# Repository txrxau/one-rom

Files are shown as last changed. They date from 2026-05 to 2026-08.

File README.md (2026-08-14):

# One ROM

**[One ROM](https://onerom.org) - One ROM To Rule Them All**

The most flexible and powerful ROM replacement for your retro computer.  A single Raspberry Pi
RP2350-base board in the footprint of the original chip emulates 24, 28, 32 and
40 pin mask ROMs, EPROMs, EEPROMs, bipolar PROMs and some SRAM — and then does
things the original never could.  It serves several ROM sockets at once, switches
images at runtime, reprograms over USB without leaving the socket, talks back to
the machine it is installed in, and runs your own code as plugins.

Thousands of One ROMs are installed in Commodore 64s, VIC-20s, PETs, Amigas, BBCs, Ataris, TIs, Apple IIs,
disk drives, IBM PCs, pinball machines, drum machines, synthesizers and more.  It is
open source hardware and software, it is cheap to make, and it is actively
maintained and developed.

## New to One ROM?

**Start at [onerom.org](https://onerom.org).**  That is where the project is
explained and supported:

- [What One ROM is and why](https://onerom.org) — the overview, with pictures
- [Getting started](https://onerom.org/start/) — install it, program it, use it
- [Buy one](https://onerom.org/buy) — known vendors, if you'd rather not fab
  your own
- [Program from your browser](https://onerom.org/web) — no software to install

**The rest of this README is for people who want to build One ROM, hack on it,
or build things on top of it.**  If you just want a working ROM replacement, [onerom.org](https://onerom.org) will get you there faster.

## Ways in

One ROM is designed to be extended in many different ways.

| I want to… | Start here | Steps |
|---|---|---|
| Drive a device from scripts or my own tooling | [Programming a One ROM](#programming-a-one-rom), [CLI manual](docs/CLI-MANUAL.md) | Install and run the CLI |
| Fab and assemble existing boards | [hardware/pcb](hardware/pcb/README.md) | Upload gerbers and BOM/POS files to a fab |
| Build the firmware myself | [Building from source](#building-from-source) | Use `make` or the build container |
| Use the header pins as GPIOs — reset the host, drive a line | [Driving the host](#driving-the-host--gpio-and-reset) | One command, plus a wire for host reset |
| Add support for a chip type One ROM doesn't know | [Adding a chip type](docs/ADDING-CHIP-TYPES.md) | A JSON entry plus one line of Rust or a firmware and tooling update if no existing serving algorithm fits |
| Add support for a new board revision | [rust/config/json](rust/config/json/README.md) | A new JSON file once the board is designed |
| Write a plugin — from scratch, or from a working one | [Plugins](#plugins), [firmware/ora/examples](firmware/ora/examples) | C, against a stable API |
| Talk to the retro machine from the ROM socket | [RBCP](#rbcp--talking-to-the-host-system) | 6502 and 68000 host code provided |
| Build host-side tools of my own | [Rust crates](#rust-crates) | Rust, on published crates |
| Read and test real ROM chips | [One ROM Lab](#one-rom-lab) | Flash Lab to a spare Fire board |
| Add a serving algorithm, or change how serving works | [How the firmware works](#how-the-firmware-works) | Bare metal C, PIO and DMA, plus Rust tooling |
| Design a new board | [hardware/pcb](hardware/pcb/README.md) | KiCad |

## Hardware

One ROM comes in two families:

- **Fire** — RP2350, in 24, 28, 32 and 40 pin variants, latest boards include an
  RGB NeoPixel.  All development happens for these boards.
- **Ice** — STM32F4, 24 pin only.  Legacy: still supported with 0.6.x firmware,
  but it is not being enhanced.  The 0.7.x firmware and the CLI do not
  support it.

<div align="center">
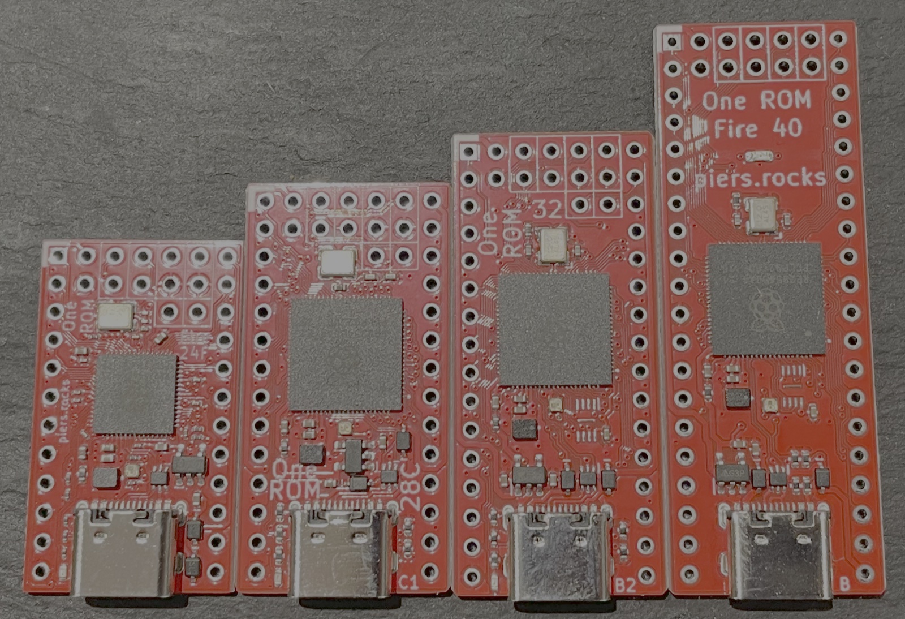
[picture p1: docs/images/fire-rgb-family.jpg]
One ROM Fire 24, 28, 32 and 40 pin boards side by side
    
</div>

<div align="center">
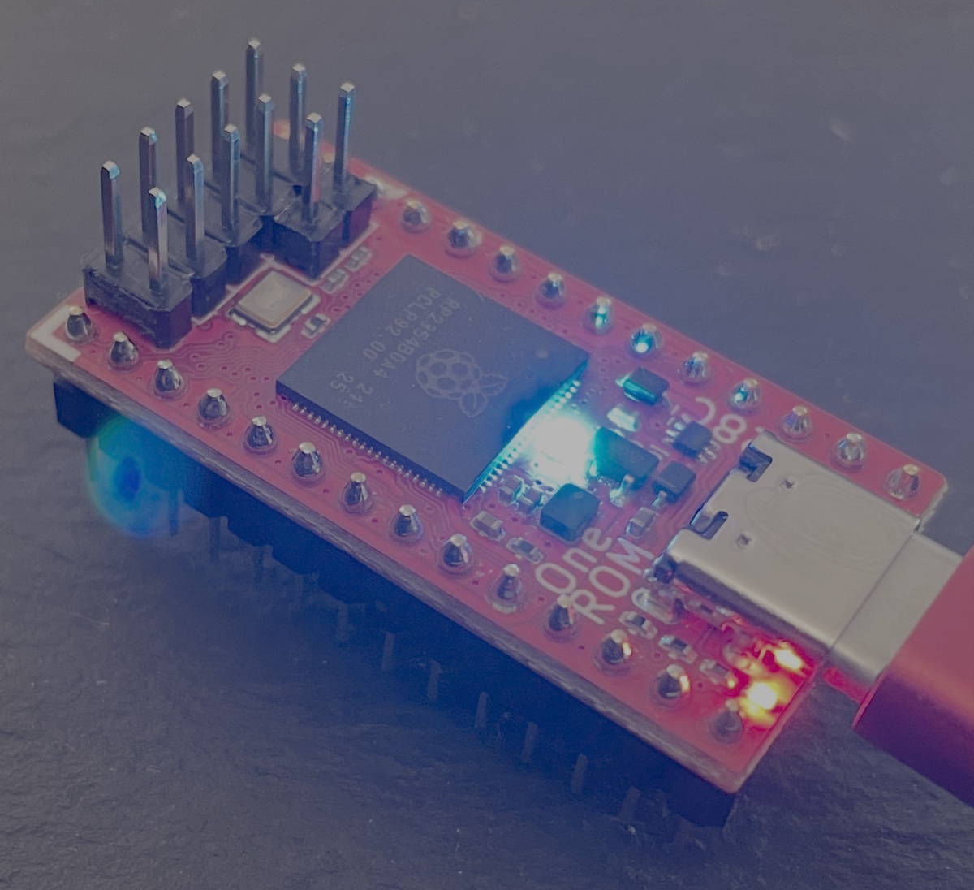
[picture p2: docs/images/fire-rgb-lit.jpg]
One ROM Fire 28 with its RGB NeoPixel lit
    
</div>

All the design files needed to manufacture your own are in
[hardware/pcb](hardware/pcb).  Start with the
[recommended revisions](hardware/pcb/README.md#recommended-revisions) and
read the fabrication notes in the same file before you order.  Boards can be
fabbed and assembled at JLCPCB and other manufacturers cheaply.

<div align="center">
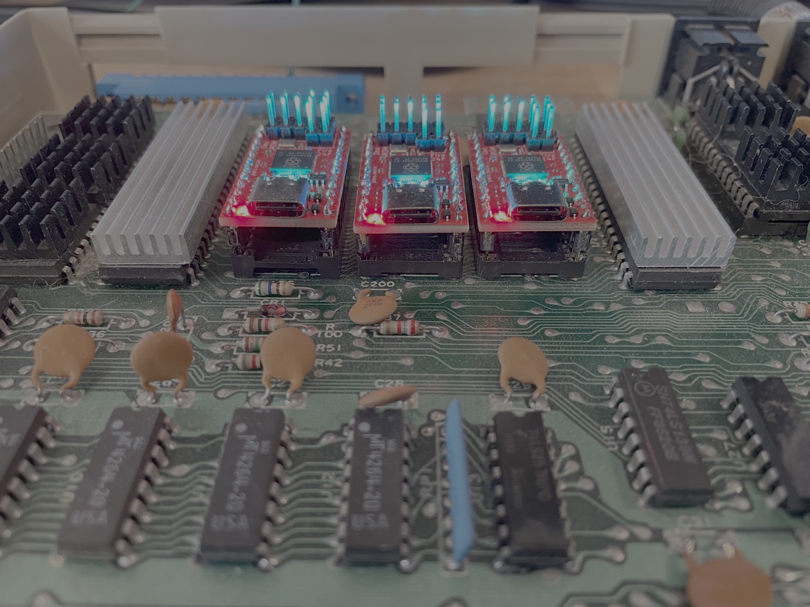
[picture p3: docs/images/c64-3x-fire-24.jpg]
Three One ROM Fire 24 boards serving BASIC, KERNAL and character ROMs in a Commodore 64
    
</div>

<p align="center"><em>Three One ROM Fire 24s in a Commodore 64, serving BASIC,
KERNAL and the character ROM.</em></p>

## Programming a One ROM

There are three tools, all doing the same job over USB:

- **[One ROM Web](https://onerom.org/web)** — browser based, nothing to install,
  the best choice for most people.
- **[One ROM CLI](https://onerom.org/cli)** — the full device tool, and what the
  examples below use ([rust/cli](rust/cli)).
- **[One ROM Studio](https://onerom.org/studio)** — native desktop GUI for
  Windows, macOS and Linux ([rust/studio](rust/studio)).

The CLI is the complete interface: everything the device can do is reachable from
it.  Full reference in the [CLI manual](docs/CLI-MANUAL.md).

Find what is connected:

```bash
onerom scan
```

Build an image from a config file and flash it:

```bash
onerom program --config onerom-config/vic20-pal.json
```

Program chips straight from the command line, without a config file, adding the
USB plugin so the device stays on the bus while it serves:

```bash
onerom program --slot file=kernal.901227-03.bin,type=2364,cs1=active-low --plugin usb
```

Build a firmware binary without touching a device, and look inside one:

```bash
onerom firmware build --config onerom-config/vic20-pal.json --board fire-24-e --output /tmp/onerom.bin
onerom firmware inspect --firmware /tmp/onerom.bin
```

Read and write the ROM image live, while the host is running from it:

```bash
onerom peek live --address 0x100 --length 64
onerom poke live --address 0x100 --byte 0xEA
```

## Driving the host — GPIO and reset

The image select and X pads are not just jumpers.  They are GPIOs, and
One ROM will drive them for you — which means the ROM socket becomes a way to
manipulate the machine it is plugged into.

Run a wire from a pad to the host's reset line and you can reset the machine
after flashing a new image:

```bash
onerom control reset --pin sel_c
```

`sel_c` is the usual choice — more boards have it than have X pads, and it is 5V
tolerant where it exists.  Any pad works, named with `--pin`.

<div align="center">
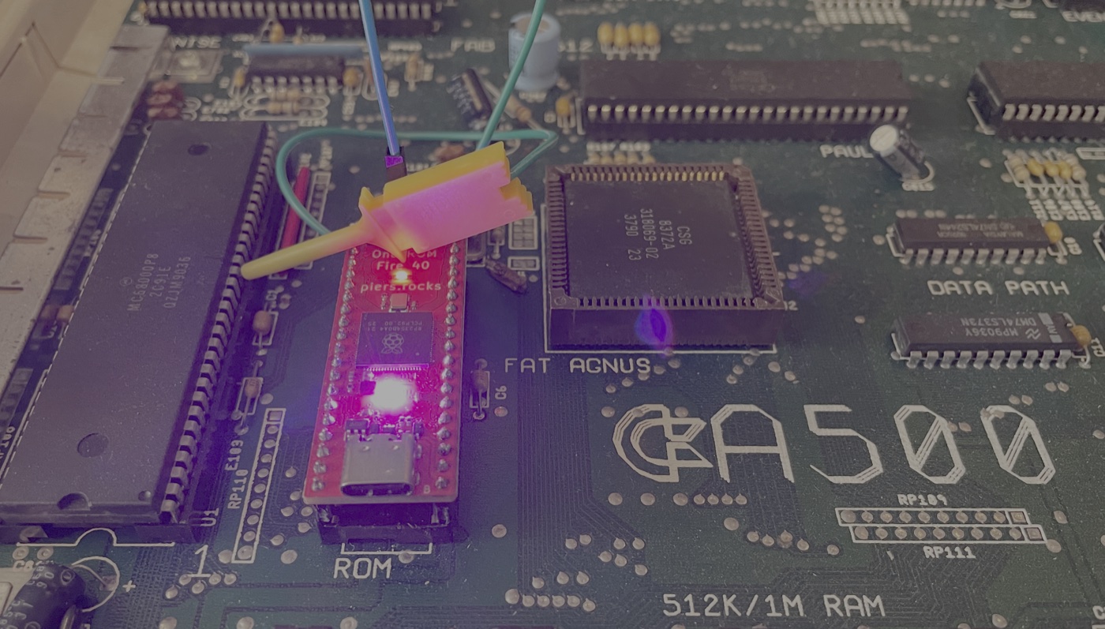
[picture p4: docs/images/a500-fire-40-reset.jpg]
One ROM Fire 40 in an Amiga A500 ROM socket, with a wire from its Sel_C pad to the 68000's reset line
    
</div>

<p align="center"><em>A One ROM Fire 40 in an Amiga A500, with <code>Sel_C</code>
wired to the 68000's reset line.</em></p>

You can see what every pin is and what it is currently doing:

```bash
onerom inspect gpio --all
onerom inspect socket --chip-type 2364 --gpio
```

The same GPIOs are available to plugins, so a plugin can drive them
autonomously — hold the host in reset until something is ready, blink an
external LED on ROM activity, or drive whatever you have wired up.

## Plugins

Serving runs entirely on PIO and DMA, so both CPU cores are free.  Plugins are
separate binaries, written in C against a stable API in
[firmware/ora](firmware/ora), that run on those cores *while serving continues*.
Two run at once.  This is how One ROM gains functionality without needing to
fork the core firmware.

There are two types, **system** and **user**.  The difference is resources, not
authorship — each is built for a different flash slot with a different RAM and
stack allocation, and you can write either.  System is intended for official One
ROM plugins such as the USB stack, but nothing stops you replacing it with your
own.

| Plugin | Type | What it does |
|---|---|---|
| [usb](plugins/system/usb) | system | The device's own USB stack, so a running One ROM stays on the bus.  Exposes the ROM being served for live read and write, and the `picobootx` extended PICOBOOT interface. |
| [host-control](plugins/user/host-control) | user | A full [RBCP](#rbcp--talking-to-the-host-system) implementation. |
| [rgb](plugins/user/rgb) | user | Cycles the NeoPixel on RGB boards. |
| [activity](plugins/user/activity) | user | Blinks the status LED when the host is reading the ROM. |
| [blink](plugins/user/blink) | user | Minimal example. |

The firmware passes each plugin a lookup function at startup.  The plugin calls
it with the ID of the facility it wants, and gets back a function pointer.
Available that way: status LED and GPIO control, device and firmware metadata,
logging, memory allocation, the ROM and RAM slots being served, and the address
monitor that reports what the host is reading — which is what RBCP is built on.
New IDs are only ever added, never changed, and each plugin declares the minimum
firmware version it needs, which the firmware enforces before launching it.

Start with [plugins/README.md](plugins/README.md) for how plugins are built and
configured, [firmware/ora/api.h](firmware/ora/api.h) for the API, and
[firmware/ora/examples](firmware/ora/examples) for worked examples — including
one that patches the C64 kernal live and one that drives an LED from character
ROM accesses.

## RBCP — talking to the host system

The [ROM Bus Control Protocol](https://github.com/piersfinlayson/rom-bus-control-protocol)
is bidirectional communication between a retro machine and the ROM emulator
installed in it, carried over nothing but the ROM's own address and data buses.
No extra wiring.  The machine reads and writes ROM addresses, and One ROM
interprets them.

That opens up things a ROM socket has no business being able to do:

- remote debugging of code running on real hardware
- ROM-based bootloaders — `grub` for the C64
- dynamic patching of games and demos as they run

The device side is the [host-control](plugins/user/host-control) plugin.  The
specification lives in the RBCP repository, along with reference host
implementations for 6502 and 68000 — generic routines plus sample C64 kernal and
Amiga Kickstart bootloaders.

## One ROM Lab

[One ROM Lab](rust/lab/README.md) is alternate firmware for a spare Fire board that turns
its ROM socket into a bus reader and tester.  Flash it, connect over USB, and you
get an interactive shell.

Read a real chip in the socket, as a checksum, a hexdump or Intel HEX.  Verify
that a One ROM under test serves the right bytes and tristates its data lines
when deselected.  Auto-detect chip select polarity on an unmarked mask ROM by
brute-forcing the combinations.  Dump the board's pin map, socket pin to signal
to GPIO.  It is what Fire 40 boards are tested with before they ship.

```bash
cd rust/lab && scripts/flash.sh
```
## Building from source

Dependencies are listed in [INSTALL.md](INSTALL.md), or use the
[build container](ci/docker/README.md).  The ARM and
Emscripten toolchain versions are pinned (`ci/arm-toolchain-version`,
`ci/emscripten-version`) so a firmware binary is byte-identical wherever it is
built.

Build the base firmware:

```bash
make
```

That produces `firmware/build/onerom-rp235x.bin` — one binary, for every Fire
board.  The ROM images, chip configuration and plugins are composed onto it by
the host-side tools.  To flash *your* build rather than a downloaded release,
pass it explicitly:

```bash
onerom program --config onerom-config/vic20-pal.json --base-firmware firmware/build/onerom-rp235x.bin
```

## How the firmware works

Worth knowing before you go digging in [firmware/](firmware):

**It is fully bare metal.**  No SDK, no HAL — not pico-sdk, not a vendor library.
C with its own startup code and its own linker scripts to keep it lean.

**Serving runs on PIO and DMA.**  The RP2350's PIO state machines watch the
address and chip select lines and DMA the right byte onto the data pins.  The CPU
is not in the critical path, which is what leaves both cores free for plugins.

**The chip type is not compiled in.**  The firmware knows nothing about a 2364 or
a 27C400.  It has a small set of parameterised serving algorithms, and the
host-side generator works out which algorithm and what arguments a given chip on
a given board needs, then writes that into the firmware metadata.

**It is one binary for all boards.**  Board differences are metadata too.

**Bad configuration is visible, not silent.**  An image the firmware cannot make
sense of drops it into limp mode, with an special LED blink pattern.

**The PIO programs are assembled on the device, at boot.**  Which program is
needed depends on the chip, the board's pin mapping and the configuration in
flash, none of which are known at build time.
[apio](https://github.com/piersfinlayson/apio) assembles them in C at runtime,
and disassembles them so a generated program can be read back and checked.

## Regression tested off-hardware

Every push runs the **real firmware C** — the source that ships on devices, not a
model of it — compiled for the host and linked against
[epio](https://github.com/piersfinlayson/epio), a cycle-exact RP2350 PIO
emulator, then driven over emulated bus cycles.

The sweep is hundreds of test runs covering all Fire board revisions, all supported
chip types, every configuration shape the firmware offers — single, banked,
multi-chip, 16-bit — and every chip select polarity combination.  Every address
of every image is compared against an independent copy, which is 10s of
millions of byte-level comparisons, plus checks that the data bus tristates for every
non-selected control line combination.

The plugin API is covered down to all API IDs, and the host-control plugin's own C source is run against a full suite of
conformance tests whose basis is the protocol specification rather than the
implementation.

CS-to-data latency is asserted to the exact cycle in **both**
directions, so serving getting a cycle slower — or a cycle faster, which would
mean the check had stopped discriminating — fails the build.

What it does not do today is anything analogue — voltage levels, bus loading,
propagation delay at a real pin — or USB.  Those need a board, which is what
[One ROM Lab](#one-rom-lab) is for.

## Rust crates

The host-side tooling is a Cargo workspace in [rust/](rust).  The crates marked
published are on crates.io, for host-side Rust development.

| Crate | Published | What it is for |
|---|:---:|---|
| [`onerom-gen`](rust/gen) | ✓ | Generates ROM images and firmware metadata.  The heart of the toolchain — turns a config plus some ROM files into something flashable. |
| [`onerom-config`](rust/config) | ✓ | The config model: chip types, board definitions, pin maps, JSON schema. |
| [`onerom-fw`](rust/fw) | ✓ | Composes a complete firmware image, resolving and fetching base firmware from the release manifest. |
| [`onerom-fw-parser`](rust/fw-parser) | ✓ | Reads metadata back out of a firmware binary — what chips, what board, what version. |
| [`onerom-metadata`](rust/metadata) | ✓ | The embedded metadata schema itself. |
| [`onerom-cli`](rust/cli) | ✓ | Everything the CLI does, minus the command line parsing.  Build on it rather than reimplementing USB device logic. The CLI binary is released at [onerom.org/cli](https://onerom.org/cli). |
| [`onerom-app`](rust/app) | ✓ | Transport-free logic shared by the CLI, Studio and the web tools. |
| [`onerom-studio`](rust/studio) | | The desktop GUI, released at [onerom.org/studio](https://onerom.org/studio). |
| [`onerom-lab`](rust/lab) | | One ROM Lab, above. |
| [`onerom-lens`](rust/lens) | | One ROM Lens — compiles the firmware emulator to WebAssembly and draws PIO and DMA activity as waveforms in a browser, cycle by cycle. |
| [`onerom-fw-emulator`](rust/fw-emulator) | | Compiles and runs the real firmware C on a host, PIOs and all. |
| [`onerom-fw-tester`](rust/fw-tester) | | Drives the emulator with generated configurations and checks the results. |
| [`onerom-plugin-tester`](rust/plugin-tester) | | Runs plugins against the emulated firmware. |
| [`onerom-fw-driver`](rust/fw-driver), [`onerom-fw-geometry`](rust/fw-geometry) | | Pin geometry and GPIO bitmask helpers, shared and dependency-free by design. |
| [`fw-config-gen`](rust/fw-config-gen), [`schema-gen`](rust/schema-gen) | | Code and schema generators. |

For in-browser use, [one-rom-wasm](https://github.com/piersfinlayson/one-rom-wasm)
wraps `onerom-gen` as WASM, and is what the
[browser programmer](https://onerom.org/web) in
[one-rom-site](https://github.com/piersfinlayson/one-rom-site) is built on.

## What is in this repository

| Directory | Contents |
|---|---|
| [`firmware/`](firmware) | The core firmware: C and Thumb assembly, bare metal.  `ora/` is the plugin API. |
| [`plugins/`](plugins) | System and user plugins. |
| [`rust/`](rust) | The Cargo workspace — CLI, Studio, generators, emulator, Lab, Lens. |
| [`hardware/pcb/`](hardware/pcb) | KiCad designs, per board revision, verified and unverified. |
| [`onerom-config/`](onerom-config) | Ready-made JSON configs for some common systems, and the config schema. |
| [`docs/`](docs) | Documentation, including the generated chip and compatibility references. |
| [`ci/`](ci) | Build, test and lint scripts, and the reproducible build container. |
| [`images/`](images) | Test ROM images. |
| [`demo/`](demo) | Demonstration programs for the retro side. |

## Documentation

| Topic | Description |
|---|---|
| [CLI Manual](docs/CLI-MANUAL.md) | Complete reference for the `onerom` command line tool. |
| [Chip Types](docs/CHIP-TYPES.md) | Every chip type One ROM knows about, with pinouts and control lines. |
| [Compatibility](docs/COMPATIBILITY.md) | Which chips each hardware variant can emulate, and at what flash cost. |
| [Adding a Chip Type](docs/ADDING-CHIP-TYPES.md) | Teaching One ROM to emulate a chip it does not yet know. |
| [Image Selection](docs/IMAGE-SELECTION.md) | Telling One ROM which installed image to serve. |
| [Image Sets](docs/MULTI-ROM-SETS.md) | Serving several ROMs at once, and dynamic bank switching. |
| [Plugins](plugins/README.md) | Building, configuring and writing plugins. |
| [Build Container](ci/docker/README.md) | Building the firmware reproducibly in Docker. |
| [ROMs Glorious ROMs](docs/ROMS-GLORIOUS-ROMS.md) | Everything you wanted to know about 23/27 series ROMs but were afraid to ask. |
| [Changelog](CHANGELOG.md) | What changed, and when. |

More in [docs/](docs) — flash layout, logging, voltage levels, using a Pi Pico as
an SWD programmer — plus [INSTALL.md](INSTALL.md) for build dependencies and
[LICENSE.md](LICENSE.md).

## Videos

Why use One ROM:

10 reasons to use One ROM (https://www.youtube.com/watch?v=LjKZ0uKzLO4)

The hardware family:

One ROM hardware family (https://www.youtube.com/watch?v=GAh021jgGgs)

## Related repositories

| Repository | What it is |
|---|---|
| [rom-bus-control-protocol](https://github.com/piersfinlayson/rom-bus-control-protocol) | The RBCP specification, and 6502/68000 reference host implementations. |
| [one-rom-site](https://github.com/piersfinlayson/one-rom-site) | onerom.org, including the browser programmer. |
| [one-rom-images](https://github.com/piersfinlayson/one-rom-images) | images.onerom.org — firmware images, configs, plugin manifests. |
| [one-rom-wasm](https://github.com/piersfinlayson/one-rom-wasm) | WASM build of `onerom-gen`, for in-browser firmware generation. |
| [picoboot](https://github.com/piersfinlayson/picoboot) | Host-side Rust crate for the RP2350 PICOBOOT USB interface. |
| [picobootx](https://github.com/piersfinlayson/picobootx) | Device-side PICOBOOT extension, exposed by the USB plugin. |
| [apio](https://github.com/piersfinlayson/apio) | Runtime RP2350 PIO assembler and disassembler. |
| [epio](https://github.com/piersfinlayson/epio) | Cycle-exact RP2350 PIO emulator. |

## Problems

Raise an issue at the [project issues page](https://github.com/piersfinlayson/one-rom/issues)
or start a thread at [GitHub Discussions](https://github.com/piersfinlayson/one-rom/discussions).
Please include:

- your One ROM PCB type and revision (or a photo if you're unsure)
- the retro system you are using it with
- details of the problem.

## Contributing

Pull requests are welcome — firmware, tools, hardware, documentation, and
especially plugins.  If you write a user plugin you think others would want,
consider contributing it.

## License

See [LICENSE](LICENSE.md) for software and hardware licensing information.

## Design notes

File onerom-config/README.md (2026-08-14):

# ROM Configs

This directory contains configuration files that can be used to generate various ROM collections for use with One ROM.

There is a [schema file](schema.json) that describes the structure of these configuration files. You can use this schema to validate your own configuration files or to generate new ones.

If you would like a more human readable version of the schema use a tool like [json-schema.app](https://json-schema.app/view/%23?url=https%3A%2F%2Fimages.onerom.org%2Fconfigs%2Fschema.json), pasting in https://images.onerom.org/configs/schema.json as the URL.

To be precise, these config files are used to generate the __metadata__ that is embedded on One ROM's flash __alongside__ the core firmware, adding:

- ROM images
- (optionally) overrides to stock firmware behaviour, on a per ROM basis.

A config file following this format can be used with [One ROM Studio](https://onerom.org/studio) to generate a complete One ROM image and flash it to your One ROM.

## Local File Names

Where ROM images are on the local filesystem, it is safest to use full file paths.  On Windows, use double backslashes in the file path (e.g. "C:\\\\Users\\\\piers\\\\local-chargen-custom.bin"), or forward slashes (e.g. "c:/Users/piers/local-chargen-custom.bin").

## Minimal Config

This is a minimal config:

```json
{
    "$schema": "https://images.onerom.org/configs/schema.json",
    "version": 1,
    "description": "A minimal ROM config",
    "rom_sets": []
}
```

This produces One ROM image with no ROMs in it. This may be useful for manufacturing purposes - in order to flash and ship One ROM with no ROMs installed.

This is essentially the configuration that is used to generate the base One ROM images that One ROM Studio then adds the ROMs you select to.

## Simple Config

A slightly more advanced config with 2 ROM images:

```json
{
    "$schema": "https://images.onerom.org/configs/schema.json",
    "version": 1,
    "name": "Simple Config",
    "description": "A simple ROM config with 2 ROMs",
    "rom_sets": [
        {
            "type": "single",
            "roms": [
                {
                    "description": "ROM 1",
                    "file": "http://example.com/rom1.bin",
                    "type": "2364",
                    "cs1": "active_low"
                }
            ]
        },
        {
            "type": "single",
            "roms": [
                {
                    "description": "ROM 2",
                    "file": "http://example.com/rom2.bin",
                    "type": "2364",
                    "cs1": "active_low"
                }
            ]
        }
    ]
}
```

As can be seen, this config contains 2 ROM sets, each with a single 2364 mask programmed ROM image, each with the CS line active low.

One ROM Studio reads this config, downloads the 2 ROM images from the specified URLs, and builds a One ROM image containing these 2 ROMs.

The two ROM images are selected, at One ROM boot (power on) time, via the on-board image select jumpers.  The first ROM set is selected when all the jumpers are open.  The second ROM set is selected when the first jumper is closed.

(If you close more jumpers than there are ROM sets, the firmware will select the image indicates by the binary value encoded by the jumpers, modulo the number of installed images.)

## 23 vs 27 Series ROMs

If specifying a 27 series (EP)ROM, instead of a 23 (mask programmed) ROM, the `type` field should be set to the appropriate 27 series type (e.g. "27256" instead of "2364").

In this case, there is no need to specify CS line behaviour, as 27 series ROMs use /CE and /OE (both active low) logic by default.

For more details on the differences between 23 and 27 series ROMs, see the [One ROM Visualizer](https://onerom.org/visualizer).

## Firmware Configuration

The `firmware_overrides` section __within a ROM set__ allows fine-tuning of One ROM hardware behavior for __that specific ROM/set of ROMs__. Each base firmware image has built-in defaults - these overrides change the behavior when serving a particular ROM set.

Any ROM set can have its own `firmware_overrides` section, allowing different ROM sets to have different hardware configurations.  It can also have no `firmware_overrides` section, in which case the default firmware behavior is used.

The `firmware_overrides` fields are optional - only include the fields you wish to override from the defaults.

### Primary Use Cases

1. __Performance requirements__ - Some ROM images (particularly character ROMs) require specific clock speeds or voltage settings to serve reliably in certain host systems
2. __Hardware experimentation__ - Testing different configurations to determine optimal settings for specific host platforms and ROM types
3. __Power/performance/preference__ - Disabling features like LEDs (power saving or user preference) or debug interfaces (performance)

### Ice/Fire Specific Configuration

#### Ice Boards (STM32F4-based)

```json
"firmware_overrides": {
    "ice": {
        "cpu_freq": "72MHz",
        "overclock": false
    }
}
```

Ice boards support frequencies from 1MHz to 450MHz.

Set `overclock: true` for frequencies above the rated maximum for a specific STM32F4 MCU.

#### Fire Boards (RP2350-based)

```json
"firmware_overrides": {
    "fire": {
        "cpu_freq": "300MHz",
        "overclock": true,
        "vreg": "1.20V",
        "serve_mode": "Pio"
    }
}
```

Fire boards support 16MHz to 800MHz in various increments (as defined in the schema). For higher frequencies than 150MHz:

- set `overclock: true`.
- you may need to tune `vreg` (internal voltage regulator) - different RP2350 silicon may need different core voltages for stability at high speeds. One ROM firmware will use its own (conservative) voltage regulator settings for higher clock speeds if this is not specified.

### Other Hardware Settings

```json
"firmware_overrides": {
    "led": {
        "enabled": false
    },
    "swd": {
        "swd_enabled": false
    }
}
```

- __LED__ - Disable to save power or if you don't want a status LED on your ROM.  Note, if present and the device enters "limp mode" (e.g. due to a fault or unrecoverable configuration error), the LED will still blink to indicate an error.
- __SWD__ - Disable the debug interface to reduce bus contention and improve serving performance.  SWD is available for the whole of boot, including boot logging, and is shut off just before serving starts, staying off until the next reset.  Not a debug lockout - BOOTSEL/PICOBOOT are unaffected.

### Example: ROM-Specific Configuration

```json
{
    "rom_sets": [
        {
            "description": "C64 Character ROM - requires high clock speed",
            "firmware_overrides": {
                "ice": {
                    "cpu_freq": "150MHz",
                    "overclock": true
                }
            },
            "roms": [
                {
                    "description": "C64 Character ROM",
                    "file": "http://example.com/c64-char.bin",
                    "type": "2332",
                    "cs1": "active_low",
                    "cs2": "active_high"
                }
            ]
        }
    ]
}
```

### Advanced: PIO Serving Algorithm Parameters

For Fire boards using the PIO serving algorithm, low-level timing can be tuned via `serve_alg_params`. This is primarily for experimentation to determine what settings are required for specific ROM/host combinations.

```json
"firmware_overrides": {
    "serve_alg_params": {
        "params": [254, 0, 2, 0, 0, 0, 254, 255]
    }
}
```

As of firmware 0.6.0, the parameter array format is 8 bytes long, as follows:

- Byte 0: `0xFE` (signature)
- Byte 1: `addr_read_irq` (0=disabled, 1=enabled) - whether to use IRQ to trigger address reads
- Byte 2: `addr_read_delay` (0-31) - PIO cycles to delay between address reads
- Byte 3: `cs_active_delay` (0-31) - PIO cycles to wait after CS active before setting data pins to outputs
- Byte 4: `cs_inactive_delay` (0-31) - PIO cycles to hold data as outputs after CS goes inactive
- Byte 5: `no_dma` (0=use DMA, 1=CPU) - whether to use DMA or CPU for byte serving
- Byte 6: `0xFE` (end signature)
- Byte 7: `0xFF` (padding)

These parameters adjust the PIO state machine timing for specific ROM types or host systems. At 150MHz, each PIO cycle is ~6.67ns. See the PIO implementation source code for detailed timing analysis and pre-defined configurations.

It is likely that in future firmware versions, more PIO settings will be exposed via the config file.

### Firmware Defaults

As of 0.6.0 the following firmware defaults are used if no overrides are specified:

- Ice Clock: F401=84MHz, F411=100MHz, F405=168MHz, F446=180MHz, no overclocking.
- Fire Clock: 150MHz, overclocking enabled, VREG 1.10V.
- LED: Enabled (if hardware support is present)
- SWD: Enabled (if hardware support is present)
- PIO Serve Algorithm Params: [254, 0, 2, 0, 0, 0, 254, 255]

### Error Handling

Where possible, One ROM attempts to gracefully recover from incorrect or invalid configuration settings. 

For example, if it cannot calculate PLL values for a specific requested clock speed, it will attempt to find a close match, and if not found fall back to the values built into the firmware (likely to be the stock maximum rated speed for the MCU).

However, there are some situations where recover is not possible, or it is deemed better to enter "limp mode" (where the device hangs and flashes its status LED, irrespective of the LED enabled setting) to indicate a fault.

If the device enters limp mode, you have two choices:
- Try changing the settings and reflashing.
- Connecting a debug probe and using a build with BOOT_LOGGING/DEBUG_LOGGING included, to diagnose the issue.

The stock builds provided as part of One ROM releases _do not_ include debug or boot logging for performance reasons.

## Complex Configs

There's some advanced ROM options including the following:

- ROM Set types "multi" and "banked" for multi-ROM sets and dynamically bank switched ROM sets
- Local file and URL file sources (most generators only support URLs)
- The ability to specify licenses which must be accepted before building a config
- The ability to configure chip selects in multiple directions
- Support for all 24 and 28 pin ROM types
- Optional categories for better organization
- Support for archived ROM files (zips)
- Retrieve sections of a larger ROM file
- Duplicate and pad ROM images, if the ROM file provided is smaller than the expected size, and truncate if larger

Use the configs in this directory and the schema to build your own complex configs.

## Future Plans

The "end-game" is to have a repository of officially supported ROM configs for popular systems that can be used with One ROM Studio to build custom One ROM images.

It is intended that eventually ROM configs will specify the original ROM chip's access times and other characteristics, with the One ROM firmware to dynamically adjust its serving behavior to match the original hardware as closely as possible.

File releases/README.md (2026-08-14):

# Releases

The files in this directory were generated by the [GitHub release
workflow](../.github/workflows/release.yml) up to and including the v0.6.x
releases.

They are read by the One ROM Web programmer to discover the pre-built firmware
image artifacts published with those releases, so they can be downloaded and
programmed.

From v0.7.0 onwards the release workflow no longer updates this directory.
v0.7.0+ releases publish only the base One ROM firmware - a single image that
covers every Fire board - and no longer produce per-board pre-built images. The
existing files here are retained so the Web programmer can still offer the
pre-built images from earlier (v0.6.x and older) releases.

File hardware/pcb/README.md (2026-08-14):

# PCB Files

Contains One ROM PCB design files.  These are organised into two directories:

- [`verified/`](verified/README.md) - Verified designs that have been tested and work.
- [`unverified/`](unverified/README.md) - Unverified designs that have not been tested.

Before using any of the designs, review the hardware [LICENSE](/LICENSE.md#cern-ohl-w-20-license) and [NOTICE](/hardware/NOTICE) files.

## Recommended Revisions

Last Updated 4th July 2026.

The following table lists the recommended verified designs.  Each design has been manufactured and assembled using JLCPCB's PCB assembly service, and verified to work correctly.

| Model | MCU | Pins | USB | SWD | Image Select Pins | X Pins | RGB | PCB |
|---|-----|---|-----|-----|---|---|-----|---|
| Fire  | RP2350A | 24 | Micro-B | ✓ | 4 | 2 | - | [fire-24-d](./verified/fire-24-d/README.md) |
| Fire  | RP2354A | 24 | C | ✓ | 4 | 2 | - | [fire-24-e](./verified/fire-24-e/README.md) |
| Fire  | RP2354A | 24 | C | ✓ | 4 | 2 | ✓ | [fire-24-f](./verified/fire-24-f/README.md) |
| Fire  | RP2350A or RP2354A | 28 | C | ✓ | 2 | n/a | - | [fire-28-a4](./verified/fire-28-a4/README.md) |
| Fire  | RP2350A or RP2354A | 28 | C (upright) | ✓ | 2 | n/a | - | [fire-28-b](./verified/fire-28-b/README.md) |
| Fire  | RP2354B | 28 | C | ✓ | 2 | 2 | ✓ | [fire-28-c](./verified/fire-28-c/README.md) |
| Fire  | RP2350B or RP2354B | 32 | C | ✓ | 4 | n/a | - | [fire-32-a](./verified/fire-32-a/README.md) |
| Fire  | RP2350B or RP2354B | 32 | C | ✓ | 4 | n/a | ✓ | [fire-32-b2](./verified/fire-32-b2/README.md) |
| Fire  | RP2350B or RP2354B | 40 | C | ✓ | 4 | n/a | - | [fire-40-a](./verified/fire-40-a/README.md) |
| Fire  | RP2350B or RP2354B | 40 | C | ✓ | 4 | n/a | ✓ | [fire-40-b](./verified/fire-40-b/README.md) |

**One ROM 28C, 32 and 40 require components on the top and bottom of the PCB**

There may be later, unverified, revisions not in the list above.  These may have improvements over the recommended revisions, but they have not been verified to work.  If you want to use one of these later revisions, read the relevant README before ordering.

## Alternative Components

Sometimes your PCB manufacturer/assembler may be out of stock of a particular component.  This section lists some reasonable alternatives, using LCSC/JLC part numbers.

| Original Component | Original LCSC/JLC Part Number | Alternative Component | Alternative LCSC/JLC Part Number | Verified? | Notes |
|-|-|-|-|-|-|
| Diodes Inc AP2112K-3.3TRG1 | C51118 | Tech Public AP2112K-3.3TRG1 | C23380830 | Yes | Jelly bean part, same specs |
| Uniroyal 0201WMF1002TEE | C473048 | Yageo RC0201FR-0710KL | C106225 | No | Jelly bean part, same specs |
| Raspberry Pi RP2350A | C42411118 | Raspberry Pi RP2354A | C41378174 | Yes | If using RP2354A, do not populate the external flash chip, as the RP2354A has internal flash. |
| Raspberry Pi RP2350B | C42415655 | Raspberry Pi RP2354B | C39843328 | Yes | If using RP2354B, do not populate the external flash chip, as the RP2354B has internal flash. |

The RP2354A can be replaced with the RP2350A _if the design supports external flash and it is populated_.
- Some designs, such as fire-24-e, do not support external flash, so the RP2354A cannot be replaced with the RP2350A.
- Some designs, such as fire-40-a, have hardware support for both external flash plus an RP2354B, so two lots of flash.  Fabricating this option requires the correct 0R resistors to be populated/not populated.  See the board schematic for more details.

In some cases, alternative BOM/POS files are already provided for some alternative components.  In other cases, you may need to edit the BOM/POS files yourself to substitute the alternative component.  _Always_ double check component values, part numbers and placement before ordering.

## Notes on Fabrication

All recommended designs have been manufactured and assembled using JLCPCB's PCB assembly service.  The gerbers and BOM/POS files in each revision's `fab/` directory are compatible with JLCPCB's requirements.

Some variants offer multiple sets of BOM/POS files or different combinations of components.  Read the relevant revision's README for details.

You need to exercise care when submitting the order to ensure the correct options are selected.  In particular:

- Select economic assembly, not standard assembly, for cost reasons.
- Use standard 1.6mm PCB thickness.  You probably want HASL with lead finish for cost reasons.
- You have to select the desired PCB colour as part of the PCB ordering process.  Red is recommended for Fire and blue for Ice.
- As of late 2025 you no longer need to remove JLC's order ID from the PCBs, but it is worth checking this is still the case when you place your order.
- After uploading the BOM and position files for assembly, you need to ensure all parts are available and checked.
- You must ensure JLC is showing the correct orientation for all components.  There are silkscreen markings for pin 1 on all ICs and polarized components - ensure this matches the pink dot of the component in the viewer.  Also ensure the USB connector is the correct orientation.

Occasionally, some chosen parts are out of stock on JLCPCB.  One ROM has been designed with extremely common parts where possible, which JLC tend to hold large stocks of.  However, if a part is unavailable you may need to select an alternative part.  Ensure the alternative part has the same footprint and electrical characteristics (e.g. capacitance, voltage rating, etc) as the original part.  If in doubt, query within github discussions for advice. 

JLC may raise an issue with you after submitting your order.  Common issues include:
- JLC may ask to add side rails with stamp holes, to help with the PCB assembly process.  While One ROM has been successfully fabbed without these, if JLC recommends them it is best to accept this change, as otherwise they may not warrant the assembled boards.  The side rails can be snapped off using the "mouse bites" (stamp holes) after assembly.  JLC may or may not accept replacing stamp holes with v-score - as v-score is not available on their economic service.

If in doubt, query within github discussions for advice.

Assembly errors:
- Ice boards have rarely, if ever, experienced assembly errors.
- The first few batches of Fire boards experienced some assembly issues, particularly with respect to the RP2350 MCU solder pad fillets.  More recent boards and orders have been without issue.  It is unclear whether differences in the later PCBs or improvements in JLC's assembly process are responsible for this improvement.  If you do experience assembly issues, raise with JLC support.  It would also be interesting to hear on github discussions what issues you experienced, so others can be aware.

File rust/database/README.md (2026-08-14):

# One ROM Database

Database of known ROMs.

**Not currently maintained.**  This crate has not been added to or updated for
some time, and nothing in the tree depends on it in anger.  It is kept because
the idea may return, so treat its contents as incomplete and do not rely on it.

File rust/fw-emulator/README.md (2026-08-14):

# onerom-fw-emulator

This is a crate that provides the One ROM firmware as a library for running on hosts, emulating the underlying hardware, including PIOs and DMAs.

Sample invocation from this crate's directory:

```bash
BASE_DIR=$(realpath ../..) CONFIG=onerom-config/test-0.json BOARD=fire-24-a cargo test
```

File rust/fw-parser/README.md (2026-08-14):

# onerom-fw-parser

Crate to handle parsing an SDRR firmware image.

This can can be a `.bin` or `.elf` file - or could be the contents of an STM32's flash memory.  It supports `no_std` environments, for adding to embedded applications, or `std` for use in PC-based tools.

A PC-based reference implementation is provided in the [`sdrr-info`](https://piers.rocks/u/sdrr-info) tool, which is used to parse and output the contents of a firmware image when you run `make info` or `make info-detail`.

A reference embedded implementation using this crate is [Airfrog](https://piers.rocks/u/airfrog), which is a tiny $3 probe for ARM devices, that can be used to inspect the firmware and runtime state of the SDRR device, and change its configuration and ROM data - **while it is serving ROMs**.

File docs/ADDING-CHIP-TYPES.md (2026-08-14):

# Adding a Chip Type

How to teach One ROM to emulate a chip it does not yet know about.

This describes the **v2** path — firmware v0.7.0 and later, which is Fire
(RP2350) hardware.  V2 derives how to serve a chip from the chip's pinout and
the board's routing, so a new chip type is usually a data change plus a one-line
declaration.  The pre-v0.7.0 (v1) path is closed to new chip types, and its
per-chip code in [`rust/gen/src/image.rs`](/rust/gen/src/image.rs)
(`chip_type_c_enum_val`, `handle_snowflake_chip_types`) is not part of this.

## The short version

1. Add the chip to [`rust/config/json/chip-types.json`](/rust/config/json/chip-types.json).
2. Add its `ChipType` to `SUPPORTED_CHIP_TYPES` in [`rust/gen/src/v2/builder.rs`](/rust/gen/src/v2/builder.rs).
3. Run the generators.
4. Look for the chip in [`docs/COMPATIBILITY.md`](/docs/COMPATIBILITY.md).  If it is there, it serves.
5. If it is not, find out why with the `layout` tool — and only then consider firmware work.
6. Add it to the emulator test sweep, so it stays working.

## 1. The JSON entry

Everything One ROM knows about a chip comes from this one file.  The
`onerom-config` build script reads it, validates it, and generates the
`ChipType` enum and [`docs/CHIP-TYPES.md`](/docs/CHIP-TYPES.md).  The
`onerom-metadata` build script generates the firmware's `onerom_rom_type_t` C
enum and chip-size array from the same data.  Nothing is written twice.

Here is the 2364 entry — about as simple as an entry gets — with its arrays
compacted onto single lines:

```json
"2364": {
    "description": "8KB mask ROM with 1 configurable CS line",
    "function": "ROM",
    "rbcp_chip_type": 2,
    "supported": "0.4.4",
    "aliases": ["4764", "MCM68764", "MCM68A764", "MM52164", "MK36000"],
    "bit_modes": [8],
    "pins": 24,
    "size": 8192,
    "address": [8, 7, 6, 5, 4, 3, 2, 1, 23, 22, 19, 18, 21],
    "data": [9, 10, 11, 13, 14, 15, 16, 17],
    "control": {
        "cs1": { "pin": 20, "type": "configurable" }
    },
    "power": [
        { "name": "VCC", "pin": 24, "voltage": "+5V" },
        { "name": "GND", "pin": 12, "voltage": "0V" }
    ]
}
```

- **The key** is the chip's primary name.  Unless the chip is RAM it must start
  with `23`, `27`, `28`, `SST39SF` or `HM76`, or the build panics with
  `Unsupported chip type X - needs adding to chip_family()`.  A part number
  outside those conventions needs an arm in
  [`rust/config/build/chip/mod.rs`](/rust/config/build/chip/mod.rs).
- **`rbcp_chip_type`** is the wire value: unique, and permanent once shipped.
  Take the next free number.  The firmware's C enum and chip-size array are
  generated from it.  It is also part of the
  [ROM Bus Control Protocol](https://github.com/piersfinlayson/rom-bus-control-protocol),
  so a new chip type needs a matching pull request against that repository — the
  value has to mean the same thing on both sides of the bus.
- **`supported`** is the firmware version the chip first ships in — the
  in-development version from the [`Makefile`](/Makefile).  Omit it and the chip
  is known but unsupported: absent from `COMPATIBILITY.md` and from
  `onerom firmware chips`, and marked `✗` in `CHIP-TYPES.md`.
- **`aliases`** are other names for the same silicon.  Every alias becomes
  selectable everywhere a chip type can be named — the CLI, the web programmer
  and Studio, as well as its own row in `COMPATIBILITY.md` — so a user can pick
  the number actually stamped on their chip rather than having to know it is the
  same part as something else.  Be generous with them.
- **`address`** lists the address lines in bit order, lowest first, as physical
  pin numbers, and **`data`** does the same for the data lines from D0.  `size`
  must equal `2^address.len()` (the 48KB 23QL384 is the sole exception).
- **`bit_modes`** is `[8]`, or `[8, 16]` for a 16-bit part with a `/BYTE` line.
  On a 16-bit part the lowest address line is **A-1**, not A0 — it selects which
  half of the word a byte-mode read returns, and it shares a pin with the top
  data line.  So the 27C400's 19 entries are A-1 to A18, and `2^19` is still its
  512KB.  Nothing keys off the chip name: anything that needs to know works it
  out from `bit_modes` containing 16.
- **`control`** names the enables.  `cs1`-`cs4` may be `configurable` (polarity
  mask-programmed, so the user supplies it), `fixed_active_low` or
  `fixed_active_high`.  `ce` and `oe` carry the JEDEC convention and must be
  `fixed_active_low`.  Mixing CS with CE/OE needs `"allow_mixed_control": true`.

[`rust/config/build/chip/validation.rs`](/rust/config/build/chip/validation.rs)
enforces the pin, size and control-line rules, and fails the build on a bad
entry.

## 2. Declare it servable

`SUPPORTED_CHIP_TYPES` in
[`rust/gen/src/v2/builder.rs`](/rust/gen/src/v2/builder.rs) is the list of chip
types v2 firmware serves.  Add the variant and bump the array length together:

```rust
pub const SUPPORTED_CHIP_TYPES: &[ChipType; 36] = &[
    ...
    ChipType::Chip2532,
];
```

Nothing else in the tooling or the firmware C needs touching for an ordinary ROM
chip type.  A **RAM** type also needs an arm in `rom_slot_type`
([`rust/gen/src/v2/rom_info.rs`](/rust/gen/src/v2/rom_info.rs)) — and no v2
firmware serves RAM yet, which is why `Chip6116` sits commented out of the list.

## 3. Run the generators

From `rust/`:

```bash
cargo run -p onerom-gen --bin compat                     # docs/COMPATIBILITY.md
cargo run -p schema-gen --bin schema-gen                 # onerom-config/schema.json
cargo run -p onerom-gen --bin layout -- --write-baseline # ci/layout-baseline.txt
```

`docs/CHIP-TYPES.md` needs no command — the `onerom-config` build script
rewrites it on any build.  All four are checked in and all four are a CI gate.
`ci/rust-tests.sh` regenerates them and fails if the committed copy differs, so
commit them with the change.

## 4. Did it work?

Look for the chip in [`docs/COMPATIBILITY.md`](/docs/COMPATIBILITY.md), or ask
the CLI — `cargo run -p onerom-cli --bin onerom -- firmware chips --board
fire-24-e`.  If it is listed, that is the whole job.  Check the flash cost while
you are there with `layout --check`: an image several times the chip's own size
is normal where a board's routing puts an unrelated signal inside the chip's
address range, but it is worth knowing.

## 5. When it does not appear

`cargo run -p onerom-gen --bin layout -- --board fire-24-e` says why.  An
unservable chip has `-` in every size column and the reason in the `blocked by`
column at the end of its row.  The three you will see:

- *"physical pin N has no GPIO mapping on this board"* — the chip is bigger than
  the socket and that pin cannot be reached.  Expected, not a fault — the chip is
  still listed for boards that can reach it.
- *"does not support chip type X with this firmware version"* — step 2 was
  missed, or the chip is deliberately excluded.
- *"select/control GPIOs [10, 11, 16] are not contiguous on this board; Multi
  and Banked sets require all select, commoned, and X-pin GPIOs to form a
  contiguous range within a single PIO window"* — the chip's enables land on
  GPIOs no existing chip-select algorithm can express.

Only the last needs firmware work, and it is a serving-algorithm change rather
than a chip-type change.  A new algorithm is:

- a variant and a `NUM_*_ALGS` bump in
  [`rust/metadata/metadata_schema.toml`](/rust/metadata/metadata_schema.toml),
  with its parameter fields and `ALG_*_PARAMS_LEN` constant — that generates
  both the C header and the Rust serialiser,
- a `case` in [`firmware/src/piodma/piorom2.c`](/firmware/src/piodma/piorom2.c)
  emitting the PIO program,
- a preference variant in
  [`rust/gen/src/v2/alg_preference.rs`](/rust/gen/src/v2/alg_preference.rs), plus
  the derivation that selects it in `alg_cs.rs`, `cs_data_layout.rs` or
  `addr_layout.rs`,
- a CS-to-data cycle cost in
  [`rust/fw-tester/src/cs_timing.rs`](/rust/fw-tester/src/cs_timing.rs), which
  asserts against the firmware's own `NUM_*_ALGS` and so will not compile until
  the new algorithm has one.

That is a much bigger piece of work than adding a chip type — and it benefits
every chip that can use the new algorithm, not just the one that prompted it.

## 6. Add it to the test sweep

A chip that serves today but is not tested will break quietly later.
[`ci/test-emu.sh`](/ci/test-emu.sh) lists its chips explicitly, one line each, so
a new type is covered only once you add it.  Put it with the others for its pin
count, with a test image of the right size from [`images/test`](/images/test):

```sh
run_test   $board images/test/rand_16KB.rom  type=23128  3
run_no_cs  $board images/test/rand_8KB.rom   type=2764
```

`run_test` takes the number of configurable chip select lines and sweeps **every
polarity combination** — 3 means all 8 are tested.  `run_no_cs` is for chips
whose enables have a polarity fixed by the silicon, so there is nothing to sweep.

Run just your pin count while iterating — `ci/test-emu.sh 24` — as the full sweep
takes hours, and only one can run in a given working tree at a time.

## Folding it back in

If you want your chip type in One ROM proper rather than kept in your own tree,
please do — that is how the supported list has grown, and a chip somebody has
actually got in front of them is worth more than one added speculatively.  Open
an issue or a pull request, and talk to the maintainer early if the chip needs a
new serving algorithm, since that is a change with consequences beyond your chip
and is better designed together than reviewed after the fact.

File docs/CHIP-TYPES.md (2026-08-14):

# Chip Type Specifications

This document provides detailed specifications for the different Chip types One ROM supports, and aims to support in future, including pinouts, control lines, and programming requirements.

The document is auto-generated from the [json/chip-types.json](/rust/config/json/chip-types.json) configuration file.  That file was created by researching datasheets for the various Chip types.

Some of the pin names have been modified from the datasheet values for consistency beween Chip types:

- /OE on 2704/2408 is called Program, but serves as /OE when in read mode.  Other 27xx ROMs use /OE for that pin, hence the /OE name is used here. 
- Similarly /CE on 2704/2708 ROMs is called /CS, but is called /CE for consistency with other ROM types.
- 23256/23512 chip select lines are often called CE/OE on datasheets, but are mask programmable to be active high or low, hence these are referred to within this doc as CS lines, like the other 23xx ROMs.
- Chips whose enables have a polarity fixed by the silicon use CE/OE where every enable is active low (the JEDEC convention followed by the 27xx and 28xx families).  Where the enables are not all active low, CS lines are used instead: the HM7641 has CS1 and CS2 fixed active low, and CS3 and CS4 fixed active high.  A leading `/` in the tables below indicates an active low line.

There are also some other inconsistencies between types:

- 2332's CS2 is pin 21 and pin 18 is A11.  On the 2316, CS2 is pin 18, and CS3 pin 21.
- The 2332's A11 is pin18, but the 2732's A11 is pin 21.

## Contents

- [24-pin Mask ROM Family (23xx)](#24-pin-mask-rom-family-23xx)
- [28-pin Mask ROM Family (23xx)](#28-pin-mask-rom-family-23xx)
- [32-pin Mask ROM Family (23xx)](#32-pin-mask-rom-family-23xx)
- [24-pin EPROM Family (27xx)](#24-pin-eprom-family-27xx)
- [28-pin EPROM Family (27xx)](#28-pin-eprom-family-27xx)
- [32-pin EPROM Family (27xx)](#32-pin-eprom-family-27xx)
- [40-pin EPROM Family (27xx)](#40-pin-eprom-family-27xx)
- [24-pin EEPROM Family (28Cxx)](#24-pin-eeprom-family-28cxx)
- [28-pin EEPROM Family (28Cxx)](#28-pin-eeprom-family-28cxx)
- [32-pin EEPROM Family (28Cxx)](#32-pin-eeprom-family-28cxx)
- [24-pin Bipolar PROM Family (HM76xx)](#24-pin-bipolar-prom-family-hm76xx)
- [RAM Chips](#ram-chips)
- [Pin Function Comparison](#pin-function-comparison)
- [Detailed Pinouts](#detailed-pinouts)

## 24-pin Mask ROM Family (23xx)

| Chip Type | Aliases | Size | Address Lines | Control Lines | Programming | Supported |
|---|---|---|---|---|---|---|
| 2316 | 9316, 9316A | 2KB | 11 (A0-A10) | CS1 (pin 20), CS2 (pin 18), CS3 (pin 21) | None | ✓ |
| 2332 | 9332, 4732 | 4KB | 12 (A0-A11) | CS1 (pin 20), CS2 (pin 21) | None | ✓ |
| 2364 | 4764, MCM68764, MCM68A764, MCM68364, MCM68A364, MM52164, MK36000 | 8KB | 13 (A0-A12) | CS1 (pin 20) | None | ✓ |

## 28-pin Mask ROM Family (23xx)

| Chip Type | Aliases | Size | Address Lines | Control Lines | Programming | Supported |
|---|---|---|---|---|---|---|
| 23128 |  | 16KB | 14 (A0-A13) | CS1 (pin 20), CS2 (pin 22), CS3 (pin 27) | None | ✓ |
| 23256 |  | 32KB | 15 (A0-A14) | CS1 (pin 20), CS2 (pin 22) | None | ✓ |
| 23QL384 |  | 48KB | 16 (A0-A15) | CS1 (pin 22) | None | ✓ |
| 23512 |  | 64KB | 16 (A0-A15) | CS1 (pin 20), CS2 (pin 22) | None | ✓ |
| 23QL512 |  | 64KB | 16 (A0-A15) | CS1 (pin 22) | None | ✓ |
| 231024 | TC531000, 23C1000, 23C1000A, MX23C1000 | 128KB | 17 (A0-A16) | CS1 (pin 20) | None | ✓ |

## 32-pin Mask ROM Family (23xx)

| Chip Type | Aliases | Size | Address Lines | Control Lines | Programming | Supported |
|---|---|---|---|---|---|---|
| 23C1001 | D23C1001 | 128KB | 17 (A0-A16) | /CE (pin 22), CS1 (pin 31), CS2 (pin 30), /OE (pin 24) | None | ✓ |
| 23C1010 |  | 128KB | 17 (A0-A16) | /CE (pin 22), /OE (pin 24) | None | ✓ |

## 24-pin EPROM Family (27xx)

| Chip Type | Aliases | Size | Address Lines | Control Lines | Programming | Supported |
|---|---|---|---|---|---|---|
| 2704 |  | 512B | 9 (A0-A8) | /CE (pin 18), /OE (pin 20) | VPP: pin 18 (Low during read); PE: pin 20 (Low during read) | ✓ |
| 2708 |  | 1KB | 10 (A0-A9) | /CE (pin 18), /OE (pin 20) | VPP: pin 18 (Low during read); PE: pin 20 (Low during read) | ✓ |
| 2716 |  | 2KB | 11 (A0-A10) | /CE (pin 18), /OE (pin 20) | VPP: pin 21 (VCC during read); PE: pin 20 (Low during read) | ✓ |
| 2732 | 27C32 | 4KB | 12 (A0-A11) | /CE (pin 18), /OE (pin 20) | VPP: pin 20 (Acts as /OE); PE: pin 18 (Low during read) | ✓ |

## 28-pin EPROM Family (27xx)

| Chip Type | Aliases | Size | Address Lines | Control Lines | Programming | Supported |
|---|---|---|---|---|---|---|
| 2764 | 27C64, 27LC64 | 8KB | 13 (A0-A12) | /CE (pin 20), /OE (pin 22) | VPP: pin 1 (VCC during read); /PGM: pin 27 (High during read) | ✓ |
| 27128 | 27C128, 27LC128 | 16KB | 14 (A0-A13) | /CE (pin 20), /OE (pin 22) | VPP: pin 1 (VCC during read); /PGM: pin 27 (High during read) | ✓ |
| 27256 | 27C256, 27LC256, 27SF256 | 32KB | 15 (A0-A14) | /CE (pin 20), /OE (pin 22) | VPP: pin 1 (VCC during read); PE: pin 22 (Low during read) | ✓ |
| 27512 | 27C512, 27LC512, 27SF512 | 64KB | 16 (A0-A15) | /CE (pin 20), /OE (pin 22) | VPP: pin 22 (VCC during read); PE: pin 20 (Low during read) | ✓ |

## 32-pin EPROM Family (27xx)

| Chip Type | Aliases | Size | Address Lines | Control Lines | Programming | Supported |
|---|---|---|---|---|---|---|
| 27C010 | 27C1001, 27C1000A, 29F010, 39SF010, SST39SF010 | 128KB | 17 (A0-A16) | /CE (pin 22), /OE (pin 24) | VPP: pin 1 (Don't care during read); /PGM: pin 31 (Don't care during read) | ✓ |
| 27C301 | 27C1000, 27C100 | 128KB | 17 (A0-A16) | /CE (pin 22), /OE (pin 2) | VPP: pin 1 (Don't care during read); /PGM: pin 31 (Don't care during read) | ✓ |
| 27C020 | 27C2001, 39SF020, 29F020, SST39SF020 | 256KB | 18 (A0-A17) | /CE (pin 22), /OE (pin 24) | VPP: pin 1 (Don't care during read); /PGM: pin 31 (Don't care during read) | ✓ |
| 27C040 | 27C4001 | 512KB | 19 (A0-A18) | /CE (pin 22), /OE (pin 24) | VPP: pin 1 (Don't care during read); /PGM: pin 22 (Acts as /OE) | ✓ |
| SST39SF040 | 39SF040, 29F040 | 512KB | 19 (A0-A18) | /CE (pin 22), /OE (pin 24), /WRITE (pin 31) | None | ✓ |
| 27C080 | 27C801 | 1MB | 20 (A0-A19) | /CE (pin 22), /OE (pin 24) | VPP: pin 24 (Acts as /OE); /PGM: pin 22 (Acts as /OE) | ✓ |

## 40-pin EPROM Family (27xx)

| Chip Type | Aliases | Size | Address Lines | Control Lines | Programming | Supported |
|---|---|---|---|---|---|---|
| 27C200 | HN62402 | 256KB | 18 (A0-A17) | /BYTE (pin 31), /CE (pin 10), /OE (pin 12) | None | ✓ |
| 27C400 | AT27C400, M27C400, 23C4100, MX23C4100, TCS534200, 27C4100, MX27C4100, HN62404, HN62424, MB834200 | 512KB | 19 (A0-A18) | /BYTE (pin 31), /CE (pin 10), /OE (pin 12) | VPP: pin 31 (Selects word size during read); /PGM: pin 10 (Acts as /OE) | ✓ |

## 24-pin EEPROM Family (28Cxx)

| Chip Type | Aliases | Size | Address Lines | Control Lines | Programming | Supported |
|---|---|---|---|---|---|---|
| 28C16 |  | 2KB | 11 (A0-A10) | /CE (pin 18), /OE (pin 20), /WRITE (pin 21) | None | ✓ |

## 28-pin EEPROM Family (28Cxx)

| Chip Type | Aliases | Size | Address Lines | Control Lines | Programming | Supported |
|---|---|---|---|---|---|---|
| 28C64 |  | 8KB | 13 (A0-A12) | /BUSY (pin 1), /CE (pin 20), /OE (pin 22), /WRITE (pin 27) | None | ✓ |
| 28C256 |  | 32KB | 15 (A0-A14) | /CE (pin 20), /OE (pin 22), /WRITE (pin 27) | None | ✓ |

## 32-pin EEPROM Family (28Cxx)

| Chip Type | Aliases | Size | Address Lines | Control Lines | Programming | Supported |
|---|---|---|---|---|---|---|
| 28C512 |  | 64KB | 16 (A0-A15) | /CE (pin 22), /OE (pin 24), /WRITE (pin 30) | None | ✓ |

## 24-pin Bipolar PROM Family (HM76xx)

| Chip Type | Aliases | Size | Address Lines | Control Lines | Programming | Supported |
|---|---|---|---|---|---|---|
| HM7641 |  | 512B | 9 (A0-A8) | /CS1 (pin 21), /CS2 (pin 20), CS3 (pin 19), CS4 (pin 18) | None | ✓ |

## RAM Chips

| Chip Type | Aliases | Size | Address Lines | Control Lines | Programming | Supported |
|---|---|---|---|---|---|---|
| 6116 | 2016 | 2KB | 11 (A0-A10) | /CE (pin 18), /OE (pin 20), /WRITE (pin 21) | None | ✓ |
| 62256 |  | 32KB | 15 (A0-A14) | /CE (pin 20), /OE (pin 22), /WRITE (pin 27) | None | ✗ |

## Pin Function Comparison

### 24-pin Package

| Pin | 2316 | 2332 | 2364 | 2704 | HM7641 | 2708 | 2716 | 28C16 | 6116 | 2732 |
|-----|---|---|---|---|---|---|---|---|---|---|
| 1 | A7 | A7 | A7 | A7 | A7 | A7 | A7 | A7 | A7 | A7 |
| 2 | A6 | A6 | A6 | A6 | A6 | A6 | A6 | A6 | A6 | A6 |
| 3 | A5 | A5 | A5 | A5 | A5 | A5 | A5 | A5 | A5 | A5 |
| 4 | A4 | A4 | A4 | A4 | A4 | A4 | A4 | A4 | A4 | A4 |
| 5 | A3 | A3 | A3 | A3 | A3 | A3 | A3 | A3 | A3 | A3 |
| 6 | A2 | A2 | A2 | A2 | A2 | A2 | A2 | A2 | A2 | A2 |
| 7 | A1 | A1 | A1 | A1 | A1 | A1 | A1 | A1 | A1 | A1 |
| 8 | A0 | A0 | A0 | A0 | A0 | A0 | A0 | A0 | A0 | A0 |
| 9 | D0 | D0 | D0 | D0 | D0 | D0 | D0 | D0 | D0 | D0 |
| 10 | D1 | D1 | D1 | D1 | D1 | D1 | D1 | D1 | D1 | D1 |
| 11 | D2 | D2 | D2 | D2 | D2 | D2 | D2 | D2 | D2 | D2 |
| 12 | GND | GND | GND | GND | GND | GND | GND | GND | GND | GND |
| 13 | D3 | D3 | D3 | D3 | D3 | D3 | D3 | D3 | D3 | D3 |
| 14 | D4 | D4 | D4 | D4 | D4 | D4 | D4 | D4 | D4 | D4 |
| 15 | D5 | D5 | D5 | D5 | D5 | D5 | D5 | D5 | D5 | D5 |
| 16 | D6 | D6 | D6 | D6 | D6 | D6 | D6 | D6 | D6 | D6 |
| 17 | D7 | D7 | D7 | D7 | D7 | D7 | D7 | D7 | D7 | D7 |
| 18 | CS2 | A11 | A11 | /CE+VPP | CS4 | /CE+VPP | /CE | /CE | /CE | /CE+PE |
| 19 | A10 | A10 | A10 | VDD | CS3 | VDD | A10 | A10 | A10 | A10 |
| 20 | CS1 | CS1 | CS1 | /OE+PE | /CS2 | /OE+PE | /OE+PE | /OE | /OE | /OE+VPP |
| 21 | CS3 | CS2 | A12 | VBB | /CS1 | VBB | VPP | /WRITE | /WRITE | A11 |
| 22 | A9 | A9 | A9 | GND | NC | A9 | A9 | A9 | A9 | A9 |
| 23 | A8 | A8 | A8 | A8 | A8 | A8 | A8 | A8 | A8 | A8 |
| 24 | VCC | VCC | VCC | VCC | VCC | VCC | VCC | VCC | VCC | VCC |

### 28-pin Package

| Pin | 23128 | 23256 | 23QL384 | 23512 | 23QL512 | 231024 | 2764 | 28C64 | 27128 | 27256 | 28C256 | 62256 | 27512 |
|-----|---|---|---|---|---|---|---|---|---|---|---|---|---|
| 1 | NC | NC | NC | A15 | NC | A15 | VPP | /BUSY | VPP | VPP | A14 | A14 | A15 |
| 2 | A12 | A12 | A12 | A12 | A12 | A12 | A12 | A12 | A12 | A12 | A12 | A12 | A12 |
| 3 | A7 | A7 | A7 | A7 | A7 | A7 | A7 | A7 | A7 | A7 | A7 | A7 | A7 |
| 4 | A6 | A6 | A6 | A6 | A6 | A6 | A6 | A6 | A6 | A6 | A6 | A6 | A6 |
| 5 | A5 | A5 | A5 | A5 | A5 | A5 | A5 | A5 | A5 | A5 | A5 | A5 | A5 |
| 6 | A4 | A4 | A4 | A4 | A4 | A4 | A4 | A4 | A4 | A4 | A4 | A4 | A4 |
| 7 | A3 | A3 | A3 | A3 | A3 | A3 | A3 | A3 | A3 | A3 | A3 | A3 | A3 |
| 8 | A2 | A2 | A2 | A2 | A2 | A2 | A2 | A2 | A2 | A2 | A2 | A2 | A2 |
| 9 | A1 | A1 | A1 | A1 | A1 | A1 | A1 | A1 | A1 | A1 | A1 | A1 | A1 |
| 10 | A0 | A0 | A0 | A0 | A0 | A0 | A0 | A0 | A0 | A0 | A0 | A0 | A0 |
| 11 | D0 | D0 | D0 | D0 | D0 | D0 | D0 | D0 | D0 | D0 | D0 | D0 | D0 |
| 12 | D1 | D1 | D1 | D1 | D1 | D1 | D1 | D1 | D1 | D1 | D1 | D1 | D1 |
| 13 | D2 | D2 | D2 | D2 | D2 | D2 | D2 | D2 | D2 | D2 | D2 | D2 | D2 |
| 14 | GND | GND | GND | GND | GND | GND | GND | GND | GND | GND | GND | GND | GND |
| 15 | D3 | D3 | D3 | D3 | D3 | D3 | D3 | D3 | D3 | D3 | D3 | D3 | D3 |
| 16 | D4 | D4 | D4 | D4 | D4 | D4 | D4 | D4 | D4 | D4 | D4 | D4 | D4 |
| 17 | D5 | D5 | D5 | D5 | D5 | D5 | D5 | D5 | D5 | D5 | D5 | D5 | D5 |
| 18 | D6 | D6 | D6 | D6 | D6 | D6 | D6 | D6 | D6 | D6 | D6 | D6 | D6 |
| 19 | D7 | D7 | D7 | D7 | D7 | D7 | D7 | D7 | D7 | D7 | D7 | D7 | D7 |
| 20 | CS1 | CS1 | A15 | CS1 | A15 | CS1 | /CE | /CE | /CE | /CE | /CE | /CE | /CE+PE |
| 21 | A10 | A10 | A10 | A10 | A10 | A10 | A10 | A10 | A10 | A10 | A10 | A10 | A10 |
| 22 | CS2 | CS2 | CS1 | CS2 | CS1 | A16 | /OE | /OE | /OE | /OE+PE | /OE | /OE | /OE+VPP |
| 23 | A11 | A11 | A11 | A11 | A11 | A11 | A11 | A11 | A11 | A11 | A11 | A11 | A11 |
| 24 | A9 | A9 | A9 | A9 | A9 | A9 | A9 | A9 | A9 | A9 | A9 | A9 | A9 |
| 25 | A8 | A8 | A8 | A8 | A8 | A8 | A8 | A8 | A8 | A8 | A8 | A8 | A8 |
| 26 | A13 | A13 | A13 | A13 | A13 | A13 | NC | NC | A13 | A13 | A13 | A13 | A13 |
| 27 | CS3 | A14 | A14 | A14 | A14 | A14 | /PGM | /WRITE | /PGM | A14 | /WRITE | /WRITE | A14 |
| 28 | VCC | VCC | VCC | VCC | VCC | VCC | VCC | VCC | VCC | VCC | VCC | VCC | VCC |

### 32-pin Package

| Pin | 23C1001 | 23C1010 | 28C512 | 27C010 | 27C301 | 27C020 | 27C040 | SST39SF040 | 27C080 |
|-----|---|---|---|---|---|---|---|---|---|
| 1 | NC | NC | NC | VPP | VPP | VPP | VPP | A18 | A19 |
| 2 | A16 | A16 | NC | A16 | /OE | A16 | A16 | A16 | A16 |
| 3 | A15 | A15 | A15 | A15 | A15 | A15 | A15 | A15 | A15 |
| 4 | A12 | A12 | A12 | A12 | A12 | A12 | A12 | A12 | A12 |
| 5 | A7 | A7 | A7 | A7 | A7 | A7 | A7 | A7 | A7 |
| 6 | A6 | A6 | A6 | A6 | A6 | A6 | A6 | A6 | A6 |
| 7 | A5 | A5 | A5 | A5 | A5 | A5 | A5 | A5 | A5 |
| 8 | A4 | A4 | A4 | A4 | A4 | A4 | A4 | A4 | A4 |
| 9 | A3 | A3 | A3 | A3 | A3 | A3 | A3 | A3 | A3 |
| 10 | A2 | A2 | A2 | A2 | A2 | A2 | A2 | A2 | A2 |
| 11 | A1 | A1 | A1 | A1 | A1 | A1 | A1 | A1 | A1 |
| 12 | A0 | A0 | A0 | A0 | A0 | A0 | A0 | A0 | A0 |
| 13 | D0 | D0 | D0 | D0 | D0 | D0 | D0 | D0 | D0 |
| 14 | D1 | D1 | D1 | D1 | D1 | D1 | D1 | D1 | D1 |
| 15 | D2 | D2 | D2 | D2 | D2 | D2 | D2 | D2 | D2 |
| 16 | GND | GND | GND | GND | GND | GND | GND | GND | GND |
| 17 | D3 | D3 | D3 | D3 | D3 | D3 | D3 | D3 | D3 |
| 18 | D4 | D4 | D4 | D4 | D4 | D4 | D4 | D4 | D4 |
| 19 | D5 | D5 | D5 | D5 | D5 | D5 | D5 | D5 | D5 |
| 20 | D6 | D6 | D6 | D6 | D6 | D6 | D6 | D6 | D6 |
| 21 | D7 | D7 | D7 | D7 | D7 | D7 | D7 | D7 | D7 |
| 22 | /CE | /CE | /CE | /CE | /CE | /CE | /CE+/PGM | /CE | /CE+/PGM |
| 23 | A10 | A10 | A10 | A10 | A10 | A10 | A10 | A10 | A10 |
| 24 | /OE | /OE | /OE | /OE | A16 | /OE | /OE | /OE | /OE+VPP |
| 25 | A11 | A11 | A11 | A11 | A11 | A11 | A11 | A11 | A11 |
| 26 | A9 | A9 | A9 | A9 | A9 | A9 | A9 | A9 | A9 |
| 27 | A8 | A8 | A8 | A8 | A8 | A8 | A8 | A8 | A8 |
| 28 | A13 | A13 | A13 | A13 | A13 | A13 | A13 | A13 | A13 |
| 29 | A14 | A14 | A14 | A14 | A14 | A14 | A14 | A14 | A14 |
| 30 | CS2 | NC | /WRITE | NC | NC | A17 | A17 | A17 | A17 |
| 31 | CS1 | NC | NC | /PGM | /PGM | /PGM | A18 | /WRITE | A18 |
| 32 | VCC | VCC | VCC | VCC | VCC | VCC | VCC | VCC | VCC |

### 40-pin Package

| Pin | 27C200 | 27C400 |
|-----|---|---|
| 1 | NC | A18 |
| 2 | A8 | A8 |
| 3 | A7 | A7 |
| 4 | A6 | A6 |
| 5 | A5 | A5 |
| 6 | A4 | A4 |
| 7 | A3 | A3 |
| 8 | A2 | A2 |
| 9 | A1 | A1 |
| 10 | /CE | /CE+/PGM |
| 11 | GND | GND |
| 12 | /OE | /OE |
| 13 | D0 | D0 |
| 14 | D8 | D8 |
| 15 | D1 | D1 |
| 16 | D9 | D9 |
| 17 | D2 | D2 |
| 18 | D10 | D10 |
| 19 | D3 | D3 |
| 20 | D11 | D11 |
| 21 | VCC | VCC |
| 22 | D4 | D4 |
| 23 | D12 | D12 |
| 24 | D5 | D5 |
| 25 | D13 | D13 |
| 26 | D6 | D6 |
| 27 | D14 | D14 |
| 28 | D7 | D7 |
| 29 | A0+D15 | A0+D15 |
| 30 | GND | GND |
| 31 | /BYTE | /BYTE+VPP |
| 32 | A17 | A17 |
| 33 | A16 | A16 |
| 34 | A15 | A15 |
| 35 | A14 | A14 |
| 36 | A13 | A13 |
| 37 | A12 | A12 |
| 38 | A11 | A11 |
| 39 | A10 | A10 |
| 40 | A9 | A9 |

## Detailed Pinouts

### 2316 - 2KB mask ROM with 3 configurable CS lines

**Package:** 24-pin DIP  
**Capacity:** 2048 bytes  
**Control:** 3 configurable CS lines  

| Function | Pins | Notes |
|---|---|---|
| Address (A0-A10) | 8,7,6,5,4,3,2,1,23,22,19 | 11 address lines |
| Data (D0-D7) | 9,10,11,13,14,15,16,17 | 8 data lines |
| CS1 | 20 | Configurable polarity |
| CS2 | 18 | Configurable polarity |
| CS3 | 21 | Configurable polarity |
| VCC | 24 | +5V |
| GND | 12 | 0V |

### 2332 - 4KB mask ROM with 2 configurable CS lines

**Package:** 24-pin DIP  
**Capacity:** 4096 bytes  
**Control:** 2 configurable CS lines  

| Function | Pins | Notes |
|---|---|---|
| Address (A0-A11) | 8,7,6,5,4,3,2,1,23,22,19,18 | 12 address lines |
| Data (D0-D7) | 9,10,11,13,14,15,16,17 | 8 data lines |
| CS1 | 20 | Configurable polarity |
| CS2 | 21 | Configurable polarity |
| VCC | 24 | +5V |
| GND | 12 | 0V |

### 2364 - 8KB mask ROM with 1 configurable CS line

**Package:** 24-pin DIP  
**Capacity:** 8192 bytes  
**Control:** 1 configurable CS line  

| Function | Pins | Notes |
|---|---|---|
| Address (A0-A12) | 8,7,6,5,4,3,2,1,23,22,19,18,21 | 13 address lines |
| Data (D0-D7) | 9,10,11,13,14,15,16,17 | 8 data lines |
| CS1 | 20 | Configurable polarity |
| VCC | 24 | +5V |
| GND | 12 | 0V |

### 23128 - 16KB mask ROM with 3 configurable CS lines

**Package:** 28-pin DIP  
**Capacity:** 16384 bytes  
**Control:** 3 configurable CS lines  

| Function | Pins | Notes |
|---|---|---|
| Address (A0-A13) | 10,9,8,7,6,5,4,3,25,24,21,23,2,26 | 14 address lines |
| Data (D0-D7) | 11,12,13,15,16,17,18,19 | 8 data lines |
| CS1 | 20 | Configurable polarity |
| CS2 | 22 | Configurable polarity |
| CS3 | 27 | Configurable polarity |
| VCC | 28 | +5V |
| GND | 14 | 0V |

### 23256 - 32KB mask ROM with 2 configurable CS lines

**Package:** 28-pin DIP  
**Capacity:** 32768 bytes  
**Control:** 2 configurable CS lines  

| Function | Pins | Notes |
|---|---|---|
| Address (A0-A14) | 10,9,8,7,6,5,4,3,25,24,21,23,2,26,27 | 15 address lines |
| Data (D0-D7) | 11,12,13,15,16,17,18,19 | 8 data lines |
| CS1 | 20 | Configurable polarity |
| CS2 | 22 | Configurable polarity |
| VCC | 28 | +5V |
| GND | 14 | 0V |

### 23QL384 - A composite ROM type, serving a combined 23256 and 23128 for the Sinclair QL, with a single configured CS line and is de-selected when A14 & A15 are both high

**Package:** 28-pin DIP  
**Capacity:** 49152 bytes  
**Control:** 1 configurable CS line  

| Function | Pins | Notes |
|---|---|---|
| Address (A0-A15) | 10,9,8,7,6,5,4,3,25,24,21,23,2,26,27,20 | 16 address lines |
| Data (D0-D7) | 11,12,13,15,16,17,18,19 | 8 data lines |
| CS1 | 22 | Configurable polarity |
| VCC | 28 | +5V |
| GND | 14 | 0V |

### 23512 - 64KB mask ROM with 2 configurable CS lines

**Package:** 28-pin DIP  
**Capacity:** 65536 bytes  
**Control:** 2 configurable CS lines  

| Function | Pins | Notes |
|---|---|---|
| Address (A0-A15) | 10,9,8,7,6,5,4,3,25,24,21,23,2,26,27,1 | 16 address lines |
| Data (D0-D7) | 11,12,13,15,16,17,18,19 | 8 data lines |
| CS1 | 20 | Configurable polarity |
| CS2 | 22 | Configurable polarity |
| VCC | 28 | +5V |
| GND | 14 | 0V |

### 23QL512 - A composite ROM type, serving two combined 23256s for the Sinclair QL, with a single configured CS line at pin 22, and A15 at pin 20 instead of pin 1

**Package:** 28-pin DIP  
**Capacity:** 65536 bytes  
**Control:** 1 configurable CS line  

| Function | Pins | Notes |
|---|---|---|
| Address (A0-A15) | 10,9,8,7,6,5,4,3,25,24,21,23,2,26,27,20 | 16 address lines |
| Data (D0-D7) | 11,12,13,15,16,17,18,19 | 8 data lines |
| CS1 | 22 | Configurable polarity |
| VCC | 28 | +5V |
| GND | 14 | 0V |

### 231024 - 128KB mask ROM with 1 configurable CS line

**Package:** 28-pin DIP  
**Capacity:** 131072 bytes  
**Control:** 1 configurable CS line  

| Function | Pins | Notes |
|---|---|---|
| Address (A0-A16) | 10,9,8,7,6,5,4,3,25,24,21,23,2,26,27,1,22 | 17 address lines |
| Data (D0-D7) | 11,12,13,15,16,17,18,19 | 8 data lines |
| CS1 | 20 | Configurable polarity |
| VCC | 28 | +5V |
| GND | 14 | 0V |

### 23C1001 - 128KB mask programmed ROM with fixed active-low CE/OE, plus 2 programmable CS lines

**Package:** 32-pin DIP  
**Capacity:** 131072 bytes  
**Control:** 2 configurable CS lines, /CE, /OE  

| Function | Pins | Notes |
|---|---|---|
| Address (A0-A16) | 12,11,10,9,8,7,6,5,27,26,23,25,4,28,29,3,2 | 17 address lines |
| Data (D0-D7) | 13,14,15,17,18,19,20,21 | 8 data lines |
| /CE | 22 | Active low |
| CS1 | 31 | Configurable polarity |
| CS2 | 30 | Configurable polarity |
| /OE | 24 | Active low |
| VCC | 32 | +5V |
| GND | 16 | 0V |

### 23C1010 - 128KB mask ROM with fixed active-low CE/OE

**Package:** 32-pin DIP  
**Capacity:** 131072 bytes  
**Control:** /CE, /OE  

| Function | Pins | Notes |
|---|---|---|
| Address (A0-A16) | 12,11,10,9,8,7,6,5,27,26,23,25,4,28,29,3,2 | 17 address lines |
| Data (D0-D7) | 13,14,15,17,18,19,20,21 | 8 data lines |
| /CE | 22 | Active low |
| /OE | 24 | Active low |
| VCC | 32 | +5V |
| GND | 16 | 0V |

### 2704 - 512B EPROM with multiple supply voltages

**Package:** 24-pin DIP  
**Capacity:** 512 bytes  
**Control:** /CE, /OE  

| Function | Pins | Notes |
|---|---|---|
| Address (A0-A8) | 8,7,6,5,4,3,2,1,23 | 9 address lines |
| Data (D0-D7) | 9,10,11,13,14,15,16,17 | 8 data lines |
| /CE | 18 | Active low |
| /OE | 20 | Active low |
| VPP | 18 | Low during read during read |
| PE | 20 | Low during read during read |
| VCC | 24 | +5V |
| VDD | 19 | +12V |
| VBB | 21 | -5V |
| GND | 12 | 0V |
| GND | 22 | 0V |

### HM7641 - 512B bipolar PROM with three-state outputs and four fixed-polarity chip selects

**Package:** 24-pin DIP  
**Capacity:** 512 bytes  
**Control:** /CS1, /CS2, CS3, CS4  

| Function | Pins | Notes |
|---|---|---|
| Address (A0-A8) | 8,7,6,5,4,3,2,1,23 | 9 address lines |
| Data (D0-D7) | 9,10,11,13,14,15,16,17 | 8 data lines |
| /CS1 | 21 | Active low |
| /CS2 | 20 | Active low |
| CS3 | 19 | Active high |
| CS4 | 18 | Active high |
| VCC | 24 | +5V |
| GND | 12 | 0V |

### 2708 - 1KB EPROM with multiple supply voltages

**Package:** 24-pin DIP  
**Capacity:** 1024 bytes  
**Control:** /CE, /OE  

| Function | Pins | Notes |
|---|---|---|
| Address (A0-A9) | 8,7,6,5,4,3,2,1,23,22 | 10 address lines |
| Data (D0-D7) | 9,10,11,13,14,15,16,17 | 8 data lines |
| /CE | 18 | Active low |
| /OE | 20 | Active low |
| VPP | 18 | Low during read during read |
| PE | 20 | Low during read during read |
| VCC | 24 | +5V |
| VDD | 19 | +12V |
| VBB | 21 | -5V |
| GND | 12 | 0V |

### 2716 - 2KB EPROM with fixed active-low CE/OE

**Package:** 24-pin DIP  
**Capacity:** 2048 bytes  
**Control:** /CE, /OE  

| Function | Pins | Notes |
|---|---|---|
| Address (A0-A10) | 8,7,6,5,4,3,2,1,23,22,19 | 11 address lines |
| Data (D0-D7) | 9,10,11,13,14,15,16,17 | 8 data lines |
| /CE | 18 | Active low |
| /OE | 20 | Active low |
| VPP | 21 | VCC during read during read |
| PE | 20 | Low during read during read |
| VCC | 24 | +5V |
| GND | 12 | 0V |

### 28C16 - 2KB EEPROM with fixed active-low CE/OE

**Package:** 24-pin DIP  
**Capacity:** 2048 bytes  
**Control:** /CE, /OE, /WRITE  

| Function | Pins | Notes |
|---|---|---|
| Address (A0-A10) | 8,7,6,5,4,3,2,1,23,22,19 | 11 address lines |
| Data (D0-D7) | 9,10,11,13,14,15,16,17 | 8 data lines |
| /CE | 18 | Active low |
| /OE | 20 | Active low |
| /WRITE | 21 | Active low |
| VCC | 24 | +5V |
| GND | 12 | 0V |

### 6116 - 2KB (2048 x 8-bit) Static RAM with fixed active-low CE/OE/WE

**Package:** 24-pin DIP  
**Capacity:** 2048 bytes  
**Control:** /CE, /OE, /WRITE  

| Function | Pins | Notes |
|---|---|---|
| Address (A0-A10) | 8,7,6,5,4,3,2,1,23,22,19 | 11 address lines |
| Data (D0-D7) | 9,10,11,13,14,15,16,17 | 8 data lines |
| /CE | 18 | Active low |
| /OE | 20 | Active low |
| /WRITE | 21 | Active low |
| VCC | 24 | +5V |
| GND | 12 | 0V |

### 2732 - 4KB EPROM with fixed active-low CE and shared OE/VPP

**Package:** 24-pin DIP  
**Capacity:** 4096 bytes  
**Control:** /CE, /OE  

| Function | Pins | Notes |
|---|---|---|
| Address (A0-A11) | 8,7,6,5,4,3,2,1,23,22,19,21 | 12 address lines |
| Data (D0-D7) | 9,10,11,13,14,15,16,17 | 8 data lines |
| /CE | 18 | Active low |
| /OE | 20 | Active low |
| VPP | 20 | Acts as /OE during read |
| PE | 18 | Low during read during read |
| VCC | 24 | +5V |
| GND | 12 | 0V |

### 2764 - 8KB EPROM with fixed active-low CE/OE

**Package:** 28-pin DIP  
**Capacity:** 8192 bytes  
**Control:** /CE, /OE  

| Function | Pins | Notes |
|---|---|---|
| Address (A0-A12) | 10,9,8,7,6,5,4,3,25,24,21,23,2 | 13 address lines |
| Data (D0-D7) | 11,12,13,15,16,17,18,19 | 8 data lines |
| /CE | 20 | Active low |
| /OE | 22 | Active low |
| VPP | 1 | VCC during read during read |
| /PGM | 27 | High during read during read |
| VCC | 28 | +5V |
| GND | 14 | 0V |

### 28C64 - 8KB EEPROM with fixed active-low CE/OE

**Package:** 28-pin DIP  
**Capacity:** 8192 bytes  
**Control:** /BUSY, /CE, /OE, /WRITE  

| Function | Pins | Notes |
|---|---|---|
| Address (A0-A12) | 10,9,8,7,6,5,4,3,25,24,21,23,2 | 13 address lines |
| Data (D0-D7) | 11,12,13,15,16,17,18,19 | 8 data lines |
| /BUSY | 1 | Active low |
| /CE | 20 | Active low |
| /OE | 22 | Active low |
| /WRITE | 27 | Active low |
| VCC | 28 | +5V |
| GND | 14 | 0V |

### 27128 - 16KB EPROM with fixed active-low CE/OE

**Package:** 28-pin DIP  
**Capacity:** 16384 bytes  
**Control:** /CE, /OE  

| Function | Pins | Notes |
|---|---|---|
| Address (A0-A13) | 10,9,8,7,6,5,4,3,25,24,21,23,2,26 | 14 address lines |
| Data (D0-D7) | 11,12,13,15,16,17,18,19 | 8 data lines |
| /CE | 20 | Active low |
| /OE | 22 | Active low |
| VPP | 1 | VCC during read during read |
| /PGM | 27 | High during read during read |
| VCC | 28 | +5V |
| GND | 14 | 0V |

### 27256 - 32KB EPROM with fixed active-low CE/OE

**Package:** 28-pin DIP  
**Capacity:** 32768 bytes  
**Control:** /CE, /OE  

| Function | Pins | Notes |
|---|---|---|
| Address (A0-A14) | 10,9,8,7,6,5,4,3,25,24,21,23,2,26,27 | 15 address lines |
| Data (D0-D7) | 11,12,13,15,16,17,18,19 | 8 data lines |
| /CE | 20 | Active low |
| /OE | 22 | Active low |
| VPP | 1 | VCC during read during read |
| PE | 22 | Low during read during read |
| VCC | 28 | +5V |
| GND | 14 | 0V |

### 28C256 - 32KB EEPROM with fixed active-low CE/OE

**Package:** 28-pin DIP  
**Capacity:** 32768 bytes  
**Control:** /CE, /OE, /WRITE  

| Function | Pins | Notes |
|---|---|---|
| Address (A0-A14) | 10,9,8,7,6,5,4,3,25,24,21,23,2,26,1 | 15 address lines |
| Data (D0-D7) | 11,12,13,15,16,17,18,19 | 8 data lines |
| /CE | 20 | Active low |
| /OE | 22 | Active low |
| /WRITE | 27 | Active low |
| VCC | 28 | +5V |
| GND | 14 | 0V |

### 62256 - 32KB (32768 x 8-bit) Static RAM with fixed active-low CE/OE/WE

**Package:** 28-pin DIP  
**Capacity:** 32768 bytes  
**Control:** /CE, /OE, /WRITE  

| Function | Pins | Notes |
|---|---|---|
| Address (A0-A14) | 10,9,8,7,6,5,4,3,25,24,21,23,2,26,1 | 15 address lines |
| Data (D0-D7) | 11,12,13,15,16,17,18,19 | 8 data lines |
| /CE | 20 | Active low |
| /OE | 22 | Active low |
| /WRITE | 27 | Active low |
| VCC | 28 | +5V |
| GND | 14 | 0V |

### 27512 - 64KB EPROM with fixed active-low CE/OE

**Package:** 28-pin DIP  
**Capacity:** 65536 bytes  
**Control:** /CE, /OE  

| Function | Pins | Notes |
|---|---|---|
| Address (A0-A15) | 10,9,8,7,6,5,4,3,25,24,21,23,2,26,27,1 | 16 address lines |
| Data (D0-D7) | 11,12,13,15,16,17,18,19 | 8 data lines |
| /CE | 20 | Active low |
| /OE | 22 | Active low |
| VPP | 22 | VCC during read during read |
| PE | 20 | Low during read during read |
| VCC | 28 | +5V |
| GND | 14 | 0V |

### 28C512 - 64KB EEPROM with fixed active-low CE/OE

**Package:** 32-pin DIP  
**Capacity:** 65536 bytes  
**Control:** /CE, /OE, /WRITE  

| Function | Pins | Notes |
|---|---|---|
| Address (A0-A15) | 12,11,10,9,8,7,6,5,27,26,23,25,4,28,29,3 | 16 address lines |
| Data (D0-D7) | 13,14,15,17,18,19,20,21 | 8 data lines |
| /CE | 22 | Active low |
| /OE | 24 | Active low |
| /WRITE | 30 | Active low |
| VCC | 32 | +5V |
| GND | 16 | 0V |

### 27C010 - 128KB EPROM with fixed active-low CE/OE

**Package:** 32-pin DIP  
**Capacity:** 131072 bytes  
**Control:** /CE, /OE  

| Function | Pins | Notes |
|---|---|---|
| Address (A0-A16) | 12,11,10,9,8,7,6,5,27,26,23,25,4,28,29,3,2 | 17 address lines |
| Data (D0-D7) | 13,14,15,17,18,19,20,21 | 8 data lines |
| /CE | 22 | Active low |
| /OE | 24 | Active low |
| VPP | 1 | Don't care during read during read |
| /PGM | 31 | Don't care during read during read |
| VCC | 32 | +5V |
| GND | 16 | 0V |

### 27C301 - 128KB EPROM with fixed active-low CE/OE

**Package:** 32-pin DIP  
**Capacity:** 131072 bytes  
**Control:** /CE, /OE  

| Function | Pins | Notes |
|---|---|---|
| Address (A0-A16) | 12,11,10,9,8,7,6,5,27,26,23,25,4,28,29,3,24 | 17 address lines |
| Data (D0-D7) | 13,14,15,17,18,19,20,21 | 8 data lines |
| /CE | 22 | Active low |
| /OE | 2 | Active low |
| VPP | 1 | Don't care during read during read |
| /PGM | 31 | Don't care during read during read |
| VCC | 32 | +5V |
| GND | 16 | 0V |

### 27C020 - 256KB EPROM with fixed active-low CE/OE

**Package:** 32-pin DIP  
**Capacity:** 262144 bytes  
**Control:** /CE, /OE  

| Function | Pins | Notes |
|---|---|---|
| Address (A0-A17) | 12,11,10,9,8,7,6,5,27,26,23,25,4,28,29,3,2,30 | 18 address lines |
| Data (D0-D7) | 13,14,15,17,18,19,20,21 | 8 data lines |
| /CE | 22 | Active low |
| /OE | 24 | Active low |
| VPP | 1 | Don't care during read during read |
| /PGM | 31 | Don't care during read during read |
| VCC | 32 | +5V |
| GND | 16 | 0V |

### 27C200 - 0.25MB mask programmed EPROM with fixed active-low CE/OE

**Package:** 40-pin DIP  
**Capacity:** 262144 bytes  
**Control:** /BYTE, /CE, /OE  

| Function | Pins | Notes |
|---|---|---|
| Address (A0-A17) | 29,9,8,7,6,5,4,3,2,40,39,38,37,36,35,34,33,32 | 18 address lines |
| Data (D0-D15) | 13,15,17,19,22,24,26,28,14,16,18,20,23,25,27,29 | 16 data lines |
| /BYTE | 31 | Active low |
| /CE | 10 | Active low |
| /OE | 12 | Active low |
| VCC | 21 | +5V |
| GND | 11 | 0V |
| GND | 30 | 0V |

### 27C040 - 512KB EPROM with fixed active-low CE/OE

**Package:** 32-pin DIP  
**Capacity:** 524288 bytes  
**Control:** /CE, /OE  

| Function | Pins | Notes |
|---|---|---|
| Address (A0-A18) | 12,11,10,9,8,7,6,5,27,26,23,25,4,28,29,3,2,30,31 | 19 address lines |
| Data (D0-D7) | 13,14,15,17,18,19,20,21 | 8 data lines |
| /CE | 22 | Active low |
| /OE | 24 | Active low |
| VPP | 1 | Don't care during read during read |
| /PGM | 22 | Acts as /OE during read |
| VCC | 32 | +5V |
| GND | 16 | 0V |

### 27C400 - 0.5MB EPROM with fixed active-low CE/OE

**Package:** 40-pin DIP  
**Capacity:** 524288 bytes  
**Control:** /BYTE, /CE, /OE  

| Function | Pins | Notes |
|---|---|---|
| Address (A0-A18) | 29,9,8,7,6,5,4,3,2,40,39,38,37,36,35,34,33,32,1 | 19 address lines |
| Data (D0-D15) | 13,15,17,19,22,24,26,28,14,16,18,20,23,25,27,29 | 16 data lines |
| /BYTE | 31 | Active low |
| /CE | 10 | Active low |
| /OE | 12 | Active low |
| VPP | 31 | Selects word size during read during read |
| /PGM | 10 | Acts as /OE during read |
| VCC | 21 | +5V |
| GND | 11 | 0V |
| GND | 30 | 0V |

### SST39SF040 - 512KB flash with fixed active-low CE/OE and different pinout to 27C040

**Package:** 32-pin DIP  
**Capacity:** 524288 bytes  
**Control:** /CE, /OE, /WRITE  

| Function | Pins | Notes |
|---|---|---|
| Address (A0-A18) | 12,11,10,9,8,7,6,5,27,26,23,25,4,28,29,3,2,30,1 | 19 address lines |
| Data (D0-D7) | 13,14,15,17,18,19,20,21 | 8 data lines |
| /CE | 22 | Active low |
| /OE | 24 | Active low |
| /WRITE | 31 | Active low |
| VCC | 32 | +5V |
| GND | 16 | 0V |

### 27C080 - 1MB EPROM with fixed active-low CE/OE

**Package:** 32-pin DIP  
**Capacity:** 1048576 bytes  
**Control:** /CE, /OE  

| Function | Pins | Notes |
|---|---|---|
| Address (A0-A19) | 12,11,10,9,8,7,6,5,27,26,23,25,4,28,29,3,2,30,31,1 | 20 address lines |
| Data (D0-D7) | 13,14,15,17,18,19,20,21 | 8 data lines |
| /CE | 22 | Active low |
| /OE | 24 | Active low |
| VPP | 24 | Acts as /OE during read |
| /PGM | 22 | Acts as /OE during read |
| VCC | 32 | +5V |
| GND | 16 | 0V |

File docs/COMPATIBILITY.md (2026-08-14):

# One ROM Chip Compatibility — firmware v0.7.1

This document shows which chips each One ROM Fire hardware variant emulates.

**ROM size** is the chip's actual storage capacity.

**Image size** is the space used on One ROM device's internal flash to emulate that chip. This can be larger than the original ROM itself, due to the way One ROM works.

One ROM typically has a 2MB flash, with 64KB reserved for the firmware and metadata. The remainder is available for ROM images. The total number of images that can be supported is based on the image size of each ROM.

Some lower pin count ROMs can be emulated by larger One ROMs, by inserting the larger One ROM in the smaller socket, with the top pins (1, 2, ...) hanging out (and it is not necessary to solder these pins to One ROM if using like this). If doing this, it is _extremely_ important that power is rerouted to One ROM's VCC pin, or to the 5V header pin, or One ROM may be damaged.

Some greater pin count ROMs can be emulated by a smaller One ROM, provided the ROM's extra address pins fall on socket positions that One ROM does not use. In this case, the smaller One ROM gets installed to the bottom of the larger socket, with the top pins of the socket unpopulated. A short fly-lead must be run from each additional address pin of those socket pins to the X1 (and, if two are needed, X2) header pin on One ROM.

**Every image size below assumes One ROM monitors all of the chip's control lines** — every chip select, or /CE and /OE — which is what the tools produce unless told otherwise. A chip that One ROM can only serve with one of those lines left unmonitored is shown as unsupported here, because doing that requires the `allow_cs_ignore` config option and cannot be expressed on the `onerom` command line at all.

| Cell | Meaning |
|:---|:---|
| `64KB` | Chip is supported on this board; shows the image size |
| `64KB*` | Supported with One ROM overhanging the socket (top pins exposed — power reroute required) |
| `64KB†` | Supported with fly-lead wire(s) from the chip socket's address pin(s) to One ROM's X1 (and X2) header pin |
| `-` | Not supported on this board |

## 24-pin boards

*24-pin chips (native)*

| Chip | ROM size | 24A | 24B | 24C | 24D | 24E | 24F |
|:---|---:|---:|---:|---:|---:|---:|---:|
| 2704 | 512B | 2KB | 2KB | 512B | 512B | 512B | 512B |
| HM7641 | 512B | 2KB | 2KB | 512B | 512B | 512B | 512B |
| 2708 | 1KB | 4KB | 4KB | 1KB | 1KB | 1KB | 1KB |
| 2316 | 2KB | 32KB | 32KB | 2KB | 2KB | 2KB | 2KB |
| 2716 | 2KB | 32KB | 32KB | 2KB | 2KB | 2KB | 2KB |
| 28C16 | 2KB | 32KB | 32KB | 2KB | 2KB | 2KB | 2KB |
| 9316 | 2KB | 32KB | 32KB | 2KB | 2KB | 2KB | 2KB |
| 9316A | 2KB | 32KB | 32KB | 2KB | 2KB | 2KB | 2KB |
| 2332 | 4KB | 64KB | 64KB | 8KB | 8KB | 8KB | 8KB |
| 2732 | 4KB | 32KB | 32KB | 4KB | 4KB | 4KB | 4KB |
| 27C32 | 4KB | 32KB | 32KB | 4KB | 4KB | 4KB | 4KB |
| 4732 | 4KB | 64KB | 64KB | 8KB | 8KB | 8KB | 8KB |
| 9332 | 4KB | 64KB | 64KB | 8KB | 8KB | 8KB | 8KB |
| 2364 | 8KB | 64KB | 64KB | 8KB | 8KB | 8KB | 8KB |
| 4764 | 8KB | 64KB | 64KB | 8KB | 8KB | 8KB | 8KB |
| MCM68364 | 8KB | 64KB | 64KB | 8KB | 8KB | 8KB | 8KB |
| MCM68764 | 8KB | 64KB | 64KB | 8KB | 8KB | 8KB | 8KB |
| MCM68A364 | 8KB | 64KB | 64KB | 8KB | 8KB | 8KB | 8KB |
| MCM68A764 | 8KB | 64KB | 64KB | 8KB | 8KB | 8KB | 8KB |
| MK36000 | 8KB | 64KB | 64KB | 8KB | 8KB | 8KB | 8KB |
| MM52164 | 8KB | 64KB | 64KB | 8KB | 8KB | 8KB | 8KB |

*28-pin chips (with fly-leads)*

| Chip | ROM size | 24A | 24B | 24C | 24D | 24E | 24F |
|:---|---:|---:|---:|---:|---:|---:|---:|
| 2764 | 8KB | 32KB† | 32KB† | 32KB† | 32KB† | 32KB† | 32KB† |
| 27C64 | 8KB | 32KB† | 32KB† | 32KB† | 32KB† | 32KB† | 32KB† |
| 27LC64 | 8KB | 32KB† | 32KB† | 32KB† | 32KB† | 32KB† | 32KB† |
| 28C64 | 8KB | 32KB† | 32KB† | 32KB† | 32KB† | 32KB† | 32KB† |

## 28-pin boards

*28-pin chips (native)*

| Chip | ROM size | 28A | 28B | 28C | 28D |
|:---|---:|---:|---:|---:|---:|
| 2764 | 8KB | 32KB | 32KB | 32KB | 32KB |
| 27C64 | 8KB | 32KB | 32KB | 32KB | 32KB |
| 27LC64 | 8KB | 32KB | 32KB | 32KB | 32KB |
| 28C64 | 8KB | 32KB | 32KB | 32KB | 32KB |
| 23128 | 16KB | 32KB | 32KB | 32KB | 32KB |
| 27128 | 16KB | 32KB | 32KB | 32KB | 32KB |
| 27C128 | 16KB | 32KB | 32KB | 32KB | 32KB |
| 27LC128 | 16KB | 32KB | 32KB | 32KB | 32KB |
| 23256 | 32KB | 64KB | 64KB | 64KB | 64KB |
| 27256 | 32KB | 64KB | 64KB | 64KB | 64KB |
| 27C256 | 32KB | 64KB | 64KB | 64KB | 64KB |
| 27LC256 | 32KB | 64KB | 64KB | 64KB | 64KB |
| 27SF256 | 32KB | 64KB | 64KB | 64KB | 64KB |
| 28C256 | 32KB | 32KB | 32KB | 32KB | 32KB |
| 23QL384 | 48KB | 128KB | 128KB | 256KB | 256KB |
| 23512 | 64KB | 64KB | 64KB | 64KB | 64KB |
| 23QL512 | 64KB | 128KB | 128KB | 256KB | 256KB |
| 27512 | 64KB | 64KB | 64KB | 64KB | 64KB |
| 27C512 | 64KB | 64KB | 64KB | 64KB | 64KB |
| 27LC512 | 64KB | 64KB | 64KB | 64KB | 64KB |
| 27SF512 | 64KB | 64KB | 64KB | 64KB | 64KB |
| 231024 | 128KB | 256KB | 256KB | 128KB | 128KB |
| 23C1000 | 128KB | 256KB | 256KB | 128KB | 128KB |
| 23C1000A | 128KB | 256KB | 256KB | 128KB | 128KB |
| MX23C1000 | 128KB | 256KB | 256KB | 128KB | 128KB |
| TC531000 | 128KB | 256KB | 256KB | 128KB | 128KB |

*24-pin chips (with overhang)*

| Chip | ROM size | 28A | 28B | 28C | 28D |
|:---|---:|---:|---:|---:|---:|
| 2704 | 512B | 4KB* | 4KB* | 4KB* | 4KB* |
| HM7641 | 512B | - | - | 4KB* | 4KB* |
| 2708 | 1KB | 16KB* | 16KB* | 8KB* | 8KB* |
| 2716 | 2KB | 32KB* | 32KB* | 32KB* | 32KB* |
| 28C16 | 2KB | 32KB* | 32KB* | 32KB* | 32KB* |
| 2732 | 4KB | 32KB* | 32KB* | 32KB* | 32KB* |
| 27C32 | 4KB | 32KB* | 32KB* | 32KB* | 32KB* |
| 2364 | 8KB | 128KB* | 128KB* | 256KB* | 256KB* |
| 4764 | 8KB | 128KB* | 128KB* | 256KB* | 256KB* |
| MCM68364 | 8KB | 128KB* | 128KB* | 256KB* | 256KB* |
| MCM68764 | 8KB | 128KB* | 128KB* | 256KB* | 256KB* |
| MCM68A364 | 8KB | 128KB* | 128KB* | 256KB* | 256KB* |
| MCM68A764 | 8KB | 128KB* | 128KB* | 256KB* | 256KB* |
| MK36000 | 8KB | 128KB* | 128KB* | 256KB* | 256KB* |
| MM52164 | 8KB | 128KB* | 128KB* | 256KB* | 256KB* |

*32-pin chips (with fly-leads)*

| Chip | ROM size | 28A | 28B | 28C | 28D |
|:---|---:|---:|---:|---:|---:|
| 28C512 | 64KB | 64KB† | 64KB† | 64KB† | 64KB† |
| 23C1010 | 128KB | - | - | 128KB† | 128KB† |
| 27C010 | 128KB | - | - | 128KB† | 128KB† |
| 27C1000A | 128KB | - | - | 128KB† | 128KB† |
| 27C1001 | 128KB | - | - | 128KB† | 128KB† |
| 29F010 | 128KB | - | - | 128KB† | 128KB† |
| 39SF010 | 128KB | - | - | 128KB† | 128KB† |
| SST39SF010 | 128KB | - | - | 128KB† | 128KB† |

## 32-pin boards

*32-pin chips (native)*

| Chip | ROM size | 32A | 32B |
|:---|---:|---:|---:|
| 28C512 | 64KB | 256KB | 64KB |
| 23C1001 | 128KB | - | 128KB |
| 23C1010 | 128KB | 512KB | 128KB |
| 27C010 | 128KB | 512KB | 128KB |
| 27C100 | 128KB | 512KB | 256KB |
| 27C1000 | 128KB | 512KB | 256KB |
| 27C1000A | 128KB | 512KB | 128KB |
| 27C1001 | 128KB | 512KB | 128KB |
| 27C301 | 128KB | 512KB | 256KB |
| 29F010 | 128KB | 512KB | 128KB |
| 39SF010 | 128KB | 512KB | 128KB |
| D23C1001 | 128KB | - | 128KB |
| SST39SF010 | 128KB | 512KB | 128KB |
| 27C020 | 256KB | 512KB | 256KB |
| 27C2001 | 256KB | 512KB | 256KB |
| 29F020 | 256KB | 512KB | 256KB |
| 39SF020 | 256KB | 512KB | 256KB |
| SST39SF020 | 256KB | 512KB | 256KB |
| 27C040 | 512KB | 512KB | 512KB |
| 27C4001 | 512KB | 512KB | 512KB |
| 29F040 | 512KB | - | 512KB |
| 39SF040 | 512KB | - | 512KB |
| SST39SF040 | 512KB | - | 512KB |
| 27C080 | 1MB | 512KB | 512KB |
| 27C801 | 1MB | 512KB | 512KB |

*28-pin chips (with overhang)*

| Chip | ROM size | 32A | 32B |
|:---|---:|---:|---:|
| 2764 | 8KB | 256KB* | 32KB* |
| 27C64 | 8KB | 256KB* | 32KB* |
| 27LC64 | 8KB | 256KB* | 32KB* |
| 28C64 | 8KB | 256KB* | 32KB* |
| 27128 | 16KB | 256KB* | 32KB* |
| 27C128 | 16KB | 256KB* | 32KB* |
| 27LC128 | 16KB | 256KB* | 32KB* |
| 23256 | 32KB | 256KB* | 32KB* |
| 27256 | 32KB | 256KB* | 32KB* |
| 27C256 | 32KB | 256KB* | 32KB* |
| 27LC256 | 32KB | 256KB* | 32KB* |
| 27SF256 | 32KB | 256KB* | 32KB* |
| 28C256 | 32KB | 256KB* | 64KB* |
| 23512 | 64KB | 256KB* | 64KB* |
| 27512 | 64KB | 256KB* | 64KB* |
| 27C512 | 64KB | 256KB* | 64KB* |
| 27LC512 | 64KB | 256KB* | 64KB* |
| 27SF512 | 64KB | 256KB* | 64KB* |
| 231024 | 128KB | 512KB* | 256KB* |
| 23C1000 | 128KB | 512KB* | 256KB* |
| 23C1000A | 128KB | 512KB* | 256KB* |
| MX23C1000 | 128KB | 512KB* | 256KB* |
| TC531000 | 128KB | 512KB* | 256KB* |

*24-pin chips (with overhang)*

| Chip | ROM size | 32A | 32B |
|:---|---:|---:|---:|
| 2704 | 512B | 32KB* | 4KB* |
| HM7641 | 512B | 32KB* | - |
| 2708 | 1KB | 64KB* | 8KB* |
| 2716 | 2KB | 256KB* | 32KB* |
| 28C16 | 2KB | 256KB* | 32KB* |
| 2732 | 4KB | 256KB* | 32KB* |
| 27C32 | 4KB | 256KB* | 32KB* |

## 40-pin boards

| Chip | ROM size | 40A | 40B |
|:---|---:|---:|---:|
| 27C200 | 256KB | 512KB | 256KB |
| HN62402 | 256KB | 512KB | 256KB |
| 23C4100 | 512KB | 512KB | 512KB |
| 27C400 | 512KB | 512KB | 512KB |
| 27C4100 | 512KB | 512KB | 512KB |
| AT27C400 | 512KB | 512KB | 512KB |
| HN62404 | 512KB | 512KB | 512KB |
| HN62424 | 512KB | 512KB | 512KB |
| M27C400 | 512KB | 512KB | 512KB |
| MB834200 | 512KB | 512KB | 512KB |
| MX23C4100 | 512KB | 512KB | 512KB |
| MX27C4100 | 512KB | 512KB | 512KB |
| TCS534200 | 512KB | 512KB | 512KB |

---

# Per-board details

Full chip list for each board. Where a particular ROM type goes by multiple identifiers (for example 27512, 27C512, 27SF512), each type appears as a separate row.

The **Fit** column says how the chip sits in the board's socket:

| Fit | Meaning |
|:---|:---|
| `native` | Chip and board have the same pin count — it goes straight in |
| `overhang` | Chip has *fewer* pins than the board, so One ROM's top pins hang out of the socket |
| `larger socket (no fly-leads)` | Chip has *more* pins than the board, but no address line among the extra ones: One ROM sits in the bottom of the socket with nothing to wire |
| `fly-lead to X1` (and `X2`) | Chip has more pins than the board, and the overhanging address line(s) must be wired to One ROM's X1 (and X2) header pin |

Every fit other than `native` is a cross-size fit, and in all of them One ROM's power pins may not line up with the socket's — power must be rerouted to One ROM's own VCC or 5V header pin. `larger socket (no fly-leads)` means no *signal* wiring is needed; it does not mean the chip simply drops in.

## One ROM Fire 24 (rev A/A2) — fire-24-a

*24-pin chips (native)*

| Chip | ROM size | Image size | Fit |
|:---|---:|---:|:---|
| 2704 | 512B | 2KB | native |
| HM7641 | 512B | 2KB | native |
| 2708 | 1KB | 4KB | native |
| 2316 | 2KB | 32KB | native |
| 2716 | 2KB | 32KB | native |
| 28C16 | 2KB | 32KB | native |
| 9316 | 2KB | 32KB | native |
| 9316A | 2KB | 32KB | native |
| 2332 | 4KB | 64KB | native |
| 2732 | 4KB | 32KB | native |
| 27C32 | 4KB | 32KB | native |
| 4732 | 4KB | 64KB | native |
| 9332 | 4KB | 64KB | native |
| 2364 | 8KB | 64KB | native |
| 4764 | 8KB | 64KB | native |
| MCM68364 | 8KB | 64KB | native |
| MCM68764 | 8KB | 64KB | native |
| MCM68A364 | 8KB | 64KB | native |
| MCM68A764 | 8KB | 64KB | native |
| MK36000 | 8KB | 64KB | native |
| MM52164 | 8KB | 64KB | native |

*28-pin chips (with fly-leads)*

| Chip | ROM size | Image size | Fit |
|:---|---:|---:|:---|
| 2764 | 8KB | 32KB | fly-lead to X1 |
| 27C64 | 8KB | 32KB | fly-lead to X1 |
| 27LC64 | 8KB | 32KB | fly-lead to X1 |
| 28C64 | 8KB | 32KB | fly-lead to X1 |

## One ROM Fire 24 (rev B) — fire-24-usb-b

*24-pin chips (native)*

| Chip | ROM size | Image size | Fit |
|:---|---:|---:|:---|
| 2704 | 512B | 2KB | native |
| HM7641 | 512B | 2KB | native |
| 2708 | 1KB | 4KB | native |
| 2316 | 2KB | 32KB | native |
| 2716 | 2KB | 32KB | native |
| 28C16 | 2KB | 32KB | native |
| 9316 | 2KB | 32KB | native |
| 9316A | 2KB | 32KB | native |
| 2332 | 4KB | 64KB | native |
| 2732 | 4KB | 32KB | native |
| 27C32 | 4KB | 32KB | native |
| 4732 | 4KB | 64KB | native |
| 9332 | 4KB | 64KB | native |
| 2364 | 8KB | 64KB | native |
| 4764 | 8KB | 64KB | native |
| MCM68364 | 8KB | 64KB | native |
| MCM68764 | 8KB | 64KB | native |
| MCM68A364 | 8KB | 64KB | native |
| MCM68A764 | 8KB | 64KB | native |
| MK36000 | 8KB | 64KB | native |
| MM52164 | 8KB | 64KB | native |

*28-pin chips (with fly-leads)*

| Chip | ROM size | Image size | Fit |
|:---|---:|---:|:---|
| 2764 | 8KB | 32KB | fly-lead to X1 |
| 27C64 | 8KB | 32KB | fly-lead to X1 |
| 27LC64 | 8KB | 32KB | fly-lead to X1 |
| 28C64 | 8KB | 32KB | fly-lead to X1 |

## One ROM Fire 24 (rev C) — fire-24-c

*24-pin chips (native)*

| Chip | ROM size | Image size | Fit |
|:---|---:|---:|:---|
| 2704 | 512B | 512B | native |
| HM7641 | 512B | 512B | native |
| 2708 | 1KB | 1KB | native |
| 2316 | 2KB | 2KB | native |
| 2716 | 2KB | 2KB | native |
| 28C16 | 2KB | 2KB | native |
| 9316 | 2KB | 2KB | native |
| 9316A | 2KB | 2KB | native |
| 2332 | 4KB | 8KB | native |
| 2732 | 4KB | 4KB | native |
| 27C32 | 4KB | 4KB | native |
| 4732 | 4KB | 8KB | native |
| 9332 | 4KB | 8KB | native |
| 2364 | 8KB | 8KB | native |
| 4764 | 8KB | 8KB | native |
| MCM68364 | 8KB | 8KB | native |
| MCM68764 | 8KB | 8KB | native |
| MCM68A364 | 8KB | 8KB | native |
| MCM68A764 | 8KB | 8KB | native |
| MK36000 | 8KB | 8KB | native |
| MM52164 | 8KB | 8KB | native |

*28-pin chips (with fly-leads)*

| Chip | ROM size | Image size | Fit |
|:---|---:|---:|:---|
| 2764 | 8KB | 32KB | fly-lead to X1 |
| 27C64 | 8KB | 32KB | fly-lead to X1 |
| 27LC64 | 8KB | 32KB | fly-lead to X1 |
| 28C64 | 8KB | 32KB | fly-lead to X1 |

## One ROM Fire 24 (rev D) — fire-24-d

*24-pin chips (native)*

| Chip | ROM size | Image size | Fit |
|:---|---:|---:|:---|
| 2704 | 512B | 512B | native |
| HM7641 | 512B | 512B | native |
| 2708 | 1KB | 1KB | native |
| 2316 | 2KB | 2KB | native |
| 2716 | 2KB | 2KB | native |
| 28C16 | 2KB | 2KB | native |
| 9316 | 2KB | 2KB | native |
| 9316A | 2KB | 2KB | native |
| 2332 | 4KB | 8KB | native |
| 2732 | 4KB | 4KB | native |
| 27C32 | 4KB | 4KB | native |
| 4732 | 4KB | 8KB | native |
| 9332 | 4KB | 8KB | native |
| 2364 | 8KB | 8KB | native |
| 4764 | 8KB | 8KB | native |
| MCM68364 | 8KB | 8KB | native |
| MCM68764 | 8KB | 8KB | native |
| MCM68A364 | 8KB | 8KB | native |
| MCM68A764 | 8KB | 8KB | native |
| MK36000 | 8KB | 8KB | native |
| MM52164 | 8KB | 8KB | native |

*28-pin chips (with fly-leads)*

| Chip | ROM size | Image size | Fit |
|:---|---:|---:|:---|
| 2764 | 8KB | 32KB | fly-lead to X1 |
| 27C64 | 8KB | 32KB | fly-lead to X1 |
| 27LC64 | 8KB | 32KB | fly-lead to X1 |
| 28C64 | 8KB | 32KB | fly-lead to X1 |

## One ROM Fire 24 (rev E) — fire-24-e

*24-pin chips (native)*

| Chip | ROM size | Image size | Fit |
|:---|---:|---:|:---|
| 2704 | 512B | 512B | native |
| HM7641 | 512B | 512B | native |
| 2708 | 1KB | 1KB | native |
| 2316 | 2KB | 2KB | native |
| 2716 | 2KB | 2KB | native |
| 28C16 | 2KB | 2KB | native |
| 9316 | 2KB | 2KB | native |
| 9316A | 2KB | 2KB | native |
| 2332 | 4KB | 8KB | native |
| 2732 | 4KB | 4KB | native |
| 27C32 | 4KB | 4KB | native |
| 4732 | 4KB | 8KB | native |
| 9332 | 4KB | 8KB | native |
| 2364 | 8KB | 8KB | native |
| 4764 | 8KB | 8KB | native |
| MCM68364 | 8KB | 8KB | native |
| MCM68764 | 8KB | 8KB | native |
| MCM68A364 | 8KB | 8KB | native |
| MCM68A764 | 8KB | 8KB | native |
| MK36000 | 8KB | 8KB | native |
| MM52164 | 8KB | 8KB | native |

*28-pin chips (with fly-leads)*

| Chip | ROM size | Image size | Fit |
|:---|---:|---:|:---|
| 2764 | 8KB | 32KB | fly-lead to X1 |
| 27C64 | 8KB | 32KB | fly-lead to X1 |
| 27LC64 | 8KB | 32KB | fly-lead to X1 |
| 28C64 | 8KB | 32KB | fly-lead to X1 |

## One ROM Fire 24 (rev F) — fire-24-f

*24-pin chips (native)*

| Chip | ROM size | Image size | Fit |
|:---|---:|---:|:---|
| 2704 | 512B | 512B | native |
| HM7641 | 512B | 512B | native |
| 2708 | 1KB | 1KB | native |
| 2316 | 2KB | 2KB | native |
| 2716 | 2KB | 2KB | native |
| 28C16 | 2KB | 2KB | native |
| 9316 | 2KB | 2KB | native |
| 9316A | 2KB | 2KB | native |
| 2332 | 4KB | 8KB | native |
| 2732 | 4KB | 4KB | native |
| 27C32 | 4KB | 4KB | native |
| 4732 | 4KB | 8KB | native |
| 9332 | 4KB | 8KB | native |
| 2364 | 8KB | 8KB | native |
| 4764 | 8KB | 8KB | native |
| MCM68364 | 8KB | 8KB | native |
| MCM68764 | 8KB | 8KB | native |
| MCM68A364 | 8KB | 8KB | native |
| MCM68A764 | 8KB | 8KB | native |
| MK36000 | 8KB | 8KB | native |
| MM52164 | 8KB | 8KB | native |

*28-pin chips (with fly-leads)*

| Chip | ROM size | Image size | Fit |
|:---|---:|---:|:---|
| 2764 | 8KB | 32KB | fly-lead to X1 |
| 27C64 | 8KB | 32KB | fly-lead to X1 |
| 27LC64 | 8KB | 32KB | fly-lead to X1 |
| 28C64 | 8KB | 32KB | fly-lead to X1 |

## One ROM Fire 28 (rev A/A2/A3/A4) — fire-28-a

*28-pin chips (native)*

| Chip | ROM size | Image size | Fit |
|:---|---:|---:|:---|
| 2764 | 8KB | 32KB | native |
| 27C64 | 8KB | 32KB | native |
| 27LC64 | 8KB | 32KB | native |
| 28C64 | 8KB | 32KB | native |
| 23128 | 16KB | 32KB | native |
| 27128 | 16KB | 32KB | native |
| 27C128 | 16KB | 32KB | native |
| 27LC128 | 16KB | 32KB | native |
| 23256 | 32KB | 64KB | native |
| 27256 | 32KB | 64KB | native |
| 27C256 | 32KB | 64KB | native |
| 27LC256 | 32KB | 64KB | native |
| 27SF256 | 32KB | 64KB | native |
| 28C256 | 32KB | 32KB | native |
| 23QL384 | 48KB | 128KB | native |
| 23512 | 64KB | 64KB | native |
| 23QL512 | 64KB | 128KB | native |
| 27512 | 64KB | 64KB | native |
| 27C512 | 64KB | 64KB | native |
| 27LC512 | 64KB | 64KB | native |
| 27SF512 | 64KB | 64KB | native |
| 231024 | 128KB | 256KB | native |
| 23C1000 | 128KB | 256KB | native |
| 23C1000A | 128KB | 256KB | native |
| MX23C1000 | 128KB | 256KB | native |
| TC531000 | 128KB | 256KB | native |

*24-pin chips (with overhang)*

| Chip | ROM size | Image size | Fit |
|:---|---:|---:|:---|
| 2704 | 512B | 4KB | overhang |
| 2708 | 1KB | 16KB | overhang |
| 2716 | 2KB | 32KB | overhang |
| 28C16 | 2KB | 32KB | overhang |
| 2732 | 4KB | 32KB | overhang |
| 27C32 | 4KB | 32KB | overhang |
| 2364 | 8KB | 128KB | overhang |
| 4764 | 8KB | 128KB | overhang |
| MCM68364 | 8KB | 128KB | overhang |
| MCM68764 | 8KB | 128KB | overhang |
| MCM68A364 | 8KB | 128KB | overhang |
| MCM68A764 | 8KB | 128KB | overhang |
| MK36000 | 8KB | 128KB | overhang |
| MM52164 | 8KB | 128KB | overhang |

*32-pin chips (with fly-leads)*

| Chip | ROM size | Image size | Fit |
|:---|---:|---:|:---|
| 28C512 | 64KB | 64KB | larger socket (no fly-leads) |

## One ROM Fire 28 (rev B) — fire-28-b

*28-pin chips (native)*

| Chip | ROM size | Image size | Fit |
|:---|---:|---:|:---|
| 2764 | 8KB | 32KB | native |
| 27C64 | 8KB | 32KB | native |
| 27LC64 | 8KB | 32KB | native |
| 28C64 | 8KB | 32KB | native |
| 23128 | 16KB | 32KB | native |
| 27128 | 16KB | 32KB | native |
| 27C128 | 16KB | 32KB | native |
| 27LC128 | 16KB | 32KB | native |
| 23256 | 32KB | 64KB | native |
| 27256 | 32KB | 64KB | native |
| 27C256 | 32KB | 64KB | native |
| 27LC256 | 32KB | 64KB | native |
| 27SF256 | 32KB | 64KB | native |
| 28C256 | 32KB | 32KB | native |
| 23QL384 | 48KB | 128KB | native |
| 23512 | 64KB | 64KB | native |
| 23QL512 | 64KB | 128KB | native |
| 27512 | 64KB | 64KB | native |
| 27C512 | 64KB | 64KB | native |
| 27LC512 | 64KB | 64KB | native |
| 27SF512 | 64KB | 64KB | native |
| 231024 | 128KB | 256KB | native |
| 23C1000 | 128KB | 256KB | native |
| 23C1000A | 128KB | 256KB | native |
| MX23C1000 | 128KB | 256KB | native |
| TC531000 | 128KB | 256KB | native |

*24-pin chips (with overhang)*

| Chip | ROM size | Image size | Fit |
|:---|---:|---:|:---|
| 2704 | 512B | 4KB | overhang |
| 2708 | 1KB | 16KB | overhang |
| 2716 | 2KB | 32KB | overhang |
| 28C16 | 2KB | 32KB | overhang |
| 2732 | 4KB | 32KB | overhang |
| 27C32 | 4KB | 32KB | overhang |
| 2364 | 8KB | 128KB | overhang |
| 4764 | 8KB | 128KB | overhang |
| MCM68364 | 8KB | 128KB | overhang |
| MCM68764 | 8KB | 128KB | overhang |
| MCM68A364 | 8KB | 128KB | overhang |
| MCM68A764 | 8KB | 128KB | overhang |
| MK36000 | 8KB | 128KB | overhang |
| MM52164 | 8KB | 128KB | overhang |

*32-pin chips (with fly-leads)*

| Chip | ROM size | Image size | Fit |
|:---|---:|---:|:---|
| 28C512 | 64KB | 64KB | larger socket (no fly-leads) |

## One ROM Fire 28 (rev C) — fire-28-c

*28-pin chips (native)*

| Chip | ROM size | Image size | Fit |
|:---|---:|---:|:---|
| 2764 | 8KB | 32KB | native |
| 27C64 | 8KB | 32KB | native |
| 27LC64 | 8KB | 32KB | native |
| 28C64 | 8KB | 32KB | native |
| 23128 | 16KB | 32KB | native |
| 27128 | 16KB | 32KB | native |
| 27C128 | 16KB | 32KB | native |
| 27LC128 | 16KB | 32KB | native |
| 23256 | 32KB | 64KB | native |
| 27256 | 32KB | 64KB | native |
| 27C256 | 32KB | 64KB | native |
| 27LC256 | 32KB | 64KB | native |
| 27SF256 | 32KB | 64KB | native |
| 28C256 | 32KB | 32KB | native |
| 23QL384 | 48KB | 256KB | native |
| 23512 | 64KB | 64KB | native |
| 23QL512 | 64KB | 256KB | native |
| 27512 | 64KB | 64KB | native |
| 27C512 | 64KB | 64KB | native |
| 27LC512 | 64KB | 64KB | native |
| 27SF512 | 64KB | 64KB | native |
| 231024 | 128KB | 128KB | native |
| 23C1000 | 128KB | 128KB | native |
| 23C1000A | 128KB | 128KB | native |
| MX23C1000 | 128KB | 128KB | native |
| TC531000 | 128KB | 128KB | native |

*24-pin chips (with overhang)*

| Chip | ROM size | Image size | Fit |
|:---|---:|---:|:---|
| 2704 | 512B | 4KB | overhang |
| HM7641 | 512B | 4KB | overhang |
| 2708 | 1KB | 8KB | overhang |
| 2716 | 2KB | 32KB | overhang |
| 28C16 | 2KB | 32KB | overhang |
| 2732 | 4KB | 32KB | overhang |
| 27C32 | 4KB | 32KB | overhang |
| 2364 | 8KB | 256KB | overhang |
| 4764 | 8KB | 256KB | overhang |
| MCM68364 | 8KB | 256KB | overhang |
| MCM68764 | 8KB | 256KB | overhang |
| MCM68A364 | 8KB | 256KB | overhang |
| MCM68A764 | 8KB | 256KB | overhang |
| MK36000 | 8KB | 256KB | overhang |
| MM52164 | 8KB | 256KB | overhang |

*32-pin chips (with fly-leads)*

| Chip | ROM size | Image size | Fit |
|:---|---:|---:|:---|
| 28C512 | 64KB | 64KB | larger socket (no fly-leads) |
| 23C1010 | 128KB | 128KB | fly-lead to X1 |
| 27C010 | 128KB | 128KB | fly-lead to X1 |
| 27C1000A | 128KB | 128KB | fly-lead to X1 |
| 27C1001 | 128KB | 128KB | fly-lead to X1 |
| 29F010 | 128KB | 128KB | fly-lead to X1 |
| 39SF010 | 128KB | 128KB | fly-lead to X1 |
| SST39SF010 | 128KB | 128KB | fly-lead to X1 |

## One ROM Fire 28 (rev D) — fire-28-d

*28-pin chips (native)*

| Chip | ROM size | Image size | Fit |
|:---|---:|---:|:---|
| 2764 | 8KB | 32KB | native |
| 27C64 | 8KB | 32KB | native |
| 27LC64 | 8KB | 32KB | native |
| 28C64 | 8KB | 32KB | native |
| 23128 | 16KB | 32KB | native |
| 27128 | 16KB | 32KB | native |
| 27C128 | 16KB | 32KB | native |
| 27LC128 | 16KB | 32KB | native |
| 23256 | 32KB | 64KB | native |
| 27256 | 32KB | 64KB | native |
| 27C256 | 32KB | 64KB | native |
| 27LC256 | 32KB | 64KB | native |
| 27SF256 | 32KB | 64KB | native |
| 28C256 | 32KB | 32KB | native |
| 23QL384 | 48KB | 256KB | native |
| 23512 | 64KB | 64KB | native |
| 23QL512 | 64KB | 256KB | native |
| 27512 | 64KB | 64KB | native |
| 27C512 | 64KB | 64KB | native |
| 27LC512 | 64KB | 64KB | native |
| 27SF512 | 64KB | 64KB | native |
| 231024 | 128KB | 128KB | native |
| 23C1000 | 128KB | 128KB | native |
| 23C1000A | 128KB | 128KB | native |
| MX23C1000 | 128KB | 128KB | native |
| TC531000 | 128KB | 128KB | native |

*24-pin chips (with overhang)*

| Chip | ROM size | Image size | Fit |
|:---|---:|---:|:---|
| 2704 | 512B | 4KB | overhang |
| HM7641 | 512B | 4KB | overhang |
| 2708 | 1KB | 8KB | overhang |
| 2716 | 2KB | 32KB | overhang |
| 28C16 | 2KB | 32KB | overhang |
| 2732 | 4KB | 32KB | overhang |
| 27C32 | 4KB | 32KB | overhang |
| 2364 | 8KB | 256KB | overhang |
| 4764 | 8KB | 256KB | overhang |
| MCM68364 | 8KB | 256KB | overhang |
| MCM68764 | 8KB | 256KB | overhang |
| MCM68A364 | 8KB | 256KB | overhang |
| MCM68A764 | 8KB | 256KB | overhang |
| MK36000 | 8KB | 256KB | overhang |
| MM52164 | 8KB | 256KB | overhang |

*32-pin chips (with fly-leads)*

| Chip | ROM size | Image size | Fit |
|:---|---:|---:|:---|
| 28C512 | 64KB | 64KB | larger socket (no fly-leads) |
| 23C1010 | 128KB | 128KB | fly-lead to X1 |
| 27C010 | 128KB | 128KB | fly-lead to X1 |
| 27C1000A | 128KB | 128KB | fly-lead to X1 |
| 27C1001 | 128KB | 128KB | fly-lead to X1 |
| 29F010 | 128KB | 128KB | fly-lead to X1 |
| 39SF010 | 128KB | 128KB | fly-lead to X1 |
| SST39SF010 | 128KB | 128KB | fly-lead to X1 |

## One ROM Fire 32 (rev A) — fire-32-a

*32-pin chips (native)*

| Chip | ROM size | Image size | Fit |
|:---|---:|---:|:---|
| 28C512 | 64KB | 256KB | native |
| 23C1010 | 128KB | 512KB | native |
| 27C010 | 128KB | 512KB | native |
| 27C100 | 128KB | 512KB | native |
| 27C1000 | 128KB | 512KB | native |
| 27C1000A | 128KB | 512KB | native |
| 27C1001 | 128KB | 512KB | native |
| 27C301 | 128KB | 512KB | native |
| 29F010 | 128KB | 512KB | native |
| 39SF010 | 128KB | 512KB | native |
| SST39SF010 | 128KB | 512KB | native |
| 27C020 | 256KB | 512KB | native |
| 27C2001 | 256KB | 512KB | native |
| 29F020 | 256KB | 512KB | native |
| 39SF020 | 256KB | 512KB | native |
| SST39SF020 | 256KB | 512KB | native |
| 27C040 | 512KB | 512KB | native |
| 27C4001 | 512KB | 512KB | native |
| 27C080 | 1MB | 512KB | native |
| 27C801 | 1MB | 512KB | native |

*28-pin chips (with overhang)*

| Chip | ROM size | Image size | Fit |
|:---|---:|---:|:---|
| 2764 | 8KB | 256KB | overhang |
| 27C64 | 8KB | 256KB | overhang |
| 27LC64 | 8KB | 256KB | overhang |
| 28C64 | 8KB | 256KB | overhang |
| 27128 | 16KB | 256KB | overhang |
| 27C128 | 16KB | 256KB | overhang |
| 27LC128 | 16KB | 256KB | overhang |
| 23256 | 32KB | 256KB | overhang |
| 27256 | 32KB | 256KB | overhang |
| 27C256 | 32KB | 256KB | overhang |
| 27LC256 | 32KB | 256KB | overhang |
| 27SF256 | 32KB | 256KB | overhang |
| 28C256 | 32KB | 256KB | overhang |
| 23512 | 64KB | 256KB | overhang |
| 27512 | 64KB | 256KB | overhang |
| 27C512 | 64KB | 256KB | overhang |
| 27LC512 | 64KB | 256KB | overhang |
| 27SF512 | 64KB | 256KB | overhang |
| 231024 | 128KB | 512KB | overhang |
| 23C1000 | 128KB | 512KB | overhang |
| 23C1000A | 128KB | 512KB | overhang |
| MX23C1000 | 128KB | 512KB | overhang |
| TC531000 | 128KB | 512KB | overhang |

*24-pin chips (with overhang)*

| Chip | ROM size | Image size | Fit |
|:---|---:|---:|:---|
| 2704 | 512B | 32KB | overhang |
| HM7641 | 512B | 32KB | overhang |
| 2708 | 1KB | 64KB | overhang |
| 2716 | 2KB | 256KB | overhang |
| 28C16 | 2KB | 256KB | overhang |
| 2732 | 4KB | 256KB | overhang |
| 27C32 | 4KB | 256KB | overhang |

## One ROM Fire 32 (rev B) — fire-32-b

*32-pin chips (native)*

| Chip | ROM size | Image size | Fit |
|:---|---:|---:|:---|
| 28C512 | 64KB | 64KB | native |
| 23C1001 | 128KB | 128KB | native |
| 23C1010 | 128KB | 128KB | native |
| 27C010 | 128KB | 128KB | native |
| 27C100 | 128KB | 256KB | native |
| 27C1000 | 128KB | 256KB | native |
| 27C1000A | 128KB | 128KB | native |
| 27C1001 | 128KB | 128KB | native |
| 27C301 | 128KB | 256KB | native |
| 29F010 | 128KB | 128KB | native |
| 39SF010 | 128KB | 128KB | native |
| D23C1001 | 128KB | 128KB | native |
| SST39SF010 | 128KB | 128KB | native |
| 27C020 | 256KB | 256KB | native |
| 27C2001 | 256KB | 256KB | native |
| 29F020 | 256KB | 256KB | native |
| 39SF020 | 256KB | 256KB | native |
| SST39SF020 | 256KB | 256KB | native |
| 27C040 | 512KB | 512KB | native |
| 27C4001 | 512KB | 512KB | native |
| 29F040 | 512KB | 512KB | native |
| 39SF040 | 512KB | 512KB | native |
| SST39SF040 | 512KB | 512KB | native |
| 27C080 | 1MB | 512KB | native |
| 27C801 | 1MB | 512KB | native |

*28-pin chips (with overhang)*

| Chip | ROM size | Image size | Fit |
|:---|---:|---:|:---|
| 2764 | 8KB | 32KB | overhang |
| 27C64 | 8KB | 32KB | overhang |
| 27LC64 | 8KB | 32KB | overhang |
| 28C64 | 8KB | 32KB | overhang |
| 27128 | 16KB | 32KB | overhang |
| 27C128 | 16KB | 32KB | overhang |
| 27LC128 | 16KB | 32KB | overhang |
| 23256 | 32KB | 32KB | overhang |
| 27256 | 32KB | 32KB | overhang |
| 27C256 | 32KB | 32KB | overhang |
| 27LC256 | 32KB | 32KB | overhang |
| 27SF256 | 32KB | 32KB | overhang |
| 28C256 | 32KB | 64KB | overhang |
| 23512 | 64KB | 64KB | overhang |
| 27512 | 64KB | 64KB | overhang |
| 27C512 | 64KB | 64KB | overhang |
| 27LC512 | 64KB | 64KB | overhang |
| 27SF512 | 64KB | 64KB | overhang |
| 231024 | 128KB | 256KB | overhang |
| 23C1000 | 128KB | 256KB | overhang |
| 23C1000A | 128KB | 256KB | overhang |
| MX23C1000 | 128KB | 256KB | overhang |
| TC531000 | 128KB | 256KB | overhang |

*24-pin chips (with overhang)*

| Chip | ROM size | Image size | Fit |
|:---|---:|---:|:---|
| 2704 | 512B | 4KB | overhang |
| 2708 | 1KB | 8KB | overhang |
| 2716 | 2KB | 32KB | overhang |
| 28C16 | 2KB | 32KB | overhang |
| 2732 | 4KB | 32KB | overhang |
| 27C32 | 4KB | 32KB | overhang |

## One ROM Fire 40 (rev A) — fire-40-a

| Chip | ROM size | Image size | Fit |
|:---|---:|---:|:---|
| 27C200 | 256KB | 512KB | native |
| HN62402 | 256KB | 512KB | native |
| 23C4100 | 512KB | 512KB | native |
| 27C400 | 512KB | 512KB | native |
| 27C4100 | 512KB | 512KB | native |
| AT27C400 | 512KB | 512KB | native |
| HN62404 | 512KB | 512KB | native |
| HN62424 | 512KB | 512KB | native |
| M27C400 | 512KB | 512KB | native |
| MB834200 | 512KB | 512KB | native |
| MX23C4100 | 512KB | 512KB | native |
| MX27C4100 | 512KB | 512KB | native |
| TCS534200 | 512KB | 512KB | native |

## One ROM Fire 40 (rev B) — fire-40-b

| Chip | ROM size | Image size | Fit |
|:---|---:|---:|:---|
| 27C200 | 256KB | 256KB | native |
| HN62402 | 256KB | 256KB | native |
| 23C4100 | 512KB | 512KB | native |
| 27C400 | 512KB | 512KB | native |
| 27C4100 | 512KB | 512KB | native |
| AT27C400 | 512KB | 512KB | native |
| HN62404 | 512KB | 512KB | native |
| HN62424 | 512KB | 512KB | native |
| M27C400 | 512KB | 512KB | native |
| MB834200 | 512KB | 512KB | native |
| MX23C4100 | 512KB | 512KB | native |
| MX27C4100 | 512KB | 512KB | native |
| TCS534200 | 512KB | 512KB | native |

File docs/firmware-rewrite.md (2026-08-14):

# v0.7.0 Firmware Rewrite Plans

This is a temporary document intended to capture plans and open issues for rewriting the core firmware, likely released as v0.7.0.

## Overview

The catalyst for the rewrite is to collapse the current complexity around how different image types (with incompatible pin-outs) are served.  This complexity is currently spread between both the firmware and the pre-processor (as well as the two different regression test mechanisms).

The rewrite is expected to capture that complexity in the pre-processor only, with the firmware having a small number of different PIO serving algorithms,where there are multiple algorithms for each of CS handling, byte serving, and address reading.  One of each of these is selected by the pre-processor for a particular ROM, via the metadata, based on the ROM type.  Each serving algorithm has its own set of arguments that it takes (like base address pin and number of address pins), which the pre-processor populates.

The ROM type itself is not be "known" to the firmware, although it is stored in the metadata as a human readable string (based on the actual alias used to program One ROM), so that the firmware can be usefully queried.

Metadata for a particular ROM type is only included once, even if there are multiple ROM images of that type on the firmware (i.e. the metadata for each points to a single instance) to save flash space, as metadata needs to continue to fit into 16KB.

Ideally, the complexity - that is the different algorithms and their parameters required for each ROM type on each board - would be inferred from the chip type and board (JSON) metadata.  This is possible to some extend, much as the existing pre-processor and firmware infers behaviour like contiguous or non-contiguous CS pins.  However, it isn't entirely possible (hence handle_snowflake_chip_types() in the pre-processor), so there is expected to be a match, switch or table driven approach taken, using the information documented below in [ROM Configuration](#rom-configuration).

## Build Variants

It is expected to collapse down to a single firmware binary for all hardware revisions.  This can be achieved by building for the RP2350B (assuming the larger pin counts).  The only issue this gives is that ADC pins are different GPIOs, but that is not an issue as the firmware doesn't use ADC.  Any plugin that wishes to use ADC can query the RP2350A/B variant using the standard mechanism.

## Deprecated One ROM Hardware Revisions

Ice support and non-PIO Fire support are expected to be dropped in this rewrite.  Ice continues to be supported via the 0.6.* firmware but isn't expected to be enhanced in future.

The only requirement for non-PIO Fire support is for boards fire-24-a/b when serving multi-ROM sets, as PIO + multi-ROM set serving are incompatible on these revisions.  This continues to be supported by 0.6.* firmware, but won't be enhanced in future.

## Language Choice

Consideration has been given to moving from C to Rust for the core firmware.  However, C was chosen for the rewrite for a number of reasons:
- Make the firmware more approachable by a wider group of people.
- Avoid needing to rewrite the extensive plugin API and supporting framework in Rust, as well as requiring laying the existing C plugin API on top of Rust (as C is much more likely to be used for plugins).

Rust remains the choice for the pre-processor.  It continues to be available as Rust crates and WASM libraries for integration into different tools. 

## Testing

One ROM's automated testing consists of:
- `make test` - checks with independent code that the ROM image as included in firmware is mangled as expected
- `make test-pio` - emulates the One ROM firmware and included metadata + ROM images, to ensure every byte is served as expected, and data lines are not driven when they shouldn't be
- `rust/lab-new` - runs on One ROM hardware and reads attached One ROMs (and real ROMs, EPROMs and EEPROMs) to ensure they read correctly 

As part of the firmware rewrite all these tests are retained and used to validate the new firmware, for all supported ROM types, including CS configurations.

## Open issues

- RBCP currently exposes the ROM type to the host.  If the firmware doesn't know the ROM type, we either need to remove this from RBCP, or, perhaps more usefully, include an RBCP ROM type identifier in the metadata, which the firmware just dumbly serves via RBCP.

- It is expected that we'll collapse down to a single metadata/image generator with this firmware, removing the support in `sdrr-gen` to generate a firmware with it all included in one shot.  This means that
  - We have to find a way to include the metadata/ROM images in the `make test-pio` type testing.
  - We still need a way to generate the ROM image on its own and perform the `make test` type testing, to ensure the ROM image is mangled as appropriate.
  It is currently unknown how these will be achieved.

## Detailed To-Dos

- Add 23C1001 support to firmware and test it (fire-32-b only).
- fire-28-c Add multi-ROM sets and dynamic bank switching.
- Add method to get RP2350A/B from config::hw::Board, and use in generator.rs instead of hard-coding.
- fire-28-c optimise image sizes
- fire-32-b optimise image sizes
- In general we are missing any ability in the core firmware (and also elsewhere) to support specific ROM types only on certain revisions of different pin boards.  This likely needs somworking through.
- Make 27C301 use less flash on fire-32-b (currently using 512KB, 256KB should be possible)
- config/hw generator is subtracting 8 from 28 pin board address lines, but should be 10 for fire-28-a - should be avoiding the X pins as well, better than just hardcoding the fire-28-c type
- Add concept of don't care for CS line (23C1001, HN62402, HN62302)
- Change HN62402 to be 16 bit only and HN62302 to be 8 bit only.

## Algorithms

All pin numbers are given with respect to the GPIO_BASE value provided.  GPIO_BASE can take either 0 or 16.  16 is used to access GPIOS 32-47, and prevents 0-15 from being accesssed.  The CS and Data algorithms MUST share the same GPIO_BASE value, as the CS (and Data) algorithms both need to access the data pins.  In theory it is possible to image the data pins high and the CS pins low, or vice versa, requiring a differet approach, but this isn't required by current or planned hardware.

GPIO_BASE is always param 1 for all algorithms.

### Chip Select Handling

| ID | Name | Description | Param 1 | Param 2 | Param 3 | Param 4 | Param 5 | Param 6 | Param 7 | Param 8 | Param 9 | Param 10 |
|----|---|---|---|---|---|---|---|---|---|---|---|---|
| CS0 | CS Standard | The ROM image is served using a contiguous set of CS pins. | GPIO_BASE | Base CS pin | Num CS pins | Which CS pins to hardware invert | Base data pin | Number of data pins (8/16) | Serve when all CS pins are low (0) or when one or more is high (1).  The latter is used for multi-ROM sets | Cycle delay after detecting CS active before setting data lines to outputs | Cycle delay after detecting CS inactive before setting data lines to inputs | /BYTE pin number or 0xFF is not used, indexed from GPIO_BASE |
| CS1 | CS non-contig single gap | Each ROM image is served using a set of CS pins, all of which must be low for the data pins to be set to outputs, but the CS pins can have up to a 1 pin total (i.e. between only one pair of CS lines). | GPIO_BASE | Base CS pin | Num CS pins including gap | Index of CS pin to ignore (1 would be second pin) | Which CS pins to hardware invert | Base data pin | Number of data pins (8/16) | Cycle delay after detecting CS active before setting data lines to outputs | Cycle delay after detecting CS inactive before setting data lines to inputs | n/a |
| CS2 | CS Enable Address Qualified | The ROM image is served when a primary enable pin is asserted AND a set of address qualifier pins do not match the inactive pattern. Used where a single global enable pin (such as /OE or /CE) gates output, with address lines providing bank selection. | GPIO_BASE | Enable pin indexed from GPIO_BASE | Hardware invert enable pin (0=no, 1=yes) | Base address qualifier pin indexed from GPIO_BASE | Num address qualifier pins including any gap pins | Inactive pattern for address qualifier pins (Y preload value) | Base data pin | Number of data pins (8/16) | n/a | n/a |

It is possible to conceive a more general non-contiguous CS algorithm, with any number of pins and gaps, and the PIO would shift through the CS pins testig them one by one, or in contiguous groups.  This would be slow, and isn't currently required.

### Address Reading

| ID | Name | Description | Param 1 | Param 2 | Param 3 | Param 4 | Param 5 | Param 6 |
|----|---|---|---|---|---|---|---|---|
| ADDR0 | Address Standard | Reads a complete block of address pins, postpends the value to a RAM lookup prefix and pushes to a DMA chain.  Number of address pins and RAM prefix are inferred from ROM image size. | GPIO_BASE | Number of cycles to wait in between address reads | Base address pin | Total number of address pins to read from | Number of ROM RAM table bits to include | List of pins (indexed from base) to always read 0/1, and which value to read |
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

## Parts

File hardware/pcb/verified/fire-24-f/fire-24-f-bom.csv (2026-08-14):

Reference | Qty | Value | DNP | Exclude from BOM | Exclude from Board | Footprint | Datasheet | LCSC
C1,C2,C7,C13,C15,C16,C17 | 7 | 4.7uF |  |  |  | Capacitor_SMD:C_0402_1005Metric | ~ | C23733
C3,C4,C5,C6,C8,C9,C10,C11,C12,C14 | 10 | 0.1uF |  |  |  | Capacitor_SMD:C_0201_0603Metric | ~ | C668346
C18,C19 | 2 | 15pF |  |  |  | Capacitor_SMD:C_0201_0603Metric | ~ | C85891
D1 | 1 | LED_Small |  |  |  | LED_SMD:LED_0402_1005Metric | ~ | C25503345
D2,D3 | 2 | 1N5819WS |  |  |  | Diode_SMD:D_SOD-323 |  | C191023
D4 | 1 | XL-1010RGBC-WS2812B |  |  |  | piers retro:XL-1010RGBC-2812B | https://jlcpcb.com/partdetail/XINGLIGHT-XL_1010RGBC2812B/C5349953 | C5349953
J4 | 1 | USB_C_Receptacle_USB2.0_16P |  |  |  | piers retro:USB_C_connector_c2765186 | https://www.usb.org/sites/default/files/documents/usb_type-c.zip | C2765186
L1 | 1 | 3.3u |  |  |  | RP2350_60QFN_minimal:L_pol_2016 | ~ | C42411119
R1,R3,R7,R8 | 4 | 10K |  |  |  | Resistor_SMD:R_0201_0603Metric | ~ | C473048
R2,R5,R6,R11 | 4 | 1K |  |  |  | Resistor_SMD:R_0201_0603Metric | ~ | C270365
R4 | 1 | 33R |  |  |  | Resistor_SMD:R_0402_1005Metric | ~ | C25105
R9,R10 | 2 | 5K1 |  |  |  | Resistor_SMD:R_0201_0603Metric | ~ | C270344
U1 | 1 | RP2350_60QFN |  |  |  | RP2350_60QFN_minimal:RP2350-QFN-60-1EP_7x7_P0.4mm_EP3.4x3.4mm_ThermalVias |  | C41378174
U3 | 1 | AP2112K-3.3 |  |  |  | Package_TO_SOT_SMD:SOT-23-5 |  | C51118
U4 | 1 | USBLC6-2P6 |  |  |  | Package_TO_SOT_SMD:SOT-666 | https://www.st.com/resource/en/datasheet/usblc6-2.pdf | C15999
Y1 | 1 | Crystal_GND24 |  |  |  | Crystal:Crystal_SMD_Abracon_ABM8G-4Pin_3.2x2.5mm | ~ | C20625731

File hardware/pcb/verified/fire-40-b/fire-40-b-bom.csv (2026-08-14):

Reference | Qty | Value | DNP | Exclude from BOM | Exclude from Board | Footprint | Datasheet | LCSC
C1,C2,C3,C7,C13,C15,C23,C16,C17 | 9 | 4.7uF |  |  |  | Capacitor_SMD:C_0402_1005Metric | ~ | C23733
C4,C5,C6,C8,C9,C10,C11,C12,C14,C20,C21,C22 | 12 | 0.1uF |  |  |  | Capacitor_SMD:C_0402_1005Metric | ~ | C1525
C18,C19 | 2 | 15pF |  |  |  | Capacitor_SMD:C_0402_1005Metric | ~ | C1548
D1 | 1 | LED_Small |  |  |  | LED_SMD:LED_0603_1608Metric | ~ | C2286
D2,D3 | 2 | 1N5819WS |  |  |  | Diode_SMD:D_SOD-323 |  | C191023
D4 | 1 | XL-1010RGBC-WS2812B |  |  |  | piers retro:XL-1010RGBC-2812B | https://jlcpcb.com/partdetail/XINGLIGHT-XL_1010RGBC2812B/C5349953 | C5349953
J1 | 1 | USB_C_Receptacle_USB2.0_16P |  |  |  | piers retro footprints:USB_C_connector_c2765186 | https://www.usb.org/sites/default/files/documents/usb_type-c.zip | C2765186
L1 | 1 | 3.3u |  |  |  | RP2350_60QFN_minimal:L_pol_2016 | ~ | C42411119
R1,R3,R7,R8 | 4 | 10K |  |  |  | Resistor_SMD:R_0402_1005Metric | ~ | C25744
R2,R5,R6,R13 | 4 | 1K |  |  |  | Resistor_SMD:R_0402_1005Metric | ~ | C11702
R4 | 1 | 33R |  |  |  | Resistor_SMD:R_0402_1005Metric | ~ | C25105
R9,R10 | 2 | 5K1 |  |  |  | Resistor_SMD:R_0402_1005Metric | ~ | C25905
R12 | 1 | 0R |  |  |  | Resistor_SMD:R_0402_1005Metric | ~ | C17168
U1 | 1 | RP2354B |  |  |  | RP2350B:RP2350-QFN-80-1EP_10x10_P0.4mm_EP3.4x3.4mm_ThermalVias |  | C39843328
U3 | 1 | AP2112K-3.3 |  |  |  | Package_TO_SOT_SMD:SOT-23-5 |  | C51118
U4 | 1 | USBLC6-2P6 |  |  |  | Package_TO_SOT_SMD:SOT-666 | https://www.st.com/resource/en/datasheet/usblc6-2.pdf | C15999
Y1 | 1 | Crystal_GND24 |  |  |  | Crystal:Crystal_SMD_Abracon_ABM8G-4Pin_3.2x2.5mm | ~ | C20625731

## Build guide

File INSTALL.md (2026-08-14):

# INSTALL

One ROM requires a fairly involved toolchain to build, due to the extent of the project (embedded firmware, extensive RUST tooling, desktop application, webassembly, etc).

You are _strongly_ recommended to use the [Docker container](ci/docker/README.md#building-one-rom) to build the One ROM firmware, as this contains a pre-configured build environment that works across multiple host platforms.

If you'd like to build the toolchain and dependencies locally, read on.

This document covers installing the toolchain and dependencies on linux (primarily focusing on an x86_64 Debian-based distribution, although notes are also provided for an ARM64 based host).

Other hosts (Mac, Windows) are possible, and it is recommended to use macOS for building One ROM Studio for Mac, and Windows for building Windows installers.

However, we strongly recommend sticking to a *nix based host (Linux or macOS) for building the One ROM firmware itself, and instructions for settig up a full Windows build host are not included below.

0. Install pre-requisites

    ```bash
    sudo apt -y install git build-essential curl pkg-config
    ```

1. Clone the repository:

    ```bash
    git clone https://github.com/piersfinlayson/one-rom.git
    cd one-rom
    ```

2. Install the required ARM GNU toolchain.  You have options here.

    - Install it [from ARM's website](https://developer.arm.com/downloads/-/arm-gnu-toolchain-downloads) for AArch32 bare-metal target (arm-none-eabi).

        Recommended approach - download the toolchain from ARM's developer site (this is quite large, so may take a while) - this is for x86_64 linux hosts::

        ```bash
        wget https://developer.arm.com/-/media/Files/downloads/gnu/14.3.rel1/binrel/arm-gnu-toolchain-14.3.rel1-x86_64-arm-none-eabi.tar.xz
        tar -xvf arm-gnu-toolchain-14.3.rel1-x86_64-arm-none-eabi.tar.xz
        sudo mv arm-gnu-toolchain-14.3.rel1-x86_64-arm-none-eabi /opt/
        ```

        If you are on ARM64 linux, or a Mac (Intel or ARM), select the correct version from ARM's site.  Again update TOOLCHAIN.

    - Install it via your package manager, e.g., on Debian/Ubuntu:

        ```bash
        sudo apt -y install gcc-arm-none-eabi
        ```

    Now you will need to update the `TOOLCHAIN` environment variable in your shell or variable in the [Makefile](firmware/Makefile) to point to the correct compiler binary directory.  It should probably `/usr/bin` or `/opt/arm-gnu-toolchain-14.3.rel1-darwin-arm64-arm-none-eabi/bin` or similar.

    If on an ARM64 host you will also need x86_64-linux-gnu cross tools:

    ```bash
    sudo apt -y install gcc-x86-64-linux-gnu
    ```

3. Install the following packages required for building and testing.  `vice` is optional.  (`vice` is used to build some Commodore demo programs.):

    ```bash
    sudo apt -y install jq libcurl4-openssl-dev libzip-dev libjson-c-dev libudev-dev vice
    ```

    If you are using a different package manager, the package name may vary slightly, e.g., `libcurl-devel` on Fedora.

    On macOS you would be using [Homebrew](https://brew.sh/).

4. Install [Rust](https://www.rust-lang.org/tools/install) - this will take a while:

    ```bash
    curl --proto '=https' --tlsv1.2 -sSf https://sh.rustup.rs | sh
    source $HOME/.cargo/env
    cargo install cross
    cargo install wasm-pack   # Only required to build one-rom-wasm
    cargo install cargo-dist  # Only required to build One ROM Studio installers
    ```

    The One ROM hardware tester (`onerom-lab`) runs on the RP2350 and is built
    with the nightly toolchain (pinned by its `rust-toolchain.toml`).  You only
    need this if you are building the tester:

    ```bash
    rustup toolchain install nightly --component clippy,rustfmt --target thumbv8m.main-none-eabihf
    ```

    If planning to build One ROM Studio for all possible targets (you likely only want to build a subset!) you will also need to install additional Rust targets and the mingw-w64 toolchain for Windows targets.  If you just want to build the One ROM firmware you do not need to do this step.
    
    ```bash
    rustup target install \
        x86_64-unknown-linux-gnu \
        aarch64-unknown-linux-gnu \
        x86_64-pc-windows-gnu \
        aarch64-pc-windows-gnullvm \
        x86_64-pc-windows-msvc \
        aarch64-pc-windows-msvc \
        x86_64-apple-darwin \
        aarch64-apple-darwin
    sudo apt -y install mingw-w64
    ```

5. Install [probe-rs](https://probe.rs/) for flashing the firmware to One ROM using an SWD programmer.  This is optional if you want to just build the firmware and use another tool to flash it.

    ```bash
    curl --proto '=https' --tlsv1.2 -LsSf https://github.com/probe-rs/probe-rs/releases/latest/download/probe-rs-tools-installer.sh | sh
    probe-rs complete install
    ```

6. Connect up One ROM to your [programmer](README.md#programmer).

At this point you can follow the instructions below to build and flash the firmware.

## Building the Firmware

To build the base firmware, run `make` from the repo root.  Add `DEBUG_LOGGING=1` for debug logging.

To build a firmware image to flash to a One ROM, you use the CLI tool, which you can build from `rust/cli` or download from [One ROM CLI](https://onerom.org/cli).  For example:

```bash
onerom firmware build --base-firmware firmware/build/onerom-rp235x.bin --config onerom-config/vic20-pal.json /tmp/firmware.bin
```

## Programming the Firmware

### USB

USB is the simplest way to program One ROM if your hardware revision supports.

After building the firmware as above, use the binary from `firmware/build/onerom-rp235x.bin` and one of the following tools to update the firmware of your device.  You have two official One ROM options:
- [One ROM CLI](https://onerom.org/cli)
- [One ROM Studio](https://onerom.org/studio)
- [One ROM Web](https://onerom.org/web)

If all cases, you need to select the option to upload a local firmware binary, and then program it.

You also have board specific, third-party, options:

#### Fire Boards

- [pico⚡flash](https://picoflash.org) - A web based RP2040/RP2350 flash by One ROM's author. 
- [picotool](https://github.com/raspberrypi/picotool) - A command line tool from Raspberry Pi for programming Raspberry Pi RP2040/RP2350-based boards.

As well as `firmware/build/onerom-rp235x.bin`, if you have [picotool](https://github.com/raspberrypi/picotool) installed and in your path, a UF2 file is created as part of the build for Fire boards at `firmware/build/onerom-rp235x.uf2`.

For a factory fresh Fire board, you can copy this UF2 to the RP2350 filesystem that mounts when you plug in the Fire board to program it.

Note that the RP2350 filesystem is not automatically mounted when plugged into USB once you have One ROM firmware v0.6.0+ installed, but you can access it by pulling BOOT to GND on power up to enter this mode.

### SWD Programmer

Using SWD has an advantage over USB of being able to view debug logs from One ROM after re-programming.

However, you will need to find some way to power One ROM while programming, as, unlike USB, SWD does not provide power.  You can power One ROM by installing it in your retro system and powering that on, or by providing 5V and GND to the appropriate pins on One ROM directly.  ⚠️ If you are powering One ROM directly, **do not** install it in a retro system at the same time, as this may damage your One ROM, programmer, or retro system.

There are many tools that can be used to program One ROM via an SWD programmer.  We use [probe-rs](https://probe.rs/), which you may have installed already.

If you installed `probe-rs`, you can a command like this to build and flash the firmware using an SWD programmer in a single step - replace XXX with the appropriate build config for your hardware revision, MCU and ROM set configuration:

```bash
XXX make run
```

Note that as well as `firmware/build/onerom-rp235x.bin`, an ELF file is created at `firmware/build/onerom-rp235x.elf` which can be used with other SWD programming tools, as it contains build symbols.  This is particularly useful for attaching to One ROM with the programmer, after it has been programmed, to view logs. 

See [Pi-PICO-PROGRAMMER](/docs/PI-PICO-PROGRAMMER.md) for details of using a Raspberry Pi Pico as an inexpensive SWD programmer.  Many other SWD programmers are available, like the Raspberry Pi Debug Probe, generic DAPLink, ST-Link, etc. 

Occassionally your One ROM may lock up, particularly if you are experimenting with overclocking or other advanced configuration options, or debugging firmware changes.  If this is is the case, try rebooting your programmer, One ROM, or both, and try again.  If you still have problems, see [Recovering a Bricked Device](docs/old/GETTING-STARTED.md#recovering-a-bricked-device) for help.

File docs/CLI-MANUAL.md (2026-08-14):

# One ROM CLI Manual

`onerom` (`onerom.exe` on Windows) is the command-line tool for managing One ROM
ROM emulators: discovering connected devices, building and flashing firmware,
inspecting device state, and manipulating ROM image files.

This manual is in two parts. The **Guide** walks through installation and the
common workflows. The **Reference** documents every command, subcommand and
option.

> This manual documents the `onerom` CLI as of release v0.3.0. Board,
> chip and plugin lists shown in examples are illustrative — the set your build
> supports may differ. Run `onerom --version` to check your version, and
> `onerom board list` / `onerom chips` for the definitive lists your build knows
> about. Commands marked **(not yet supported)** are present in the CLI surface
> but not yet functional.

---

# Part 1 — Guide

## Installation

Download the CLI from **<https://onerom.org/cli>**. Builds are provided for:

- Windows — x86 64-bit and ARM 64-bit
- macOS
- Ubuntu/Debian — x86 64-bit, and ARM 64-bit (also for Raspberry Pi)

The Windows and macOS builds are digitally signed. A sha256 checksum is published
alongside every download so you can verify what you fetched.

**Windows / macOS** — unzip the archive and place the `onerom` (`onerom.exe`)
executable in a folder on your `PATH`.

**Linux** — install the `.deb` as usual, which places `onerom` on your `PATH`:

```
sudo dpkg -i onerom-cli-x.y.z-1_amd64.deb
```

(replace `x.y.z` with the version, e.g. `0.1.10`, and `amd64` with `arm64` for
the ARM/Pi build).

**Windows SmartScreen** — as a relatively new publisher, the first run may raise
a *"Windows protected your PC"* dialog. Click **More info**, confirm the
publisher reads *"Open Source Developer, Piers Finlayson"*, then **Run anyway**.

Verify it runs:

```
onerom --version
```

## How One ROM talks to the CLI

The CLI communicates with a One ROM over USB using picoboot (the Raspberry Pi
bootloader protocol, extended by
[picobootx](https://github.com/piersfinlayson/picobootx)). A One ROM is reachable in two
situations:

- **Running** — normal firmware is running and serving ROMs; its USB stack
  (provided by the system USB plugin) exposes the picobootx interface.
- **Stopped** — the device is in the RP2350 bootloader (BOOTSEL). A bare RP2350
  bootloader is also reachable here, which is how unprogrammed or bricked units
  are recovered.

Some commands work in either state; some require one specifically. Each
reference entry notes when a device connection is required, and the state model
is summarised under [Device states](#device-states).

## Identifying your device

With **exactly one** One ROM connected that the CLI recognises, you don't need
to identify it — commands find it automatically, and the board type is inferred
from the device.

With **multiple** devices connected, select one with `--serial` (`-s`). It
accepts `*` and `?` wildcards:

```
onerom --serial 'A1B2*' inspect info
```

`--serial` is **global**: it can appear at any level of the command line.

A device programmed with a serial override (`program --serial-override`) reports
and is matched by that overridden serial while **Running**. When **Stopped** its
USB stack comes from the RP2350 bootrom, so it falls back to reporting its chip
ID — match it by chip ID (or reboot it to running) in that state.

Discover what's attached:

```
onerom scan
onerom scan --slots        # also list each device's ROM slots
```

Two situations need extra flags:

- **Unrecognised / unprogrammed / bricked** units: add `--unrecognised` (`-u`)
  and supply `--board`, since the board type can't be inferred. The unit must
  still expose a valid picoboot USB interface.
- **Non-standard USB IDs**: add `--vid-pid <VID:PID>` (hex), repeatable. When
  supplied, only the given VID/PID pairs are matched.

`--board` (`-b`) can also be given on most commands to **override** the detected
board type.

## Common workflows

### Program a device from a config file

The primary workflow. Build firmware from a JSON config and flash it in one
step:

```
onerom program --config c64.json
```

`program` builds *and* flashes. To build a firmware binary **without** flashing,
use [`firmware build`](#firmware-build) instead. To build and also keep the
binary while flashing, add `--output`:

```
onerom program --config c64.json --out firmware.bin
```

### Program from `--slot` specifications

Instead of a config file, describe each ROM slot inline. Repeat `--slot` per
slot. The required chip-select lines depend on the chip type (e.g. a 2332 needs
`cs1` and `cs2`):

```
onerom program --board fire-24-e \
    --slot file=kernal.bin,type=2364,cs1=active-low \
    --slot file=basic.bin,type=2364,cs1=active-low
```

The full slot spec grammar is documented under [ROM slot
specification](#rom-slot-specification) — it covers CS polarity, size handling,
per-slot CPU frequency/voltage, the status LED and 16-bit forcing.

### Program with a plugin

Plugins masquerade as ROMs. At most one system plugin and one user plugin are
supported; a user plugin requires a system plugin. The system plugin lands in
slot 0, the user plugin in slot 1:

```
onerom program --board fire-24-e \
    --slot file=kernal.bin,type=2364,cs1=active-low \
    --plugin usb
```

`--plugin` may also be combined with `--config`. The plugins are inserted
ahead of the config's ROM slots (which shift up accordingly), so you can add a
plugin to a stock config without editing it:

```
onerom program --config c64.json --plugin usb
```

It is an error if the config already defines a plugin of its own — remove it
from the config, or drop `--plugin`.

Plugin spec forms are listed under [Plugin
specification](#plugin-specification).

### Build firmware without flashing

```
onerom firmware build --config c64.json --board fire-24-e --out firmware.bin
```

### Inspect a device

```
onerom inspect info      # serial, name, board, MCU, firmware version, hw revision
onerom inspect slots     # ROM slots, with the active one marked
```

### Read the live ROM image

Read what the device would serve for a given logical ROM address (device must be
running). The top-level `peek` is an alias for `inspect peek live`:

```
onerom peek live --address 0x100 --length 64
onerom peek live --address 0 --length 8192 --output rom-image.bin
```

### Patch a running image

`poke live` writes to the ROM image currently being served, at a logical ROM
offset. Changes are transient — lost on reboot. The top-level `poke` is an alias
for `control poke live`:

```
onerom poke live --address 0x100 --byte 0xEA
onerom poke live --address 0 --input patch.bin
```

For file patches you can write only the differing bytes, and preview first:

```
onerom poke live --input patch.bin --delta --dry-run
onerom poke live --input patch.bin --delta
```

### Identify a physical unit

Make the status LED beacon so you can spot which board is which:

```
onerom control led beacon
```

### Reset the host system after programming

If you have run a wire from a One ROM header pad to the reset line of the
machine One ROM is installed in, `control reset` pulses that pad low and then
releases it — resetting the host so it picks up the image you just flashed.
Name the pad, or the MCU GPIO behind it — `onerom inspect header` shows which
that is:

```
onerom program --config c64.json
onerom control reset --pin sel_c
```

The pad is typically an image-select pad whose jumper you have removed, usually
`sel_c`, or an `X1`/`X2` pad. The device times the pulse, so an interrupted CLI
cannot leave the host held in reset. See [`control reset`](#control-reset), and
[`control pin`](#control-pin) for driving a GPIO to an arbitrary state.

### See what One ROM is doing with its GPIOs

```
onerom inspect gpio
```

One row per MCU GPIO: everything that GPIO is — its ROM socket signal under the
image being served, the board peripheral it drives, the header pad it surfaces
on — plus direction, level, 5V tolerance, and what One ROM itself is using it
for. GPIOs connected to nothing are omitted unless you pass `--all`. Useful
before driving a pin — see [`inspect gpio`](#inspect-gpio).

### Erase / recover a device

Erase flash. This is best done while stopped; by default the command reboots the
device into the required state first. A fully erased unit falls back to the
RP2350 bootloader and is then reprogrammed with `--unrecognised` + `--board`:

```
onerom control erase --all
onerom control erase --offset 0x20000 --length 0x1000
```

Read [`control erase`](#control-erase) before using it while the device is
running — erasing the core firmware or system plugin will take down the USB
stack.

### Prepare a 16-bit ROM image

16-bit ROM types (e.g. 27C400) may need their byte pairs swapped to match the
order One ROM expects. Either rewrite the file first:

```
onerom image swap-bytes --input kick.bin --output kick-swapped.bin
```

or let the build do it, leaving the source file untouched:

```
onerom program --slot file=kick.bin,type=27C400,transform=swap_bytes
```

If your image interleaves several devices in one file — a 32-bit ROM set, say —
`deinterleave` extracts a single lane. See
[Image transforms](#image-transforms) for the full set and how they compose.

## Device states

Many commands reboot the device and, by default, pause briefly afterwards to let
it re-enumerate on the USB bus.

- **Running** (default reboot target) — firmware active, serving ROMs.
- **Stopped** — RP2350 bootloader (BOOTSEL); required for some flash operations.

Common controls, where a command supports them:

- `--running` (`-r`) / `--stopped` (`-p`) — choose the post-operation state.
- `--no-reboot` — leave the device as-is.
- `--fast` — skip the re-enumeration pause.
- `--msd` (`-m`) — mount the mass-storage device when rebooting into stopped
  mode.

## Global behaviour worth knowing

- `--yes` (`-y`) auto-confirms all prompts (non-interactive use). It also
  suppresses the confirmation otherwise required for CPU frequencies above
  150 MHz and voltages above 1.10 V in slot specs. Use with care.
- `--verbose` (`-v`) prints device-selection progress and other detail.
- `--log-level <LEVEL>` sets log verbosity; defaults to `warn`. Run
  `onerom --help` for the accepted levels.

---

# Part 2 — Reference

## Synopsis

```
onerom [GLOBAL OPTIONS] <COMMAND> [ARGS]
```

## Global options

Available on every command (they are `global` in clap terms and may appear at
any level).

| Option | Description |
|---|---|
| `--serial, -s <DEVICE>` | Select a One ROM by serial number. Required when multiple are connected; auto-selected when exactly one is present. Accepts `*` and `?` wildcards. |
| `--vid-pid <VID:PID>` (alias `--id`) | USB vendor/product ID pair in hex (e.g. `1234:abcd`). Repeatable; when given, only these pairs are matched. Use with `--unrecognised`. |
| `--unrecognised, -u` (alias `--unrecognized`) | Allow management of unrecognised/unprogrammed/bricked RP2350 boards. The unit must still expose a valid picoboot USB interface. Use with caution — permits programming any attached RP2350 board. |
| `--yes, -y` | Auto-confirm all prompts. Also suppresses the over-limit CPU frequency/voltage confirmations. |
| `--verbose, -v` | Enable verbose output. |
| `--log-level <LEVEL>` | Set log level. Defaults to `warn`. |
| `--version, -V` | Print version. |
| `--help, -h` | Print help. Works on any subcommand. |

Most commands accept `--board` (`-b`) to identify or override the board type,
and rely on `--serial` (global) to pick a specific device.

Ice (STM32) boards are recognised, but the CLI cannot scan, program or build
firmware for them. Where `--board` reaches a device or builds an image, naming
an Ice board is an error rather than a later failure. Commands that only report
hardware take them; each command's own entry below states what it accepts, and
[`board list`](#board-list) shows which boards are which.

## Command summary

| Command | Purpose | Device required |
|---|---|---|
| [`scan`](#scan) | Discover connected One ROMs | No |
| [`program`](#program) | Build and flash firmware to a One ROM | Yes |
| [`inspect`](#inspect) | Read-only device state and information | Yes |
| [`control`](#control) | Transient (non-persistent) device actions | Yes |
| [`update`](#update) | Persistent device modifications | Yes |
| [`image`](#image) | ROM image file manipulation | No |
| [`firmware`](#firmware) | Build, inspect and manage firmware binaries | Varies |
| [`plugin`](#plugin) | List available plugins | No |
| [`chips`](#chips) | List supported chip types and their flash usage | No |
| [`board`](#board) | List board types, or draw a board's pin header / socket | No |
| [`peek`](#peek-top-level-alias) | Alias for `inspect peek live` | Yes |
| [`poke`](#poke-top-level-alias) | Alias for `control poke live` | Yes |
| [`reboot`](#reboot-top-level-alias) | Alias for `control reboot` | Yes |

---

## scan

Discover and list connected One ROMs — serial, USB location, name, board type,
MCU and loaded firmware version. With `--verbose` (`-v`), each device also
shows its MCU variant and chip ID.

```
onerom scan
onerom scan --board fire-24-e
onerom scan --slots
```

| Option | Description |
|---|---|
| `--board <BOARD>` | Only show devices matching this board type. Conflicts with `--list-boards`. Must be a Fire board — a scan cannot find an Ice board. |
| `--list-boards` | List the known board types, the same listing as [`board list`](#board-list). |
| `--slots` (alias `--slot`) | Also show the ROM slot contents for each device found. Conflicts with `--list-boards`. |

Device required: no.

---

## program

Build a firmware image (from a config file, inline `--slot` specs, or a supplied
binary) and flash it to a connected One ROM. This is the primary workflow.
`onerom firmware program` is an alias for this command.

```
onerom program --config c64.json
onerom program --serial '5*' --config c64.json
onerom program --board fire-24-e \
    --slot file=kernal.bin,type=2364,cs1=active-low \
    --slot file=basic.bin,type=2364,cs1=active-low
onerom program --firmware firmware.bin
onerom program --config c64.json --out firmware.bin
```

### Source of the firmware (mutually exclusive groups)

| Option | Description |
|---|---|
| `--config, -j <FILE>` (aliases `--config-file`, `--config-json`, `--json`) | ROM configuration JSON file. Conflicts with `--slot`, `--config-name`, `--config-description`, `--save-config`, `--no-config`, `--firmware`. |
| `--slot <SPEC>` (alias `--rom`) | ROM slot specification; repeatable. See [ROM slot specification](#rom-slot-specification). Conflicts with `--config`, `--no-config`, `--firmware`. |
| `--firmware <FILE>` (alias `--fw`) | Flash a pre-built complete firmware binary directly. Conflicts with `--config`, `--slot`, `--base-firmware` and `--plugin` because a pre-built firmware already contains all ROMs/plugins. Also conflicts with `--version`. |
| `--base-firmware <FILE>` | Use a local minimal firmware instead of downloading. With `--slot`, ROMs are built into it; alone, requires `--no-config`. Must be built with `EXCLUDE_METADATA=1` and `ROM_CONFIGS=`. Conflicts with `--firmware`, `--version`. |
| `--no-config` | Confirm flashing a base firmware with no ROM configuration. Only valid with `--config-name` and/or `--config-description`. Conflicts with `--config`, `--slot`, `--firmware`, and the config-override options below. |

### Configuration metadata

| Option | Description |
|---|---|
| `--plugin <SPEC>` | Plugin specification; repeatable. See [Plugin specification](#plugin-specification). May be combined with `--config`: the plugins are inserted ahead of the config's ROM slots (which shift up), and it is an error if the config already defines a plugin of its own. Conflicts with `--firmware`. |
| `--config-name <NAME>` (alias `--name`) | Name for the generated ROM configuration. Conflicts with `--config`. |
| `--config-description <DESC>` (aliases `--desc`, `--description`) | Description for the generated configuration. Defaults to *"Created by the One ROM CLI"*. Conflicts with `--config`. |
| `--save-config <FILE>` | Save the generated configuration to JSON. Only valid with `--slot` or `--no-config`. Conflicts with `--config`. |

### Per-device overrides

These are rejected with `--no-config`.

| Option | Description |
|---|---|
| `--instance-name <NAME>` (aliases `--onerom`, `--one-rom`, `--onerom-name`, `--one-rom-name`, …) | Give this One ROM a name. |
| `--serial-override <NEW SERIAL>` | Override the device's reported serial number. |
| `--logging [BOOL]` (aliases `--boot-logging`) | Enable boot logging. Takes an optional boolean; bare flag means `true`. |
| `--disable-swd [BOOL]` (aliases `--swd-disable`) | Shut SWD down before ROM serving starts, so debug port accesses to SRAM don't steal cycles from the serving DMAs. SWD is available for the whole of boot — including boot logging — and goes off until the next reset. Nothing is logged past that point, and plugins get no logging. This is not a debug lockout: the boot ROM runs before the One ROM firmware does, and BOOTSEL/PICOBOOT are unaffected. Optional boolean; bare flag means `true`. |
| `--turbo-boot [BOOL]` | Enable turbo boot — starts serving faster by not reading the image select jumpers, so the first non-plugin slot is always the one served. More than one non-plugin slot is refused unless `--force` is given. Optional boolean; bare flag means `true`. |

### Board, version and output

| Option | Description |
|---|---|
| `--board, -b <BOARD>` | Target board type. Inferred from the connected device if omitted. |
| `--version <VERSION>` | Firmware version to build against. Defaults to the latest release. Conflicts with `--firmware`, `--base-firmware`. |
| `--output, -o <FILE>` (alias `--out`) | Also write the built firmware to this file while flashing. |

### Reboot and flashing behaviour

| Option | Description |
|---|---|
| `--stopped, -p` | After flashing, reboot into stopped (bootloader) mode. Conflicts with `--running`. |
| `--running, -r` | After flashing, reboot into running mode (the default). Conflicts with `--stopped`. |
| `--no-reboot` | Do not reboot after flashing. Conflicts with `--stopped`. |
| `--fast` | Skip the re-enumeration pause after the final reboot. Conflicts with `--no-reboot`. |
| `--msd, -m` | Mount mass storage when rebooting into stopped mode. |
| `--verify` | Verify flash by reading back after programming. **(not yet supported)** |
| `--force, -f` | Continue despite non-fatal problems: assembled firmware parse errors, a board type mismatch, and config warnings such as turbo boot with more than one non-plugin ROM slot. Each is reported as a warning instead. |
| `--batch` (aliases `--multiple`, `--multi`) | Program multiple devices, pausing for confirmation between each. Every board is programmed with the same configuration as the first. |
| `--scan-slots` | After programming, run `onerom scan --slots` to show the result. Conflicts with `--fast`. |

Device required: yes.

---

## inspect

Read-only inspection of a connected One ROM.

```
onerom inspect <COMMAND>
```

| Subcommand | Purpose | Device required |
|---|---|---|
| [`info`](#inspect-info) | Identity and configuration | Yes |
| [`telemetry`](#inspect-telemetry) | Runtime telemetry **(not yet supported)** | Yes |
| [`slots`](#inspect-slots) | List ROM slots | Yes |
| [`image`](#inspect-image) | Read a slot's ROM image **(not yet supported)** | Yes |
| [`peek`](#inspect-peek) | Read SRAM or the live ROM image | Yes |
| [`gpio`](#inspect-gpio) | Show what each GPIO is and what it is doing | Yes (running) |
| [`header`](#inspect-header) | Draw the device board's pin header | Yes |
| [`socket`](#inspect-socket) | Draw the device board's ROM socket pinout | Yes |

### inspect info

Show the device's serial number, user-assigned name, board type, MCU, firmware
version and hardware revision. With `--verbose` (`-v`), also shows the MCU
variant and chip ID.

```
onerom inspect info
onerom --serial 1234abcd inspect info
```

### inspect telemetry

Access counts, timing statistics and other runtime metrics. **(not yet
supported)**

| Option | Description |
|---|---|
| `--json` | Output telemetry as JSON. |

### inspect slots

List the ROM image slots stored on the device — index, ROM type, size and
description — marking the active slot. No options.

### inspect image

Read (or save) the ROM image from a slot. **(not yet supported)**

| Option | Description |
|---|---|
| `--slot <INDEX>` | Slot index to read. Reads the active slot if omitted. |
| `--output, -o <FILE>` (alias `--out`) | Save the image data to this file. |

### inspect peek

Read device memory. `peek memory` reads SRAM (and, in stopped state,
page-aligned flash); `peek live` reads the ROM image currently being served.

```
onerom inspect peek <COMMAND>
```

#### inspect peek live

Read from the live ROM image at a **logical** ROM offset (starting at 0). The
device must be running. Also reachable as the top-level [`peek`](#peek-top-level-alias).

```
onerom inspect peek live --address 0x100 --length 64
onerom inspect peek live --address 0 --length 8192 --output rom-image.bin
```

| Option | Description |
|---|---|
| `--address, -a <ADDRESS>` (alias `--addr`) | Logical ROM address to read from, starting at 0. Decimal or `0x` hex. Default `0`. |
| `--length, -l <LENGTH>` (aliases `--len`, `--size`) | Number of bytes to read. Decimal or hex. If omitted, reads to the end of the live image. |
| `--output, -o <FILE>` (alias `--out`) | Save the data to this file. |

#### inspect peek memory

Read One ROM's SRAM. Most addresses reachable via PICOBOOT can be queried. In
stopped state, SRAM holds no meaningful data, and flash reads must be aligned to
flash page boundaries.

```
onerom inspect peek memory --address 0x20000000 --length 128
onerom inspect peek memory --address 0x10000000 --length 8192 --output flash-start.bin
```

| Option | Description |
|---|---|
| `--address, -a <ADDRESS>` (alias `--addr`) | Address to read from. Decimal or `0x` hex. |
| `--length, -l <LENGTH>` (aliases `--len`, `--size`) | Number of bytes to read. Decimal or hex. |
| `--output, -o <FILE>` (alias `--out`) | Save the data to this file. |

### inspect gpio

Show, one row per MCU GPIO, what that GPIO is on this board and what One ROM is
currently doing with it.

The device must be **running** with the USB system plugin: One ROM's own
command handler lives in that plugin, and a stopped device is in the RP2350
bootloader where it does not exist. See [Device states](#device-states).

```
onerom inspect gpio
onerom inspect gpio --all
onerom inspect gpio --pin gpio9
onerom inspect gpio --pin x1
```

| Option | Description |
|---|---|
| `--pin <PIN>` | Show only this pin, named as `gpio<N>` or as a header pad (see [Pin values](#pin-values)). Conflicts with `--all`. |
| `--board <BOARD>` | Board type, overriding what the device reports. Only needed to resolve a `--pin` pad name on a board this build does not recognise. |
| `--all` | Also list GPIOs with no function at all. By default only GPIOs connected to something are shown. |

By default the table lists only the GPIOs connected to **something** — a ROM
socket signal, a board peripheral or a header pad. On a 48-GPIO board a quarter
of the GPIOs are connected to nothing, and listing them buries the rows worth
reading; a line beneath the table says how many were omitted. `--all` lists
every GPIO. Note the filter is on what the GPIO *is*, not on what the device
reports using it for: the `X1`/`X2` and image-select pads report `free` and are
exactly what you read this table to find, so they always appear.

The number of GPIOs the device has is its own — 30 on an RP2350A, 48 on an
RP2350B.

Columns:

| Column | Meaning |
|---|---|
| `GPIO` | MCU GPIO number. |
| `Function` | Everything this GPIO is, comma-separated in a fixed order: its ROM socket signal under the image being served (`A5`, `D3`, `CS1`, `BYTE/VPP`), then the board peripheral (`Status LED`, `RGB LED`, `USB VBUS`, `ext flash CS`), then the header pad (`X1`, `X2`, `SEL_A`). `-` if the GPIO is connected to nothing. |
| `Dir` | `out` if the pin's output driver is enabled, `in` if not. |
| `Level` | The level currently on the pad, `0` or `1`. |
| `Max V` | `5V` if the GPIO is 5V-tolerant, `3V3` if it is an RP2350 ADC pin and therefore 3.3V-only, `?` if the board is not characterised. |
| `One ROM use` | What One ROM itself is using the GPIO for: `free`, `serving (read)`, `serving (driven)` or `system`. |

`Function` lists everything that applies rather than stopping at the first
match, so a GPIO that is genuinely two things says so: on a `fire-24-f` the
Status LED and the RGB LED are the same GPIO, and it reads `Status LED,
RGB LED`. Names that would repeat are shown once — on a 32-pin board a high
address line is both the socket's `A17` and the `A17` header pad, which is one
net.

`Function` names only what a **GPIO** is. A header pad may carry more than the
GPIO behind it — on a Fire 24/28 board the `SEL_C` and `SEL_D` pads sit on the
SWCLK and SWDIO nets — but SWCLK and SWDIO are dedicated RP2350 pins with no
GPIO of their own, so they do not appear here. Run
[`inspect header`](#inspect-header) for the pad-by-pad view, which shows every
role each pad carries.

Only `Dir`, `Level` and `One ROM use` come from the device. `Function` is
derived by the CLI from the board's pin map and the chip type being served: the
device deliberately reports what taking a pin over would *cost*, never what the
pin *is*. `serving (read)` pins (address, chip-select, `/BYTE`) can be driven and
released; `serving (driven)` pins (the data pins) cannot be given back without a
reboot — see [`control pin`](#control-pin).

With `--verbose` (`-v`) the table is followed by a legend restating where each
column comes from, what `Dir` means and what the `3V3`/`5V` tags mean. Nothing
is lost without it: the cost of taking a serving pin over is stated at the point
of action by `control pin` itself.

A board revision or ROM type this build does not recognise costs the derived
names, not the listing: `Function` falls back to `-` (or, for a socket pin whose
chip type is unknown, `socket pin <N>`), and with no recognised board at all
nothing is filtered out, since nothing can be ruled out. On a board with no
pin-header descriptor, pad names come from the board's pin assignments alone and
`--verbose` says so beneath the table.

On a Fire 28 (rev C) serving a 27512:

```
One ROM Fire 28 C - Firmware: v0.7.1 State: Running Serial: FC9D67248E8E8023

GPIO state  ·  One ROM Fire 28 (rev C)  ·  RP235xB  ·  serving 27512

  GPIO  Function    Dir  Level  Max V  Current use
  ----  ----------  ---  -----  -----  ----------------
  0     D0          out  0      5V     serving (driven)
  1     D1          out  0      5V     serving (driven)
  2     D2          out  1      5V     serving (driven)
  3     D3          out  1      5V     serving (driven)
  4     D4          out  1      5V     serving (driven)
  5     D5          out  1      5V     serving (driven)
  6     D6          out  1      5V     serving (driven)
  7     D7          out  0      5V     serving (driven)
  8     X2          in   0      5V     free
  9     X1          in   0      5V     free
  10    CE/PE       in   0      5V     serving (read)
  11    OE/VPP      in   0      5V     serving (read)
  12    A14         in   0      5V     serving (read)
  13    A10         in   0      5V     serving (read)
  14    A11         in   0      5V     serving (read)
  15    A9          in   0      5V     serving (read)
  16    A8          in   0      5V     serving (read)
  17    A13         in   0      5V     serving (read)
  18    A15         in   0      5V     serving (read)
  19    A12         in   0      5V     serving (read)
  20    A7          in   0      5V     serving (read)
  21    A6          in   0      5V     serving (read)
  22    A5          in   0      5V     serving (read)
  23    A4          in   0      5V     serving (read)
  24    A3          in   0      5V     serving (read)
  25    A2          in   0      5V     serving (read)
  26    A1          in   0      5V     serving (read)
  27    A0          in   0      5V     serving (read)
  38    SEL_C       in   1      5V     free
  39    SEL_D       in   1      5V     free
  40    SEL_A       in   0      3V3    free
  41    SEL_B       in   0      3V3    free
  44    RGB LED     out  0      3V3    system
  45    Status LED  out  0      3V3    system
  46    USB VBUS    in   1      3V3    system

  13 GPIOs with no function are hidden - use --all to show them.
```

### inspect header

Draw the connected device's pin (jumper / programming) header as ASCII. The
board is inferred from the device. This is the device-oriented form of
[`board header`](#board-header); see there for what the diagram shows.

```
onerom inspect header [--board <board>]
```

| Option | Description |
|---|---|
| `--board`, `-b` | Board type, overriding what the connected One ROM reports. Only needed on a One ROM whose board type this build does not recognise. |

`--board` is an override, not a substitute for the device: this command draws
the board of a *connected* One ROM, so one must still be present. To draw a
board by name with nothing connected, use
[`board header`](#board-header).

### inspect socket

Draw the connected device's ROM socket pinout as ASCII. The board is inferred
from the device. This is the device-oriented form of
[`board socket`](#board-socket).

```
onerom inspect socket [--board <board>] [--chip-type <chip>] [--gpio]
```

| Option | Description |
|---|---|
| `--board`, `-b` | Board type, overriding what the connected One ROM reports. |
| `--chip-type <chip>`, `-c` | Label pins with this ROM type's functions instead of GPIOs, and report the chip's image size on this board. |
| `--gpio` | Overlay the GPIO(s) onto the `--chip-type` function view (requires `--chip-type`). |

As with [`inspect header`](#inspect-header), `--board` overrides the connected
One ROM's reported board type rather than standing in for the device.

---

## control

Transient actions on a connected One ROM. These affect current state but do not
persist across power cycles.

```
onerom control <COMMAND>
```

| Subcommand | Purpose | Device required |
|---|---|---|
| [`reboot`](#control-reboot) | Reboot the device | Yes |
| [`led`](#control-led) | Control the status LED | Yes |
| [`poke`](#control-poke) | Write to SRAM or the live ROM image | Yes |
| [`reset`](#control-reset) | Pulse a GPIO low to reset the host system | Yes (running) |
| [`select`](#control-select) | Select the active ROM slot **(not yet supported)** | Yes |
| [`pin`](#control-pin) | Drive a pin high, low or high-impedance | Yes (running) |
| [`erase`](#control-erase) | Erase flash memory | Yes |

### control reboot

Restart the firmware; the device re-initialises and resumes serving. By default
pauses afterwards for re-enumeration. Also reachable as the top-level
[`reboot`](#reboot-top-level-alias).

```
onerom control reboot
```

| Option | Description |
|---|---|
| `--stopped, -p` | Reboot into stopped (bootloader) state. |
| `--running, -r` | Reboot into running (serving) state. Default. |
| `--fast` | Don't pause for re-enumeration. |
| `--msd, -m` | Mount mass storage when rebooting into stopped mode. Conflicts with `--running`. |

`--stopped` and `--running` are mutually exclusive.

### control led

```
onerom control led on
onerom control led off
```

| Subcommand | Description |
|---|---|
| `on` | Turn the status LED on. |
| `off` | Turn the status LED off. |
| `beacon` | Beacon the LED to identify a physical unit. |
| `flame` | Flame effect on the LED. |

None take options. Device required: yes.

### control poke

Transient writes to device memory — changes are lost on reboot. Use
[`update`](#update) for persistent flash writes.

```
onerom control poke <COMMAND>
```

#### control poke memory

Write a single byte or a binary file to SRAM at a given address. When the device
is running, virtual addresses are available (e.g. `0x90000000` is the start of
the live ROM image — though prefer `poke live` for that). Writing arbitrary SRAM
can corrupt firmware state.

```
onerom control poke memory --address 0x20000010 --byte 0xFF
onerom control poke memory --address 0x20000000 --input patch.bin
```

| Option | Description |
|---|---|
| `--address, -a <ADDRESS>` (alias `--addr`) | Address to write to. Decimal or `0x` hex. |
| `--byte <BYTE>` (alias `--value`) | Single byte value to write. Decimal or hex. |
| `--input, -i <FILE>` (alias `--in`) | Write the contents of this binary file. |

Exactly one of `--byte` / `--input` is required.

#### control poke live

Write a single byte or a binary file to the live ROM image at a **logical** ROM
offset (starting at 0). Useful for patching a running ROM without reflashing.
Also reachable as the top-level [`poke`](#poke-top-level-alias).

```
onerom control poke live --address 0x100 --byte 0xEA
onerom control poke live --address 0 --input patch.bin
```

| Option | Description |
|---|---|
| `--address, -a <ADDRESS>` (alias `--addr`) | Logical ROM address, starting at 0. Decimal or `0x` hex. Default `0`. |
| `--byte <BYTE>` (alias `--value`) | Single byte value to write. Decimal or hex. |
| `--input, -i <FILE>` (alias `--in`) | Write the contents of this binary file. |
| `--delta` (alias `--deltas`) | Only write bytes that differ from current device content. Requires `--input`. |
| `--dry-run` (alias `--dryrun`) | Show what would be written without writing. Requires `--delta`. |

Exactly one of `--byte` / `--input` is required.

### control reset

Pulse a GPIO low, then release it, to reset the host system One ROM is installed
in — useful in scripted workflows after programming a new image.

`--pin` is the pin your reset wire is soldered to, typically an image-select pad
whose jumper has been removed — `sel_c` is the usual choice, as more boards have
it than have X pads and it is 5V tolerant where it exists — or an `X1`/`X2` pad.
Name it by pad (`sel_c`, `x1`) or by MCU GPIO (`gpio9`) — see
[Pin values](#pin-values). [`inspect header`](#inspect-header) shows which GPIO
is behind each pad.

The line is only ever **driven low and then released to high impedance**. A reset
net has its own pull-up and may have other drivers on it, so there is
deliberately no way to drive it high. Use [`control pin`](#control-pin) if you
need arbitrary states.

The **device** times the pulse, not the CLI: if this command is interrupted, the
terminal closes or the cable is pulled mid-pulse, the device still releases the
pin. The device's own limit is 60 seconds.

The device must be **running** with the USB system plugin — see
[Device states](#device-states).

```
onerom control reset --pin sel_c
onerom control reset --pin gpio9
onerom control reset --pin gpio9 --hold 500
```

| Option | Description |
|---|---|
| `--pin <PIN>` | Pin the reset wire is connected to, named as `gpio<N>` or as a header pad (see [Pin values](#pin-values)). Required. |
| `--board <BOARD>` | Board type, overriding what the device reports. Only needed to resolve a `--pin` pad name on a board this build does not recognise. |
| `--hold <MS>` | Milliseconds to hold reset asserted. Decimal or `0x` hex. Default `100`; `0` is rejected, because a reset pulse with no end is not a reset. |

If One ROM is itself using the GPIO the command is refused, naming what it is
doing; `control reset` has no `--force` of its own, and the message points at
`control pin --force` for the case where that is genuinely what you want. If the
GPIO is not 5V-tolerant the command warns and asks for confirmation, which
`--yes` answers.

```
$ onerom control reset --pin x1
Asserted reset on x1 (gpio9) for 100ms - the device times the pulse and releases the pin
```

### control select

Switch the device to serving the specified slot immediately (not persistent).
**(not yet supported)**

| Option | Description |
|---|---|
| `--slot <INDEX>` | Slot index to activate. Required. |

### control pin

Drive a One ROM pin high, low or high-impedance, optionally for a bounded
period.

`--pin` names an MCU GPIO or a header pad (see [Pin values](#pin-values)); the
command is named for what is being addressed rather than for any one spelling.

Without `--hold` the state is latched until something else changes it. With
`--hold` the **device** holds the state for that many milliseconds and then
applies `--then` — high impedance unless you say otherwise. As with
[`control reset`](#control-reset), the hold is timed on the device, so an
interrupted CLI cannot leave a pin latched.

The device must be **running** with the USB system plugin — see
[Device states](#device-states). [`inspect gpio`](#inspect-gpio) shows what each
GPIO is and what One ROM is using it for.

```
onerom control pin --pin gpio9 --state high
onerom control pin --pin gpio9 --state low --hold 250
onerom control pin --pin gpio9 --state low --hold 250 --then high
onerom control pin --pin x1 --state 0 --hold 250
onerom control pin --pin sel_a --state z
```

| Option | Description |
|---|---|
| `--pin <PIN>` | Pin to drive, named as `gpio<N>` or as a header pad (see [Pin values](#pin-values)). Required. |
| `--board <BOARD>` | Board type, overriding what the device reports. Only needed to resolve a `--pin` pad name on a board this build does not recognise. |
| `--state <STATE>` | `high`, `low`, or `z` (high-impedance). `1` and `0` are accepted for `high` and `low`. Required. |
| `--hold <MS>` | Hold `--state` for this many milliseconds, then apply `--then`. Decimal or `0x` hex. Omit to latch indefinitely. The device's own limit is 60 seconds. |
| `--then <STATE>` | State to apply when `--hold` expires: `high`, `low` or `z` (or `1`/`0`). Default `z`. Requires `--hold`. |
| `--force` | Drive the GPIO even though One ROM is using it for serving. |

**Refusals and warnings.** If One ROM is itself using the GPIO, the command is
refused and names what it is doing. `--force` overrides, and prints what that
costs:

- a pin serving **reads** (address, chip-select, `/BYTE`) is reversible — serving
  keeps reading it, and `--state z` puts it back;
- a pin serving **drives** (a data pin) is not — forcing it takes the pin away
  from the PIO that drives it, and serving stays broken until the device is
  rebooted.

If the GPIO is not 5V-tolerant — an RP2350 ADC pin, per the board metadata, not
a measurement — the command warns and asks for confirmation, which `--yes` or
`--force` answers. Nothing else about the pad is checked: what is wired to it,
whether a jumper is fitted and what voltage the far end sits at are yours to
know.

```
$ onerom control pin --pin x1 --state low --hold 2000
Set x1 (gpio9) low for 2000ms - the device times the hold and then sets it high impedance
```

### control erase

Permanently erase flash contents — firmware, metadata and ROM images. A fully
erased unit boots into the RP2350 bootloader and is reprogrammed with
`--unrecognised` + `--board`.

Best performed while stopped; by default the command reboots into the required
state first. Erasing the core firmware or the system plugin while **running**
takes down the USB stack (requiring manual BOOTSEL via the header pins), and
large erases may cause a temporary USB drop and re-enumerate — in which case the
erase likely succeeded and can be checked with `inspect peek memory`. Anything
else running from flash (e.g. a user plugin) may crash during an erase.

Offsets are relative to the flash base `0x10000000`. Ranges must be 4096-aligned.
Multiple ranges may be erased in one operation.

```
onerom control erase --all
onerom control erase --offset 0x20000 --length 0x1000
```

| Option | Description |
|---|---|
| `--all, -a` | Erase all flash contents. |
| `--offset <OFFSET>` | Erase at offset(s) from the flash base. 4096-aligned; pair each with a `--length`; repeatable. Conflicts with `--address`. |
| `--address <ADDRESS>` (alias `--addr`) | Erase at absolute address(es). 4096-aligned; pair each with a `--length`; repeatable. Conflicts with `--offset`. |
| `--length <LENGTH>` (aliases `--len`, `--size`) | Length of each range. 4096-aligned; specify once per `--offset`/`--address`; repeatable. Conflicts with `--all`. |
| `--no-reboot, -n` | Don't reboot before or after erasing. Risky if One ROM is accessing the range. |
| `--stopped, -p` | Reboot into stopped mode after erasing. |
| `--running, -r` | Reboot into running mode after erasing. |
| `--msd, -m` | Mount mass storage when rebooting into stopped mode. Requires `--stopped`. |
| `--fast` | Don't pause for re-enumeration. Requires a reboot mode. |

One of `--all` / `--offset` / `--address` is required. `--stopped` and
`--running` are mutually exclusive, and both conflict with `--no-reboot`.

---

## update

Persistent modifications — these write to flash and survive power cycles.

```
onerom update <COMMAND>
```

| Subcommand | Purpose | Device required |
|---|---|---|
| [`slot`](#update-slot) | Write a ROM image to a flash slot **(not yet supported)** | Yes |
| [`commit`](#update-commit) | Commit the live image to flash **(not yet supported)** | Yes |
| [`otp`](#update-otp) | Read/write OTP memory **(not yet supported, hidden)** | Yes |

### update slot

Write a ROM image to a flash slot; persists across power cycles. The ROM type
and chip-select configuration must match the slot's existing configuration, or
the slot must be empty. **(not yet supported)**

```
onerom update slot --slot 2 --image kernal.bin
```

| Option | Description |
|---|---|
| `--slot <INDEX>` | Flash slot index to write. Required. |
| `--image <FILE>` | ROM image file to write. Required. |

### update commit

Persist the currently active RAM image to its corresponding flash slot. **(not
yet supported)**

```
onerom update commit
onerom update commit --slot 2
```

| Option | Description |
|---|---|
| `--slot <INDEX>` | Slot to commit. Commits the active slot if omitted. |

### update otp

Read or write RP2350 OTP memory, including One ROM-specific USB configuration and
identity data. Hidden, advanced. **OTP writes are irreversible.** **(not yet
supported)**

| Option | Description |
|---|---|
| `--read` | Read and display OTP contents. Conflicts with `--write`. |
| `--write <ROW=VALUE>` | Write a value to an OTP row. Conflicts with `--read`. |

---

## image

ROM image file manipulation. No device connection required.

```
onerom image <COMMAND>
```

### image swap-bytes

Swap adjacent byte pairs — reverses byte order within each 16-bit word
throughout the image. Required for 16-bit ROM types (e.g. 27C400) when the source
has the opposite byte order to what One ROM expects. The input must have an even
number of bytes.

```
onerom image swap-bytes --input kick.bin --output kick-swapped.bin
```

| Option | Description |
|---|---|
| `--input, -i <FILE>` (alias `--in`) | Input ROM image file. |
| `--output, -o <FILE>` (alias `--out`) | Output file path. |

The same operation is available during a build as
`--slot transform=swap_bytes`; see [Image transforms](#image-transforms).

Device required: no.

### image deinterleave

Extract one lane from an interleaved ROM image. The image contains `--stride`
interleaved lanes of `--bytes` bytes each; lane `--offset` is kept and the rest
discarded. Used to split a wide ROM image, distributed as a single interleaved
file, into the narrower images each device needs.

The input length must be a multiple of `--bytes × --stride`; the output is
`1/--stride` of the input length.

```
# odd bytes of a 16-bit interleaved image
onerom image deinterleave --input rom16.bin --output odd.bin --offset 1 --stride 2

# byte 2 of a 32-bit interleaved image
onerom image deinterleave --input rom32.bin --output b2.bin --offset 2 --stride 4

# the upper 16-bit half of each 32-bit word
onerom image deinterleave --input rom32.bin --output hi.bin --offset 1 --stride 2 --bytes 2
```

| Option | Description |
|---|---|
| `--input, -i <FILE>` (alias `--in`) | Input ROM image file. |
| `--output, -o <FILE>` (alias `--out`) | Output file path. |
| `--offset <N>` | Which lane to keep. Must be less than `--stride`. |
| `--stride <N>` | How many lanes the image interleaves. Must be at least 2. |
| `--bytes <N>` (alias `--unit`) | Width of one lane, in bytes. Defaults to `1`; use `2` to keep 16-bit words together. |

The same operation is available during a build as
`--slot transform=deinterleave:<offset>/<stride>[/<bytes>]`; see
[Image transforms](#image-transforms).

Device required: no.

### image convert

Convert a ROM image between formats. Reads `--input` in the `--from` format and
writes `--output` in the `--to` format. Formats: `binary` (aliases `bin`, `raw`)
and `ihex` (Intel HEX; aliases `intel-hex`, `intel_hex`). The format set is
designed to grow — further formats can be added without changing the command.

```
onerom image convert --from ihex --to binary --input rom.hex --output rom.bin
onerom image convert --from binary --to ihex --input rom.bin --output rom.hex --load-address $E000
```

| Option | Description |
|---|---|
| `--from <FORMAT>` | Input format: `binary` or `ihex`. |
| `--to <FORMAT>` | Output format: `binary` or `ihex`. |
| `--input, -i <FILE>` (alias `--in`) | Input ROM image file. |
| `--output, -o <FILE>` (alias `--out`) | Output file path. |
| `--load-address <ADDR>` | Intel HEX load address (decimal, or `0x`/`$`-prefixed hex). Only valid when one side is `ihex`; subtracted when reading ihex, used as the base when writing ihex. Defaults to `0`. |

Intel HEX output uses 16-byte records with a terminating EOF record; unwritten
addresses read as `0xFF` when decoding. Device required: no.

---

## firmware

Build, inspect and manage firmware binaries. Use [`program`](#program) to flash;
`firmware build` produces a binary without flashing.

```
onerom firmware <COMMAND>
```

| Subcommand | Purpose | Device required |
|---|---|---|
| [`build`](#firmware-build) | Build a firmware binary from a config | No |
| [`inspect`](#firmware-inspect) | Inspect a firmware binary | No |
| [`releases`](#firmware-releases) | List firmware releases | No |
| [`download`](#firmware-download) | Download a release binary | No |
| [`chips`](#firmware-chips) | List supported chip types and their flash usage | No |
| `program` | Alias for [`onerom program`](#program) | Yes |

### firmware build

Produce a flashable firmware binary for a board and MCU from a JSON config or
inline `--slot` args, without flashing.

```
onerom firmware build --config c64.json --board fire-24-e --out firmware.bin
onerom firmware build --board fire-24-e \
    --slot file=kernal.bin,type=2364,cs1=active-low \
    --out firmware.bin
```

The configuration options mirror [`program`](#program): `--config` (`-j`),
`--slot`, `--plugin`, `--config-name`, `--config-description`, `--save-config`,
`--no-config`, and the per-device overrides `--instance-name`,
`--serial-override`, `--logging`, `--disable-swd`, `--turbo-boot` (all rejected
with `--no-config`). Build-specific options:

| Option | Description |
|---|---|
| `--board, -b <BOARD>` | Target board type. Required when not inferrable from a connected device. |
| `--version <VERSION>` | Firmware version to build against. Defaults to latest. |
| `--base-firmware <FILE>` | Use a local minimal firmware instead of downloading. Must be built with `EXCLUDE_METADATA=1` and `ROM_CONFIGS=`. Conflicts with `--version`. |
| `--output, -o <FILE>` (alias `--out`) | Output file path. Defaults to `onerom-<board>-<version>.bin`. Conflicts with `--path`. |
| `--path <DIR>` | Output directory, using the default filename. Conflicts with `--output`. |
| `--force, -f` | Continue despite non-fatal problems: assembled firmware parse errors, a board type mismatch, and config warnings such as turbo boot with more than one non-plugin ROM slot. Each is reported as a warning instead. |

Device required: no.

### firmware inspect

Show a firmware binary's version, board type, MCU, and embedded ROM images and
metadata.

```
onerom firmware inspect --firmware firmware.bin
```

| Option | Description |
|---|---|
| `--firmware <FILE>` (aliases `--fw`, `--in`, `--input`) | Firmware binary to inspect. |
| `--board, -b <BOARD>` | Inspect the release firmware for this board type. Conflicts with `--firmware`. |
| `--version <VERSION>` | Firmware version to inspect. Defaults to latest. Conflicts with `--firmware`. |

### firmware releases

List available firmware releases with supported boards and MCUs.

```
onerom firmware releases
```

| Option | Description |
|---|---|
| `--board, -b <BOARD>` | Show only releases for this board type. |
| `--all, -a` | Show all releases even if a device is attached and detected. Conflicts with `--board`. |

### firmware download

Download the base (ROM-less) firmware binary for a version/board/MCU.

```
onerom firmware download --version 0.6.5 --board fire-24-e --out firmware.bin
```

| Option | Description |
|---|---|
| `--version <VERSION>` | Version to download. Defaults to latest. |
| `--board, -b <BOARD>` | Target board type. Inferred from device if omitted. |
| `--output, -o <FILE>` (alias `--out`) | Output file path. Defaults to `onerom_<board>_<version>.bin`. Conflicts with `--path`. |
| `--path <DIR>` | Output directory, using the default filename. Conflicts with `--output`. |

This firmware binary can then be used as a base for [`firmware build`](#firmware-build) or flashed with
[`program`](#program) using the `--base-firmware` option.  Do not flash it directly, as it contains no ROM configuration and will not serve any ROMs.

### firmware chips

List the chip types a board can emulate and the flash each one uses, or all chip
types grouped by pin count. Identical to the top-level [`chips`](#chips).

```
onerom firmware chips --board fire-24-e
onerom firmware chips --board fire-24-e --chip-type 2364
onerom firmware chips --all
```

| Option | Description |
|---|---|
| `--board, -b <BOARD>` | Show supported chips for this board. Conflicts with `--all`. |
| `--all, -a` | Show all chips grouped by pin count. Conflicts with `--board`. |
| `--chip-type, -c <CHIP>` | Show just this chip type's flash usage on the board. Conflicts with `--all`. |

---

## plugin

List available plugins from the release manifest, with versions and minimum
firmware requirements. Without a connected device or `--fw-version`, minimum
firmware requirements are shown for reference; with either, incompatible plugins
are flagged.

```
onerom plugin
onerom plugin --all-versions
onerom plugin --type system
onerom plugin --fw-version 0.6.6
```

| Option | Description |
|---|---|
| `--all-versions, -a` | Show all versions of each plugin, not just the latest. |
| `--type, -t <TYPE>` | Filter by plugin type: `system` or `user`. |
| `--fw-version <VERSION>` | Firmware version to check compatibility against. |

Device required: no.

---

## chips

List supported chip types — for a board, with the flash each one uses, or all
grouped by pin count. Top-level alias for [`firmware chips`](#firmware-chips).

```
onerom chips --board fire-24-e
onerom chips --board fire-24-e --chip-type 2364
onerom chips --all
```

| Option | Description |
|---|---|
| `--board, -b <BOARD>` | Show supported chips for this board. Conflicts with `--all`. |
| `--all, -a` | Show all chips grouped by pin count. Conflicts with `--board`. |
| `--chip-type, -c <CHIP>` | Show just this chip type's flash usage on the board. Conflicts with `--all`. |

### Flash usage

For a board, each chip is listed with its **ROM size** (the chip's own capacity)
and its **image size** — the flash One ROM uses to emulate it, which is often
larger, and occasionally much larger. The figures, and the grouping, are the same
ones published in [Chip Compatibility](COMPATIBILITY.md); the document is
generated from the same source the CLI reads, so the two agree.

Chips are grouped by how they fit the board's socket, and the **Fit** column
names the fit exactly:

| Fit | Meaning |
|---|---|
| `native` | Chip and board have the same pin count — it goes straight in. |
| `overhang` | Chip has *fewer* pins than the board, so One ROM's top pins hang out of the socket. |
| `larger socket (no fly-leads)` | Chip has *more* pins than the board, but no address line among the extra ones: One ROM sits bottom-justified in the socket, with nothing to wire. |
| `fly-lead to X1` / `fly-lead to X1 and X2` | Chip has more pins than the board, and the overhanging address line(s) must be wired to One ROM's `X1` (and `X2`) header pin. |

Every fit other than `native` is a cross-size fit, and in all of them One ROM's
power pins may not line up with the socket's — **power must be rerouted to One
ROM's own VCC/5V pin**. `larger socket (no fly-leads)` means no *signal* wiring
is needed; it does not mean the chip simply drops in. Use
[`board socket`](#board-socket) with `--chip-type` and `--gpio` to see exactly
where One ROM's VCC lands.

The sizes are for a chip served alone in its slot. A banked or multi-ROM set
draws further lines into the slot's address window, so its image can be larger
than the figure shown here; build the firmware and run
[`onerom firmware inspect`](#firmware-inspect) to see what a specific set costs.

Chips are listed only where a size can be derived, which means Fire (RP2350)
boards. An Ice (STM32) board falls back to a plain list of names. A chip type of
the board's own pin count that the board cannot serve — either because no
firmware serves it yet (the SRAM types, at the time of writing) or because this
particular board's layout cannot place it — is named in a trailing line rather
than tabulated.

Board is taken from `--board`, or inferred from a connected One ROM. `--chip-type`
accepts any chip type the board can emulate, under any accepted spelling.

Example output (illustrative — your build may differ):

```
$ onerom chips --board fire-24-f
Supported chip types for fire-24-f (One ROM Fire 24 (rev F)):

  24-pin chips (native)
    Chip       ROM size  Image size  Fit
    2704           512B        512B  native
    2364            8KB         8KB  native
    ...

  28-pin chips (with fly-leads)
    Chip       ROM size  Image size  Fit
    2764            8KB        32KB  fly-lead to X1
    ...

  Image size is the flash One ROM uses to emulate the chip, which may exceed the chip's own ROM size.  See docs/COMPATIBILITY.md.

  Recognised but not servable on this board: 2016, 6116

Supported plugin types:
  SystemPlugin, UserPlugin
```

A single chip type, on the board that makes the point — an 8KB ROM costing 256KB
of flash, because One ROM overhangs a 28-pin socket to emulate a 24-pin part:

```
$ onerom chips --board fire-28-c --chip-type 2364
2364 on fire-28-c (One ROM Fire 28 (rev C)):
  ROM size    8KB
  Image size  256KB
  Fit         overhang
```

With `--all`, chip types are listed by pin count without sizes, which are
board-dependent:

```
Supported 24-pin chips:
  2016, 2316, 2332, 2364, 2704, 2708, 2716, 2732, 27C32, 28C16, 4732, 4764, ...
Supported 28-pin chips:
  231024, 23128, 23256, 23512, 23C1000, 23QL384, 23QL512, 27128, 27256, ...
Supported 32-pin chips:
  23C1001, 23C1010, 27C010, 27C020, 27C040, 29F010, 39SF010, SST39SF040, ...
Supported 40-pin chips:
  23C4100, 27C200, 27C400, 27C4100, AT27C400, HN62402, M27C400, MX23C4100, ...
```

Device required: no (a device is used only to infer the board when `--board` is
omitted).

---

## board

List supported One ROM board types, or draw a board's physical pin layouts as
ASCII.

```
onerom board <COMMAND>
```

| Subcommand | Purpose | Device required |
|---|---|---|
| [`list`](#board-list) | List the supported board types | No |
| [`header`](#board-header) | Draw a board's pin (jumper) header | No |
| [`socket`](#board-socket) | Draw a board's ROM socket pinout | No |

### board list

Lists the board types, in two groups. This replaces the bare `onerom boards` of
earlier releases, which no longer exists.

The first group is the boards the CLI can act on — the Fire (RP2350) boards.
The second is the Ice (STM32) boards, which the CLI recognises but cannot scan,
program or build firmware for; naming one on a command that needs a device or an
image is an error. Commands that only report hardware still take them.

```
onerom board list
```

Example output (illustrative — your build may differ):

```
Supported One ROM board types:
  fire-24-a, fire-24-c, fire-24-d, fire-24-e, fire-24-eadb01, fire-24-f, fire-24-usb-b, fire-28-a, fire-28-b, fire-28-c, fire-28-d, fire-32-a, fire-32-b, fire-40-a, fire-40-b

Recognised, but not supported by the CLI:
  ice-24-d, ice-24-e, ice-24-f, ice-24-g, ice-24-i, ice-24-j, ice-24-usb-h, ice-28-a
  These boards use an STM32, rather than the RP2350 the CLI works with.
```

`onerom scan --list-boards` prints the same listing.

Device required: no.

### board header

Draw a board's pin (jumper / programming) header — the 2xN header along the
board's top edge — as ASCII, pad by pad. Each image-select and X pad is
annotated with the MCU GPIO behind it, and on RP2350 (Fire) boards with whether
that GPIO is 5V-tolerant (`5V`) or 3.3V-only (`!!3V3!!` — an ADC pin that must
not be driven above 3.3V). See [Voltage Levels](VOLTAGE-LEVELS.md) for the ADC
caveat.

```
onerom board header [--board <board>]
```

| Option | Description |
|---|---|
| `--board`, `-b` | Board type to draw (e.g. `fire-24-f`). Inferred from a connected One ROM if omitted. |

A board with no pin-header descriptor prints a short notice instead of a
diagram.

```
onerom board header --board fire-24-f
```

Device required: no (a device is used only to infer `--board` when it is
omitted).

### board socket

Draw a board's ROM socket pinout as a DIP diagram.

```
onerom board socket [--board <board>] [--chip-type <chip>] [--gpio]
```

| Option | Description |
|---|---|
| `--board`, `-b` | Board type to draw (e.g. `fire-24-f`). Inferred from a connected One ROM if omitted. |
| `--chip-type`, `-c` | Label pins with this chip type's ROM functions instead of GPIOs. |
| `--gpio` | Overlay the GPIO(s) behind each pin onto the `--chip-type` view. Requires `--chip-type`. |

Without `--chip-type`, each socket pin is labelled with the GPIO(s) behind it (the
GPIO map). With `--chip-type <chip>` (e.g. `2364`), the pins are labelled with that
ROM's functions (address / data / chip-select / `BYTE` / power / …) instead;
add `--gpio` to overlay both. `--gpio` requires `--chip-type`. A pin that carries
two functions on a multiplexed part (e.g. the 27C400's pin 29, `A0/D15`) shows
both.

The two views that label pins with GPIOs — no `--chip-type`, or `--gpio` — need
the board's GPIO map. A board without one reports that and draws nothing; the
`--chip-type` function view still works, as it is drawn from the chip's pinout
and the board's ROM signal assignments.

When the chip's pin count differs from the board's, the socket is drawn at the
larger of the two and the smaller device is bottom-justified (see
[Chip Compatibility](COMPATIBILITY.md)):

- emulating a **smaller** ROM on a larger One ROM, One ROM's extra pins hang out
  of the socket and are marked `overhang` (reroute power to One ROM's VCC/5V pin);
- emulating a **larger** ROM on a smaller One ROM, the socket pins One ROM does
  not reach are marked `(empty)`, and any address line there shows the One ROM
  `X1`/`X2` header pin it must be fly-leaded to (e.g. `A12 → X1`).

In both cases One ROM's own power pins may not line up with the ROM's. With
`--gpio`, the pin One ROM's VCC (or GND) lands on is annotated `(VCC)`/`(GND)` —
e.g. `NC (VCC)` shows One ROM's VCC sitting on the ROM's NC pin — so you know
where power must be applied.

With `--chip-type`, the diagram is followed by that chip's image size on this
board — the flash One ROM uses to emulate it, as reported by
[`onerom chips`](#chips).

`--chip-type` must be a chip type the board can emulate (native, overhang or
fly-lead; see [`onerom chips`](#chips) and
[Chip Compatibility](COMPATIBILITY.md)).

```
onerom board socket --board fire-24-f
onerom board socket --board fire-24-f --chip-type 2364
onerom board socket --board fire-24-f --chip-type 2364 --gpio
```

Device required: no (a device is used only to infer `--board` when it is
omitted).

---

## Top-level aliases

Convenience aliases for frequently used nested commands. They take the same
options as their targets.

### peek (top-level alias)

Alias for [`inspect peek live`](#inspect-peek-live).

```
onerom peek live --address 0x100 --length 64
```

### poke (top-level alias)

Alias for [`control poke live`](#control-poke-live).

```
onerom poke live --address 0x100 --input patch.bin
```

### reboot (top-level alias)

Alias for [`control reboot`](#control-reboot).

```
onerom reboot
```

---

## ROM slot specification

Used by `--slot` in [`program`](#program) and [`firmware build`](#firmware-build).
Repeat `--slot` once per slot. Comma-separated `key=value` pairs:

```
file=<path_or_url>,type=<romtype>[,cs1=<logic>][,cs2=<logic>][,cs3=<logic>]
    [,size-handling=<handling>][,format=<binary|ihex>][,load-address=<addr>]
    [,transform=<list>]
    [,cpu-freq=<freq>][,cpu-vreg=<voltage>][,led=<bool>][,force-16-bit=<bool>]
```

| Key | Values / notes |
|---|---|
| `file` | Local path or URL to the ROM image. |
| `type` | Chip type, e.g. `2364`, `2332`, `2716`, `27C400`. Any type the target firmware can serve on the board is accepted — that is exactly what [`chips --board`](#chips) lists, including the overhang and fly-lead combinations (a `2764` on a Fire 24, say); see [COMPATIBILITY.md](COMPATIBILITY.md). Building for firmware older than v0.7.0 accepts a narrower set, and a rejection lists what that firmware serves. Any accepted alias may be used; the exact spelling you enter is preserved in the device metadata (shown by `scan`/`inspect`), while the resolved type drives behaviour. |
| `cs1`, `cs2`, `cs3` | CS polarity: `active-low` (or `0`), `active-high` (or `1`), or `ignore`. The snake_case config spellings (`active_low`, `active_high`) are also accepted. Which lines are required depends on the chip type (e.g. `2332` requires `cs1` and `cs2`). `ignore` says One ROM does not monitor the line at all — it is not a polarity, and is only permitted where the chip type or set allows it (see `allow_cs_ignore`). |
| `size-handling` (aliases `size`, `size_handling`) | `none`, `duplicate` (or `dup`), `truncate` (or `trunc`), `pad`. For an Intel HEX image, padding fills with `0xFF` and `duplicate` is not permitted. |
| `format` | `binary` (default) or `ihex` (Intel HEX). An `ihex` file is decoded to a binary image before use; unwritten bytes read as `0xFF`. |
| `load-address` (alias `load_address`) | Only valid with `format=ihex`. The absolute Intel HEX address that maps to byte 0 of the ROM, as a decimal or `0x`/`$`-prefixed hex value (e.g. `$E000`). Defaults to `0`. |
| `transform` | Byte-level rearrangements of the image, applied in the order given and joined with `+`. See [Image transforms](#image-transforms). |
| `cpu-freq` | e.g. `150`, `150mhz`, `150MHz`. Values above 150 MHz require confirmation (suppressed by `--yes`) and set overclock automatically. |
| `cpu-vreg` | e.g. `1.1`, `1.10`, `1.10v`, `1.10V`. Values above 1.10 V require confirmation (suppressed by `--yes`). Must be a supported level. |
| `led` | Boolean: `on`/`off`, `true`/`false`, `1`/`0`. |
| `force-16-bit` (alias `force_16bit`) | Boolean (as above). Valid only on 40-pin boards. |

Examples:

```
--slot file=kernal.bin,type=2364,cs1=active-low
--slot file=chargen.bin,type=2332,cs1=active-low,cs2=active-high
--slot file=https://example.com/basic.bin,type=2716
--slot file=small.bin,type=2364,cs1=active-low,size-handling=duplicate
--slot file=kernal.hex,type=2364,cs1=active-low,format=ihex
--slot file=kernal.hex,type=2364,cs1=active-low,format=ihex,load-address=$E000
--slot file=kernal.bin,type=2364,cs1=active-low,cpu-freq=200MHz,cpu-vreg=1.2V
--slot file=char.bin,type=2332,cs1=active-low,cs2=active-high,led=off
--slot file=amiga.bin,type=27C400,force-16-bit=true
--slot file=undersized.bin,type=2732,size=pad
--slot file=oversized.bin,type=2732,size=trunc
--slot file=halfsized.bin,type=2732,size=dup
--slot file=amiga.bin,type=27C400,transform=swap_bytes
--slot file=rom32.bin,type=27C010,transform=deinterleave:1/2/2+swap_bytes
```

## Image transforms

Some ROM images are not laid out the way the target chip needs them: a 16-bit
part whose image was produced with the opposite byte order, or a wide image
that interleaves several narrower devices. Transforms rearrange the bytes
before the image is written into the firmware.

They are available two ways, and both run exactly the same operation:

- as the `transform=` key of a [`--slot`](#rom-slot-specification), or a
  `"transform"` array in a config file, applied during the build;
- as the standalone [`image swap-bytes`](#image-swap-bytes) and
  [`image deinterleave`](#image-deinterleave) subcommands, which rewrite a file.

| Transform | Effect |
|---|---|
| `swap_bytes` | Reverses the byte order within each 16-bit word. The image must have an even length. |
| `deinterleave:<offset>/<stride>` | The image contains `stride` interleaved lanes one byte wide; keep lane `offset`. |
| `deinterleave:<offset>/<stride>/<bytes>` | As above, with lanes `bytes` wide — use `2` to keep 16-bit words together. |

The parameters are positional, in the order `<offset>/<stride>/<bytes>`, and
`<bytes>` may be omitted (it defaults to `1`).

Each name has aliases, accepted identically by the CLI and by a config file:

| Canonical | Also accepted |
|---|---|
| `swap_bytes` | `swap-bytes`, `swapbytes` |
| `deinterleave` | `de_interleave`, `de-interleave`, `deint` |
| `transform=` (slot key) | `trans=` |

`deinterleave` requires the image length to be a multiple of `bytes × stride`
— one full set of lanes. The result is `1/stride` of the input length.

Transforms are applied **in the order listed**, and the order matters:

```
transform=deinterleave:1/2/2+swap_bytes
```

takes the upper 16-bit half of each 32-bit word and *then* swaps its byte
pairs. Note that `offset` selects which lane, not a named "high" or "low" half
— which half you get depends on the byte order of your source image, and that
is what `swap_bytes` is for.

Within the build pipeline, transforms run after any `location` window and after
an Intel HEX image has been decoded, but before `size-handling` reconciles the
image against the chip size. A `swap_bytes` on an odd-length image is an error
unless `size-handling` is `pad` (which appends one blank byte) or `truncate`
(which drops the trailing byte). Where the size handling is used this way it
counts as having been needed, so it is not then reported as redundant even if
the transformed image lands on exactly the chip size.

Common recipes:

| Goal | Spec |
|---|---|
| 16-bit image with the wrong byte order | `transform=swap_bytes` |
| Even / odd bytes of a 16-bit interleaved image | `transform=deinterleave:0/2` / `transform=deinterleave:1/2` |
| Byte *n* of a 32-bit interleaved image | `transform=deinterleave:<n>/4` |
| One 16-bit half of a 32-bit interleaved image | `transform=deinterleave:0/2/2` or `deinterleave:1/2/2` |

The transforms applied to an image are recorded in the firmware metadata
alongside its filename — as `kick.bin|transform=swap_bytes` — so a built image
carries a record of how its ROM data was derived. Note that the metadata
filename field is capped at 128 bytes, so the suffix can be truncated away for a
very long path; use `label=` to keep it short.

## Plugin specification

Used by `--plugin` in [`program`](#program) and [`firmware build`](#firmware-build).
At most one system plugin and one user plugin; a user plugin requires a system
plugin. The system plugin is placed in slot 0, the user plugin in slot 1.

| Form | Meaning |
|---|---|
| `--plugin usb` | Latest compatible version, by name. |
| `--plugin system/usb` | With explicit type (`system` or `user`). |
| `--plugin usb,version=0.1.0` | Pinned version. |
| `--plugin file=path/to/plugin.bin` | Local file. |
| `--plugin file=https://example.com/plugin.bin` | Remote file. |
## Pin values

Used by `--pin` in [`control pin`](#control-pin), [`control
reset`](#control-reset) and [`inspect gpio`](#inspect-gpio).

`--pin` names one **MCU GPIO**, either directly or through a header pad that is
wired to one. All spellings are case-insensitive (`GPIO23`, `SEL_A`).

| Form | Meaning |
|---|---|
| `gpio<N>` | An MCU GPIO — for example `gpio23`. |
| `sel_a` … `sel_e` | An image-select pad. `sel-a` and `sela` are also accepted. |
| `x1`, `x2` | An X pad. |

A pad name resolves against the **board**, since which GPIO sits behind `sel_a`
is a fact about the board and not about the name. The board is normally read
from the connected device; `--board` overrides it, and is what you need if this
build does not recognise the device's board revision. `gpio<N>` needs no board.
A board that has no such pad — `sel_e` on a four-select board, `x1` on a board
with no X pads — is an error naming the pads that board does have.

Resolution uses the board's electrical pin assignments, not its header layout,
so pad names work on every board, including those whose physical header is not
yet characterised.

A bare number is **rejected**. `23` could be an MCU GPIO, an image-select pad, an
X pad or a ROM socket pin, and driving the wrong one is not a recoverable
mistake, so the CLI names the namespaces rather than guessing. Accepting pad
names does not remove that ambiguity — it sharpens it.

The broken-out address pads (`a<N>`) are recognised and **deliberately refused**,
now and in future. `--pin` addresses MCU GPIOs and the pads a wire can reach; an
address line is a ROM signal rather than one of those, and accepting `a17` would
invite `a11` or `d3`, which have no pad at all. Use the MCU GPIO behind the pad.
`run`, `bootsel`, `swclk` and `swdio` are reported as not being GPIOs that can be
driven. There is no syntax for a ROM socket leg.

Run [`onerom inspect header`](#inspect-header) to see which GPIO is behind each
header pad, or [`onerom inspect gpio`](#inspect-gpio) for the full per-GPIO
listing.

The upper bound is the device's own GPIO count — 30 on an RP2350A, 48 on an
RP2350B — read from the device rather than assumed, so a GPIO the device does not
have is reported against what it does have.

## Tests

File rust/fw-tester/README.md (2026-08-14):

# onerom-fw-tester

This crate provides a test harness for the One ROM firmware.  It utilises `onerom-fw-emulator` to build and run the firmwar on a host system, and drives the GPIOs via `epio` to ensure that the emulated firmware correctly serves the configured ROMs.

Sample invocation from this crate's directory:

```bash
BASE_DIR=$(realpath ../..) CONFIG=onerom-config/test-0.json BOARD=fire-24-a cargo run
```

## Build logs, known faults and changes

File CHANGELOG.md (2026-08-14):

# Changelog

All notables changes between versions are documented in this file.

## v0.7.1 - 2026-08-09

Headline changes in this release:
- Intel HEX ROM input in the programming tools, ihex<->binary conversion in the CLI, and image transforms (byte swap, deinterleave) applied during a build.
- Two v0.7.0 regressions fixed: the status LED defaulting to off, and valid multi-ROM sets rejected depending on chip order.
- Image select jumpers B and D fixed on fire-28-c, fire-28-d and fire-32-b, which read the SWDIO select jumper inverted.
- RBCP (the host-control plugin) works again — the address monitor it builds on was completely broken by the v0.7.0 PIO rewrite — and now supports every ROM type the firmware serves, including 32-pin, 40-pin 16-bit and the 23QL384.
- GPIO control end to end: plugins, the USB plugin and the CLI can drive a One ROM GPIO, and `onerom control reset` can reset the host system One ROM is installed in.
- New CLI views of a board's pin header and ROM socket, and of the flash each chip type costs to emulate.
- One ROM Lens working again, and ported to a Rust/wasm crate.
- CLI `--serial-override` to set a custom serial number, exposed via the USB plugin.
- New plugin-API getters for device GPIOs and the exact per-ROM type string.
- **Breaking:** `onerom boards` is now `onerom board list`, the CLI now refuses Ice (STM32) boards, which it never supported, and `--allow-unsupported-chip-type` is gone.
- **Breaking:** the CLI's argument conventions are now consistent — no positional arguments, and each short flag means one thing across every command.

In detail:

- Add Intel HEX (ihex) as a ROM image input format.  A chip may set `"format": "ihex"` in a config file (the default remains raw binary), with an optional `"load_address"` — decimal, or `0x`/`$`-prefixed hex — giving the absolute ihex address that maps to byte 0 of the ROM; the CLI exposes the same via `--slot format=ihex,load_address=...`.  Unwritten bytes read as `0xFF`.  Decoding lives in `onerom-gen`, so the CLI, Studio and Web all get it.
- Add image transforms — byte-level rearrangements applied to a ROM image before it is written into the firmware.  A chip may carry an ordered `"transform"` array, exposed by the CLI as `--slot transform=deinterleave:1/2/2+swap_bytes`.  `swap_bytes` reverses the byte order within each 16-bit word; `deinterleave:<offset>/<stride>[/<bytes>]` extracts one lane from an interleaved image, for a wide ROM set distributed as a single file.  The list is applied in the order given, which matters, and is recorded in the firmware metadata alongside the filename.
- Add `onerom image deinterleave`, the standalone counterpart to `onerom image swap-bytes` (`--offset`, `--stride`, `--bytes`), for rewriting a file rather than transforming it during a build.  Both share the `onerom-gen` implementation used by `transform=`.  Neither reads Intel HEX; use `onerom image convert` first.
- Add `onerom image convert` to convert ROM image files between raw binary and Intel HEX (`--from`/`--to`, with `--load-address` for the ihex side).
- Add GPIO control, end to end.  `onerom control pin` drives a One ROM GPIO high, low or high impedance, optionally for a bounded period timed by the device (`--hold`, `--then`); `onerom control reset` pulses one low to reset the host system One ROM is installed in; `onerom inspect gpio` lists every GPIO with what One ROM is using it for.  `--pin` takes `gpio<N>` or a header pad name (`sel_a` to `sel_e`, `x1`/`x2`).  A GPIO One ROM is itself using is refused unless `--force`, and one that is not 5V-tolerant warns.  The primary use is a wire from a header pad to the machine's reset line, so a script can program an image and then reset the machine into it.  Plugins get the same primitives as `ORA_ID_GPIO_SET` and `ORA_ID_GPIO_QUERY`.  Requires firmware v0.7.1 and the v0.2.1 USB system plugin.
  - This required a firmware update and a USB plugin update.
- Add CLI ASCII views of a board's physical pin layouts.  `onerom board header [--board <board>]` draws the pin (jumper / programming) header pad by pad, with the GPIO behind each image-select and X pad and, on Fire boards, whether that GPIO is 5V-tolerant.  `onerom board socket [--board <board>] [--chip-type <chip>] [--gpio]` draws the ROM socket as a DIP pinout — GPIOs, the chip's pin functions, or both.  Where the chip's pin count differs from the board's, the socket is drawn at the larger with the smaller device bottom-justified, marking `overhang` and `(empty)` pins and the `X1`/`X2` fly-lead each overhanging address line needs.  The board is inferred from a connected One ROM when omitted; `onerom inspect header` and `onerom inspect socket` are the device-side forms, and take `--board` to override what the connected One ROM reports.
- `onerom chips --board <board>` now reports the flash each chip type costs to emulate, which is frequently larger than the chip — a 2364 costs 8KB on a 24-pin board but 256KB overhanging a 28-pin one — grouped by how the chip fits the socket, with `--chip-type <chip>` for a single type.  `board socket --chip-type` and `inspect socket --chip-type` report the same figure.  The listing now covers every chip the board can emulate, and a recognised type it cannot serve is named separately rather than listed as supported.  `docs/COMPATIBILITY.md` and `docs/CLI-MANUAL.md` now legend the Fit column.
- `onerom-gen` gains `compat::serving_alg_info`, reporting the serving algorithms and the GPIO window the address state machine samples for a chip on a board, derived from configuration alone.
- Add an optional per-board `jumper_header` descriptor to the board metadata, describing the 2xN pin header column by column with each pad's role, so host tools can draw an accurate diagram per board revision instead of assuming one fixed layout.  `onerom-config` exposes it as `Board::jumper_header()`, and it is cross-checked at build time against the board's electrical data so the two cannot drift apart.  The Fire 24, 28 and 32-pin boards are characterised; Fire 40 and Ice are additive JSON to follow.
- Add `--serial-override` to set a custom USB serial number, used by the USB plugin while One ROM is running.  A stopped One ROM continues to use the chip ID, the USB stack then being the RP2350 bootrom's; Studio copes with the serial changing across stopped/started, and Web works with either.  Neither Studio nor Web can program an override.
  - This required a firmware update and a USB plugin update.
- Turbo boot with more than one non-plugin ROM slot is now a warning under the CLI's `--force`, rather than a hard error.  Only the first slot is served at boot, which is what you want when it holds a bootloader that selects the others itself.
- The CLI now accepts `--plugin` alongside `--config-file` on `program` and `firmware build`; the plugins are inserted ahead of the config's ROM slots, so a plugin can be added to a stock config without editing it.  It is an error if the config already defines a plugin of its own.
- `--slot` now accepts every chip type the target firmware can serve on the board, so the overhang and fly-lead combinations `docs/COMPATIBILITY.md` documents — a 2764 on a Fire 24, say — no longer have to be built from a config file.  **Breaking:** `--allow-unsupported-chip-type` is removed, having nothing left to permit.
- **Breaking change: `onerom boards` is now `onerom board list`.**  There is deliberately no alias, so a script calling `onerom boards` must be updated — the CLI suggests `board` rather than simply failing.  A plural noun taking a singular argument read wrongly, and with three subcommands beneath it the listing deserved a name of its own.
- Ice (STM32) boards are now listed separately by `onerom board list`, and refused where the CLI cannot use them.  The CLI has never had an STM32 path — every firmware path composes an RP2350 image and every device path speaks picoboot — but a single merged list implied otherwise, and `--board ice-24-d` then failed several layers down as a missing release.  `scan`, `program`, `firmware build`, `firmware download`, `firmware inspect --board`, `control pin`, `control reset` and `inspect gpio` now reject an Ice `--board` up front; the commands that only *describe* hardware still accept them.
- `onerom inspect gpio` now shows a single `Function` column listing everything a GPIO is, in place of separate `Pad` and `Function` columns.  It names every function where a GPIO carries more than one (on a fire-24-f the status LED and the RGB LED are both GPIO 29, and only the first was listed), no longer claims a GPIO is `SWCLK` or `SWDIO`, and by default lists only the GPIOs connected to something, with `--all` for the rest.  The explanatory legend moves behind `--verbose`.
- `onerom board socket` and `onerom inspect socket` now say when a board has no GPIO map, instead of drawing the diagram with the GPIO column blank all the way down; `board header` and `inspect header` say `command unsupported` for a board with no pin-header descriptor.
- **Breaking: the CLI's argument conventions are now consistent across every command.**  No command takes a positional argument — `board header`/`board socket` take `--board` — and each short flag means one thing CLI-wide: `-b` is `--board` (no longer `--byte`), `-o` is `--output` (no longer `--offset`), `-i` is `--input` (no longer `--vid-pid`, which keeps `--id`), `-l` is `--length` (no longer `--slot`), and `-m` is `--msd` (no longer `--image`).  `--board`, `--chip-type`, `--all`, `--force`, `--no-reboot` and `--input`/`--output` gain their short forms on the commands that lacked them.
- **Breaking: `onerom control erase` now uses `--stopped`/`--running`** for its post-erase reboot mode, matching `reboot` and `program`.  As with `onerom boards`, there is deliberately no alias for the old `--reboot-stopped`/`--reboot-running`.
- `--config` is now the primary spelling of the ROM configuration file option on `program` and `firmware build`, matching how it is written everywhere else; `--config-file`, `--config-json` and `--json` remain aliases.
- `onerom image convert` now validates `--from`/`--to` as the command line is parsed, listing the accepted formats in `--help` rather than failing part-way through a conversion.  `--load-address` is likewise parsed up front, by the same code the config file uses.
- `--slot` keys and values are now documented kebab-case — `size-handling`, `load-address`, `force-16-bit`, `cs1=active-low` — matching the CLI's own argument naming; the snake_case config spellings are all still accepted, and `size-handling` (the one key that only took the snake form) now parses.
- `--slot` now accepts `cs<n>=ignore`, which a config file always could.  Chip-select values are parsed by the same `onerom-gen` code the config file uses, in place of a second, narrower copy in the CLI: previously `active_low` worked only on the command line and `ignore` only in a config file, and neither parser accepted the full set.
- Stop hard-wrapping prose in the CLI's console output.  A handful of messages broke a sentence at a fixed width, which the terminal then wrapped again at its own.
- Fix the status LED defaulting to off on v0.7.0.  It now defaults to on, and is only turned off by a per-slot firmware override that explicitly disables it.  Also fixes the limp-mode LED force-enable, which never fired, so limp-mode error blink patterns did not show when the LED was overridden off.
  - This required a firmware update.
- Fix a v0.7.0 regression that rejected valid multi-ROM sets depending on the order of their chips.  A C64 set of Kernal (2364), Character (2332, whose CS2 is set to `ignore`) and Basic (2364) validated with the character ROM last, but was rejected with it in the middle.  The consistency check now anchors on the primary chip and validates each secondary independently, so it accepts every ordering the firmware can serve.  It also now rejects, with clearer messages, multi sets the firmware could not serve.
- Fix a v0.7.0 regression that left the address monitor — and therefore RBCP and the host-control plugin — completely non-functional.  The v0.7.0 PIO rewrite moved the monitor's state machines into the ROM-serving PIO blocks, but the capture DMA, the CS→address-read IRQ handshake and the state-machine enable were all left targeting the old, now-unused block, so no address capture ever reached the ring buffer and no knock was ever detected.  All three now follow the runtime serving-block assignment.
  - This required a firmware update.
- Extend the address monitor to every ROM type the firmware serves: 32-pin ROMs, whose address pins sit in a different GPIO bank from CS and data; 40-pin 16-bit ROMs in both `/BYTE` modes (#277); and the 23QL384's qualifier-based chip-select (`ALG_CS_2`, #278), the one ROM type that folds address lines into its select decision.  For the 23QL384 a host must keep its command signalling inside a range the ROM actually serves — below the top quarter of its address space.  The host-control README's list of unsupported types is now empty.
  - This required a firmware update.  No plugin update is needed: an existing host-control binary picks the support up from the firmware.
- Add an observed (bus) address space to the plugin API and route RBCP command decode through it.  On a 40-pin part the device does not observe the ROM's least-significant address line, so command signalling occupies a narrower address space than the byte-addressed image; decoding in byte space corrupted the command on a 16-bit ROM.  Two additive getters expose this — `ORA_ID_DEMANGLE_OBSERVED_ADDR` and `ORA_ID_GET_UNOBSERVED_ADDR_BITS` — and the RBCP spec (now v0.1.1) gains a matching "Address Line Presentation" clarification.
  - This required a firmware update and a host-control plugin update.
- Report as many RAM slots as the RAM holds, rather than at most seven, and let the host-control plugin keep those a host cannot name for its own use.  A slot is exactly one ROM region, so a small ROM now yields many small slots where the old cap of seven was meant to guarantee 64KB ones and could not — a slot has to be the size of the ROM being served.  The plugin advertises at most 170 of them, since every RBCP command that names a slot rejects 0xAA, and stages NV write transactions in the ones above that.  This makes NV storage genuinely writable on devices serving a ROM smaller than the 4KB staging buffer, where `GET_NV_CAPABILITY` previously claimed writable but every transaction failed.
  - **Potentially breaking.**  A host that assumed a RAM slot was large enough for a purpose of its own, or that there were at most seven, sees something different.
  - This required a firmware update and a host-control plugin update.
- Fix two further RBCP conformance defects in the host-control plugin.  Group 0x01 Read commands received in command mode were executed, writing their answer into a back-channel region the device had stopped maintaining and so modifying the served ROM image outside any session; Group 0x01 and Group 0x03 now consume the command's argument bytes and discard it.  And `ENTER_CMD_RESP` asking for a back-channel larger than the RAM slot was discarded silently where the specification requires a reported failure, which a host distinguishes by whether the token increments.
  - This required a host-control plugin update.
- Fix the host-control plugin writing to the RBCP response header for the three commands the specification requires to update nothing: `RBCP_RESET`, `EXIT_CMD_RESP_SILENT` and `SWITCH_AND_EXIT`.  All three ran the first half of the command processing sequence before being recognised as silent, so a host that polled the back-channel after one of them saw the token change and then waited for a completion that never came.
  - This required a host-control plugin update.
- Add the plugin metadata getter `ORA_ID_GET_METADATA_UINT`, and expose device GPIOs (status LED, RGB LED, VBUS, SWD, ext-flash CS), the live status-LED state and the RP235x variant to plugins over the existing metadata-key mechanism.  `ora_set_status_led` now drives the LED even when it was configured off, and records the state as the coordination channel plugins read; CPU fault handlers force it on so faults stay visible.  The RGB plugin now discovers its GPIOs at runtime instead of hard-coding them, and reflects the status-LED state on boards where the two share a GPIO.
  - This required a firmware update and an RGB plugin update.
- Implement the previously-reserved `ORA_ID_GET_FLASH_SLOT_EXT_INFO` as a per-ROM getter, returning the ROM type string exactly as the user entered it (e.g. `27LC512`, not the canonical `27512`) plus the filename, chip size and RBCP type.  Previously the ROM type was only reachable as its numeric RBCP code.  Additive; the `api.h` version is unchanged.
  - This required a firmware update.
- The ROM type stored in a firmware's metadata now preserves the exact string the user entered rather than a canonicalised name, on both the config-file `"type"` and CLI `--slot type=...` paths.  The resolved chip type continues to drive all behaviour; only the human-readable metadata string changed.
- Give the 23C1010 mask ROM its own RBCP chip type (`0x24`); it previously shared `0x0F` with the electrically-equivalent 27C010, which the v0.7.0+ generator no longer requires.  Changes the metadata emitted for 23C1010 images.  The RBCP spec is updated to match, and also gains the 23C1001, 27C200, HM7641 and 62256 types.
- Add the `62256` chip type — 32KB static RAM in a 28-pin DIP — as a recognised type, but **not yet supported for serving**: it shows as ✗ in `docs/CHIP-TYPES.md` and `onerom-gen` rejects any config using it.  This reserves its name, pinout and RBCP chip type ahead of SRAM serving support returning to the v0.7.x firmware.
- Recognise `9316A` as an alias of the `2316` mask ROM, alongside the existing `9316`, so an Apple II/II+ ROM stamped `9316A` resolves without editing the config.
- Fix the `sel_jumper_pull` bitfield in the fire-28-c, fire-28-d and fire-32-b hardware configs, which broke image select jumpers B and D.  The high bit sat on a grounded pin instead of the SWDIO image-select pin, which is jumpered to the RUN line and so pulled high, and the jumper was therefore read inverted on those boards.  This changes the generated firmware for those three boards.
- Fix `swd_enabled = false` having no effect on v0.7.0, where it was stored and reported but never acted on.  SWD now stays up for the whole of boot and is shut off just before serving, keeping debug port SRAM accesses off the serving DMAs.  Boot logging may now be combined with it, and stops when SWD does.  Not a debug lockout — BOOTSEL/PICOBOOT are unaffected.
  - This required a firmware update.
- Fix restoring an image select pin shared with SWD resetting the control register of the wrong GPIO, on boards where a select jumper sits on SWCLK or SWDIO.
  - This required a firmware update.
- Fix `onerom firmware build` accepting `--swd_disabled` where `program` accepted `--swd_disable`, so each underscore spelling worked on only one subcommand.  `--disable-swd` and `--swd-disable` work on both.
- Fix `size_handling: pad` filling the tail of an **Intel HEX** image with `0xAA` instead of the documented `0xFF`, putting two different fill values in one image.  Raw binary images are unaffected.
- Fix `onerom-gen`'s v2 (v0.7.0+) builder not checking that the composed ROM data fits the target board's flash.  The CLI caught an oversized config downstream in `onerom-fw`, but Studio and the web programmer do not call that path, so the check now lives in the builder itself where every consumer gets it.
- Fix `onerom image swap-bytes` panicking at startup, even on `--help`, from a clap short-option collision: `-i` was claimed by both the global `--vid-pid` and swap-bytes' `--input`.  `--input`/`--output` are now long-only (aliases `--in`/`--out` unchanged).
- Fix building a chip type only v0.7.0+ firmware serves — a `23C1001` or `HM7641` — against an older firmware reporting "This tool does not support chip type", when the tool supports it perfectly well and only the firmware is too old.  It now names the firmware version required, as every other version-gated feature does.
- Fix `onerom-lab` applying the 8-bit read timing to the 27C200.  The longer read delay and tristate settle belong to every 16-bit-capable part, but the test was keyed on the 27C400 specifically.  Affects hardware testing only.
- One ROM Lens works again, and has been ported from the old C-to-WebAssembly shim to a Rust crate (`onerom-lens`, in `rust/lens`) built on `onerom-fw-emulator` — it was untested and broken in v0.7.0.  It runs the real firmware PIO/DMA serving code, visualising address/data/control-line waveforms live in the browser, and handles 8-bit ROMs and the 27C400 in both byte and 16-bit word modes.  Build and serve it with `rust/lens/serve.sh [CONFIG] [BOARD]`; the WebAssembly build is now covered by CI.  The old `firmware/lens/` C shim and `firmware/lens.mk` are removed.  The shipped firmware is unchanged.
- Improve One ROM Lens waveform readability: distinct green HIGH and cyan LOW levels where both were previously drawn the same, neutral-grey High-Z and transition edges, held address and data values annotated with their duration in cycles and in nanoseconds derived from the firmware's real SYSCLK, cycle graduation ticks once zoomed in far enough, and a compact per-bit cursor readout with a stacked summary that follows the pointer.
- Fix the One ROM Lens signal-label hover tooltip showing `GPIO [object Object]` instead of the GPIO number.
- `onerom-gen`'s public config model — `Config`, `ChipConfig`, `ChipSetConfig`, `Location`, `License`, `FileSpec`, `FileData` — and its `Error` enum are now `#[non_exhaustive]`, so future field and variant additions are backwards-compatible for downstream crates.  This is itself a breaking change (external code must use the new `new()` constructors rather than struct literals, and a `match` on `Error` must carry a wildcard arm), hence the `onerom-gen` minor version bump.
- `onerom_config::chip::ChipType` is now `#[non_exhaustive]`, so future chip-type additions are backwards-compatible.  This is likewise a breaking change for external `match` expressions, hence the `onerom-config` minor version bump.
- `onerom-gen` is now built as a genuine `no_std` (+`alloc`) crate, matching its intended use in embedded and WASM contexts; the `#![no_std]` attribute was previously commented out.  Backwards-compatible for `std` consumers.
- Fix `docs/COMPATIBILITY.md` and `onerom chips` reporting compatibility for a chip-select configuration users cannot ask for.  Both checked each chip with only its primary select monitored, which needs the `allow_cs_ignore` config option and is rejected outright by `--slot`; they now check the configuration the tools actually produce, with every control line monitored.  HM7641 gains fire-24-a/b, the 28-pin and fire-32-a boards, which One ROM has always served; 2316, 9316, 9316A, 2332, 4732 and 9332 are no longer listed for fire-28-b/c/d, nor 23128 for fire-32-a/b, which One ROM has never been able to serve.
- **Breaking:** `onerom-gen`'s `check_chip_on_board` becomes `check_chip_set_on_board`, taking a chip-set type, chip count and CS configuration, so banked and multi sets can be checked as well as single chips; `supported_chips` takes the set shape too.  `CompatResult` gains the GPIOs whose ROM table bits address nothing, and it and `ChipCompat` are now `#[non_exhaustive]`.
- Removed `test-retired`, the old test mechanism, superseded by `onerom-fw-tester`.
- `onerom-protocol` is deprecated and `onerom-database` is unmaintained, and both now say so on crates.io.  `onerom-protocol` served the original STM32F4 One ROM Lab, which the current Fire-based Lab replaced; it also carries a `#![deprecated]` attribute, so a downstream consumer is warned at compile time rather than only in the README.  Neither is used by anything in the tree.
- GitHub releases no longer attach a base firmware binary.  The firmware Web and CLI build from is published to [images.onerom.org](https://images.onerom.org) and downloaded automatically; the attached copy was separately built and could differ from it.

To publish:
- Rust crates (in dependency order):
  - onerom-database 0.1.2
  - onerom-config 0.6.0
  - onerom-protocol 0.1.1
  - onerom-metadata 0.1.4
  - onerom-gen 0.7.0
  - onerom-fw-parser 0.8.0
  - onerom-fw 0.2.0
  - onerom-app 0.2.0
  - onerom-cli 0.3.0
- Config schema
- CLI bin 0.3.0
- Studio 0.2.1
- USB plugin 0.2.1
- RGB plugin 0.1.2
- host-control plugin 0.1.2
- RBCP spec 0.1.1
- WASM 0.5.0
- Site
- Release 0.7.1

## v0.7.0 - 2026-07-20

This release includes a significant rewrite of the One ROM firmware focusing on Fire boards.

The primary benefit of this firmware in the immediate term is more efficient use of flash for specific ROM types - in many cases, with the later board types, the amount of flash used to store a ROM image is the same as the ROM image size itself, unlike previous releases.

There is also a longer term benefit of reduced maintainability costs and also lower costs to add new ROM types in the future - meaning a better user experience.

Ice boards are capped at firmware v0.6.xx (and are not supported in v0.7.0+).  The programming tools continue to support Ice boards and v0.6.xx.

TODO
- Figure out why status LED is off on v0.7.0

TO TEST
- All ROM types live
- Host control plugin

Retired:
- `lab` (and replaced by `onerom-lab`)
- `sdrr-check` (superceded by `onerom-fw-tester`)
- `sdrr-info` (superceded by the CLI `onerom firmware inspect` command)
- `sdrr-tester` (superceded by `onerom-lab`)
- `test` (superceded by `onerom-fw-tester`)
- Silent replacement of SST39SF040 with 27C040 for fire-32-a.  Decided it was best to flag this isn't natively supported.

New:
- `onerom-app` crate, containing functionality shared between One ROM user facing apps, like CLI, Studio and the Web UI (via onerom-wasm).

Updated:
- All Rust crates and programming tools
- plugins/system/usb
- plugins/user/host-control
- CI to perform comprehensive testing of the firmware, for all ROM types, and dynamically banked and multi-ROM sets, and PIO focused plugin API functions

Limitations:
- SRAM support (6116) is not currently supported by the v0.7.xx firmware train.  This limitation is expected to be lifted in future.
- One ROM Lens has not been tested with this release, and is likely broken.

## 2026-07-04

Release hardware design files for new variants:
- fire-24-f
- fire-28-c
- fire-32-b2
- fire-40-b

All of these new hardware designs are licensed under the [CERN Open Hardware Licence Version 2 - Weakly Reciprocal (CERN-OHL-W-2.0)](/LICENSE.md#cern-ohl-w-20-license).

All previous hardware designs are re-licensed under the [CERN Open Hardware Licence Version 2 - Weakly Reciprocal (CERN-OHL-W-2.0)](/LICENSE.md#cern-ohl-w-20-license).

## v0.6.14 - 2026-07-02

- Added support for fire-40-b and fire-24-f.
- Improved lab-new scripts.

## v0.6.13 - 2026-06-02

Added:
- Enhance lab-new to allow reading of any supported ROM type and single build supporting all One ROM sizes.
- HN62402 (128KBx16/256x8) support for fire-40-a.  Uses 512KB on flash.
- Support for prototypes fire-28-c and fire-32-b.
- SST39SF040 support (fire-32-b only).  Uses 512KB on flash.
- Firmware decoding support from

Fixed:
- 23C1010 support - there were failures when creating firmware with 23C1010.

## v0.6.12 - 2026-05-26

Added
- 27C100 as synonym of 27C301/27C1000.
- 39SF0x0 and 29x0x0 as synonyms of SST39SF0x0.
- Re-added 23QL384 as a new composite ROM type.  This serves both a 23256 and a 23128 ROM, as used in the Sinclair QL, with a single configured CS line (use active high for the Sinclair QL) and it is de-selected when A14 & A15 are both high.  It is required, in addition to the 23QL512, where other peripherals supply the top 16KB of the ROM space.  This ROm type may be useful for other systems.
- More aliases of th 27C400 ROM type.  Also corrected HN62404/24 as aliases of the 27C400, not the 27C040.
- More aliases of 2364 ROM type.

## v0.6.11 - 2026-05-14

Changed:
- Type 23QL384 ROM type has been replaced with 23QL512 (48KB->64KB) as the Sinclair QL supports up to 64KB ROMs.  When flashing a 48KB ROM (for example a Minerva ROM), use the additional slot option `size=pad` to pad a 48KB ROM to a 64KB one. 

## v0.6.10 - 2026-05-12

Added:
- Support _protoype_ support for a new composite ROM type, the 23QL384.  This serves both a 23256 and a 23128 ROM, as used in the Sinclair QL, with a single configured CS line (use active high for the Sinclair QL) and it is de-selected when A14 & A15 are both high.  It may be useful for other systems.  This ROM type may be deprecated or modified in a future release.

Fixed:
- Added longer filtering/debounce support for knock detection, to work more reliably on different Commodore 64s.

## v0.6.9 - 2026-05-08

This release introduces support for the [ROM Bus Control Protocol](https://github.com/piersfinlayson/rom-bus-control-protocol) (RBCP), which allows retro systems to interact with and control One ROM directly.  This allows advanced functionality driven by the retro system, such as

- ROM based bootloaders (think `grub` for the C64)
- Dynamic ROM patching for games, demos and other applications
- Remote debugging of code running on real retro systems

This support is implemented using the new `user/host-control` plugin, which is an implementation of v0.1.0 of the ROM Bus Control Protocol.

This version of the plugin and core firmware focuses on enabling RBCP for 2364 ROMs, including 2364/2364/2332 multi-ROM sets, like those used in the C64 to serve all of basic, kernal and character ROMs from a single One ROM 24.  Support for other ROM types and configurations is expected in future releases.

In order to support this functionality, this release also includes a number of other changes, including a substantial number of new plugin API functions.  Noteworthy additions include functions to:
- collect addresses read by the host and detect "knocks" (a specific sequence of address reads) on behalf of the plugin.
- populate and switch to additional backup RAM "slots" allowing dynamic, atomic switching between ROM images.
- allow co-operation between plugins, to allow one plugin to suspend the other, in order to perform operations that might interfere with the other plugin's operation, such as flash erasing/writing.

It is believed that no non-backwards compatible changes to the plugin API have been introduced in this release, so plugins developed to older versions of the firmware should still work.  This includes the system/usb plugin.  However, there remain no guarantees of backwards compatibility for the plugin API in future releases, so if you are developing a plugin, please keep an eye on this changelog for any changes that might impact your plugin.

Also added:
- 2364, 2732, 2716, 2708 and 2704 support on One ROM 28 boards.  Important notes:
  - One ROM 28's pin 28 or the 5V header pin MUST be supplied 5V when using to emulate these 24 pin ROM types.  Failure to do this is likely to damage One ROM.
  - If your system expects a 24 pin ROM of one of these types and provides a 28 pin socket, you can probably install a 28 pin One ROM as is.  Double check pin 28 supplies 5V.
  - If you want to use a One ROM 28 in a 24 pin socket as one of these ROM types, you must install One ROM 28's pins 3-26 in that socket, with pin 3 of One ROM in the socket's pin 1 (i.e. install the "bottom" of the One ROM in the 24 pin socket, leaving the top two rows of pins overhanging the top of the socket).  You MUST supply pin 28 with 5V, either via pin 28, or via the 5V header pin.  Failure to do this is likely to damage your One ROM.
  - When emulating a 2704 or 2708 you MUST ensure that any -5V, -12V or +12V (or any voltages other that +5V) are NOT supplied to One ROM.  This can be achieved by cutting traces on the system's PCB, or not populating (or de-populating) the appropriate One ROM pins.
  - This support was tested as follows:
    - Both test and test-pio scenarios for all these ROM types have been added to CI and pass.
    - 2364 support was tested in a C64 breadbin as the kernal ROM.
    - 2732/2716 were tested in a T48 EPROM reader (with Pin Detect disabled).
    - 2708/2704 are untested, as the T48 doesn't support these types.  The 2704/2708 support is very similar to the 2716 support, so is expected to work, but please report any issues if you try it.

## v0.6.8 - 2026-04-02

- One ROM Fire - Add read support for 28C16 (24), 28C64 (28), 28C256 (28) and 28C512 (32) EEPROMs (#169).  These have all been live tested.

- Re-instate 27C080 support, supported by the 32 pin One ROM.  This only supports half the total 1MB image with a single One ROM, but two can be stacked and configured high/low to support the full 1MB.  This support has been live tested.

- Added support for 23C1010 mask programmed ROM (which is effectively a 27C010).

- Prevent CPU serve mode from being selected for One ROM 28/32/40 (as they only support PIO serving).  It can still be configured on One ROM Fire 24, but not any other Fire version.  This is mainly useful for fire-24-a and fire-24-b which don't support PIO serving for multi-ROM sets.

- Moved PCB files to hardware/pcb.

- Uploaded STL files for 3D printable One ROM cases.

## v0.6.7 - 2026-03-26

The three headlines in this release are **prototype** support for:

- One ROM CLI - a command line tool for interacting with new and old One ROM Fire devices over USB
- a "live" USB stack running the picoboot protocol live while the One ROM is serving ROM bytes
- One ROM plugins, used to extend One ROM's core functionality (and is how the new USB support is implemented)

Feedback is welcome on any of these features, and anything else One ROM does, or could do via GitHub discussions and issues!

### One ROM CLI

The [One ROM CLI](https://onerom.org/cli) is a command line tool for managing One ROM Fire devices over USB, and it aims to combine power and ease of use.

It supports all One ROM Fire devices over USB, including those using the new live USB stack, and those that predated this support.

Supported operations include:
- Scanning for all connected One ROM Fires over USB
- Building One ROM firmware
- Programming One ROM
- Inspecting One ROMs and firmware files
- Read/write access to One ROM's flash and RAM over USB
- Live reading and writing of the ROM One ROM is currently serving ("live" USB plugin only)

### Live USB Stack

This release adds **prototype** USB support **while One ROM is serving bytes**.  It no longer drops into BOOTSEL/programming mode when USB is connected.  The USB stack primarily exposes a vendor class interface, implementing Raspberry Pi's PICOBOOT protocol, the same protocol used by picotool to manage and control an RP2350 in BOOTSEL mode.

This allows you to use the following tools to perform RAM and flash operations on One ROM while One ROM is serving bytes:

- [One ROM CLI](https://onerom.org/cli) - Comprehensive command line tool for managing One ROM Fire devices over USB.
- `picotool` - Raspberry Pi's command line tool for managing RP2350 devices in BOOTSEL mode.  It can be used to read and write flash and RAM, and to reset the device.
- [pico⚡flash](https://picoflash.org) - a WebUSB PICOBOOT implementation offering the same primary primitives as picotool.

Some notes on this support:

- The plugin must be explicitly included in the config.  You can do this with a JSON config file One ROM Studio and the CLI, or, most easily with the `--plugin usb` flag when using the CLI to build firmware or program One ROM.

- There is currently no guarantee that the USB interface will be stable or remain the same in future releases.  In fact, the USB stack, as a plugin, has its own versioning and release train, may change VID/PID (the current value of 1209:f542 has not yet been approved by pid.codes).

- SRAM is directly available via PICOBOOT at 0x2000_0000.  The ROM image being served is located at this address.  However, both address bytes and data bits are mangled for ROM serving.  A "logical" image of the ROM being served is available for reading **and writing** live at 0x9000_0000.  For example, for an 8KB 2364 ROM, the actualy ROM image byte 0 is available at 0x9000_0000, byte 1 at 0x9000_0001, etc.  This allows reading **and changing** the ROM image almost instantly at runtime.  Bytes are updated in the ROM image being served in the order they come in over the PICOBOOT protocol.

  - `picotool` has a limitation that it does not support reading/writing addresses that it thinks are invalid, such as 0x9000_0000.  You will probably need to use picoflash for the time being if you don't want to use One ROM tools.

- Flash erase is **not** supported in this release.  While the ROM byte serving is entirely autonomous, erasing the flash that the plugins execute from would cause the MCU cores to fault, and break the USB stack.  Some thought needs to be applied before implementing live flash erase (and hence flash write).

- Reprogramming the image(s) stored on flash is currently only supported as part of a full firmware update, which causes One ROM to stop serving bytes while it is updated.  Updatig stored ROM images on flash is expected in a future release.

- The USB stack includes a CDC interface, which is currently unused, but may be used in the future for debugging, logging and other purposes.

- More USB functionality is expected in future releases - including live flash erase/writing, controling the image select pins (for example, to drive external devices).

### Plugins

This release adds **prototype** support for One ROM plugins, which are custom binary modules, separately built and then added to One ROM's configuration.  One ROM executes the plugins once ROM serving has been started.

Plugins can provide a massive variety of functionality and are hugely flexible - as they are effectively full microprocessor firmware in their own right.

While the RAM available to plugins varies between copious and extremely limited depending on the One ROM model, a plugin gets a full RP2350 core at its disposal, clocked at the current RP2350 clock speed, and full hardware access.  With great power comes great responsibility, and plugins can interfere with ROM serving if they do not avoid operations that might conflict - in particularly PIO/DMA operations and GPIO usage.

There is currently **no** guarantee of the [One ROM plugin API](sdrr/ora/api.h) remaining backwards compatible in any future One ROM release.  However, the general plugin concept is expected to be here to stay.

Limited stack space and static RAM is available to each plugin type - each core is allocated 1KB of stack, including the stack used to launch the plugin.  The system stack gets static RAM in addition to this whereas the user plugin has to allocate static RAM out of its 1KB stack.  There is no policing of the stack, nor any other sandboxes of plugins.

The only supported IRQs for plugins in this release are TIMER0_IRQ_0 and USBCTRL_IRQ, both of which are used by the USB system plugin.

A future concept of PIO plugin is under consideration, which would allow an optional third plugin type which would replace the main firmware's loading of its PIO and DMA byte serving algorithm - allowing the plugin to substitue its own.  This could be combined with a custom user (or system) plugin with the two operating in tandem to provide some very powerful capabilities.

### Other Changes

- A new version of [One ROM Lab](rust/lab-new/README.md) has been started and is used to test One ROM Fire 40 boards prior to shipping.  This is expected to replace other testers soon, and completely supercede the old version of One ROM Lab over time.

- Introduced fire-24-eadb01 as a possibly temporary workaround for a single fire-24-e board, as featured on Adrian's Digital Basement.  Do not rely on this hardware version, as it may be removed without warning in future.

### Fixes

- Disabling the status LED using firmware overrides didn't work for CPU serving mode for fire-24-a and fire-24-usb-b.  This has been fixed.

## v0.6.6 - 2026-02-25

The headline for this release is "bug fixes and other improvements".

There are also a significant number of fixes and improvements to the remainder of the One ROM fold, including some changes to existing behaviour, listed first:

- Improved regular (not 16 bit forced) /BYTE serving algorithm for 40 pin ROM, #153.

  This algorithm is marginally slower than previously but more robust.  If a faster algorithm is required, sacrifice /BYTE low handling with firmware_overrides->fire->force_16_bit = true in the ROM config.

- Resolved deficiencies in fire-24-a and fire-24-b PIO serving modes, #94.  All function is now supported on these boards, except for dynamic bank switching, which will likely remain unimplemented on these boards due to the lack of contiguity between X1/X2 and the CS pins.

  As a result fire-24-a and fire-24-b now default to PIO serving.  If CPU is desired (for example, for dynamic bank switching support), use firmware_overrides in the JSON config file.

- Changed default HW_REV/MCU in Makefile to fire-24-e/rp2350 (from ice-24-f/f401rc).  This only impacts using the old style `make` builds, not `scripts/onerom.sh` builds.

- All supported ROM types and CS configurations are now fully PIO tested as part of automated (CI) regression testing, for all Fire hardware revisions, #149.

- Fixed support for 2 ROM multi-ROM sets, for Fire boards in PIO mode, #110.  This impacted all Fire revisions in PIO mode - in particular the provided 1541 multi-ROM config did not work (and now does). 

- Forced unused address lines to appear driven low to the MCU for appropriate ROM types, to fix #154.

  This probably doesn't have any external impact, but if so it would be to 27 series ROMs and/or 2 set multi-ROM sets (24 pin only).  All supported 27 series ROM types have been tested manually with this change, as has 2 ROM multi-ROM sets on 24 pin boards.

- Implemented 2704 and 2708 ROM support on all existing Ice and Fire 24 pin boards, #156.

  2704/2708 support was tested on a T48 EPROM reader (with Pin Detect disabled), as a 2716 (as the T48 software doesn't support 2704/2708).  The 2704 image was correctly duplicaetd 4 times in the 2716 space and the 2708 twice.  Support for 2704/2708/2716 and 2732 was tested on fire-24-a and fire-24-e, both with PIO serving, and ice-24-j.

- This releases adds _prototype_ support for One ROM 32 #131 including:
  - Hardware revision fire-32-a
  - EPROM types 27C010, 27C020, 27C040 and 27C301
  - Support for 27C080 is included allowing two physically stacked One ROMs to be configured, each to serve half of the 27C080.  The one serving the lower 512KB should have cs1 set active low and the other one should have cs1 active high in their respective ROM configs.
  This support has been tested using the PIO emulator, but has not been tested with real hardware.  It is expected that bug fixes will be required when testing is done with real hardware, and One ROM 32 will be formally supported in a later release.

## v0.6.5 - 2026-02-22

The big new feature in this release is support for One ROM 40, hardware revision fire-40-a.  This emulates a 27C400 found in the Amiga A500, and other 16-bit systems.  I have successfully tested it on my Amiga, serving Kickstart ROM 1.3 and [DiagROMV2](https://www.diagrom.com/).

One ROM Lens is also included.  This is a web-based tool that runs the real One ROM serving algorithm within your web browser using a cycle exact PIO emulator.  It emulates One ROM's operation, allowing you to inspecting the GPIOs on a cycle by cycle basis using the logic analyzer style interface.  This is a great tool for understanding how One ROM (or any parallel ROM) works, for debugging firmware issues and interatively testing algorithm changes. To use, there are two steps:

1. Build the One ROM firmware, using an "old-style" config, with the emulated hardware type and image you want One ROM to serve: e.g. `HW_REV=fire-40-a MCU=rp2350 CONFIG=old-config/test/40-random.mk make`.
2. Build and run One ROM Lens: `make -C sdrr -f lens.mk serve`.

    Then point a browser at http://localhost:8000/index.html.

    It is likely that simpler commands will be added to the future to make this easier.

This release also introduces extensive automated regression testing for the Fire PIO serving algorithm (#134), for 24 and 28 pin boards.  As a result, a number of Fire PIO serving bugs have been fixed, including #110 and #94.

## v0.6.4 - 2026-02-07

- Fixed [#133](https://github.com/piersfinlayson/one-rom/issues/133), a complex issue where Studio v0.10 and earlier fail to build 28 pin v0.6.3 firmware images correctly.  This stemmed from 0.6.3 incorrectly including a non-backwards compatible change in order to support 231024 ROM types. As part of this:
  - v0.6.4 reverts that non-backwards compatible change, but retains 231024 support.  Specifically non-231204 ROM images use 64KB on flash, with only 231024 requiring 256KB.
  - v0.6.4 also introduces checking that the ROM image type is as expected and enters limp mode if not - rather than pretending to be OK and serving garbage.
  - Studio has been enhanced so it can be configured at runtime (via the manifest) with a maximum firmware version it can support - which overrides onerom-gen's maximum version, if the version Studio is allowed to build is lower.  Had this been in place earlier it could have been used to prevent pre-v0.1.11 version of Studio building bugged v0.6.3 firmwares, when #133 was found.

## v0.6.3 - 2026-02-03

- Added 231024 mask programmed ROM support.  Used by BBC Master and Apple IIgs.  (Only tested on BBC Master.)
- Add some Studio keyboard shortcuts (r for rescan, f for flash).

## v0.6.2 - 2026-01-27

This release of One ROM introduces RAM support - for 6116 and 2016 2KB 24-pin static RAM chips, using Fire 24 C and onwards hardware revisions.

For a demonstation of RAM support, and an explanation of how it works, see: https://youtu.be/o7dMY6p6OJU

One ROM's JSON [config file format](onerom-config/README.md) now uses "chip_sets" instead of "rom_sets" and "chips" instead of "roms".  However, the old strings will continue to work for backwards compatibility.

Other changes:
- The ability to execute the main loop from RAM has been removed, to allow 512KB to be used for ROM RAM image on RP2350.  It would be possible to add this back where the image size to be held in RAM is under 512KB, and for Ice boards, but as executing from RAM is currently unused, it has been removed for now to save development and test effort.
- fire-24-e revision added as **unverified**.  This adds USB-C, and is intended for production quantities of Fire 24 - as it required JLC's standard assembly service to be used, rather than economic, due to the use of 0201 passives.  The MCU has also been changed to the RP235A, to take advantage of the on-board flash, saving on cost (and space).
- Rename directories `config/` -> `old-config` and `rom-config` -> `onerom-config`.
- The new recommended by to build One ROM firmware is using [`scripts/onerom.sh`](scripts/onerom.sh).  This builds an empty firmware image, adds the chip metadata, and adds the ROM/RAM images in one command.  It even flashes the firmware if desired.  Images are output to [`builds/fw`](builds/fw).

## v0.6.1 - 2026-01-22

### Added

- Prototype RAM support for 24 pin RAM chips, which use the same pin-out as the 6116/2016 RAM.  See PR #98 and discussion #70. Requires building from command line using make and EXTRA_C_FLAGS=-DONE_RAM
- Support for Fire boards (fire-24-d specifically) to use image select pins that are shared with SWD pins.  Note that this means that having an SWD programmer connected at boot will tend to change the image select value to an unexpected one, as the pins will be pulled by the programmer.  In v0.6.0 only 2 image select jumpers were supported on fire-24-d.
- Support for Ice boards (ice-24-j specifically) to use image select pins that are shared with SWD pins.  Note that this means that having an SWD programmer connected at boot may change the image select value to an unexpected one, as the pins will be pulled by the programmer.  In v0.6.0 only 2 image select jumpers were supported on ice-24-j.  Also, unlike the Fire boards, the ice-24-j (and similar) boards will disconnect from the debug probe during boot because of this function, so reconnecting will be necessary.
- Check in Studio/onerom-gen that firmware version is not too new (next major release) when building firmware images.
- Promote fire-24-d and ice-24-j to verified hardware revisions.

### Fixed

- Fixed #90 in v0.6.0 when older (pre v0.1.8) versions of One ROM Studio are used to build firmware images with more than one ROM set, One ROM will not boot on any ROM set other than ROM set 0.
- 2732 ROM type serving was broken - the top 2K replicated the bottom 2K.  Fixed (#103).  This included fixing the testing, which had also not caught this issue.

### Fixed

- 2732 ROM type serving was broken - the top 2K replicated the bottom 2K.  Fixed (#103).  This included fixing the testing, which had also not caught this issue.

## v0.6.0 - 2026-01-14

**EXPERIMENTAL RELEASE** - may contain bugs, use with caution.  If you hit problems, report them as issues and revert to v0.5.10 or earlier.  See [#87](https://github.com/piersfinlayson/one-rom/pull/87) for details of testing done.

This major release of the One ROM firmware adds support for low-level One ROM firmware configuration from the ROM config files, allowing per-ROM image configuration of processor clock speed, status LED behaviour, and other low-level capabilities from One ROM Studio, and other tools.

As a major firmware release, there are some non-backwards compatible changes in this release:

- The ROM config JSON schema has changed - `sel_jumper_pull` is now a Vec<u8>, to allow per-pin SEL jumper pull direction.
- The default PIO configuration is now SLOW_CHAR_CHAR, to improve ROM serving compatibility.  PIO configuration can be overriden on a per ROM set basis using `serve_alg_params` firmware overrides.

### Added

- Support for per-ROM image low-level configuration, including processor clock speed, status LED behaviour, and other low-level capabilities.  See the ROM Config [README](rom-config/README.md) for details.
- Support for fire-24-d and ice-24-j hardware revisions.
- Enhanced onerom-fw CLI tool to receive a local firmware file.
- One ROM Studio v0.1.8.
- Firmware v0.6.0.

### Changed

- ROM config JSON schema change - `sel_jumper_pull` is now a Vec<u8>, to allow per-pin SEL jumper pull direction.
- PIO support is now built into all RP2350 firmwares, and is enabled/disabled by default using RP_PIO build flag.
- RP2350 no longer enters filesystem mode when USB connected - only PICOBOOT protocol supported.

### Known Limitations

- The firmware does not support image select pins shared with SWD pins.  At present image select pins shared with SWD pins are ignored.
  - This is expected to be added in a future release.
  - It is relevant for `fire-24-d` and `ice-24-j` hardware revisions.
  In additon, the configurable per-pin jumper sel behaviour has not been explicitly tested.
- `swd_enabled`: false is not yet functional.  (It is not clear that this is a good idea anyway, as it would make a non-USB board more difficult to reprogram.)  This setting may be removed in a future release.

## v0.5.10 - 2026-01-03

Promote fire-24-c to verified and recommended 24-pin Fire version.

### Added

- issue #77 - Support for serving multi-ROM sets using Fire PIO algorithm.
- ROM types for 32 and 40 pin ROMs

### Changed

- issue #78 - Move RAM ROM image to 0x2000_0000 to prepare for 40 pin versions.

### Fixes

- issue #76 - fire-24-c PIO algorithm fixes.

## v0.5.9 - 2026-01-01

This release adds new One ROM hardware revisions and ROM type support.

### Added

- 231024 (28 pin) ROM type support.
- Hardware revision ice-24-i - Combined Pro (SWD) and USB 24 pin Ice version.
- Hardware revision fire-24-c - Combined Pro (SWD) and USB 24 pin Fire version.
- Hardware revisions fire-28-a2 and fire-28-a3 - Combined Pro (SWD) and USB 28 pin Fire versions.

### Crates

- onerom-config 0.2.5, 0.2.6
- onerom-fw 0.1.5, 0.1.6
- onerom-gen 0.2.3, 0.2.4
- sdrr-fw-parser 0.5.7, 0.5.8

## v0.5.8 - 2025-12-12

This release adds 28 pin ROM support for the new One ROM Fire 28-pin version, fire-28-a.

### Added

- Support for 28 pin ROM types using fire-28-a.  23128 has been tested in a C64C. with 2764, 27128, 27256 and 27512 tested in an EEPROM reader.  It is STRONGLY recommended NOT to use an EEPROM reader to read One ROM, as it may apply 12V to pin A9.

## v0.5.7 - 2025-12-09

### Fixed

- Erroneous CE/OE pin numbers for 2716/2732 ROMs.

## v0.5.6 - 2025-12-09

### Added

- Support for 2716/2732 ROMs (2716 tested).
- PIO support for 2316/2716/2732 ROMs (untested)
- Studio 0.1.4

### Fixed

- Comment in Makefile - B is now default serving algorithm.

## v0.5.5 - 2025-11-18

This release adds support for the RP2350 One ROM serving ROMs using the RP2350's PIO/DIO peripheral, allowing fully autonomous ROM serving without any CPU involvement.  A VIC-20 kernal can be served successfully with the RP2350 clocked at just 22MHz, the C64 kernal at 41MHz and the both systems' character ROMs at 51MHz.  There are some limitations, meaning this is not yet the default Fire algorithm:
- Dynamically bank switched ROMs _are_ supported.
- Only CS lines which are contiguous are supported - hence the 2316 is _not_ supported on either rev A or USB rev B.
- Multi-ROM sets, via X1/X2, are _not_ supported, as they are not contiguous with the CS lines in current hardware.

For full support a hardware revision must order the CS lines contiguously either:
- X2/X1/CS1/A12/A11 or
- A11/A12/CS1/X1/X2

To build use `EXTRA_C_FLAGS=-DRP_PIO` when running `make`.  See `sdrr/src/piorom.c` for further details of the PIO/DMA algorithm, and configuration options.

### Fixed

- Enabled FP extensions on both Ice and Fire to avoid hard fault if floating point instructions are used by the compiler.

## v0.5.4 - 2025-11-12

This release adds support for the One ROM Fire (RP2350) USB version, via hardware revision `fire-24-usb-b`.  Current USB support is per Ice - plugging in USB disables ROM serving, and puts the RP2350 into DFU mode to allow firmware updates.  A future release is expected to add Fire USB support in parallel to ROM serving. 

### Added

- Added first RP2350 USB version, [Fire 24 USB B](sdrr-pcb/unverified/fire-24-24-b/README.md), as unverified.
- Added [Ice 24 USB H3](sdrr-pcb/unverified/one-rom-ice-usb-h3-24-pin/README.md) as unverified.
- Moved [Ice 24 USB H2](sdrr-pcb/verified/one-rom-ice-usb-h2-24-pin/README.md) to verified.

### Added

- `onerom-config` 0.2.2 - Added method to query ROM power pins.
- Studio:
    - See [rust/studio/CHANGELOG.md](rust/studio/CHANGELOG.md) for details.
    - Studio is released independently of firmware - see `studio-*` github tags.
- ROM Configs:
    - Blank ROM config (for manufacturing/testing) - /rom-configs/blank.json
    - Added pincoder 2021 version system 3, 5, 6 and 7 ROM configs (2332 ROMs)
- Allow `sdrr-fw-parser` to parse up to v0.5.999 firmware versions. 

### Fixes

- [#43](https://github.com/piersfinlayson/one-rom/issues/43) - Let sdrr-fw-parser parse later versions of fw. Supports up to v0.5.999 with no code/wasm/site changes required.
- Allow multi-ROM sets to be built in One ROM Studio.  Unsure when this was regressed

## v0.5.3 - 2025-10-24

The major addition in this release is the companion desktop application, One ROM Studio, which provides a native GUI for creating One ROM firmware images, and analysing and flashing One ROM devices.

One ROM Studio on Windows

Features include:
- Supported platforms: Windows, Mac, Linux (Ubuntu, Debian and Raspberry Pi OS)
- Supported One ROMs: all variants including Ice/Fire and Pro/USB
- Program One ROMs with a choice of ROM images
- Generate and save One ROM firmware files
- Analyse One ROM devices and firmware files
- Automatic debug probe and One ROM USB detection

One ROM Studio can be downloaded from https://onerom.org/studio/.

### Added

- Added "limp mode" support to detect when an incompatible firmware has been flashed to an Ice One ROM.  It blinks fast in this state and, if it is a USB model, allows the device to drop into DFU mode when USB is connected, to allow flashing of a compatible firmware.  Note that "slower" MCU firmwares are permitted by "faster" MCUs - but not the other way around.  See #37 for details.

### Fixes

## v0.5.2 - 2025-10-14

New in this release is a command line firmware image creation tool `rust/fw`.  This dynamically creates a custom One ROM firmware image from a specified:
- set of ROM images (specified as a JSON config file)
- model, board and MCU type (specified as command line arguments)
- optional firmware version (defaults to the latest version available)

To build:
```bash
cd rust/fw
cargo build --release --bin onerom-fw
# Binary is located at /rust/target/release/onerom-fw
```

This is a precursor to simplifying the CI builds to avoid having to create every combination of hardware/ROM config as build artifacts.  The hardware combinations can be pre-built with empty metadata and ROM image data, and this tool then composes a complete firmware image, ready for flashing.

As v0.5.1, and empty firmware image can also be flashed - One ROM then blinks its status LED slowly, and can have metadata and ROM images flashed to it later.

The complete list of available "empty" hardware configuration firmwares can be found at https://images.onerom.org/releases.json.

This command line tool may also be augmented with a native GUI, in parallel to the web-based tool at https://onerom.org/prog/.

### Changes

- Improved `onerom-gen` testing, and improved `onerom-config` and `onerom-gen` validation.

### Fixes

- Fix rust/gen/tests for boards with address lines all >=8.
- Fix `sdrr-info` processing of firmware from v0.5.1 onwards with detailed metadata content in a valid, but unexpected, order.

## v0.5.1 - 2025-10-13

For the average user, there are no particularly notable changes in this release, except the addition of the [Atari 800XL BASIC ROM config](/config/atari800xl.mk).

The firmware generator process underwent a major overhaul in this release:
- Support ROM types and hardware (PCB) revisions are now parsed at build time, which can be included in Web Assembly code.
- `sdrr-common` has been retired and mostly replaced with `onerom-config`
- Much of `sdrr-gen` has been moved out to `onerom-gen` crate, which can be used in other Rust projects, including Web Assembly.
- There is a new `onerom-wasm` crate at https://github.com/piersfinlayson/one-rom-wasm, which can be used to build Web Assembly code to generate One ROM firmware images in the browser.  Web Assembly packages, documentation and examples are located at https://wasm.onerom.org/.
- A metadata and ROM-less firmware can be built with `EXCLUDE_METADATA=1`.  When flashed with ths firmware, One ROM blinks its status LED slowly.  It can subsequently have metadata and ROM image fragments flashed, and, when reset, serves the newly flashed images.  This is expected to be useful for release artifacts and manufacturing, as a single firmware per hardware variant per release can be built, with metadata and ROM images added later, rather than the current need to build a firmware per hardware variant **per configuration** per release.

There is more work planned to the firmware upgrade process, including multi-stage USB device updates using the new capabilities, but this release has laid the groundwork and enabled some exciting new web-based features.

Also, the first, prototype 28 pin ROM support using hardware revision `ice-28-a` is in this release.  It successfully emulates a 27128 ROM (i.e. without the 3rd CS line on a 23128).  It has been tested successfully on a C64C, replacing the combined KERNAL/BASIC ROM with a One ROM Ice 28 A, clocked at just 55MHz using an STM32F446RCT6. This hardware revision is unlikely to be taken forwards - a different hardware layout is required to support 23128 with the 3rd CS line being used, as well as 32KB and 64KB ROMs.

Some default firmware configuration has been changed:
- BOOT_LOGGING is now disabled by default to improve boot times.

### New

- [Atari 800XL BASIC ROM config](/config/atari800xl.mk) included (and tested and working!)

### Changes

- Call out from sdrr-gen to wget to retrieve images located on sourceforge, as cloudfare seems to spot and block Rust TLS.
- Moved the PCB config/property files from `/hw-config` to `/rust/config/json`.

### Fixes

- Make "no ROMs installed" LED blink pattern slower, to be more visible.  Now on for 0.5s, off for 2.5s.  Previously flashed much too fast to be used properly.

## v0.5.0 - 2025-10-07

This release adds a bunch of hardware revisions, plus a modified flash and firmware format, to ease future device re-programming.

As a consequence of the new flash/firmware format, some of the STM32 variants (F401RB/RC, F411RC, F446RC) support 2 fewer ROM images than before.

### New

- New flash/firmware format, with firmware code, followed by ROM metadata, followed by ROM images. 
- Added One ROM Ice USB H2 (unverified).
- Added One Rom Ice USB H (verified) kicad files.
- Added One ROM Fire USB B (unverified)

### Changes

Moved USB programmer site to https://github.com/piersfinlayson/one-rom-site repo.

## v0.4.4 - 2025-09-30

This is a point release that changes the release artifact generation, to set up the One ROM USB programmer to be able to offer to flash pre-built firmware images from the release artifacts.

Release artifact change summary:
- Include additional hardware variants
- Only include .bin files (not .elf, .dis, .map) in the release artifacts.
- Remove some of the less common STM32 variants from the release artifacts (to save build time and space)
- Include a build artifact manifest JSON file. 

If the particular release artifact you want is no longer included, you can build it yourself from source.

### Changes

Updated:
- USB One ROM site (onerom.piers.rocks):
  - Added the ability to select a local file as the firmware source, in addition to a URL.
  - Add check to prevent non-USB firmware being flashed.
  - Add check to ensure the MCU the firmware was build for matches the MCU the user selected.
- CI build process, to create release artifacts:
  - Now only creates .bin files (not .elf, .dis, .map) - if you want the other types, build them yourself.
  - Creates images for multiple different hardware revisions.

## v0.4.3 - 2025-09-29

Added USB DFU support for firmware updates over USB, along with STM32 24-pin rev H hardware (24-h) which includes a micro-USB connector.  One ROM detects when USB is connected, disables ROM serving, and enters STM32 DFU mode to allow the firmware to be updated.

There is also a new web-based programmer for One ROM USB, at https://onerom.piers.rocks/.  This can be used on Chrome or Chromium based browsers on Windows, Linux, or MacOS to program an attached One ROM USB.

### Changes

Updated:
- sdrr
- sdrr-hw-config
- sdrr-pcb
- sdrr-common
- sdrr-fw-parser
- sdrr-gen
- sdrr-info

### Fixes

## v0.4.2 - 2025-09-06

Added [One ROM Lab](rust/lab/README.md) support, which allows a One ROM to be used as a ROM reader.

### Changes

- Added fw-parser for One ROM Lab
- Modify sdrr-info/parser to support Airfrog custom firmware changes

### Fixes

- Probably a few here and there.

## v0.4.1 - 2025-08-28

### Changes

- Move STM32F4 hardware rev G to verified.
- Add KiCad design files for RP2350 rev A and STM32F4 rev G.

### Fixes

- #8 - reduce severity of VOS not ready warning, as it appears to be benign.
- Include RP2350 images in github release.
- Add RP2350 build commands to README.md and generally update the docs to refer to One ROM/RP2350.

## v0.4.0 - 2025-08-24

**The RP2350 release.**

This version contains the first RP2350 PCB revision, and mostly complete firmware support.

Should you use the new RP2350 hardware revision A?  Only limited testing of the RP2350 One ROM has been done so far, but it has generally performed well.

There is one outstanding, known issue - when using the RP2350 One ROM a character ROM on a PAL VIC-20 occasionally the machine boots to a black screen background - that is the machine boots to BASIC and shows the expected text, but the screen is black, not white.  This may be a boot timing issue - that perhaps One ROM RP2350 is not booting fast enough for the VIC chip, which is getting corrupted somehow.  This issue does not appear on a C64 (which has a different video bus architecture).

You may want to order and test small quantities of RP2350 based boards for now, as there is some risk of a hardware design issue coming to light.  However, the hardware appears solid in early testing, so it is likely most issues can be overcome by firmware changes - and it is expected that the RP2350 revision A will continue to be supported in future releases, even should another variant be released.

Other notable changes:

- Instead of building with `STM=<mcu variant> make`, you now need to use `MCU`:

  ```bash
  MCU=<mcu_variant> make
  ```

### Changes

- Added RP2350 support.
  - Hardware rev A.
  - Includes single ROM images, dynamically bank switched, and multi-ROM sets.
  - Includes image select jumpers, status LED, overclocking.
  - Features not supported include: C main loop, MCO output.
  - For the gory details of supporting the RP2350, see [RP2350](docs/RP2350.md).
- Added STM32F4 24-pin PCB rev G hardware configuration.  This adds a different programming header and one more image select jumper (so 5 in total, plus X1/2).
- Added hardware and firmware configuration to specify whether the image select jumpers and X1/X2 pins are pulled high or low when the PCB jumper is closed, to allow for different PCB designs.
- Added firmware support for up to 7 image select jumpers.
- Change STM32 MCO (and MCO2) divider to be /5 (previous value was /4).  Makes it easier to measure the clock speed of an overclocked STM32F4.
- Substantially refactored platform specific code to break out platform agnostic code - significant work to `sdrr/src/main.c`, `utils.c` and `rom_impl.c`.
- Tested overclocking and various STM32 clones.

### Fixes

- It is likely that the 4th image select pin on revs E/F didn't work properly - this has been fixed.

## v0.3.1 - 2025-08-16

The project has been renamed One ROM (To Rule Them All).

This release is a few odds and ends including some hardware improvements:
- One ROM hardware revision [F2](/sdrr-pcb/verified/stm32f4-24-pin-rev-f2/README.md) is currently recommended.
- An **unverified** hardware revision [G](/sdrr-pcb/unverified/stm32f4-24-pin-rev-g/README.md) is in testing.  This brings mostly layout improvements and slightly reduced manufacturing costs.
- The fastest STM32F4 MCU, the STM32F446 has been verified to work.   This brings a max supported clock speed of 180MHz, and has run stably up to 300MHz in testing.
- The STM32F405 has provided slower than expected (more details below).  It is supported and a decent choice, but the GigaDevices GD32F405 appears to be more performant.

### Changes

- Speed up STM32F405 support:
  - The STM32F405 is under-performant vs the other devices at the same clock speed - needs around 30-40% faster clock speed.
  - Added CCM RAM support for the F405, bringing the uplift in clock speed down to around 15-20%.
  - To disable CCM RAM set `C_EXTRA_FLAGS=-DDISABLE_CCM=1` when building.
  - The STM32F405 is still a decent MCU choice for One ROM, as its max clock speed is 168MHz compared with the F411's 100MHz.  However, users may wish to use the GigaDevices clone GD32F405, which appears to have no performance penalty. 
- Hardware revision 24-f2 is now verified.  JLC have successfully fabbed using the hardware files both STM32F411 and STM32F405 variants.
- Allow more aggressive overclocking (up to 400MHz).
- Validated STM32F446RCT6 (STM32F446RET6 highly likely to work as well).  Successfully tested as C64 char ROM, and verified clock speed of 180MHz (via MCO1 showing 45MHz = SYSCLK/4).  Also overclocked to 300MHz, ran stably.
- Added **unverified** hardware revision 24-g.

### Fixes

- Explicitly prevent COUNT_ROM_ACCESS and C_MAIN_LOOP being configured together, as they are incompatible.
- Fixed ability to run main loop from RAM (this tends to be slower than from flash, so isn't recommended).

## v0.3.0 - 2025-08-12

The main user facing change in this release is the addition of support for remote analysis and co-processing alongside the SDRR device via plug-ins, such as [Airfrog](https://piers.rocks/u/airfrog) - **a tiny $3 probe for ARM devices**.  This allows you to inspect the firmware and runtime state of the SDRR device, and change its configuration and ROM data - **while it is serving ROMs**.

There is also new ROM access counting feature, which causes SDRR to count how times the CS line(s) go active.  This can be extracted and visualised using [Airfrog](https://piers.rocks/u/airfrog) and other SWD probes, to determine how often the ROMs are accessed based on host activity.

ROM Access Graph

The Rust tooling has been substantially refactored to easier to integrate SDRR support in third-party tooling, such as [Airfrog](https://piers.rocks/u/airfrog).  In particular there is [Firmware Parser](rust/sdrr-fw-parser/README.md) crate, which can be used to parse the firmware from a file or running SDRR, and extract information about the configuration, ROM images, and to extract ROM images from the firmware.

### Changes

- TI-99/4A and CoCo2 configurations have been added to the [third-party configs](config/third-party/README.md) directory.  Thanks to [@keronian](https://github.com/keronian) for contributing these.
- Added a C main loop implementation for which GCC produces the assembly/machine code.  This requires a roughly 25% faster clock speed.  Use `EXTRA_C_FLAGS=-DC_MAIN_LOOP` when running `make` to use this version.
- Stored off image files used to create the firmware in `output/images/`.  This allows post build inspection of the images used.  It also enables additional tests - `sdrr-info` can be now be used as an additional automated check (along with `test`), to ensure the images in the firmware are correct, and validate the behaviour of `sdrr-info` and `test` to be compared.
- Substantial refactoring of `sdrr-gen`, to make it more maintainable.
- Substantial refactoring of `sdrr-fw-parser` in order to make it suitable for airfrog integration.
- Added ROM access counting behind COUNT_ROM_ACCESS feature flag.  When enabled, the firmware updates a u32 counter at RAM address 0x20000008 every time the chip select line(s) go active - i.e. the ROM is selected.  This can be read by an SWD probe, such as [Airfrog](https://piers.rocks/u/sdrr). 
- Changed default Makefile configuration to HW_REV=24-f COUNT_ROM_ACCESS=1 STATUS_LED=1.
- Added a manufacturing test tool [`sdrr-check`](rust/sdrr-check/README.md).
- Changed default build config:
  - HW_REV=24-f
  - STATUS_LED=1
  - COUNT_ROM_ACCESS=1
- Added retrieval of mangled ROM images from firmware.  This can be used to compare the embedded images between different firmwares and to collect a pre-mangled ROM images in order to overwrite a running SDRR's RAM image with it.
- Added new "One ROM To Rule Them All" BASIC program for upcoming video. 

### Fixes

- Probably a few here and there.

## v0.2.1 - 2025-07-22

The main new feature in this version of SDRR is the addition of dynamic [bank switching](docs/MULTI-ROM-SETS.md#dynamic-bank-switching) of ROM images.  This allows SDRR to hold up to 4 different ROM images in RAM, and to switch between them **while the host is running** by using the X1/X2 pins (hardware revision F and later) to switch between them.  Some fun [C64](config/bank-c64-char-fun.mk) and [VIC-20](config/bank-vic20-char-fun.mk) character ROM configurations that support bank switching are included.

In other news:
- The default ROM serving algorithm has been improved, leading to better performance, and hence the ability to support more systems with lower powered STM32F4 devices than before.  Check out [STM32 Selection](docs/STM32-SELECTION.md). The current price/performance sweet spot is the F411.
- [Hardware revision E](sdrr-pcb/verified/stm32f4-24-pin-rev-e/README.md) is now fully verified, so manufacture these with confidence.
- If you'd rather use [revision F](sdrr-pcb/unverified/stm32f4-24-pin-rev-f/README.md) (required for multi-ROM and bank switching support), at least once user has reported getting these manufactured and working with his NTSC VIC-20 - although they did not testing either multi-ROM or bank switching support.

### Changes

- Added pull-up/downs to X1/X2 in multi-ROM cases, so that when a multi-set ROM is configured, but X1/X2 are not connected, the other ROMs in the set still serve properly.
- Improved serving algorithm `B` in the CS active low case.
- Moved to algorithm `B` by default.
- Measured performance of both algorithm on all targets.
- Refactor `rom_impl.c`, breaking out assembly code to `rom_asm.h` to make the main_loop easier to read, and commonalising a bunch of the code for greater maintainability.
- Added detection of hardware reported STM32F4 device and flash size at runtime, and comparison to firmware values - warning logs are produced in event of a mismatch.
- Verified [hw revision e](/sdrr-pcb/verified/stm32f4-24-pin-rev-e/) - supports STM32F4x5 variants in addition to F401/F411, all passives are now 0603, contains a status LED and a 4th image select jumper.
- Added [documentation](/docs/STM32-CLONES.md) on STM32 clones.
- Moved firmware parsing to [`rust/sdrr-fw-parser`](/rust/sdrr-fw-parser/README.md) crate, which can be used to parse the firmware and extract information about the configuration, ROM images, and to extract ROM images from the firmware.  Done in preparation for using the same code from a separate MCU.
- Moved Rust code to [`rust/`](/rust/) directory to declutter the repo a bit.
- Added experimenta; [build containers](/ci/docker/README.md) to assist with building SDRR, and doing so with the recommended build environment.
- Added dynamic [bank switchable](docs/MULTI-ROM-SETS.md#dynamic-bank-switching) ROM image support, using X1/X2 (you can use __either__ multi-ROM __or__ bank switching in a particular set).
- Added fun banked character ROM configs.
- Added VIC-20 NTSC config.
- Added retry in [ci/build.sh](ci/build.sh) to allow for intermittent network issues when downloading dependencies.
- Added [demo programs](demo/README.md) for C64 and VIC-20 to list SDRR features and other information/

### Fixes

- Fixed status LED behaviour, by placing outside of MAIN_LOOP_ONE_SHOT, and using the configured pin.
- Got `sdrr` firmware working on STM32F401RB/RC variants.  These have 64KB RAM, so can only support individual ROM images (quantity limited by flash) and do not support banked or multi-set ROMs.

## v0.2.0 - 2025-07-13

This version brings substantial improvements to the SDRR project, including:

- A single SDRR can be used to replace multiple ROM chips simultaneously.
- New [`sdrr-info`] tool to extract details and ROM images from firmware.
- Add your own hardware configurations, by adding a simple JSON file.
- New STM32F4 variants supported.
- Comprehensive testing of compiled in images to ensure veracity.

Care has been taken to avoid non-backwards compatible interface (such as CLI) changes, but some may may have been missed.  If you find any, please report them as issues.

### New Features

- Added support for ROM sets, allowing SDRR to serve multiple ROM images simultaneously, for certain combinations of ROM types.  This is done by connecting just the chip selects from other, empty sockets to be served, to pins X1/X2 (hardware revision 24-f onwards).  Currently tested only on VIC-20 (PAL) and C64 (PAL), serving kernal and BASIC ROMs simultaneously on VIC-20 and kernal/BASIC/character ROMs simultaneously on the C64.  See [Multi-ROM Sets](/docs/MULTI-ROM-SETS.md) for more details.
- Added [`sdrr-info`](/rust/sdrr-info/README.md) tool to parse the firmware and extract information about the configuration, ROM images, and to extract ROM images from the firmware.  In particular this allows
  - listing which STM32F4 device the firmware was built for
  - extraction of ROM images from the firmware, for checksumming and/or comparing with the originals.
- Moved hardware configuration to a dynamic model, where the supported hardware configurations are defined in configuration files, and the desired version is selected at build time.  Users can easily add configurations for their own PCB layouts, and either submit pull requests to include them in the main repository, or keep them locally.  For more details see [Custom Hardware](/docs/CUSTOM-HARDWARE.md).
- Added support F446 STM32F446R C/E variants - max clock speed 180 MHz (in excess of the F405's 168 MHz).  Currently untested.
- Added [`test`](/test/README.md), to verify the images source code files which are built into the firmware image, output the correct bytes, given the mangling that has taken place.

### Changes

- Updated VIC-20 PAL config to use VIC-20 dead-test v1.1.01.
- 24-pin PCB rev E/F gerbers provided (as yet unverified).
- Many previously compile time features now moved to runtime.
- Makefile produces more consistent and less verbose output.
- Added `sddr_info` struct to main firmware, containing firmware properties, for use at runtime, and later extraction.  This should also allow querying the firmware of a running system via SWD in future.

### Fixed

- Moved to fast speed outputs for data lines, instead of high speed, to ensure VOL is 0.4V, within the 6502's 0.8V requirement.  With high speed outputs, the VOL can be as high as 1.3V, which is beyond the 6502's 0.8V requirement.

## v0.1.0 - 2025-06-29

First release of SDRR.

- Supports F401, F411, and F405 STM32F4xxR variants.
- Includes configurations and pre-built firmware for C64, VIC-20 PAL, PET, 1541 disk drive, and IEEE disk drives.
- PCB rev D design included.
- Release binaries

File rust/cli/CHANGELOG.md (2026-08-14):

# CLI Changelog

## v0.3.0 - 2026-08-09

- **`--slot` now accepts every chip type the target firmware can serve on the
  board.** For v0.7.0 firmware onwards that is the served layout itself, so the
  overhang and fly-lead combinations `docs/COMPATIBILITY.md` documents — a
  `2764` on a Fire 24, a `28C16` on a Fire 28 — are accepted where they were
  previously refused as "not supported by this board". Building for v0.6.x is
  unchanged, and a rejection lists what that firmware does serve.
  - **Breaking: `--allow-unsupported-chip-type` is removed** from `program` and
    `firmware build`. It only ever bypassed the old per-board list; nothing it
    can now permit is buildable.

- **Breaking: the CLI's argument conventions are now consistent across every
  command.** No command takes a positional argument — `board header` and
  `board socket` take `--board`, where the error for omitting it already told
  you to. Each short flag means one thing CLI-wide: `-b` is `--board` (was
  `--byte` on `poke`), `-o` is `--output` (was `--offset` on `control erase`),
  `-i` is `--input` (was the global `--vid-pid`, which keeps `--id`), `-l` is
  `--length` (was `--slot`), and `-m` is `--msd` (was `--image` on
  `update slot`). `--board`, `--chip-type`, `--all`, `--force`, `--no-reboot`,
  `--input` and `--output` gain their short forms on the commands that lacked
  them. Enforced by tests that walk the whole command tree.
- **Breaking: `onerom control erase` uses `--stopped`/`--running`** for its
  post-erase reboot mode, matching `control reboot` and `program`. As with
  `onerom boards`, there is deliberately no alias for the old
  `--reboot-stopped`/`--reboot-running`.
- `--config` is now the primary spelling of the ROM configuration file option
  on `program` and `firmware build`, matching how it is written throughout the
  documentation; `--config-file`, `--config-json` and `--json` remain aliases.
- `onerom image convert` validates `--from`/`--to` as the command line is
  parsed and lists the accepted formats in `--help`, rather than failing
  part-way through a conversion. The list comes from `onerom-gen`, so a format
  added there needs no CLI change. `--load-address` is likewise parsed up
  front, by the same code the config file uses, so `$E000` and a bad value
  behave identically in both places.
- `--slot` keys and values are documented kebab-case — `size-handling`,
  `load-address`, `force-16-bit`, `cs1=active-low` — matching the CLI's own
  argument naming. The snake_case config spellings are all still accepted, and
  `size-handling`, the one key that took only the snake form, now parses.
- **`--slot` accepts `cs<n>=ignore`**, which a config file always could.
  Chip-select values now go through the same `onerom-gen` parser the config
  file uses, replacing a second, narrower copy in the CLI — between them
  `active_low` was accepted only on the command line and `ignore` only in a
  config file, and neither took the full set. `ignore` says One ROM does not
  monitor the line; whether a chip may use it is still settled by
  `allow_cs_ignore`, so a 2332 asking for it now gets that rule explained
  rather than "invalid CS logic".
- `--serial-override` now has help text and a `<SERIAL>` value name; it shipped
  with neither, from a `//` comment where clap needs `///`.
- **Breaking: `onerom boards` is now `onerom board`**, and the bare listing it
  printed is `onerom board list`. There is no alias, so scripts calling
  `onerom boards` must be updated; the CLI suggests `board` rather than simply
  failing.
- **Ice (STM32) boards are listed separately and rejected where the CLI cannot
  use them.** The CLI has never had an STM32 path — every firmware path
  composes an RP2350 image and every device path speaks picoboot — but the
  merged list implied otherwise, and `--board ice-24-d` failed several layers
  down as a missing release. `scan`, `program`, `firmware build`,
  `firmware download`, `firmware inspect --board`, `control pin`,
  `control reset` and `inspect gpio` now reject an Ice `--board` up front. The
  commands that only *describe* hardware still take them: `board header`,
  `board socket`, `chips` and `firmware releases`.
- **Add GPIO control**: `onerom control pin` drives a One ROM GPIO high, low or
  high-impedance, `onerom control reset` pulses one low to reset the host
  system One ROM is installed in, and `onerom inspect gpio` shows what every
  GPIO is and what One ROM is doing with it. All three need a *running* device
  with the USB system plugin, and say so.
  - `control pin --hold <MS>` holds the state for a bounded period and then
    applies `--then` (`z` by default); without `--hold` the state latches. The
    **device** times the hold, so an interrupted CLI cannot leave a pin
    latched. `control reset` is that with `--state low --then z` and `--hold`
    defaulting to 100ms; it never drives the line high, and rejects `--hold 0`.
  - `--pin` takes `gpio<N>` or a header pad name — `sel_a` to `sel_e` (`sel-a`
    and `sela` accepted) and `x1`/`x2`. A bare number is rejected as ambiguous,
    as are the broken-out address pads (`a<N>`), with a reason. `--state` and
    `--then` accept `1`/`0` alongside `high`/`low`.
  - A GPIO One ROM is itself using is refused, naming what it is doing, unless
    `--force`, which prints what forcing costs: a pin serving *reads* goes back
    with `--state z`, a pin serving *drives* leaves serving broken until
    reboot. A GPIO that is not 5V-tolerant warns, which `--yes` or `--force`
    answers.
  - `control pin`, `control reset` and `inspect gpio` take `--board`, needed
    only to resolve a `--pin` pad name on a board this build does not
    recognise.

  Requires One ROM firmware v0.7.1 or later and the v0.7.1 or later USB system
  plugin; against anything older the CLI says which of the two is too old
  rather than surfacing a USB stall.

- **Add ASCII views of a board's physical pin layouts.** `onerom board header
  [--board <board>]` draws the pin (jumper / programming) header, annotating each
  image-select and X pad with the GPIO behind it and — on Fire boards —
  whether that GPIO is 5V-tolerant (`5V`) or 3.3V-only (`!!3V3!!`, an ADC pin).
  `onerom board socket [--board <board>] [--chip-type <chip>] [--gpio]` draws the ROM
  socket as a DIP pinout: GPIOs by default, ROM pin functions with
  `--chip-type`, and both with `--gpio`. A chip whose pin count differs from
  the board's is drawn at the larger of the two, bottom-justified, marking
  `overhang` and `(empty)` pins and the `X1`/`X2` fly-lead each overhanging
  address line needs. The board is inferred from a connected One ROM when
  omitted; `onerom inspect header` and `onerom inspect socket` are the
  device-side forms, and take `--board` to override the board type the
  connected One ROM reports.
- **`onerom chips --board <board>` now reports how much flash each chip type
  uses.** Each chip is listed with its ROM size and its image size — often
  larger than the chip (a 2364 costs 8KB on a 24-pin board but 256KB
  overhanging a 28-pin one) — grouped by socket fit, matching
  `docs/COMPATIBILITY.md`. `--chip-type <chip>` (`-c`) answers for one type,
  and `board socket --chip-type` / `inspect socket --chip-type` report the same
  figure below the pinout. The listing now covers every chip the board can
  emulate, including the overhang and fly-lead combinations the name-only list
  omitted; a recognised type the board cannot serve is named in a trailing line
  instead. Ice boards keep the plain name list.
  - The Fit column is now legended, and the fit for a chip in a larger socket
    needing no signal wiring reads `larger socket (no fly-leads)` rather than
    `no fly-leads required`, which sat under a `(with fly-leads)` heading and
    read as a contradiction.
- **ROM images can be rearranged during a build**, via a new `transform=` key
  on `--slot`: `swap_bytes` reverses the byte order within each 16-bit word,
  and `deinterleave:<offset>/<stride>[/<bytes>]` extracts one lane from an
  interleaved image. Several may be combined with `+` and are applied in the
  order given, which matters. The same is expressible as a `"transform"` array
  in a config file. Previously the only option was `onerom image swap-bytes`,
  which rewrites the source file.
- **Add `onerom image deinterleave`** — the standalone counterpart to
  `onerom image swap-bytes` (`--offset`, `--stride`, `--bytes`). Both share
  their implementation with the `transform=` slot key. Neither reads Intel HEX;
  run `onerom image convert` first.
- Add `onerom image convert --from <fmt> --to <fmt> --input <file> --output
  <file> [--load-address <addr>]`, converting ROM images between `binary` and
  `ihex` (Intel HEX). The format set is designed to accept further formats
  later.
- Add `format` and `load_address` keys to `--slot` for Intel HEX ROM images:
  `--slot file=rom.hex,type=2364,cs1=active_low,format=ihex[,load_address=$E000]`.
  `format` accepts `binary` (default) or `ihex`; `load_address` (only valid
  with `format=ihex`) is a decimal or `0x`/`$`-prefixed address mapping to byte
  0 of the ROM. The same keys are available in config files.
- Add `--serial-override`, setting a custom USB serial number used while One
  ROM is running. A stopped One ROM continues to use its chip ID.
- Allow `--plugin` to be combined with `--config-file` on `program` and
  `firmware build`; the plugins are inserted ahead of the config's ROM slots.
  Errors if the config already defines a plugin of its own.
- Turbo boot with more than one non-plugin ROM slot is now accepted under
  `--force` rather than refused outright, for a first slot holding a bootloader
  that selects the others itself. `--force` now covers config warnings as well
  as firmware parse errors and a board type mismatch.
- The ROM type is now stored in metadata using the exact spelling the user
  entered, on both the `--config-file` (`"type"`) and `--slot type=...` paths,
  instead of a canonicalised name (`27SF512` is retained rather than normalised
  to `27512`). The resolved type still drives all behaviour.
- `onerom scan --list-boards` now prints the same listing as `onerom board
  list` rather than its own one-liner.
- `onerom inspect gpio` now shows one `Function` column instead of separate
  `Pad` and `Function` columns, listing everything the GPIO is: its ROM socket
  signal under the image being served, then the board peripheral, then the
  header pad, deduplicated.
  - This **fixes a real omission**: the lookup stopped at the first system
    function it matched, so on a `fire-24-f` — where the Status LED and the RGB
    LED are both GPIO 29 — the table named only the Status LED.
  - `Function` no longer claims a GPIO is `SWCLK` or `SWDIO`. Those are
    dedicated RP2350 pins with no GPIO of their own; the `SEL_C`/`SEL_D` pads
    merely share their nets. `onerom inspect header` remains the pad-indexed
    view.
- `onerom inspect gpio` now lists only the GPIOs connected to something, saying
  how many were omitted; `--all` lists every GPIO. The `X1`/`X2` and
  image-select pads always appear, being what the table is read to find.
- The explanatory legend under the `inspect gpio` table is now shown only with
  `--verbose`.
- `board socket` and `inspect socket` now say when a board has no GPIO map,
  instead of drawing the diagram with the GPIO column blank all the way down.
  The `--chip-type` function view is unaffected, being drawn from the chip's
  pinout rather than the socket map.
- `board header` and `inspect header` now say `command unsupported` for a board
  with no pin-header descriptor, where they said `nothing to draw` and called
  the descriptor missing "yet".
- `onerom inspect header` and `onerom inspect socket` now take `--board`,
  overriding the board type the connected One ROM reports, as `inspect gpio`
  already did. It is an override, not a substitute for the device — both still
  need a One ROM connected, and `onerom board header`/`board socket` remain the
  way to draw a board by name without one.
  - Their "cannot determine the board type" error now advises `--board`, which
    resolves it. The error only arises with a One ROM connected whose board type
    this build does not recognise, so the previous advice to connect one was
    unreachable.
- Stop hard-wrapping prose in console output. A handful of messages broke a
  sentence at a fixed width, which the terminal then wrapped again at its own.
  Multi-line messages that put a *separate* sentence on its own indented line
  are unchanged; that is structure, not wrapping.
- Fix `onerom image swap-bytes` panicking at startup (even for `--help`) with a
  clap short-option collision: `-i` was claimed by both the global `--vid-pid`
  and swap-bytes' `--input`. `-i` now belongs to `--input` throughout, and
  `--vid-pid` is long-only (alias `--id` unchanged).
- New `Error` variants: `ImageTransform`, `IceBoardUnsupported`,
  `TurboBootMultiSlot`, and the GPIO control errors (device not running, pin
  in use, no free hold slot).
- `--disable-swd` now takes effect on the device: SWD stays up for the whole of
  boot and is shut off just before serving. It may now be combined with
  `--logging`, previously rejected, and logging stops when SWD does. Its help
  text now says what it does and does not do.
- Fix `firmware build` accepting `--swd_disabled` where `program` accepted
  `--swd_disable`, so each underscore spelling worked on only one subcommand.
  `--disable-swd` and `--swd-disable` are unchanged and work on both.

## v0.2.0 - 2026-07-20

- Support firmware v0.7.x
- Move plugin handling to onerom-app crate.

## v0.1.11 - 2026-07-12

- Prevent program command from allowing --plugin and --firmware simultanesouly (as ---plugins is ignored anyway).

## v0.1.10 - 2026-07-02

- Added more help on size handling when programming or building firmware.

## v0.1.9 - 2026-06-02

- New 28 and 32 pin boards - fire-28-c and fire-32-b.

## v0.1.8 - 2026-05-26

- Re-added 23QL384.
- Add `onerom chips` to show supported chip types and their aliases.
- Fixed `onerom program --scan-slots`, to correctly re-query One ROM after programming.
- More ROM type aliases.

## v0.1.7 - 2026-05-18

- Added 27C100 type as synonym of 27C301/27C1000
- Added `onerom image swap-bytes` to swap bytes in a 16-bit ROM image file.

## v0.1.6 - 2026-05-14

- Moved 23QL384 support to a 23QL512 type.
- Fixed bug introduced in 0.1.5 where a (benign) error is reported requerying One ROM after programming.

## [v0.1.5] - 2025-05-12

- Added _prototype_ support for the new 23QL384 ROM type.  May be deprecated or modified in a future release.
- Add support for `onerom program .. --scan-slots` to auto-run `onerom scan --slots` after programming. 

## [0.1.4] - 2026-05-08

- Add 2364, 2732, 2716, 2708 and 2704 support on One ROM 28 boards.  See the main [CHANGELOG](/CHANGELOG.md) for important notes on this support, including warnings about potential damage if not used correctly.

## [0.1.3] - 2026-04-25

- Add support for labels/names for slots.

# [0.1.2] - 2026-04-02

- Add batch programming mode for programming multiple devices with the same firmware more quickly.
- Add 27C080, 28C16, 28C64, 28C256 and 28C512 ROM support.

## [0.1.1] - 2026-03-26

- Allow program --fw as well as --firmware.

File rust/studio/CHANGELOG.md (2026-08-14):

# Changelog

## v0.2.1 - 2026-08-09

- Support devices with overridden serials

## v0.2.0 - 2026-07-20

- Support firmware v0.7.x

## v0.1.23 - 2026-06-05

- Change USB Fire erase timeout to 20s from 10s (to match CLI).

## v0.1.22 - 2026-06-02

- New 28 and 32 pin boards - fire-28-c and fire-32-b.

## v0.1.21 - 2026-05-26

- Re-added 23QL384 ROM type
- More ROM aliases

## v0.1.20 - 2026-05-14

- Moved 23QL384 support to a 23QL512 type.

## v0.1.19 - 2026-05-12

- Added _prototype_ support for the new 23QL384 ROM type.  May be deprecated or modified in a future release.

## v0.1.18 - 2026-05-08

- Add 2364, 2732, 2716, 2708 and 2704 support on One ROM 28 boards.  See the main [CHANGELOG](/CHANGELOG.md) for important notes on this support, including warnings about potential damage if not used correctly.

## v0.1.17 - 2026-04-02

- Add 27C080, 28C16, 28C64, 28C256 and 28C512 ROM support.

## v0.1.16 - 2026-03-26

- Pulls in new boards and chip types (including chip type alias support)
- Adds a "reload" button next to selected config, to streamline config update workflow
- Inherits new, more robust picoboot crate 0.2.1
- Make errors new helpful.
- Supports "running" boards - stop them using the UI before progamming.

## v0.1.15 - 2026-02-25

- Added 2704/2708 ROM support.
- Added prototype One ROM 32 support (27C010, 27C020, 27C040, 27C301 and 27C080 via stacked One ROM 32s).

## v0.1.14 - 2026-02-22

- Fixed #152 (Studio fails to flash large images to One ROM 40 ROMs)

## v0.1.13 - 2026-02-22

Adds One ROM 40 ROM support.

## v0.1.12

## v0.1.11 - 2026-02-3

- Add some keyboard shortcuts to One ROM Studio:
  - r: Rescan devices
  - f: Flash firmware
- Added 231024 support.

## v0.1.9 - 2026-01-22

### Fixed

- Fixed #90 in v0.6.0 when older (pre v0.1.8) versions of One ROM Studio are used to build firmware images with more than one ROM set, One ROM will not boot on any ROM set other than ROM set 0.
- 2732 ROM type serving was broken - the top 2K replicated the bottom 2K.  Fixed (#103).  This included fixing the testing, which had also not caught this issue.

## v0.1.8 - 2026-01-14

### Added

- Support for low level config of firmware at runtime using JSON files #87.

## v0.1.7 - 2026-01-03

### Added

- #77 - Support for serving multi-ROM sets using Fire PIO algorithm.

## v0.1.6 - 2026-01-01

### Added

- 231024 ROM support in JSON config files.
- fire-24-c
- ice-24-i

## v0.1.5 - 2025-12-12

### Added

- fire-28-a

## v0.1.4 - 2025-12-09

### Added

- Support for local files to onerom-fw and onerom-studio.

### Fixed

- Set Windows PE file and product versions to match Cargo version.

## v0.1.3 - 2025-11-24

### Fixed

- Panic (crash) when analyzing a Fire with a debug probe.  Moved to fork of probe-rs with fix for panic.
- Allow multi-rom sets to be built
- Statically link with vcruntime

## v0.1.2 - 2025-11-09

- Built with rustc 1.91
- Move to probe-rs 0.30
- Added ability to load ROM config JSON files from disk in Create view
- Added online manifest to access latest URLs, with local cache file backup, and defaults as further backup
- Added app version update check and download link

## v0.1.1 - 2025-10-30

- Built with rustc 1.90
- Mac and Windows releases now signed.
- Mac app now uses the One ROM liquid glass icon.
- Moved to libusb-less DFU implementation using `dfu-rs` and `nusb` crates.
- Moved to manual rescanning to detect probes and USB devices.
- Added network connectivity icon.
- Single universal macOS dmg installer instead of separate Intel and Apple Silicon versions.
- Added ability to load ROM config JSON files from disk in Create view.

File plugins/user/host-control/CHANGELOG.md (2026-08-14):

# Changelog

## [0.1.2] - 2026-08-09

Report as many RAM slots as the RAM holds, rather than at most seven, and keep
those a host cannot name for the plugin's own use.

- **Potentially breaking.**  A RAM slot is exactly one ROM region, so with a
  small ROM there are now far more slots and each is far smaller than before —
  as little as 2KB for a 2316, where the old cap of seven was meant to keep a
  slot at 64KB but could not, since a slot has to be the size of the ROM being
  served.  A host that assumed a slot was large enough for some purpose of its
  own, or that there were at most seven, sees something different.
- `GET_RAM_SLOT_INFO_ALL` now reports at most 170 slots however many the
  firmware has, because every command that names a slot rejects 0xAA and a slot
  no host can name is no use to one.  Slots above that are the plugin's.

Make NV storage writable on devices whose RAM slots are too small to stage a
transaction in.  Where the plugin has slots of its own it stages there, using as
many consecutive slots as the staging buffer needs, and leaves the slot the host
named untouched.

- Previously `GET_NV_CAPABILITY` reported NV storage writable whenever the
  device had more than one RAM slot, but every `NV_POKE_BEGIN` then failed if no
  single slot could hold the 4KB staging buffer and the erase routine — which is
  every device serving a ROM smaller than that.

Route RBCP command decode through the observed (bus) address space, so command
signalling works on a 40-pin part whose least-significant address line the
device does not observe.

Stop `RBCP_RESET`, `EXIT_CMD_RESP_SILENT` and `SWITCH_AND_EXIT` writing to the
response header.  All three ran the first half of the command processing
sequence before being recognised as silent, leaving the token incremented and
progress stuck at pending.

- **Behaviour change**, bringing the plugin into line with the specification,
  which requires all three to update nothing.  A host that polled after one of
  them would previously have waited for a completion that never came.

Stop `GET_FLASH_SLOT_INFO_ALL` overwriting the truncated record's `rom_type`
when that byte is the only one present.  The null terminator is now written
only where the record carries a name.

- **Potentially breaking.**  RBCP v0.1.1 clarifies that a truncated record's
  final byte is 0x00 where a name is present — previously unspecified, and
  what the plugin already did.  A host that relied on that byte being the
  record's real byte, or on a one-byte record being terminated, sees different
  data.

Stop acting on Group 0x01 Read commands received in command mode, where the
specification makes them valid in command-response mode only.  Previously such
a command executed and wrote its answer into a back-channel region the device
had already stopped maintaining, modifying the served ROM image outside any
session.  Group 0x01 and Group 0x03 now consume the command's argument bytes
and discard it.

- **Potentially breaking** for a host that issued a Read command in command
  mode and used the result — behaviour the specification never permitted.
  Neither the RBCP 6502 reference host nor r107sl's C64 bootloader does: both
  issue every Read and NV command through the command-response polling path.

Report failure, rather than discarding silently, when `ENTER_CMD_RESP` asks for
a back-channel larger than the RAM slot.  The specification requires failure
here and silent discard for the other malformed-argument cases, and a host
tells the two apart by whether the token increments.

Versions before 0.1.2 predate this file.

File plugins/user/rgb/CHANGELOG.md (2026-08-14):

# Changelog

## [0.1.2] - 2026-08-09

- Discover the neopixel and status-LED GPIOs from device metadata at runtime
  (via `ORA_ID_GET_METADATA_UINT`) instead of hard-coding them by MCU package.
- On boards where the status LED and neopixel share a GPIO, honour the live
  status-LED state (`STATUS_LED_STATE`): the neopixel keeps cycling while the
  shared discrete LED reflects whether the status LED is on or off.
- Requires firmware v0.7.1 (metadata getter API); `min_fw_version` raised to
  0.7.1.

## [0.1.1]

- Earlier releases predate this changelog.

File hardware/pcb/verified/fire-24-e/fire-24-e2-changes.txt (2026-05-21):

Added semi-circle cutout to top of board to help indicate pin 1 side.
Added silkscreen along this edge.

Small changes to silkscreen around pin headers
Added +5V and circle around pin header in an attempt to idiot proof against accidental shorts.

Tweaks to track routing.
Some track sizes changed to closer match connected pads.
GND polygons changes to look better....
Some VIA sizes changed (still within JLCPLCB tolerances)
Some extra Vias and GND plane fill added in places.

Optional D1 LED:
        Orange XINGLIGHT MFR.Part #XL-1005UOC   JLCPCB Part #C965791
        Yellow XINGLIGHT MFR.Part #XL-1005UYC   JLCPCB Part #C25503856

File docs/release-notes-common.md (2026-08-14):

# One ROM - Release Notes

The most flexible ROM replacement for your retro computer.

https://onerom.org

## Changes In This Release

[CHANGELOG_PLACEHOLDER]

## Using

Use [One ROM Web](https://onerom.org/web) to configure your One ROM.

For more advanced use cases, use [One ROM CLI](https://onerom.org/cli) to build and flash your One ROM.

## Firmware

The One ROM firmware is published at [images.onerom.org](https://images.onerom.org), and is not attached to this release.  Use [Web](https://onerom.org/web) or [CLI](https://onerom.org/cli) to build and flash your One ROM - these download and use the current firmware for you.

## Support

For documentation, hardware setup guides, and support:
- Discord: [piers.rocks Discord](https://discord.com/invite/tq22nJefXr)
- GitHub: [Project](https://github.com/piersfinlayson/one-rom)
- YouTube: [@piers.rocks](https://www.youtube.com/@piers_rocks)

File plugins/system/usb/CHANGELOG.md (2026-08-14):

# Changelog

## [0.2.1] - 2026-08-09

Add support for overriden serial #s.

Add GPIO control over picobootx: `ONEROM_CMD_GET_CAPS`, `ONEROM_CMD_GPIO_SET`
and `ONEROM_CMD_GPIO_QUERY`.  A host can now drive a GPIO high, low or high
impedance, optionally for a bounded period after which the plugin reverts it
itself, and read back what One ROM is using each GPIO for.

- The hold is timed on the device, not by the host, so a pulse still ends if
  the host goes away part-way through it - the point of the exercise, since the
  motivating case is a wire from a header pad to the host system's reset line.
  Up to 8 GPIOs can be held at once, for at most 60s each; a second
  `ONEROM_CMD_GPIO_SET` on a GPIO replaces that GPIO's pending release.
- `ONEROM_CMD_GPIO_SET` is validated and applied in the picoboot dispatch
  handler rather than deferred to the task loop, so the firmware's refusal of a
  GPIO One ROM is itself using reaches the host as a command status instead of
  being swallowed.
- Capabilities are decided once at plugin init from which plugin-API functions
  the running firmware provides.  On firmware that predates the GPIO API the
  feature bits are clear, `num_gpios` is 0 and the host never sends the
  commands, so `min_fw_version` stays at 0.7.0 and the plugin keeps working
  otherwise.
- The custom-command dispatcher no longer rejects every command that has a data
  phase - it validates the length per command instead, which is what lets the
  two commands that return data work at all.

## [0.2.0] - 2026-07-20

Support firmware v0.7.x

## [0.1.1] - 2026-03-26

Fix live ROM image peek/poke for 28 pin chips

## [0.1.0] - 2026-03-25

First release

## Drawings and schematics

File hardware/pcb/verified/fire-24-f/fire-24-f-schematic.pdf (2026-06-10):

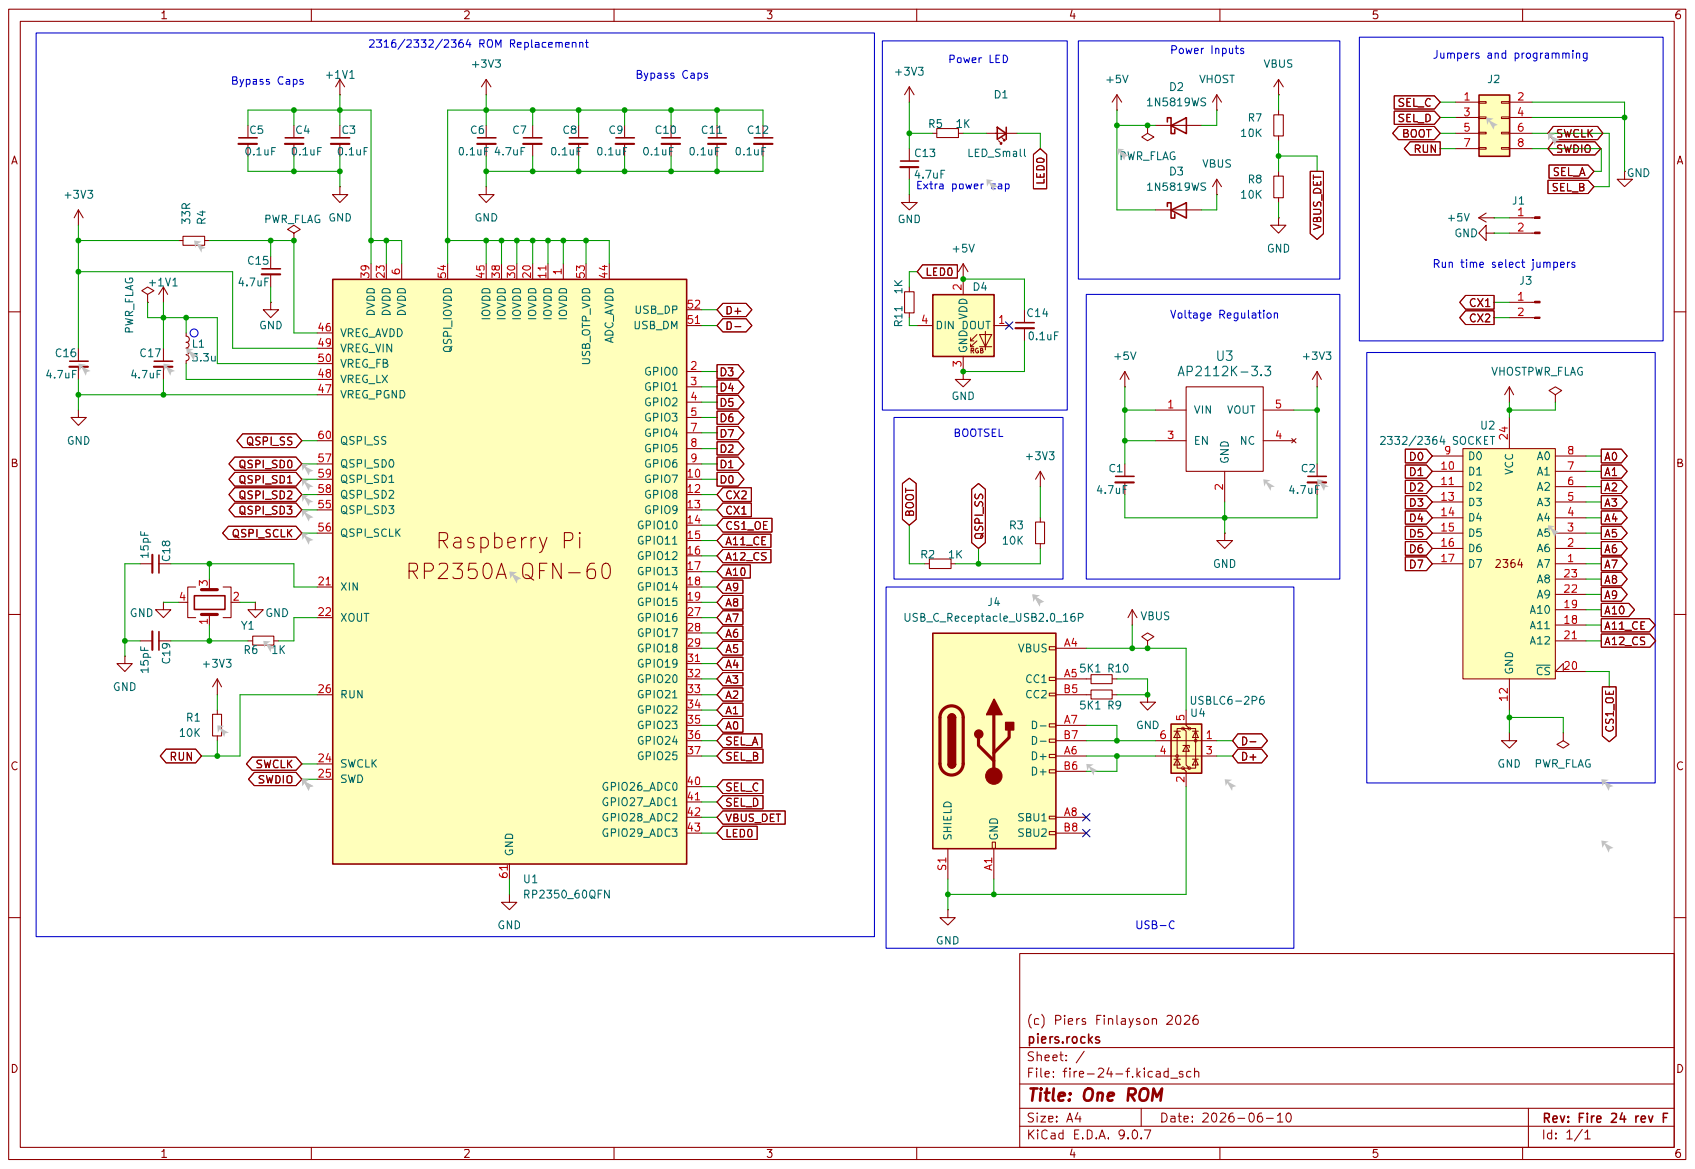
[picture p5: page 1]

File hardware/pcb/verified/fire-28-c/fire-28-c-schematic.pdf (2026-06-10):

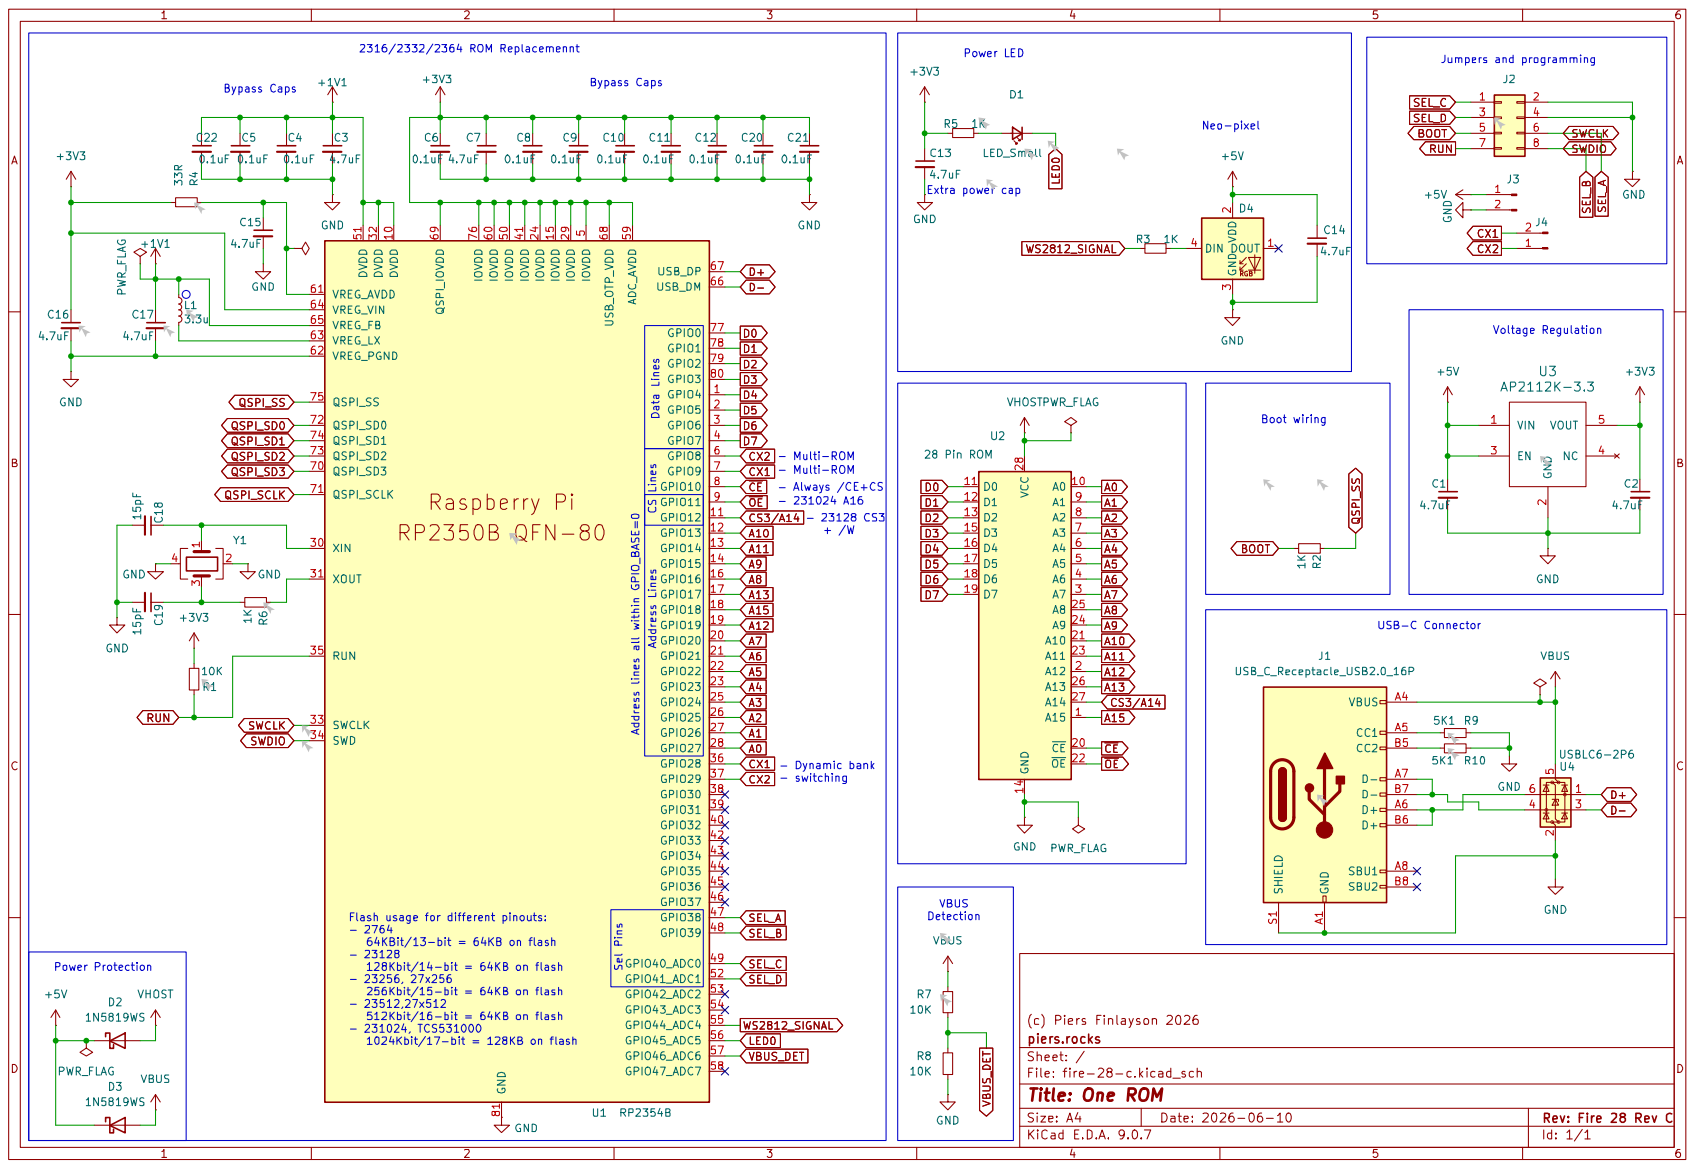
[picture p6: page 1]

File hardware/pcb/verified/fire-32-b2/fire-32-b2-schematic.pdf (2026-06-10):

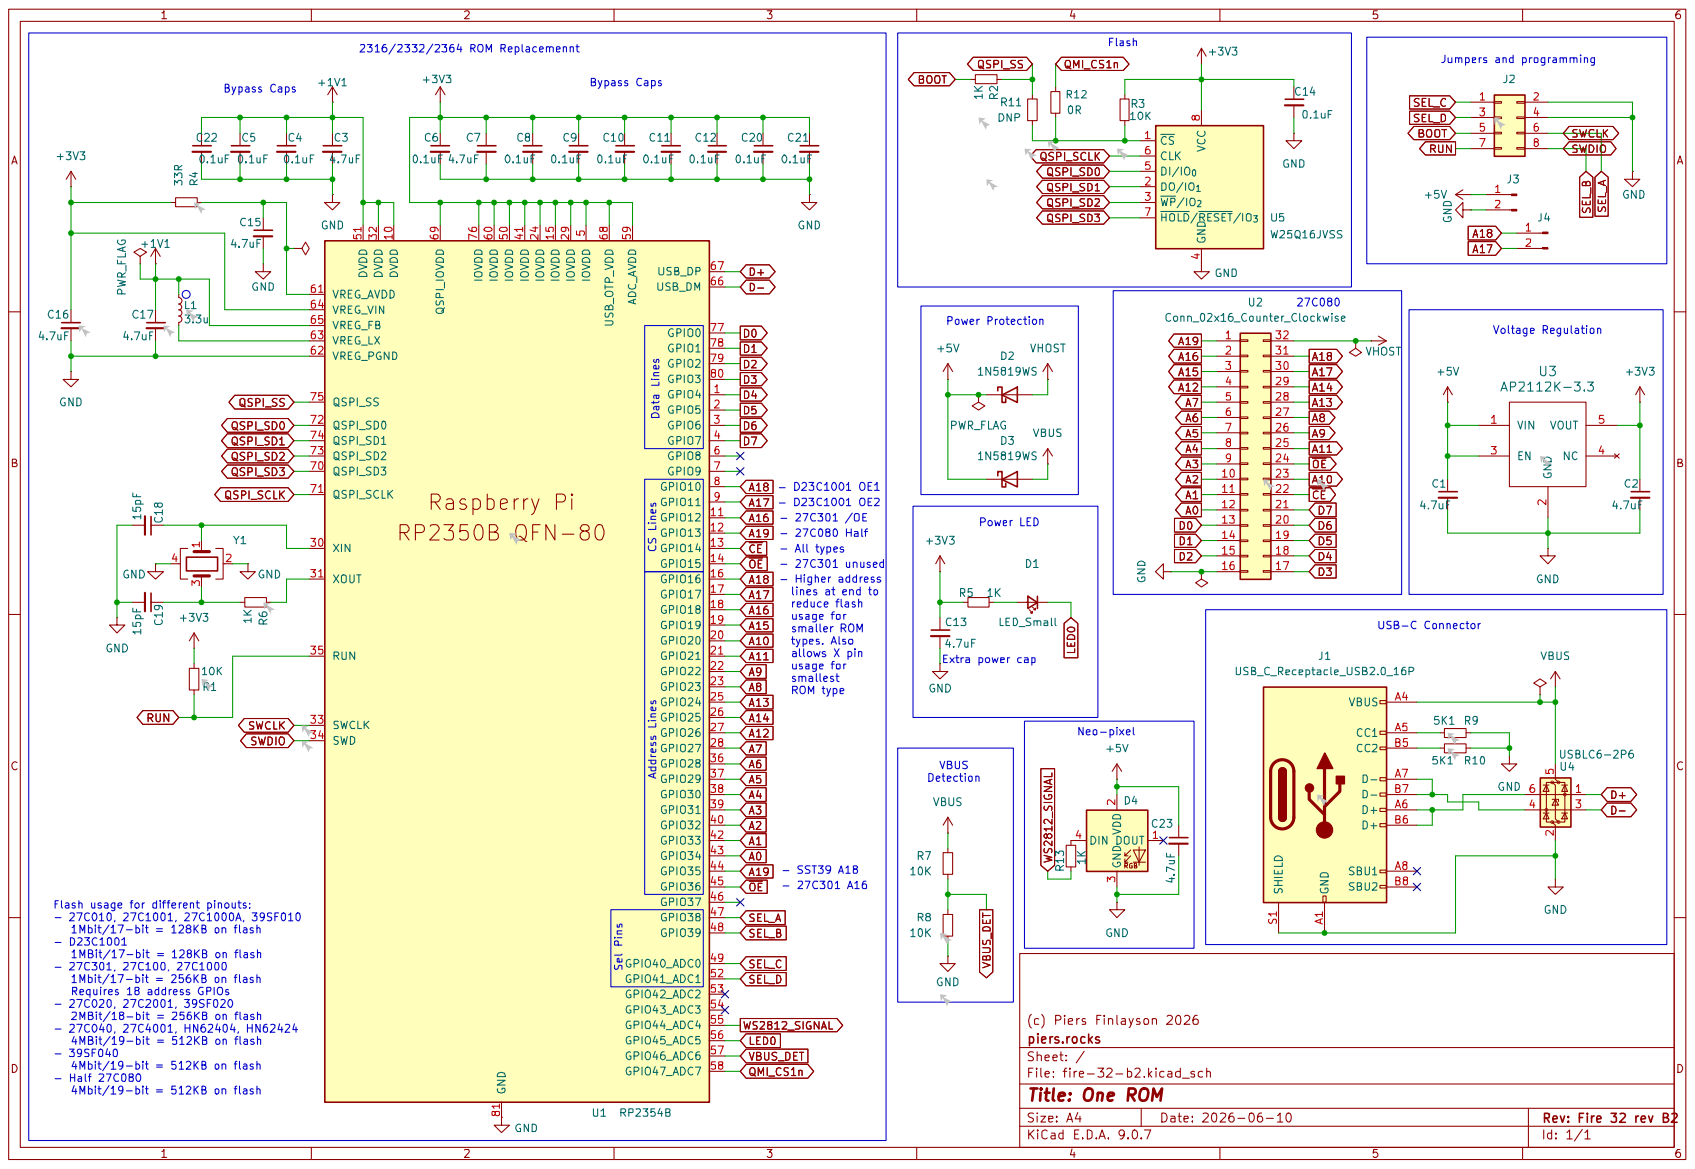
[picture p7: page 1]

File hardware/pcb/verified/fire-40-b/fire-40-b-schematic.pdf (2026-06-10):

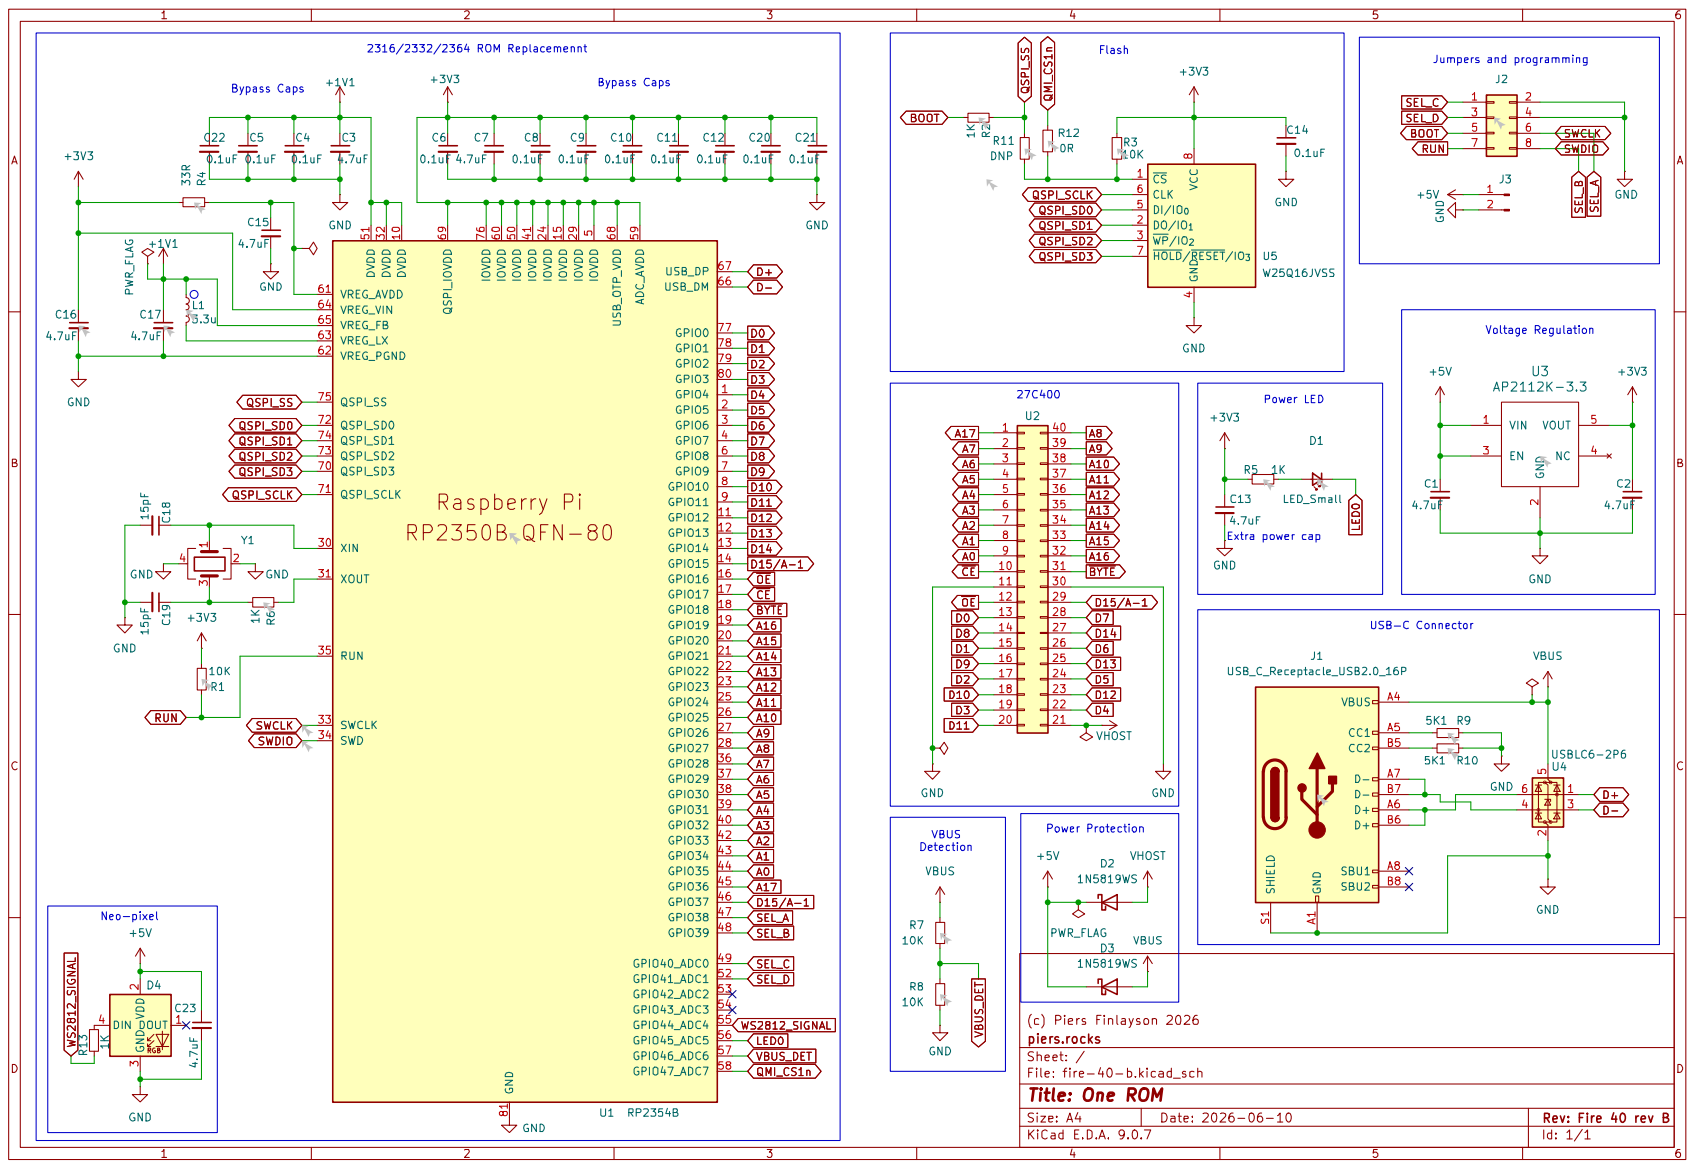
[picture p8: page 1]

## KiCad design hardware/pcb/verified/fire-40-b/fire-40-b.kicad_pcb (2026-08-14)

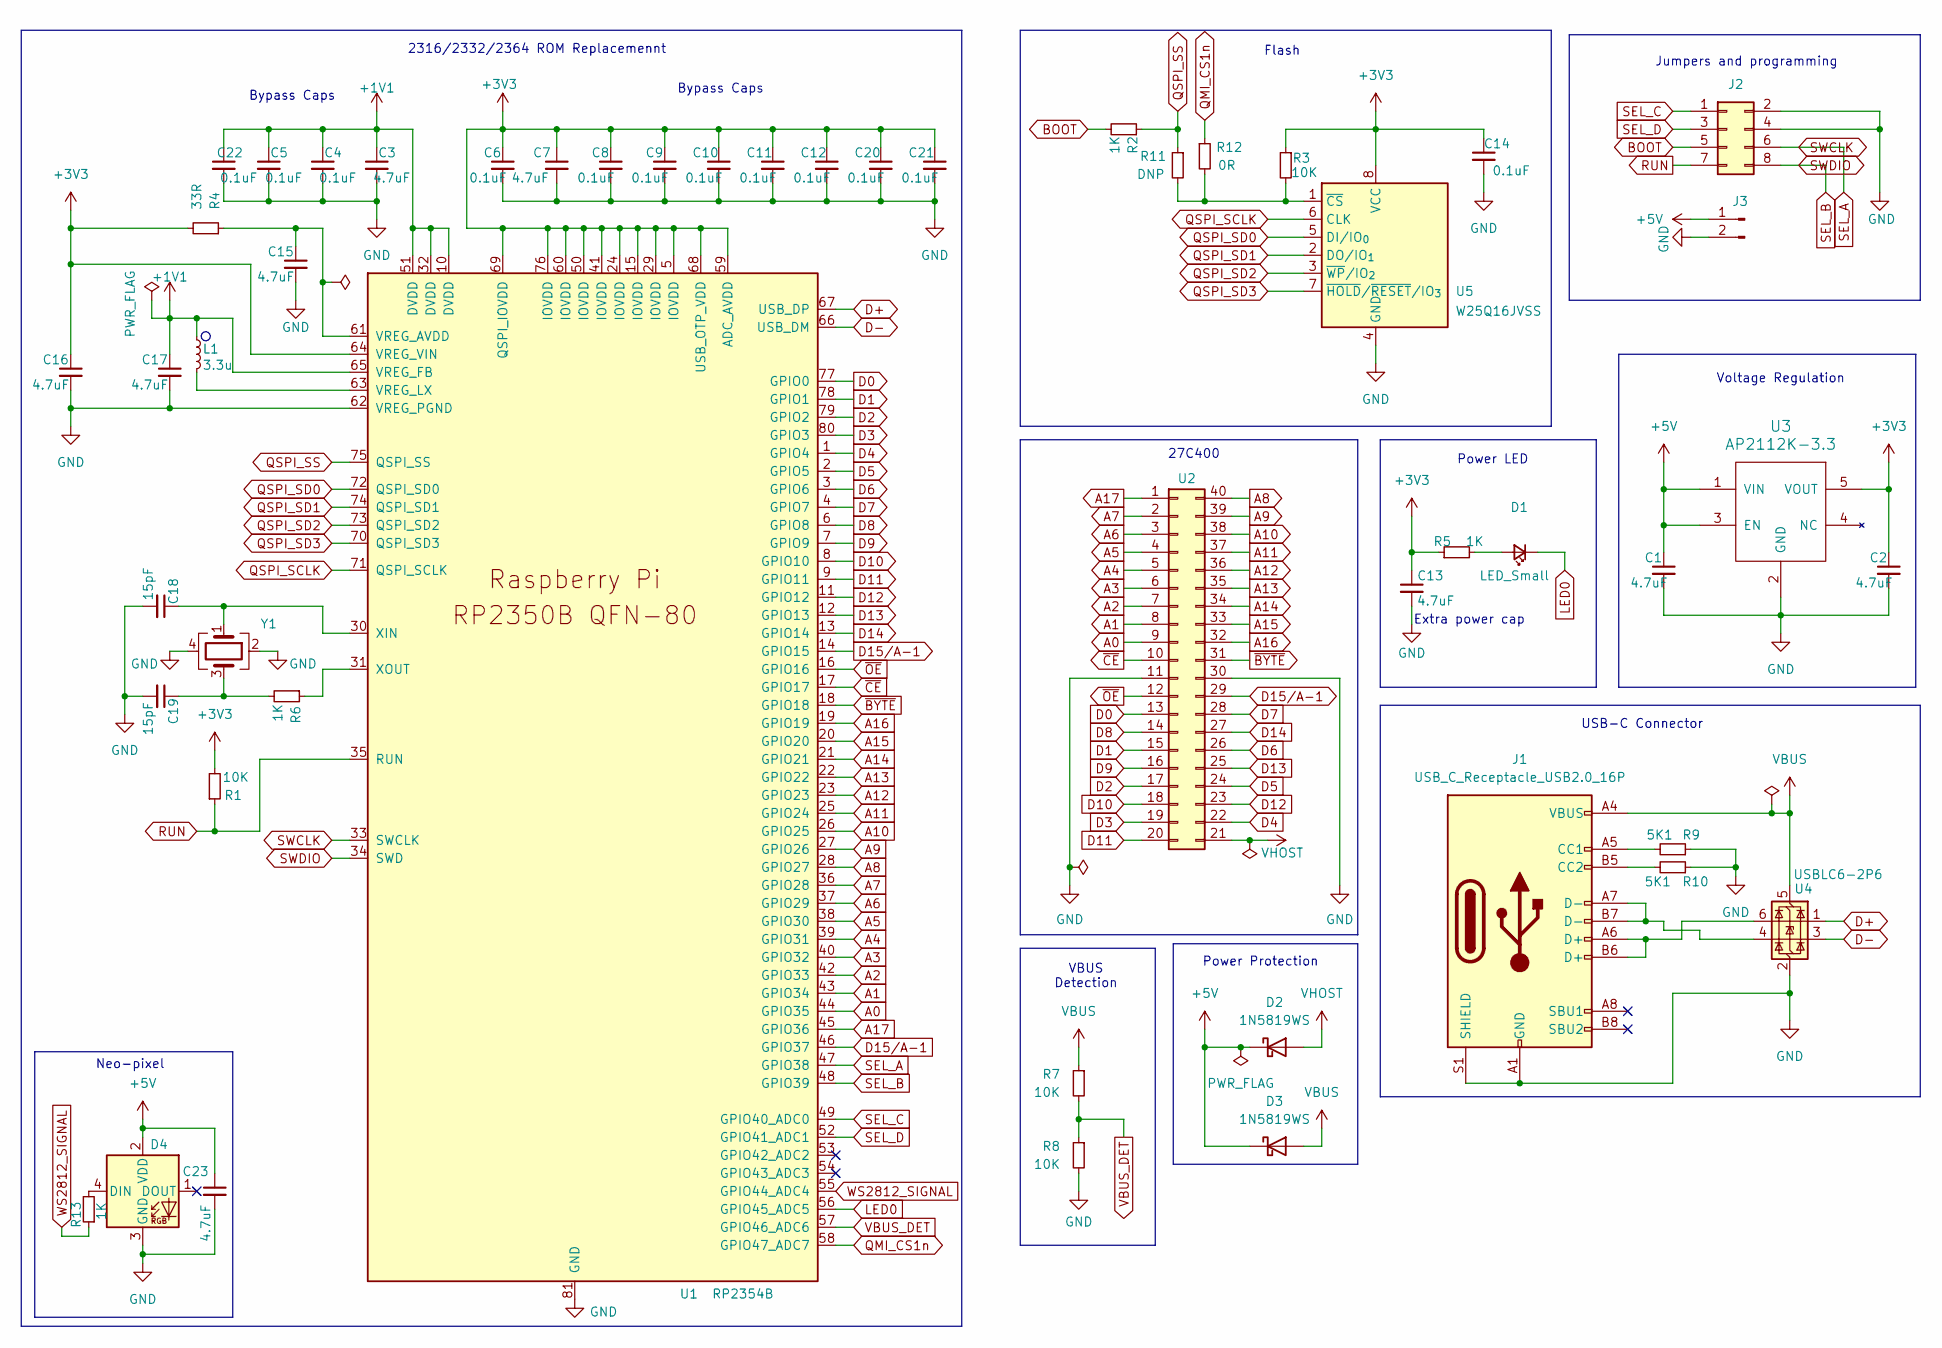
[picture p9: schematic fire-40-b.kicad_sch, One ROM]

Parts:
C1, C2, C3, C7, C13, C15, C23: 4.7uF; C_0402_1005Metric; LCSC C23733
C4, C5, C6, C8, C9, C10, C11, C12, C14, C20, C21, C22: 0.1uF; C_0402_1005Metric; LCSC C1525
C16, C17: 4.7uF; C_0402_1005Metric_small_pads; LCSC C23733
C18, C19: 15pF; C_0402_1005Metric; LCSC C1548
D1: LED_Small; LED_0603_1608Metric; LCSC C2286
D2, D3: 1N5819WS; D_SOD-323; LCSC C191023
D4: XL-1010RGBC-WS2812B; XL-1010RGBC-2812B; LCSC C5349953
J1: USB_C_Receptacle_USB2.0_16P; USB_C_connector_c2765186; LCSC C2765186
J2: Conn_02x04_Odd_Even; PinHeader_2x04_P2.54mm_Vertical custom silkscreen
J3: Conn_01x02_Pin; PinHeader_1x02_P2.54mm_Vertical
L1: 3.3u; L_pol_2016; LCSC C42411119
R1, R3, R7, R8: 10K; R_0402_1005Metric; LCSC C25744
R2, R5, R6, R13: 1K; R_0402_1005Metric; LCSC C11702
R4: 33R; R_0402_1005Metric; LCSC C25105
R9, R10: 5K1; R_0402_1005Metric; LCSC C25905
R11: DNP; R_0402_1005Metric; LCSC C17168
R12: 0R; R_0402_1005Metric; LCSC C17168
U1: RP2354B; RP2350-QFN-80-1EP_10x10_P0.4mm_EP3.4x3.4mm_ThermalVias; LCSC C39843328
U2: Conn_02x20_Counter_Clockwise; 2x20 dip pin output 600mil centres
U3: AP2112K-3.3; SOT-23-5; LCSC C51118
U4: USBLC6-2P6; SOT-666; LCSC C15999
U5: W25Q16JVSS; Winbond_USON-8-1EP_3x2mm_P0.5mm_EP0.2x1.6mm; LCSC C2843335
Y1: Crystal_GND24; Crystal_SMD_Abracon_ABM8G-4Pin_3.2x2.5mm; LCSC C20625731

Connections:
+1V1: C3.1, C4.1, C5.1, C17.1, C22.1, L1.1, U1.10 (DVDD), U1.32 (DVDD), U1.51 (DVDD), U1.65 (VREG_FB)
+3V3: C2.1, C6.1, C7.1, C8.1, C9.1, C10.1, C11.1, C12.1, C13.1, C14.1, C16.1, C20.1, C21.1, R1.2, R3.1, R4.2, R5.1, U1.5 (IOVDD), U1.15 (IOVDD), U1.24 (IOVDD), U1.29 (IOVDD), U1.41 (IOVDD), U1.50 (IOVDD), U1.59 (ADC_AVDD), U1.60 (IOVDD), U1.64 (VREG_VIN), U1.68 (USB_OTP_VDD), U1.69 (QSPI_IOVDD), U1.76 (IOVDD), U3.5 (VOUT), U5.8 (VCC)
+5V: C1.1, C23.1, D2.1 (K), D3.1 (K), D4.2 (VDD), J3.1, U3.1 (VIN), U3.3 (EN)
A0: U1.44 (GPIO35), U2.9
A1: U1.43 (GPIO34), U2.8
A2: U1.42 (GPIO33), U2.7
A3: U1.40 (GPIO32), U2.6
A4: U1.39 (GPIO31), U2.5
A5: U1.38 (GPIO30), U2.4
A6: U1.37 (GPIO29), U2.3
A7: U1.36 (GPIO28), U2.2
A8: U1.28 (GPIO27), U2.40
A9: U1.27 (GPIO26), U2.39
A10: U1.26 (GPIO25), U2.38
A11: U1.25 (GPIO24), U2.37
A12: U1.23 (GPIO23), U2.36
A13: U1.22 (GPIO22), U2.35
A14: U1.21 (GPIO21), U2.34
A15: U1.20 (GPIO20), U2.33
A16: U1.19 (GPIO19), U2.32
A17: U1.45 (GPIO36), U2.1
BOOT: J2.5, R2.2
D0: U1.77 (GPIO0), U2.13
D1: U1.78 (GPIO1), U2.15
D2: U1.79 (GPIO2), U2.17
D3: U1.80 (GPIO3), U2.19
D4: U1.1 (GPIO4), U2.22
D5: U1.2 (GPIO5), U2.24
D6: U1.3 (GPIO6), U2.26
D7: U1.4 (GPIO7), U2.28
D8: U1.6 (GPIO8), U2.14
D9: U1.7 (GPIO9), U2.16
D10: U1.8 (GPIO10), U2.18
D11: U1.9 (GPIO11), U2.20
D12: U1.11 (GPIO12), U2.23
D13: U1.12 (GPIO13), U2.25
D14: U1.13 (GPIO14), U2.27
D15/A-1: U1.14 (GPIO15), U1.46 (GPIO37), U2.29
D+: U1.67 (USB_DP), U4.1 (I/O1)
D-: U1.66 (USB_DM), U4.3 (I/O2)
GND: C1.2, C2.2, C3.2, C4.2, C5.2, C6.2, C7.2, C8.2, C9.2, C10.2, C11.2, C12.2, C13.2, C14.2, C15.2, C16.2, C17.2, C18.2, C19.2, C20.2, C21.2, C22.2, C23.2, D4.3 (GND), J1.A1 (GND), J1.A12 (GND), J1.B1 (GND), J1.B12 (GND), J1.S1 (SHIELD), J2.2, J2.4, J3.2, R8.2, R9.1, R10.1, U1.62 (VREG_PGND), U1.81 (GND), U2.11, U2.30, U3.2 (GND), U4.2 (GND), U5.4 (GND), Y1.2, Y1.4
LED0: D1.1 (K), U1.56 (GPIO45_ADC5)
unnamed: C19.1, R6.2, Y1.3
unnamed: D1.2 (A), R5.2
unnamed: D4.4 (DIN), R13.2
unnamed: J1.A5 (CC1), R9.2
unnamed: J1.B5 (CC2), R10.2
unnamed: J1.A6 (D+), J1.B6 (D+), U4.6 (I/O1)
unnamed: J1.A7 (D-), J1.B7 (D-), U4.4 (I/O2)
unnamed: C15.1, R4.1, U1.61 (VREG_AVDD)
unnamed: L1.2, U1.63 (VREG_LX)
unnamed: C18.1, U1.30 (XIN), Y1.1
unnamed: R6.1, U1.31 (XOUT)
unnamed: R3.2, R11.2, R12.2, U5.1 (~CS)
QMI_CS1n: R12.1, U1.58 (GPIO47_ADC7)
QSPI_SCLK: U1.71 (QSPI_SCLK), U5.6 (CLK)
QSPI_SD0: U1.72 (QSPI_SD0), U5.5 (DI/IO_{0})
QSPI_SD1: U1.74 (QSPI_SD1), U5.2 (DO/IO_{1})
QSPI_SD2: U1.73 (QSPI_SD2), U5.3 (~WP/IO_{2})
QSPI_SD3: U1.70 (QSPI_SD3), U5.7 (~HOLD/~RESET/IO_{3})
QSPI_SS: R2.1, R11.1, U1.75 (QSPI_SS)
RUN: J2.7, R1.1, U1.35 (RUN)
SEL_A: J2.6, U1.33 (SWCLK), U1.47 (GPIO38)
SEL_B: J2.8, U1.34 (SWD), U1.48 (GPIO39)
SEL_C: J2.1, U1.49 (GPIO40_ADC0)
SEL_D: J2.3, U1.52 (GPIO41_ADC1)
VBUS: D3.2 (A), J1.A4 (VBUS), J1.A9 (VBUS), J1.B4 (VBUS), J1.B9 (VBUS), R7.1, U4.5 (VBUS)
VBUS_DET: R7.2, R8.1, U1.57 (GPIO46_ADC6)
VHOST: D2.2 (A), U2.21
WS2812_SIGNAL: R13.1, U1.55 (GPIO44_ADC4)
~BYTE: U1.18 (GPIO18), U2.31
~CE: U1.17 (GPIO17), U2.10
~OE: U1.16 (GPIO16), U2.12

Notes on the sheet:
USB-C Connector
Voltage Regulation
Neo-pixel
Extra power cap
2316/2332/2364 ROM Replacemennt
Bypass Caps
Power LED
Power Protection
27C400
VBUS Detection
Flash
Jumpers and programming

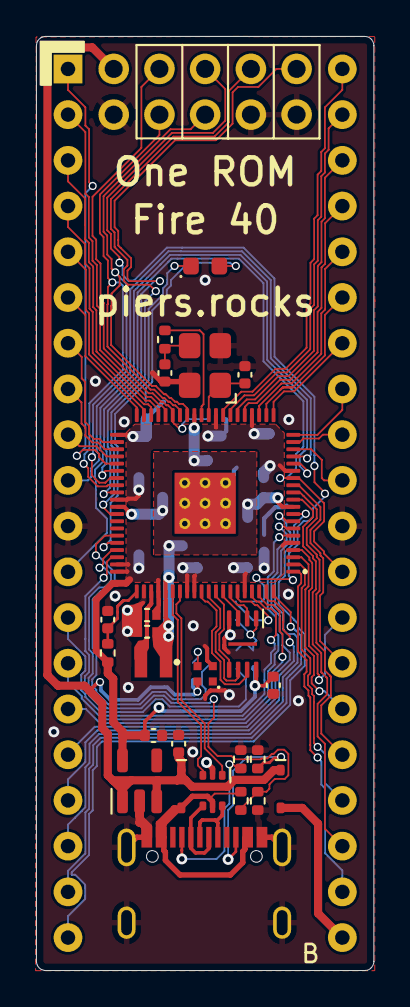
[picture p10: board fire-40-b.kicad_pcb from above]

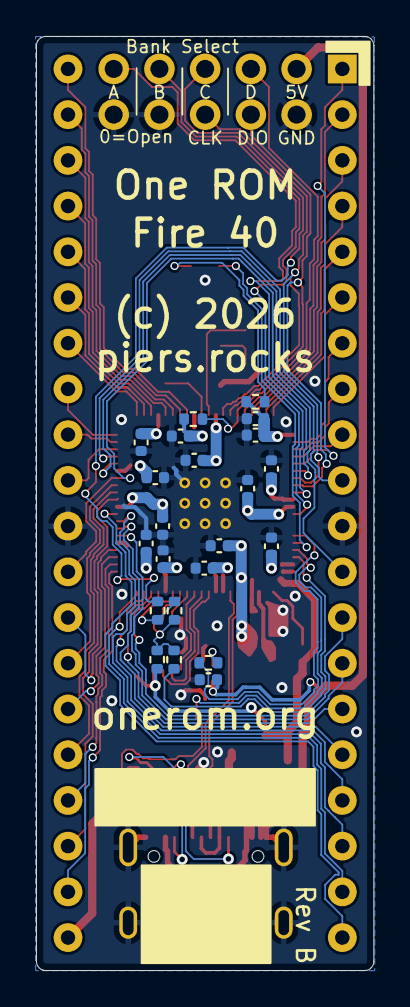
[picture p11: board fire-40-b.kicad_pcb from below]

Board: 2 copper layers, 18.7 x 51.9 mm, 50 parts (22 on the bottom side), 73 nets.

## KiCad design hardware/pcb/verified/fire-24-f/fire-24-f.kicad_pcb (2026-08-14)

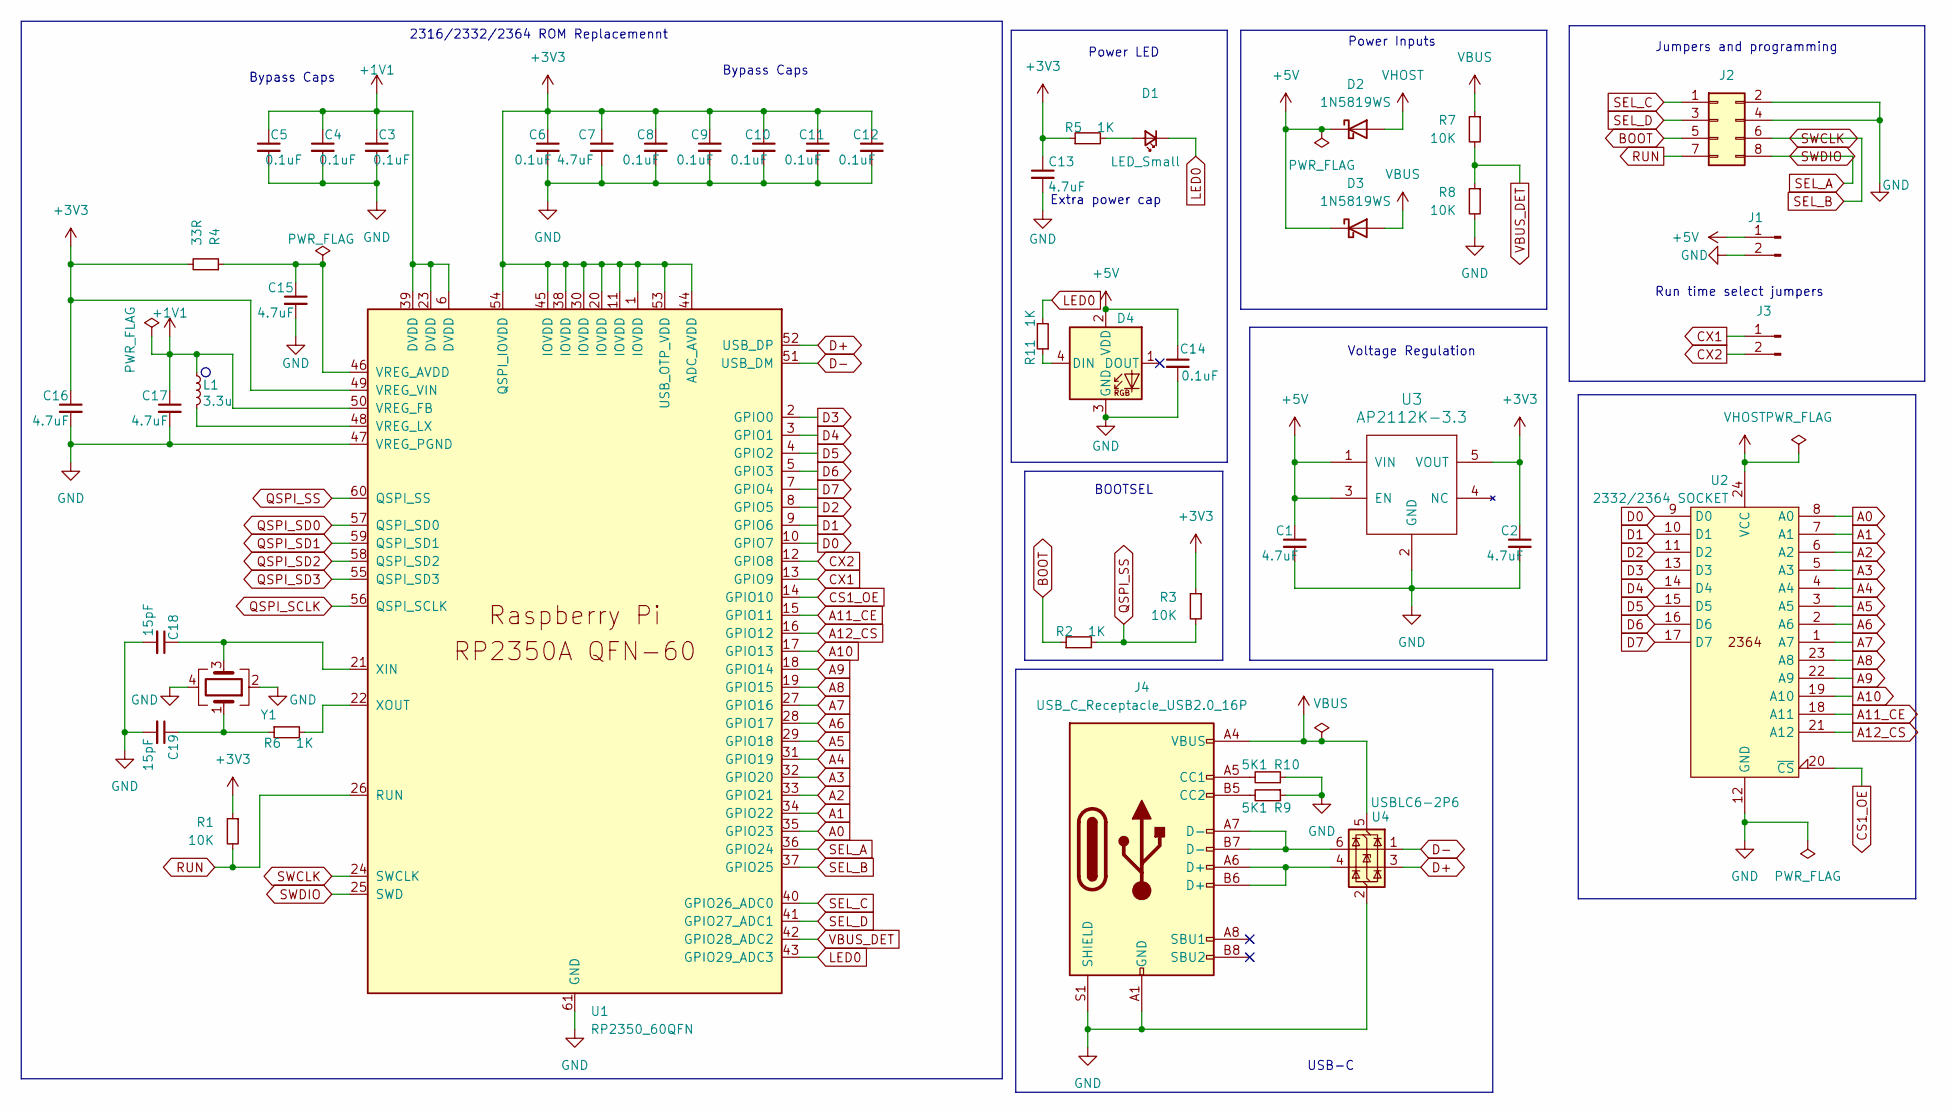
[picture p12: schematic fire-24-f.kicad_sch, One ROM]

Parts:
C1, C2, C7, C13, C15: 4.7uF; C_0402_1005Metric; LCSC C23733
C3, C4, C5, C6, C8, C9, C10, C11, C12, C14: 0.1uF; C_0201_0603Metric; LCSC C668346
C16, C17: 4.7uF; C_0402_1005Metric_small_pads; LCSC C23733
C18, C19: 15pF; C_0201_0603Metric; LCSC C85891
D1: LED_Small; LED_0402_1005Metric; LCSC C25503345
D2, D3: 1N5819WS; D_SOD-323; LCSC C191023
D4: XL-1010RGBC-WS2812B; XL-1010RGBC-2812B; LCSC C5349953
J1, J3: Conn_01x02_Pin; PinHeader_1x02_P2.54mm_Vertical
J2: Conn_02x04_Odd_Even; PinHeader_2x04_P2.54mm_Vertical custom silkscreen
J4: USB_C_Receptacle_USB2.0_16P; USB_C_connector_c2765186; LCSC C2765186
L1: 3.3u; L_pol_2016; LCSC C42411119
R1, R3, R7, R8: 10K; R_0201_0603Metric; LCSC C473048
R2, R5, R6, R11: 1K; R_0201_0603Metric; LCSC C270365
R4: 33R; R_0402_1005Metric; LCSC C25105
R9, R10: 5K1; R_0201_0603Metric; LCSC C270344
U1: RP2350_60QFN; RP2350-QFN-60-1EP_7x7_P0.4mm_EP3.4x3.4mm_ThermalVias; LCSC C41378174
U2: 2332/2364 SOCKET; 2x12 dip pin output 600mil centres no ss
U3: AP2112K-3.3; SOT-23-5; LCSC C51118
U4: USBLC6-2P6; SOT-666; LCSC C15999
Y1: Crystal_GND24; Crystal_SMD_Abracon_ABM8G-4Pin_3.2x2.5mm; LCSC C20625731

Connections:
+1V1: C3.1, C4.1, C5.1, C17.1, L1.1, U1.6 (DVDD), U1.23 (DVDD), U1.39 (DVDD), U1.50 (VREG_FB)
+3V3: C2.1, C6.1, C7.1, C8.1, C9.1, C10.1, C11.1, C12.1, C13.1, C16.1, R1.1, R3.1, R4.2, R5.1, U1.1 (IOVDD), U1.11 (IOVDD), U1.20 (IOVDD), U1.30 (IOVDD), U1.38 (IOVDD), U1.44 (ADC_AVDD), U1.45 (IOVDD), U1.49 (VREG_VIN), U1.53 (USB_OTP_VDD), U1.54 (QSPI_IOVDD), U3.5 (VOUT)
+5V: C1.1, C14.1, D2.1 (K), D3.1 (K), D4.2 (VDD), J1.1, U3.1 (VIN), U3.3 (EN)
A0: U1.35 (GPIO23), U2.8 (A0)
A1: U1.34 (GPIO22), U2.7 (A1)
A2: U1.33 (GPIO21), U2.6 (A2)
A3: U1.32 (GPIO20), U2.5 (A3)
A4: U1.31 (GPIO19), U2.4 (A4)
A5: U1.29 (GPIO18), U2.3 (A5)
A6: U1.28 (GPIO17), U2.2 (A6)
A7: U1.27 (GPIO16), U2.1 (A7)
A8: U1.19 (GPIO15), U2.23 (A8)
A9: U1.18 (GPIO14), U2.22 (A9)
A10: U1.17 (GPIO13), U2.19 (A10)
A11_CE: U1.15 (GPIO11), U2.18 (A11)
A12_CS: U1.16 (GPIO12), U2.21 (A12)
BOOT: J2.5, R2.1
CS1_OE: U1.14 (GPIO10), U2.20 (~CS)
CX1: J3.1, U1.13 (GPIO9)
CX2: J3.2, U1.12 (GPIO8)
D0: U1.10 (GPIO7), U2.9 (D0)
D1: U1.9 (GPIO6), U2.10 (D1)
D2: U1.8 (GPIO5), U2.11 (D2)
D3: U1.2 (GPIO0), U2.13 (D3)
D4: U1.3 (GPIO1), U2.14 (D4)
D5: U1.4 (GPIO2), U2.15 (D5)
D6: U1.5 (GPIO3), U2.16 (D6)
D7: U1.7 (GPIO4), U2.17 (D7)
D+: U1.52 (USB_DP), U4.3 (I/O2)
D-: U1.51 (USB_DM), U4.1 (I/O1)
GND: C1.2, C2.2, C3.2, C4.2, C5.2, C6.2, C7.2, C8.2, C9.2, C10.2, C11.2, C12.2, C13.2, C14.2, C15.2, C16.2, C17.2, C18.2, C19.2, D4.3 (GND), J1.2, J2.2, J2.4, J4.A1 (GND), J4.A12 (GND), J4.B1 (GND), J4.B12 (GND), J4.S1 (SHIELD), R8.2, R9.1, R10.1, U1.47 (VREG_PGND), U1.61 (GND), U2.12 (GND), U3.2 (GND), U4.2 (GND), Y1.2, Y1.4
LED0: D1.1 (K), R11.2, U1.43 (GPIO29_ADC3)
unnamed: C19.1, R6.1, Y1.1
unnamed: D1.2 (A), R5.2
unnamed: D4.4 (DIN), R11.1
unnamed: J4.A5 (CC1), R10.2
unnamed: J4.B5 (CC2), R9.2
unnamed: J4.A6 (D+), J4.B6 (D+), U4.4 (I/O2)
unnamed: J4.A7 (D-), J4.B7 (D-), U4.6 (I/O1)
unnamed: C15.1, R4.1, U1.46 (VREG_AVDD)
unnamed: L1.2, U1.48 (VREG_LX)
unnamed: C18.1, U1.21 (XIN), Y1.3
unnamed: R6.2, U1.22 (XOUT)
QSPI_SCLK: U1.56 (QSPI_SCLK)
QSPI_SD0: U1.57 (QSPI_SD0)
QSPI_SD1: U1.59 (QSPI_SD1)
QSPI_SD2: U1.58 (QSPI_SD2)
QSPI_SD3: U1.55 (QSPI_SD3)
QSPI_SS: R2.2, R3.2, U1.60 (QSPI_SS)
RUN: J2.7, R1.2, U1.26 (RUN)
SEL_A: J2.8, U1.25 (SWD), U1.36 (GPIO24)
SEL_B: J2.6, U1.24 (SWCLK), U1.37 (GPIO25)
SEL_C: J2.1, U1.40 (GPIO26_ADC0)
SEL_D: J2.3, U1.41 (GPIO27_ADC1)
VBUS: D3.2 (A), J4.A4 (VBUS), J4.A9 (VBUS), J4.B4 (VBUS), J4.B9 (VBUS), R7.1, U4.5 (VBUS)
VBUS_DET: R7.2, R8.1, U1.42 (GPIO28_ADC2)
VHOST: D2.2 (A), U2.24 (VCC)

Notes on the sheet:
Run time select jumpers
Voltage Regulation
Power Inputs
USB-C
Extra power cap
2316/2332/2364 ROM Replacemennt
Bypass Caps
Power LED
BOOTSEL
Jumpers and programming

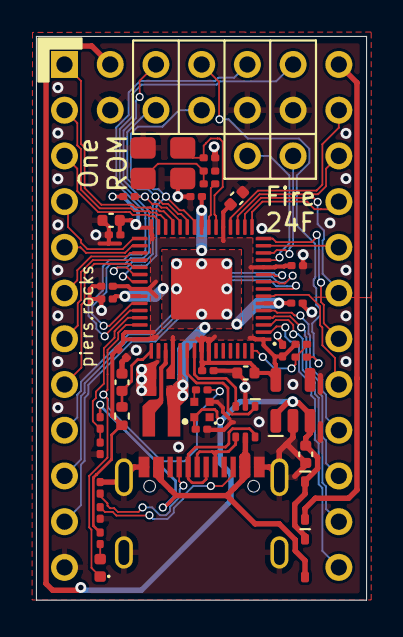
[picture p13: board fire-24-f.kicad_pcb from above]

Board: 2 copper layers, 18.3 x 31.3 mm, 44 parts (0 on the bottom side), 52 nets.

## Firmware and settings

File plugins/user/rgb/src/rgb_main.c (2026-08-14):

// Copyright (C) 2026 Piers Finlayson <piers@piers.rocks>
//
// MIT License

// One ROM user plugin: NeoPixel smooth colour cycle

#include "plugin.h"
#include "onerom_metadata.h"

ORA_DEFINE_USER_PLUGIN(
    neopixel_main,
    0, 1, 2, 0,
    0, 7, 1
);

// RP2350 SIO register offsets differ from RP2040 — the HI variants
// (for pins 32-47) are interleaved, shifting SET/CLR/OE offsets.
#define SIO_BASE            0xD0000000u
#define SIO_GPIO_OUT_SET    (*(volatile uint32_t *)(SIO_BASE + 0x018u))
#define SIO_GPIO_OUT_CLR    (*(volatile uint32_t *)(SIO_BASE + 0x020u))
#define SIO_GPIO_OE_SET     (*(volatile uint32_t *)(SIO_BASE + 0x038u))
#define SIO_GPIO_HI_OUT_SET (*(volatile uint32_t *)(SIO_BASE + 0x01Cu))
#define SIO_GPIO_HI_OUT_CLR (*(volatile uint32_t *)(SIO_BASE + 0x024u))
#define SIO_GPIO_HI_OE_SET  (*(volatile uint32_t *)(SIO_BASE + 0x03Cu))
#define IO_BANK0_BASE       0x40028000u
#define GPIO_CTRL(n)        (*(volatile uint32_t *)(IO_BANK0_BASE + (uint32_t)(n) * 8u + 4u))
#define FUNCSEL_SIO         5u

#define PADS_BANK0_BASE     0x40038000
#define PAD_OFFSET_START    0x004
#define PAD_SPACING         0x004
#define GPIO_PAD(pin)       (*(volatile uint32_t*)(PADS_BANK0_BASE + PAD_OFFSET_START + pin*PAD_SPACING))  
#define PAD_DRIVE_BIT       4
#define PAD_DRIVE_8MA       0x2
#define PAD_DRIVE_MASK      0x3
#define PAD_DRIVE(X)        ((X & PAD_DRIVE_MASK) << PAD_DRIVE_BIT)
#define PAD_SLEW_FAST_BIT   0
#define PAD_SLEW_FAST       (1 << PAD_SLEW_FAST_BIT)

// WS2812 nominal pulse widths in nanoseconds
#define T0H_NS   350u
#define T0L_NS   800u
#define T1H_NS   700u
#define T1L_NS   600u
#define RST_US    60u

static volatile uint32_t *s_out_set;
static volatile uint32_t *s_out_clr;
static uint32_t s_t0h, s_t0l, s_t1h, s_t1l, s_rst;
static uint32_t s_pin_mask;

// ~3 cycles/iteration on Cortex-M33 (1 for SUBS, 2 for BNE taken).
// WS2812 tolerances are ±150ns so this approximation is fine at any
// reasonable sysclk.
static inline void delay_cycles(uint32_t cycles) {
    uint32_t n = cycles / 3u;
    __asm volatile (
        "1: subs %0, %0, #1\n"
        "   bne 1b\n"
        : "+r"(n) :: "cc"
    );
}

// Marked noinline so call overhead is constant and predictable across bits.
__attribute__((noinline))
static void send_bit(uint32_t bit) {
    if (bit) {
        *s_out_set = s_pin_mask; delay_cycles(s_t1h);
        *s_out_clr = s_pin_mask; delay_cycles(s_t1l);
    } else {
        *s_out_set = s_pin_mask; delay_cycles(s_t0h);
        *s_out_clr = s_pin_mask; delay_cycles(s_t0l);
    }
}

// WS2812 expects GRB order, MSB first
static void send_pixel(uint8_t r, uint8_t g, uint8_t b) {
    uint32_t grb = ((uint32_t)g << 16) | ((uint32_t)r << 8) | b;
    for (int i = 23; i >= 0; i--) {
        send_bit((grb >> i) & 1u);
    }
}

static void reset_pulse(void) {
    *s_out_clr = s_pin_mask;
    delay_cycles(s_rst);
}

// Integer HSV→RGB. h in [0,360), s and v in [0,255].
static void hsv_to_rgb(uint16_t h, uint8_t s, uint8_t v,
                       uint8_t *r, uint8_t *g, uint8_t *b) {
    if (s == 0) { *r = *g = *b = v; return; }

    uint8_t  region    = (uint8_t)(h / 60u);
    uint32_t remainder = (h % 60u) * 256u / 60u;
    uint8_t  p = (uint8_t)((uint32_t)v * (255u - s) / 255u);
    uint8_t  q = (uint8_t)((uint32_t)v * (255u - s * remainder / 256u) / 255u);
    uint8_t  t = (uint8_t)((uint32_t)v * (255u - s * (255u - remainder) / 256u) / 255u);

    switch (region) {
        case 0:  *r = v; *g = t; *b = p; break;
        case 1:  *r = q; *g = v; *b = p; break;
        case 2:  *r = p; *g = v; *b = t; break;
        case 3:  *r = p; *g = q; *b = v; break;
        case 4:  *r = t; *g = p; *b = v; break;
        default: *r = v; *g = p; *b = q; break;
    }
}

void neopixel_main(
    ora_lookup_fn_t ora_lookup_fn,
    ora_plugin_type_t plugin_type,
    const ora_entry_args_t *entry_args
) {
    (void)plugin_type;
    (void)entry_args;

    ora_get_sysclk_mhz_fn_t get_sysclk = ora_lookup_fn(ORA_ID_GET_SYSCLK_MHZ);
    uint32_t mhz = get_sysclk();

    // cycles = (ns × MHz) / 1000
    s_t0h = (T0H_NS * mhz) / 1000u;
    s_t0l = (T0L_NS * mhz) / 1000u;
    s_t1h = (T1H_NS * mhz) / 1000u;
    s_t1l = (T1L_NS * mhz) / 1000u;
    s_rst = RST_US * mhz;           // µs × MHz = cycles directly

    // Learn the neopixel and status-LED GPIOs from device metadata rather than
    // hard-coding them. On some boards the status LED and neopixel share a
    // GPIO; when they do, this plugin owns the pin and must also honour the
    // status LED (see the frame loop below).
    ora_get_metadata_uint_fn_t get_meta = ora_lookup_fn(ORA_ID_GET_METADATA_UINT);
    uint32_t neo = GPIO_NONE, status = GPIO_NONE;
    if (get_meta != NULL) {
        get_meta(ORA_METADATA_KEY_GPIO_NEOPIXEL, &neo);
        get_meta(ORA_METADATA_KEY_GPIO_STATUS, &status);
    }

    // No neopixel on this board - nothing to drive; idle.
    if (neo == GPIO_NONE) {
        while (1) { }
    }

    uint8_t neopixel_pin = (uint8_t)neo;
    // Does the status LED share this GPIO?
    uint8_t shared_status = (status != GPIO_NONE) && (neo == status);

    // Configure pin: set function to SIO, drive low, enable output
    s_pin_mask = 1u << (neopixel_pin & 31u);
    GPIO_PAD(neopixel_pin) = PAD_DRIVE(PAD_DRIVE_8MA) | PAD_SLEW_FAST;
    GPIO_CTRL(neopixel_pin) = FUNCSEL_SIO;
    if (neopixel_pin >= 32u) {
        s_out_set = &SIO_GPIO_HI_OUT_SET;
        s_out_clr = &SIO_GPIO_HI_OUT_CLR;
        SIO_GPIO_HI_OUT_CLR = s_pin_mask;
        SIO_GPIO_HI_OE_SET  = s_pin_mask;
    } else {
        s_out_set = &SIO_GPIO_OUT_SET;
        s_out_clr = &SIO_GPIO_OUT_CLR;
        SIO_GPIO_OUT_CLR = s_pin_mask;
        SIO_GPIO_OE_SET  = s_pin_mask;
    }

    // Cycle through hue 0–359 at full saturation and brightness.
    // One full cycle takes ~360 frames; adjust the inter-frame delay to
    // taste — it is clock-dependent as in the blink plugin.
    uint16_t hue = 0;
    while (1) {
        uint8_t r, g, b;
        hsv_to_rgb(hue, 255, 255, &r, &g, &b);

        send_pixel(r, g, b);
        reset_pulse();          // hold low >= reset time so the pixel latches

        // If the status LED shares this GPIO, park the line at the status LED's
        // desired idle level once the pixel has latched: the neopixel keeps its
        // colour, while the discrete LED reflects the live status_led_enabled
        // state. This is the only coordination - the plugin has no awareness of
        // whatever set that state.
        if (shared_status) {
            uint32_t led_on = 0;
            if (get_meta != NULL) {
                get_meta(ORA_METADATA_KEY_STATUS_LED_STATE, &led_on);
            }
            if (led_on) {
                *s_out_clr = s_pin_mask;   // low = LED on (active low)
            } else {
                *s_out_set = s_pin_mask;   // high = LED off
            }
        }

        hue = (hue + 1u) % 360u;

        // ~2-3ms inter-frame delay at 150MHz; one full hue cycle ≈ 1 second
        for (volatile int i = 0; i < 100000; i++);
    }
}

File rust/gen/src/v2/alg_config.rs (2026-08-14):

// Copyright (C) 2026 Piers Finlayson <piers@piers.rocks>
//
// MIT License

//! Build the per-slot algorithm config (`OneromAlgConfig`) from
//! already-derived address/CS-data layouts.
//!
//! `build_alg_addr`/`build_alg_data`/`build_alg_dma` build the
//! corresponding sub-configs directly from the layouts. `build_alg_cs`
//! (in `alg_cs.rs`), the CS-polarity overrides (`cs_overrides.rs`), and
//! the GPIO pull config (`gpio_pull_config.rs`) are wired together by
//! `build_alg_config` below.
//!
//! `build_alg_config` takes `&AddrLayout`/`&CsDataLayout` rather than
//! deriving them itself, since `build_rom_slot` needs the same layouts for
//! `build_rom_info`'s pin maps - deriving once and sharing avoids doing the
//! (fallible) derivation twice. As a result `build_alg_config` itself is
//! infallible.
//!
//! `bit_mode` (chip0's *effective* bit mode, from `bit_mode_for`) and
//! `force_16_bit` are both computed once by `build_rom_slot` and passed
//! in - `bit_mode` is also needed by `derive_addr_layout` (for the A-1
//! carve-out), so computing it once and sharing avoids the two
//! disagreeing.

use onerom_config::chip::ChipType;
use onerom_config::hw::Board;

use onerom_metadata::{
    BitModes, GPIO_NONE, GpioOverride, OneromAlgAddrConfig, OneromAlgConfig, OneromAlgDataConfig,
    OneromAlgDmaConfig, OneromAlgOverrideConfig,
};

use crate::image::CsConfig;
use crate::v2::cs_overrides::encode_override;

use super::addr_layout::AddrLayout;
use super::alg_cs::build_alg_cs;
use super::alg_preference::{
    AddrAlgPreference, CombinedAlgPreference, CsAlgPreference, DataAlgPreference, DmaAlgPreference,
};
use super::cs_data_layout::CsDataLayout;
use super::cs_overrides::{
    build_cs_overrides, build_gpio_x_overrides, build_unused_addr_overrides,
};
use super::gpio_pull_config::build_gpio_pull_config;
use super::slot_context::SlotContext;

/// H: clock dividers default to 1.0 for now.
pub const DEFAULT_CLKDIV_INT: u16 = 1;
pub const DEFAULT_CLKDIV_FRAC: u8 = 0;

const ALG_DATA0_NUM_DELAY_CYCLES_8_BIT: u8 = 2;
const ALG_DATA1_NUM_DELAY_CYCLES_16_BIT: u8 = 4;

/// Determine the bit mode (8 vs 16) for serving `chip_type` on `board`.
///
/// 16-bit serving requires both a board /BYTE pin and chip support for it.
///
/// This is independent of `force_16_bit`: for a `BitMode16`-capable chip,
/// `rom_data_buf` is always `2^num_addr_pins * 2` bytes (one 16-bit word
/// per address-PIO table index) regardless of `force_16_bit` - that flag
/// only changes *how* the chip is served (`AlgData0` vs `AlgData1`, see
/// `build_alg_data`), not the table layout/contents.
pub fn bit_mode_for(chip_type: ChipType, board: Board) -> BitModes {
    if board.pin_byte() != GPIO_NONE && chip_type.supports_bit_mode(16) {
        BitModes::BitMode16
    } else {
        BitModes::BitMode8
    }
}
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

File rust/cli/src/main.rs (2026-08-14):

// Copyright (C) 2026 Piers Finlayson <piers@piers.rocks>
//
// MIT License

//! onerom - One ROM command-line interface

use clap::{CommandFactory, FromArgMatches};
#[allow(unused_imports)]
use log::{debug, error, info, trace, warn};

mod args;
mod board;
mod board_view;
mod control;
mod firmware;
mod image;
mod inspect;
mod plugin;
mod program;
mod scan;
mod update;
mod utils;

use args::BoardCommands;
use args::Cli;
use args::Commands;
use args::control::{ControlCommands, ControlLedCommands, ControlPokeCommands};
use args::firmware::FirmwareCommands;
use args::image::ImageCommands;
use args::inspect::{InspectCommands, InspectPeekCommands};
use args::update::UpdateCommands;

use onerom_cli::Error;

#[tokio::main]
async fn main() {
    if let Err(e) = sub_main().await {
        eprintln!("Failed to execute command.\n{e}");
        std::process::exit(1);
    }
}

async fn sub_main() -> Result<(), Error> {
    // We need to convoluted call into clap so we can change the binary name to
    // onerom.
    let mut cli = Cli::from_arg_matches(&Cli::command().bin_name("onerom").get_matches())
        .unwrap_or_else(|e: clap::Error| e.exit());
    let mut options = cli.try_into_options().await?;

    utils::init_logging(&options);

    debug!("One ROM CLI v{}", env!("CARGO_PKG_VERSION"));

    match &cli.command {
        Commands::Scan(args) => scan::cmd_scan(&options, args).await,
        Commands::Firmware(args) => match &args.command {
            FirmwareCommands::Build(args) => firmware::cmd_build(&options, args).await,
            FirmwareCommands::Inspect(args) => firmware::cmd_inspect(&options, args).await,
            FirmwareCommands::Releases(args) => firmware::cmd_releases(&options, args).await,
            FirmwareCommands::Download(args) => firmware::cmd_download(&options, args).await,
            FirmwareCommands::Chips(args) => firmware::cmd_chips(&options, args).await,
            FirmwareCommands::Program(args) => program::cmd_program(&mut options, args).await,
        },
        Commands::Plugin(args) => plugin::cmd_plugin(&options, args).await,
        Commands::Program(args) => program::cmd_program(&mut options, args).await,
        Commands::Inspect(args) => match &args.command {
            InspectCommands::Info(args) => inspect::cmd_info(&options, args).await,
            InspectCommands::Telemetry(args) => inspect::cmd_telemetry(&options, args).await,
            InspectCommands::Slots(args) => inspect::cmd_slots(&options, args).await,
            InspectCommands::Image(args) => inspect::cmd_image(&options, args).await,
            InspectCommands::Gpio(args) => inspect::cmd_gpio(&options, args).await,
            InspectCommands::Header(args) => inspect::cmd_header(&options, args).await,
            InspectCommands::Socket(args) => inspect::cmd_socket(&options, args).await,
            InspectCommands::Peek(args) => match &args.command {
                InspectPeekCommands::Live(args) => inspect::cmd_peek_live(&options, args).await,
                InspectPeekCommands::Memory(args) => inspect::cmd_peek_memory(&options, args).await,
            },
        },
        Commands::Control(args) => match &args.command {
            ControlCommands::Led(args) => match &args.command {
                ControlLedCommands::On(args) => control::cmd_led_on(&options, args).await,
                ControlLedCommands::Off(args) => control::cmd_led_off(&options, args).await,
                ControlLedCommands::Beacon(args) => control::cmd_led_beacon(&options, args).await,
                ControlLedCommands::Flame(args) => control::cmd_led_flame(&options, args).await,
            },
            ControlCommands::Reboot(args) => control::cmd_reboot(&options, args).await,
            ControlCommands::Reset(args) => control::cmd_reset(&options, args).await,
            ControlCommands::Select(args) => control::cmd_select(&options, args).await,
            ControlCommands::Pin(args) => control::cmd_pin(&options, args).await,
            ControlCommands::Poke(args) => match &args.command {
                ControlPokeCommands::Memory(args) => control::cmd_poke_memory(&options, args).await,
                ControlPokeCommands::Live(args) => control::cmd_poke_live(&options, args).await,
            },
            ControlCommands::Erase(args) => control::cmd_erase(&mut options, args).await,
        },
        Commands::Update(args) => match &args.command {
            UpdateCommands::Slot(args) => update::cmd_slot(&options, args).await,
            UpdateCommands::Commit(args) => update::cmd_commit(&options, args).await,
            UpdateCommands::Otp(args) => update::cmd_otp(&options, args).await,
        },
        Commands::Image(args) => match &args.command {
            ImageCommands::SwapBytes(args) => image::cmd_swap_bytes(&options, args).await,
            ImageCommands::Deinterleave(args) => image::cmd_deinterleave(&options, args).await,
            ImageCommands::Convert(args) => image::cmd_convert(&options, args).await,
        },
        Commands::Peek(args) => inspect::cmd_peek_live(&options, args).await,
        Commands::Poke(args) => control::cmd_poke_live(&options, args).await,
        Commands::Reboot(args) => control::cmd_reboot(&options, args).await,
        Commands::Chips(args) => firmware::cmd_chips(&options, args).await,
        Commands::Board(args) => match &args.command {
            BoardCommands::List(args) => board::cmd_list(&options, args).await,
            BoardCommands::Header(args) => board::cmd_header(&options, args).await,
            BoardCommands::Socket(args) => board::cmd_socket(&options, args).await,
        },
    }
}
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

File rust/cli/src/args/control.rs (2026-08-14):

// Copyright (C) 2026 Piers Finlayson <piers@piers.rocks>
//
// MIT License

//! Argument definitions for `onerom control`.

use crate::args::CommandTrait;
use crate::utils::{parse_u8, parse_u32};
use clap::{ArgGroup, Args, Subcommand, ValueEnum};
use enum_dispatch::enum_dispatch;

use onerom_cli::pin::{Pin, parse_pin};
use onerom_cli::usb::{GpioState as WireGpioState, RebootArgs};

#[derive(Debug, Args)]
pub struct ControlArgs {
    #[command(subcommand)]
    pub command: ControlCommands,
}

impl CommandTrait for ControlArgs {
    fn requires_device(&self) -> bool {
        self.command.requires_device()
    }
}

#[enum_dispatch(CommandTrait)]
#[derive(Debug, Subcommand)]
pub enum ControlCommands {
    /// Reboot the One ROM.
    ///
    /// Restarts the One ROM firmware. The device will re-initialise and
    /// resume serving ROM images after the reboot.
    ///
    /// By default, this command pauses after a reboot to give the device time
    /// to re-enumerate.
    ///
    /// Example:
    ///
    ///   onerom control reboot
    Reboot(ControlRebootArgs),

    /// Control the status LED on a One ROM.
    ///
    /// Examples:
    ///
    ///   onerom control led on
    ///
    ///   onerom control led off
    #[command(
        subcommand_value_name = "COMMAND",
        subcommand_help_heading = "Commands"
    )]
    Led(ControlLedArgs),

    /// Write data to One ROM's SRAM or the live ROM image.
    ///
    /// Poke provides transient (non-persistent) writes to device memory. Changes
    /// are lost on reboot. Use `update` subcommands for persistent flash writes.
    ///
    /// Data can be written as a single byte value or from a binary file.
    ///
    /// Example:
    ///
    ///   onerom control poke memory --address 0x20000010 --byte 0xFF
    ///
    ///   onerom control poke memory --address 0x20000010 --input patch.bin
    ///
    ///   onerom control poke live --address 0x100 --byte 0xEA
    ///
    ///   onerom control poke live --address 0x100 --input patch.bin
    #[command(
        subcommand_value_name = "COMMAND",
        subcommand_help_heading = "Commands"
    )]
    Poke(ControlPokeArgs),

    /// Pulse a One ROM GPIO low to reset the host system.
    ///
    /// Pulses the named GPIO low, then releases it to high impedance, to
    /// reset the host system the One ROM is installed in. Useful in scripted
    /// workflows to reset the host after programming a new ROM image.
    ///
    /// --pin is the pin your reset wire is soldered to - typically an X pad, or
    /// an image-select pad whose jumper you have removed. Name it by pad
    /// ('x1', 'sel_a') or by MCU GPIO ('gpio9'). Run 'onerom inspect header' to
    /// see which GPIO is behind each pad.
    ///
    /// The reset line is only ever driven low and then released: a reset net
    /// has its own pull-up and may have other drivers on it, so there is
    /// deliberately no way to drive it high. Use 'onerom control pin' if you
    /// need arbitrary states.
    ///
    /// The device times the pulse, not this command, so an interrupted CLI
    /// cannot leave the host held in reset.
    ///
    /// Examples:
    ///
    ///   onerom control reset --pin x1
    ///
    ///   onerom control reset --pin gpio9 --hold 500
    Reset(ControlResetArgs),

    /// Select the active ROM slot (not yet supported).
    ///
    /// Switches the device to serving the specified image slot. This takes
    /// effect immediately but does not persist across power cycles unless.
    ///
    /// Example:
    ///
    ///   onerom control select --slot 2
    Select(ControlSelectArgs),

    /// Drive a One ROM pin high, low or high-impedance.
    ///
    /// --pin names an MCU GPIO, written 'gpio<N>', or a header pad: 'sel_a'
    /// to 'sel_e', 'x1' or 'x2'. Run 'onerom inspect header' to see which GPIO
    /// is behind each header pad, and 'onerom inspect gpio' to see what One ROM
    /// is currently using each GPIO for.
    ///
    /// Without --hold the state is latched until something changes it. With
    /// --hold the device holds the state for that many milliseconds and then
    /// applies --then (high impedance unless you say otherwise). The device
    /// times the hold, not this command, so an interrupted CLI cannot leave a
    /// pin latched.
    ///
    /// A GPIO One ROM is itself using is refused unless --force is given.
    /// Forcing a pin One ROM drives (a data pin) breaks ROM serving until the
    /// device is rebooted; forcing one it only reads (address, chip-select,
    /// /BYTE) is undone by setting it back to z.
    ///
    /// Examples:
    ///
    ///   onerom control pin --pin gpio9 --state high
    ///
    ///   onerom control pin --pin x1 --state 0 --hold 250
    ///
    ///   onerom control pin --pin sel_a --state z
    Pin(ControlPinArgs),

    /// Erase this One ROM's flash memory.
    ///
    /// Permanently erase flash contents on the device, including firmware,
    /// metadata and ROM images.
    ///
    /// If a One ROM's firmware has been erased it will subsequently boot into
    /// the RP2350 bootloader from where it can be reprogrammed.  However, you
    /// will need to use the --unrecognized to detect and program it.
    ///
    /// It is highly recommended that this command is used when One ROM is
    /// stopped (and the default is this command will reboot the device if
    /// required before erasing to make it so).
    ///
    /// Use with extreme caution while One ROM is running.  Erasing the core
    /// firmware or the system plugin's flash will cause the USB stack to be
    /// non-functional, requiring manually forcing into BOOTSEL mode using One
    /// ROM's header pins.  In addition, erasing flash causes One ROM to
    /// temporarily suspend interrupts and cause flash to become inaccessible.
    /// Anything else running from flash (like a user plugin) may well crash
    /// as a result.
    ///
    /// For a similar reason, large erase operations while running may cause
    /// One ROM's USB support to become unavailable and then re-enumerate
    /// after the flash erase.  In this case, the flash likely succeeded and
    /// can be checked with `inspect peek memory`.
    ///
    /// You can use this command to erase multiple ranges in a single operation
    /// with multiple --offset/--address and --length arguments.
    ///
    /// Example:
    ///
    ///   onerom control erase -a
    ///
    ///   onerom control erase --offset 0x20000 --length 0x1000
    Erase(ControlEraseArgs),
}

#[derive(Debug, Args)]
pub struct ControlLedArgs {
    #[command(subcommand)]
    pub command: ControlLedCommands,
}

impl CommandTrait for ControlLedArgs {
    fn requires_device(&self) -> bool {
        self.command.requires_device()
    }
}
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
